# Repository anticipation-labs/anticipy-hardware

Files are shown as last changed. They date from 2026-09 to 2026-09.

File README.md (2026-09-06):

# Anticipy Hardware

Consolidated hardware record for the Anticipy pendant — a wearable that listens passively,
pulls tasks out of conversation, and acts on them without commands.

**Assembled:** 2026-09-06 · **Files:** 3756 (1189 unique) · **Size:** ~656M B
**Sources consolidated:** 15 separate packages plus loose files and sealed original zips from
Downloads, Desktop and Documents.

---

## The one thing to read first

> **Nothing here is fabrication-ready. There is no released Gerber, ODB++, drill file,
> pick-and-place, assembly drawing or final enclosure drawing anywhere in this repository.**
>
> There is, however, a **live JLCPCB order** (`W2026083114248171` / `SMT026083160845`) with an
> **unresolved part substitution** awaiting DFM review. See [07_PROCUREMENT](07_PROCUREMENT/).
> That is the only clock currently running.

> ⚠️ **Do not flash `anticipy.uf2` from any `~/AnticipyFleet/*/firmware/` lane.** That file is the
> image formally classified `UNVERIFIED_DO_NOT_FLASH` (sha256 `2e78015e…`, 624,640 bytes), sitting
> under a clean name next to a build receipt that describes a *different* 509,440-byte image.
> Details: [`00_START_HERE/CONTRADICTIONS.md`](00_START_HERE/CONTRADICTIONS.md) §14.

**New to this project?** Read [`00_START_HERE/ORIENTATION.md`](00_START_HERE/ORIENTATION.md) first.
It assumes no prior context: what the product is, where it actually stands, how to open every file
type here, what the vocabulary means, and what to do in your first week.

Then read [`00_START_HERE/HARDWARE_STATE.md`](00_START_HERE/HARDWARE_STATE.md) — one page on what
is actually true today — followed by
[`00_START_HERE/CONTRADICTIONS.md`](00_START_HERE/CONTRADICTIONS.md), which lists **seventeen** places
where two documents in this repository disagree with each other. Read that **before** acting on any
single document, because several of them contradict each other on the processor, the enclosure
size and the state of the board.

---

## Folder map

| Folder | What it is | Fab status |
|---|---|---|
| [`00_START_HERE/`](00_START_HERE/) | Orientation for newcomers, state, contradictions, glossary, provenance | — |
| [`01_CURRENT_TARGET_R1/`](01_CURRENT_TARGET_R1/) | The live requirement set (2026-09-04). What the incoming engineer is asked to build. | Not designed yet |
| [`02_PROTOTYPE_XIAO/`](02_PROTOTYPE_XIAO/) | XIAO nRF52840 Sense proof unit — wiring, enclosure CAD, assembly evidence | Proof only, on physical-test hold |
| [`03_PCB/`](03_PCB/) | Every custom board design. Three exist. None are releasable. | **NOT FOR FAB** |
| [`04_MECHANICAL/`](04_MECHANICAL/) | Enclosure CAD — print-ready, reference STEP, superseded meshes | Print-ready ≠ production |
| [`05_FIRMWARE/`](05_FIRMWARE/) | Source, build/protocol/threat docs, distinct images, device recovery | Lab only |
| [`06_FACTORY_AND_QA/`](06_FACTORY_AND_QA/) | Factory release process, QA fixtures, test evidence | Process defined, not executed |
| [`07_PROCUREMENT/`](07_PROCUREMENT/) | BOMs, order sheets, sourcing, **live JLCPCB order status** | Active |
| [`08_HISTORICAL_PACKAGES/`](08_HISTORICAL_PACKAGES/) | All 12 source packages plus the original zips, preserved verbatim. Never edit. | Archive |
| [`99_MANIFESTS/`](99_MANIFESTS/) | `SHA256SUMS.txt`, `INVENTORY.csv` | — |

**Folders `01`–`07` are a curated working view. Folder `08` is the provenance record.**
Every file in `01`–`07` also exists in `08`, byte-identical. If the two ever disagree, `08` wins.

---

## The five board generations, decoded

This is the single most confusing thing in the project, so it is stated once, plainly:

| Name | What it actually is | Where | State |
|---|---|---|---|
| **R0** | `ANT-PROD-R0 EVT`. First custom board. Has 31 commits of routing history. | `03_PCB/R0_ROUTING_HISTORY_NOT_FOR_FAB/` | 23 non-GND nets still unconnected |
| **R0B** | Revision B of R0. The "engineering checkpoint" the master package leads with. | `03_PCB/R0B_CHECKPOINT_NOT_FOR_FAB/` | 176 connections unrouted |
| **EVT-A** | `anticipy_evt_a`. A *separate* board from the 2026-08-28 Execution package, targeting a **different processor**. | `03_PCB/EVT_A_2026-08-28_SUPERSEDED/` | Fabrication hold: 0 segments, 0 vias, 0 zones |
| **ESP32-S3** | The prior generation (April 2026). Different SoC, mic, charger and enclosure entirely. Holds the only packaging spec and manufacturing-order doc that exist. | `08_HISTORICAL_PACKAGES/2026-04_esp32s3_prior_generation/` | Superseded |
| **R1** | The current target. **Does not exist yet** — brief only. | `01_CURRENT_TARGET_R1/` | Not started |

R0 and R0B are not the same file, and the copy of R0 shipped inside the master package is **not**
the same file as the one in the R0 git repository. See `00_START_HERE/CONTRADICTIONS.md`.

---

## Working with this repository

### Cloning

```bash
git lfs install                                    # once per machine
git clone https://github.com/anticipation-labs/anticipy-hardware.git
```

Git LFS is required, but only barely — it is scoped to exactly **two** files, the oversized
superseded meshes under `04_MECHANICAL/SUPERSEDED_AND_MOCKUPS/OVERSIZED_MESHES_500mah_2026-08-22/`
(68.8 MB and 64.8 MB). Everything else is stored as ordinary git objects deliberately, so a clone
never depends on an LFS bandwidth quota. If LFS is unavailable, `GIT_LFS_SKIP_SMUDGE=1 git clone`
still gets you the entire repository minus those two superseded files.

### Byte fidelity

`.gitattributes` sets `* -text`, disabling all end-of-line conversion. This is not cosmetic: this
repository is a checksum-verified archive, and EOL rewriting would silently invalidate
`99_MANIFESTS/SHA256SUMS.txt` for every CSV that arrived with CRLF endings.

### The R0 routing history

The R0 KiCad project arrived as its own git repository with 31 commits and no remote. A nested
`.git` cannot be committed into a parent repository, so the history is preserved as a bundle:

```bash
cd 03_PCB/R0_ROUTING_HISTORY_NOT_FOR_FAB
git clone R0_ROUTING_HISTORY.bundle r0-history      # full 31-commit history, restored
```

`R0_ROUTING_HISTORY_COMMITS.txt` lists every commit, and
`R0_UNCOMMITTED_AT_ARCHIVE_TIME.txt` records the working-tree changes that were uncommitted when
this archive was made. Those uncommitted files are present in the folder as-is.

### What is deliberately not ignored

`.kicad_prl` and other KiCad per-user state arrived inside the original handoff packages and are
covered by the checksum manifest, so they are committed rather than ignored. Only `__pycache__`
bytecode and macOS `.DS_Store` files were removed.

---

## Verifying this folder

```bash
cd ~/Anticipy-Hardware && shasum -a 256 -c 99_MANIFESTS/SHA256SUMS.txt
```

`99_MANIFESTS/INVENTORY.csv` lists every file with its hash, size, date and owning folder.

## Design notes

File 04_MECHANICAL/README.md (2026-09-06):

# 04 — Mechanical

**Print-ready is not the same as production-ready.** Nothing here has been validated on a sealed,
assembled unit.

## Two parallel enclosure lineages exist

This is the mechanical equivalent of the processor contradiction, and it is easy to miss because
the two live in different folders with different naming:

| Lineage | Form factor | Source | Where |
|---|---|---|---|
| **Ordered-shell recovery v0.2** | 51 × 22 × 14.5 mm body + 4.50 mm midband, coin motor, M2 screw retention | Generated by a Python recovery script | `../02_PROTOTYPE_XIAO/CAD/`, `PRINT_READY/xiao_prototype_plates/` |
| **`anticipy-shell` v5.1** | 26.5 × 61.2 × 12.6 mm flat pill tag (33.4 × 80.7 × 16.2 mm in the v5 storage build), click tongue-and-groove joint, microSD pocket | Parametric **OpenSCAD** | `OPENSCAD_SHELL_PROGRAM_v5.1/` |
| **Production CAD** | 50.500 × 20.680 × 10.800 mm envelope, 16 solids | Execution v1.0 | `REFERENCE_STEP/` |

These are **three different products**, not three views of one. Nobody has written down which is
current. The R1 brief adds a fourth number: 56.0 × 23.0 × 12.0 mm.

## Layout

| Folder | Contents |
|---|---|
| `OPENSCAD_SHELL_PROGRAM_v5.1/` | The only *parametric* enclosure source on the machine. `pendant.scad` with a documented v1 → v5.1 history, 12 STL exports, print plates, a clearance coupon, a Bambu print recipe, a dimensioned drawing, an XIAO+microSD pinmap, a power/storage budget, a per-unit BOM with real sources and prices, an 8-step assembly sequence, and a 100-unit MJF-vs-CNC cost comparison. |
| `MACHINIST_DRAWINGS/` | **The only machinist-facing 2D drawing pair found anywhere** — `production_aluminum_cap_drawing.pdf` + `_outline.dxf`. If a CNC vendor is ever engaged, this is what they get. |
| `REFERENCE_STEP/` | Execution v1.0 production CAD. 23/23 mechanical checks passed — **against the 50.5 × 20.68 × 10.8 envelope only**. |
| `PRINT_READY/` | Plates and parts believed printable. Includes the XIAO prototype plates. |
| `SUPERSEDED_AND_MOCKUPS/` | Older meshes, mockups and visual studies. Kept for history. |

## Known unresolved mechanical issues

- **The v5 joint does not lock.** The 2026-08-18 P2S print failed on joint clearance — recorded in
  the OpenSCAD program's own build book as "zero tolerance, doesn't even try to lock". Whether a
  corrected plate was ever printed successfully is not recorded.
- **Material and adhesive conflict.** `README` in the OpenSCAD program specifies Bambu PLA Metal
  with gel CA glue; its own `BUILD_BOOK`, `print-plan` and `build-steps` specify black ABS. These
  have different shrinkage and different bonding requirements.
- **A permanently glued shell conflicts with DFU recovery.** The shell is designed to be glued
  shut, but firmware recovery depends on 1200-baud USB touch and BLE DFU being reachable. If the
  radio or the crystal fails inside a sealed unit, there is no documented way back in.

## Oversized files

`SUPERSEDED_AND_MOCKUPS/OVERSIZED_MESHES_500mah_2026-08-22/` holds two STLs of 68.8 MB and
64.8 MB. Both exceed GitHub's 50 MB warning threshold (neither hits the 100 MB block). They are
superseded and kept only for history — the first candidates to drop if repository size matters.

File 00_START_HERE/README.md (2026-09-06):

# 00 — Start here

Read in this order.

| # | File | Why |
|---|---|---|
| 0 | [`ORIENTATION.md`](ORIENTATION.md) | **New to the project? Start here.** What the product is, where it really stands, how to open every file type, the vocabulary explained, and a suggested first week. Assumes no prior context. |
| 1 | [`HARDWARE_STATE.md`](HARDWARE_STATE.md) | One page: what is actually true today. Where the project really stands, and the one deadline that is live. |
| 2 | [`CONTRADICTIONS.md`](CONTRADICTIONS.md) | **The most important file here.** Seventeen places where two documents in this repository disagree — on the processor, the enclosure size, the battery, which board file is real, and whether the firmware can drive the haptics. Read it before acting on any single document. |
| 3 | [`GLOSSARY.md`](GLOSSARY.md) | Decodes R0 / R0B / EVT-A / R1 / XIAO / P2S / EOL / DFM and the part numbers, none of which are defined anywhere else. |
| 4 | [`PROVENANCE.md`](PROVENANCE.md) | Where every file came from, how the audit was done, and what was deliberately excluded. |

## If you are the incoming hardware engineer

Your assignment is in [`../01_CURRENT_TARGET_R1/`](../01_CURRENT_TARGET_R1/). Before you start,
know these four things:

1. **Nothing here is fabrication-ready.** No Gerber, ODB++, drill, pick-and-place or assembly
   drawing exists anywhere. That is deliberate, not an oversight.
2. **There is a live JLCPCB order** sitting on an unverified part substitution. It is the only
   clock running. See [`../07_PROCUREMENT/`](../07_PROCUREMENT/).
3. **Three custom boards were started and none finished**, and the one named "older" (R0) is
   further along than the one presented as current (R0B).
4. **The briefs disagree with each other.** The newest brief specifies a different processor and a
   different enclosure size than the most complete package on disk. Nobody wrote down why.

## If you are looking for one specific thing

| Looking for | Go to |
|---|---|
| What to build | `../01_CURRENT_TARGET_R1/` |
| The BLE wire protocol | `../05_FIRMWARE/DOCS/PROTOCOL.md` |
| Security and privacy analysis | `../05_FIRMWARE/DOCS/THREAT-MODEL.md` |
| How to reproduce a firmware build | `../05_FIRMWARE/DOCS/BUILD.md` |
| What actually ran on a device | `../05_FIRMWARE/DEVICE_RECOVERY/` |
| Parametric enclosure source | `../04_MECHANICAL/OPENSCAD_SHELL_PROGRAM_v5.1/` |
| The only machinist drawing | `../04_MECHANICAL/MACHINIST_DRAWINGS/` |
| Factory acceptance and EOL tests | `../06_FACTORY_AND_QA/FACTORY_RELEASE_PROCESS/` |
| The PCB routing history | `../03_PCB/R0_ROUTING_HISTORY_NOT_FOR_FAB/` (a git repo) |
| An original untouched deliverable | `../08_HISTORICAL_PACKAGES/` |

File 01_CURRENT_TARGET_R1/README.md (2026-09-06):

# 01 — Current target (R1)

**Status: brief only. This board does not exist yet.**

> ### ⚠️ One file in this folder is superseded and is not marked as such
>
> `Anticipy_PROD_R1_Flux_Build_Brief.md` (2026-08-29) is **NOT the current requirement set**,
> despite sitting in a folder called "current requirements". The master package's own supersession
> notice says so explicitly:
>
> > The earlier Flux build brief, R0A source tree, 49 x 20 mm layout, removable microSD concept,
> > and all experimental autorouter outputs are **deliberately excluded from the active handoff**.
> > — `08_HISTORICAL_PACKAGES/2026-09-05_master_package/04_CUSTOM_PCB_R0B_ENGINEERING_NOT_FOR_FAB/99_Superseded_Notice/SUPERSEDED_FILES_NOTICE.md`
>
> The Flux brief is exactly that brief, with exactly that 49 × 20 mm layout and that microSD
> concept. It carries no supersession banner of its own. It is kept here because it is the most
> detailed electrical brief on record and much of it is still useful — but **every number in it
> must be checked against the Rev 1 brief below before use.**

## The actual current requirement set

**`Anticipy_Hardware_Development_Brief_2026-09-04.md` / `.docx`** — "Custom PCB and investor-ready
metal wearable | Rev 1 | September 4, 2026". This is the assignment.

| | |
|---|---|
| Size | **51 × 21 × 11 mm** target. Do not exceed +10 % per axis without written approval. |
| Weight | **≤ 20 g** target. Flag any design above 25 g before fabrication. |
| Battery | 16 h runtime |
| Local storage | **QSPI NOR flash**, sized from the actual codec. Plan **512 MB**. |
| Offline capacity | 16–20 h |
| Connectivity | BLE live audio, commands, status, reconnect, **ordered backfill** |
| Haptics | App can command a short, discreet vibration |
| MCU | **Not locked.** "nRF52840-compatible starting point"; module vs bare SoC is listed as an *open question* |
| Programming | SWD access, serial identity, test pads |

Delivery is staged through **Checkpoints A/B/C/D** with per-unit acceptance gates and defined stop
conditions — all specified in the brief itself.

## Files here

| File | Status |
|---|---|
| `Anticipy_Hardware_Development_Brief_2026-09-04.md` / `.docx` | **Current.** The `.docx` is the original; the `.md` is a faithful conversion for grepping. |
| `Anticipy_PROD_R1_Flux_Build_Brief.md` | **Superseded** — see banner above |
| `Anticipy_Hardware_CAD_Brief_v1.pdf` | Superseded CAD brief |
| `Anticipy_Full_Handoff_Guide.pdf` | Handoff guide |
| `HARDWARE_SYSTEM_MAP.md` | One-page block diagram. Note it labels storage "QSPI flash" while the R0B BOM actually fits serial **NAND** — see contradictions. |

## Before you build to this

See [`../00_START_HERE/CONTRADICTIONS.md`](../00_START_HERE/CONTRADICTIONS.md). The short version:
four different enclosure envelopes exist across the record, the storage technology is stated three
different ways, and the MCU is not actually locked despite one superseded brief naming a specific
module.

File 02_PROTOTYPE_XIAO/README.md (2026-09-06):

# 02 — XIAO prototype

The proof unit: a Seeed **XIAO nRF52840 Sense** dev board with an onboard PDM microphone,
streaming live audio to the iPhone app. **This is a proof path, not the product**, and it is
currently on physical-test hold.

The 10 Founder units stay on this architecture so that custom-PCB work does not block the
seven-day Founder build.

## What is here

- `00_START_HERE.md`, `00_FOLDER_STATUS.md` — the prototype's own entry points
- `01_FIRMWARE/` — the release-test image, held pending physical validation
- `03_CAD_STEP/`, `02_CAD_PRINT/` — enclosure geometry
- `04_QA/` — QA material
- `CAD/` — the full XIAO CAD set: `PRINT_THESE/`, `REFERENCE_ONLY_STEP/`, `SOURCE/`,
  `04_ASSEMBLY/`, `06_EVIDENCE/`, `FIT_REPORT.json`, `CAD_SHA256SUMS.txt`

## The haptic circuit — get this right

From the "No-Lee's" reference wiring:

| From | To |
|---|---|
| XIAO `D0` | 100 Ω resistor → N-MOSFET gate (AO3400A or equivalent) |
| MOSFET gate | 100 kΩ resistor → GND |
| MOSFET source | XIAO GND |
| MOSFET drain | Motor negative |
| XIAO `3V3` | Motor positive |
| Flyback diode cathode (stripe) | Motor positive / 3V3 |
| Flyback diode anode | Motor negative / MOSFET drain |

> **Never connect the motor directly to `D0`.** It will damage the pin.

Note also that **no firmware in this repository actually drives the haptic motor** — see
[`../05_FIRMWARE/README.md`](../05_FIRMWARE/README.md). The circuit is specified; the software
to use it does not exist yet.

## Still required

The battery, motor, driver and closed enclosure all need real measurements and release testing on
a sealed unit. Nothing here has been physically validated.

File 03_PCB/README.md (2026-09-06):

# 03 — PCB

**NOTHING IN THIS FOLDER MAY BE SENT TO A FABRICATOR AS A PRODUCTION RELEASE.**

There is no released Gerber, ODB++, drill file, pick-and-place or assembly drawing anywhere in
this repository. Three custom boards were started. None were finished. A fourth is specified but
not designed.

## The four revisions

| Folder | Board | State |
|---|---|---|
| `R1_TARGET_NOT_YET_DESIGNED/` | R1 | Empty by design. The brief lives in `../01_CURRENT_TARGET_R1/`. |
| `EVT_A_2026-08-28_SUPERSEDED/` | `anticipy_evt_a`, 37.5 × 14 mm four-layer, **nRF54L15** | Deliberate fabrication hold: 0 segments, 0 vias, 0 zones. No copper was ever laid, specifically so no misleading Gerbers could exist. Superseded by the R1 brief. |
| `R0B_CHECKPOINT_NOT_FOR_FAB/` | R0B, 45.8 × 18.0 mm four-layer, 0.80 mm | 70 electrical references, 223 pins, **176 connections unrouted**. The master package's headline board. |
| `R0_ROUTING_HISTORY_NOT_FOR_FAB/` | R0 / `ANT-PROD-R0 EVT` | **The furthest-routed board.** 45 of 46 signal nets carry copper. 31 commits of history (v21 → v43) driving unconnected nets from 199 down to 23 non-GND. |

## Read this before touching R0

`R0_ROUTING_HISTORY_NOT_FOR_FAB/` contains a **live `.git` repository with no remote**. Its 31
commits are the only version-controlled hardware history found on the machine, and they existed
nowhere else before this consolidation. It also carries uncommitted changes to `.kicad_pcb` and
`.kicad_pro`, plus an untracked `tools/final_build.py`. These were preserved exactly as found.

It includes `tools/route_board.py` — a purpose-written negotiated-congestion autorouter. That is
weeks of work and it exists only here.

## The R0 ambiguity

There are **two different files both called the R0 board**:

| | Master package copy | This git repository |
|---|---|---|
| `.kicad_pcb` sha256 | `64a4931f0fc455cd…` | `c086bae9fedc9a55…` |
| DRC timestamp | 2026-08-30 02:28:59 | 2026-08-29 18:04:35 |
| DRC violations | 134 | 4 |

The master package's copy was generated later by an automated run (its DRC header references a
sandbox path) and is **less** routed. Establish which is canonical before anyone uploads "R0"
anywhere — especially given the live JLCPCB order, whose email record does not prove which
revision was uploaded.

## Ordering note

`R0` is *more* complete than `R0B`, despite the naming. Either R0B discarded R0's routing work
or the master package's framing is wrong. Nothing on disk explains which.

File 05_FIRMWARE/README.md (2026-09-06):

# 05 — Firmware

**Lab only. Nothing here is production firmware.**

This was the single largest gap in the original hardware packages: they shipped firmware
*binaries* and prose about them, but zero source, zero protocol specification, zero threat model,
zero build procedure and zero upstream pinning. All of that lives here now.

## Layout

| Folder | Contents |
|---|---|
| `DOCS/` | `PROTOCOL.md`, `THREAT-MODEL.md`, `BUILD.md`, `README.md`, `upstream.lock.json`, `protocol/` (executable frame protocol + fixtures), `development-receipts/` |
| `SOURCE/` | nRF52840 firmware source, debug tooling and an iOS test client (from Execution v1.0) |
| `IMAGES/` | One copy of each **distinct** firmware binary, renamed by date and status |
| `DEVICE_RECOVERY/` | The restore kit, including an image read back off a physical device, and the A/B recovery pair |

## Lineage — record this somewhere permanent

Anticipy firmware is a **fork of [BasedHardware/omi](https://github.com/BasedHardware/omi)**:

- Upstream: `v2.0.1-Omi`, commit `ee9892562648f074e3c6b59d508127d81fa21010`
- Path: `Friend/firmware/firmware_v1.0`
- Toolchain: NCS v2.5.0
- Applied as two named patches in `DOCS/../replacement/patches/`

**No hardware package records this.** It carries attribution and licensing obligations, and it
also vendors Opus 1.2.1. This should be stated explicitly wherever the firmware ships.

## The images

| File | Notes |
|---|---|
| `2026-09-04_anticipy_0.9.3_owner2_live_50mA_HOLD.uf2` | Newest. Name says it: held for physical release test. |
| `2026-08-28_anticipy_founder_evt_v0.9.0_LAB_ONLY.uf2` | Founder EVT lab image |
| `2026-07-24_dual-hatch-{base,rc,debug,secure}.uf2` | The dual-hatch recovery line. `secure` is the most production-appropriate (encrypted, bonded DFU control point) but has **no build receipt and no OTA package**, unlike base and RC. |
| `2026-07-23_zephyr_dev_NOT_FOR_FLASH.{uf2,hex}` | Development artifacts, explicitly not for flashing |
| `2026-07-20_anticipy.uf2`, `2026-07-21_anticipy.hex` | Earliest images. The `.uf2` reports version **1.0.5**. |

### Version numbering is incoherent

`1.0.5` (July) → `2.0.1` (July, candidate build) → `0.9.0` (August) → `0.9.3` (September).
The `2.0.x` numbers are inherited from upstream Omi; `0.9.x` is Anticipy's own scheme; `1.0.5` is
unexplained. **Sorting these by version number gives the wrong answer.** Sort by date.

## Two things that block shipping

1. **No haptic support exists in any firmware source tree.** A grep across all five source trees
   returns nothing, and every build receipt records `haptic_support_added: false`. Haptics are a
   core product requirement and a specified BOM line (DRV2605L + VC0720B015F). The firmware does
   not drive them.
2. **USB VID/PID are still Zephyr test defaults** (`0x2FE3` / `0x100`). Real identifiers are
   required before anything shippable.

## What actually ran on hardware

`DEVICE_RECOVERY/CURRENT-from-device-20260724.uf2` was read back off a physical pendant. It is the
only artifact in this repository that is evidence of what really executed on a device — everything
else is a build output that was never flashed. Every build receipt in the dual-hatch line records
`flash_performed: false`.

The restore kit also carries the fully-resolved Zephyr devicetree — the only as-built peripheral
and flash-partition map for the proof unit anywhere — plus five raw on-air BLE logs captured from
the physical pendant.

## Open, unresolved

- The A/B recovery pair exists to test one hypothesis: is the 32.768 kHz crystal dead?
  **No result was ever recorded.** No log, no follow-up build.
- The master package's `0.9.3` image (sha `f246fc79…`, NCS v2.7.0) has **no source tree anywhere**
  on the machine. The source for the newest firmware is missing.

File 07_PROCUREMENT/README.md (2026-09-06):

# 07 — Procurement

**There is a live order in this folder. It is the only clock currently running on this project.**

## Live: JLCPCB order, not electrically cleared

Read [`JLCPCB_STATUS_2026-09-05.md`](JLCPCB_STATUS_2026-09-05.md) in full. Summary:

| | |
|---|---|
| Web order | `W2026083114248171` |
| PCBA order | `SMT026083160845` |
| Reference | `13417400A` |
| Problem | Part `C526821` did not match the PCB pads; JLCPCB could not assemble it |
| Requested replacement | `C190799 / MX25L25645GM2I-08G` |
| JLCPCB response | Will proceed; customer asked to wait; orientation must be checked in the final DFM |

### The open gate

- No final DFM has been attached
- The footprint / pin-1 / net-mapping check has **not** been confirmed as passed
- The email record **does not prove which local KiCad revision was uploaded** — and there are two
  different files both called "R0" (see [`../03_PCB/README.md`](../03_PCB/README.md))

**Do not approve assembly, and do not approve `C526821` or an unpopulated memory position**, until
the final DFM is reviewed and C190799's SOP-8 208/209 mil footprint, pin-1 orientation and net
mapping are verified by the hardware engineer.

## Cost and quantity material

| File | What it is |
|---|---|
| `PURCHASE_QUANTITIES.csv` | Execution v1.0 purchase quantities |
| `2026-08-28_tuesday_evt_BUY_12.csv` | 12-unit buy list |
| `2026-08-28_tuesday_evt_COST_CEILING.md` | Cost ceiling |
| `2026-08-27_v07_FOUR_DAY_ORDER_SHEET.csv` | Four-day build order sheet |
| `2026-08-28_execution_COST_AND_TIMELINE.md` | Cost and timeline |
| `anticipy-hardware-sourcing.docx` | Sourcing notes |

## Build and handoff guides

`Anticipy_Pendant_Manufacturing_Brief.pdf`, `Anticipy_Unit_001_Owner_Shopping_and_Hardware_Build_Brief.pdf`,
`Anticipy_Pendant_Guide.pdf`, `Anticipy_BUILD_GUIDE_LegoStyle.pdf`, `Anticipy_Build_Guide_VISUAL.pdf`,
`Anticipy_v0_Build_Guide.pdf`, `Anticipy_Hardware_CAD_Brief_v1.pdf`.

These are PDFs and DOCX and were catalogued by filename and context rather than parsed in full.
Confirm their contents before relying on them for a purchase decision.

## Schedule reality

From Execution v1.0, and still the most honest statement on record:

- Ready-made-board lab parts: ~5–10 business days after checkout
- Three custom EVT units: no responsible fixed date until the board and battery gates close;
  best case roughly **3–7 weeks**, not a promise
- **A customer batch in two weeks is not supported by the present evidence**

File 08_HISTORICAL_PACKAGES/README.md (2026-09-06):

# 08 — Historical packages

**Do not edit anything in this folder.** It is the provenance record. Every file in `01`–`07` also
exists here, byte-identical. If the curated view and this archive ever disagree, this archive wins.

Fifteen sources, preserved verbatim as found on 2026-09-06.

| Folder | Date | What it was |
|---|---|---|
| `00_ORIGINAL_ZIPS/` | — | The original `.zip` deliverables, sealed and unextracted |
| `2026-04_esp32s3_prior_generation/` | 2026-04/05 | **The prior hardware generation.** XIAO ESP32-S3 + INMP441 + TP4056. KiCad schematic, OpenSCAD enclosure, pin map, assembly guide, and the **only packaging spec and manufacturing-order document in the whole audit**. |
| `2026-07-23_firmware_dev_not_for_flash/` | 2026-07-23 | Firmware development artifacts, marked not-for-flash |
| `2026-07-24_pendant_device_restore/` | 2026-07-24 | Restore kit incl. an image read **off a live device**, resolved devicetree, five on-air BLE logs |
| `2026-07-24_pendant_recovery_images/` | 2026-07-24 | The A/B recovery pair built to test the 32.768 kHz crystal hypothesis |
| `2026-07-24_dual_hatch_builds/` | 2026-07-24 | Build receipts, logs, source and DFU packages for the four dual-hatch variants |
| `2026-08-19_anticipy_shell_openscad/` | 2026-08-19 | The parametric OpenSCAD enclosure program, v1 → v5.1 |
| `2026-08-19_anticipy_design_ds_bundle/` | 2026-08-19 | Design-system bundle incl. the XIAO hardware spec |
| `2026-08-27_v07_four_day_build_pack/` | 2026-08-27 | Four-day build: order sheet, wiring card, mechanical, firmware |
| `2026-08-28_48h_v13/` | 2026-08-28 | 48-hour sprint: print files, guides, lab-only firmware |
| `2026-08-28_tuesday_evt_v0.1/` | 2026-08-28 | Strict EVT plates, aluminium template, cost ceiling, release gates |
| `2026-08-28_execution_v1.0/` | 2026-08-28 | **The most complete package.** Production CAD, EVT-A PCB, firmware source, QA fixtures, factory release process |
| `2026-08-29_r0_kicad_with_git_history/` | 2026-08-29 | The R0 KiCad project **with its 31-commit routing history**. No remote — this was the only copy. |
| `2026-08-28_p2s_v07_enclosure/` | 2026-08-28 | The P2S_v07 enclosure generation and a 50.5 × 20.5 mm production layout concept |
| `2026_firmware_provenance_lane/` | 2026 | The authoritative firmware provenance and safety track: protocol, threat model, build spec, upstream patches, SBOM tooling, quarantine record |
| `2026-09-05_master_package/` | 2026-09-05 | The most recent assembly; leads with the R1 brief and the R0B checkpoint |

## Why fifteen and not one

The 2026-09-05 "master package" was the newest assembly, but not the most complete. Measured by
SHA-256 across every unique CAD/fab artifact on the machine:

```
unique CAD/fab artifacts machine-wide : 411
  present in the master package        :  74   (18 %)
  existing only outside it             : 337
```

`execution_v1.0` alone holds **243 blobs found nowhere else** — more than the master package's 190.
Adopting the newest package as the archive would have discarded the entire factory release
process, the QA fixture set, the only machinist drawing pair, and the only real firmware source
tree.

## Duplicates resolved during consolidation

- `Anticipy_v07_four_day_complete_build_pack` existed twice in Downloads; the copies were
  byte-identical apart from a `.DS_Store`. One archived.
- `Anticipy_Hardware_Master_Package_2026-09-05.zip` and `… (1).zip` are byte-identical
  (`sha256 d39a1a00…`). The already-extracted folder matched the zip exactly.
- One firmware binary (`anticipy.uf2`) had 21 copies scattered across the machine; `anticipy.hex`
  had 15. One of each was kept, in `../05_FIRMWARE/IMAGES/`.

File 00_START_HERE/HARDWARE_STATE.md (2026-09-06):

# Hardware state — as of 2026-09-06

One page. What is actually true, what is merely designed, and what is only claimed.

---

## Fabrication state: HOLD

There is **no released manufacturing file set** anywhere in this repository — no Gerber, no ODB++,
no drill file, no pick-and-place, no assembly drawing, no final populated STEP, no final enclosure
drawing set. The 2026-08-28 Execution package verified this deliberately and recorded it as a pass:

```
PASS | PCB fabrication hold preserved | segments=0, vias=0, zones=0
PASS | no misleading Gerbers | none
FABRICATION STATE: HOLD — NO GERBERS
```

That is the correct state. It is not an oversight.

---

## What physically exists

| Thing | Status | Evidence |
|---|---|---|
| XIAO nRF52840 Sense proof unit | Built, **on physical-test hold** | `02_PROTOTYPE_XIAO/` |
| Printed enclosure shells | Printed, fit-checked digitally | `04_MECHANICAL/PRINT_READY/` |
| Custom PCB (any revision) | **Never fabricated** | — |
| Firmware running on a device | Yes — one image was pulled back off a device on 2026-07-24 | `05_FIRMWARE/DEVICE_RECOVERY/CURRENT-from-device-20260724.uf2` |

## What has been verified digitally only

From the 2026-08-28 Execution package (`08_HISTORICAL_PACKAGES/2026-08-28_execution_v1.0/`):

- Production envelope **50.500 × 20.680 × 10.800 mm** — *see contradictions, this conflicts with the newer brief*
- Full production STEP: 16 solids, zero positive-volume intersections
- Production mechanical checks: 23/23 pass
- Main product STL: 11/11 watertight, one connected body each
- QA fixtures: 42 STL, 45 STEP, 26 drop orientations, 59 acceptance checks
- Storage arithmetic: `5,000 B/s × 72,000 s × 1.15 = 414,000,000 B` required; ~481 MB usable candidate

## What has NOT happened

No physical audio, RF, battery, charge, thermal, drop, rattle, chain-pull, sweat/ingress,
haptic, button or privacy testing on a sealed unit. Every runtime and acoustic number in this
repository is calculated, not measured.

---

## The only clock currently running

A **live JLCPCB order** exists and is not electrically cleared:

- Web order `W2026083114248171`, PCBA order `SMT026083160845`, reference `13417400A`
- JLCPCB reported part `C526821` did not match the PCB pads and could not be assembled
- Replacement `C190799 / MX25L25645GM2I-08G` was requested, **subject to an unverified check**
  of SOP-8 208/209 mil footprint, pin-1 orientation and net mapping
- JLCPCB said they would proceed and asked the customer to wait
- **No final DFM has been attached.** The footprint/pin/net check has not been confirmed passed
- The email record does **not** prove which local KiCad revision was uploaded

**Do not approve assembly** until the final DFM is reviewed and C190799 orientation and net
mapping are confirmed. Full detail: [`../07_PROCUREMENT/JLCPCB_STATUS_2026-09-05.md`](../07_PROCUREMENT/JLCPCB_STATUS_2026-09-05.md).

---

## Board revisions at a glance

| Revision | Exists as | Unrouted | Verdict |
|---|---|---|---|
| R0 (`ANT-PROD-R0 EVT`) | KiCad + 31 commits of routing history | 23 non-GND, 36 GND | Furthest routed by far — 45 of 46 signal nets carry copper. Not released. |
| R0B | KiCad checkpoint, 45.8 × 18.0 mm, soldered NAND | **Zero copper** — `grep -c '(segment'` returns 0 | Named the "controlling checkpoint", but nothing on it is routed at all. |
| EVT-A (`anticipy_evt_a`) | KiCad, deliberate fab hold | n/a — no copper laid | Different processor. Superseded. |
| R1 | A brief only | — | **Does not exist.** This is the target. |

---

## The current target (R1)

From `01_CURRENT_TARGET_R1/Anticipy_Hardware_Development_Brief_2026-09-04.md` — "Rev 1,
September 4, 2026". This is the assignment:

- **Size:** **51 × 21 × 11 mm** target, +10 % per axis maximum without written approval
- **Weight:** ≤ **20 g**; flag anything above 25 g before fabrication
- **Runtime:** 16 hours
- **Local storage:** **QSPI NOR flash**, sized from the actual codec — plan **512 MB**
- **Offline capacity:** 16–20 hours
- **Connectivity:** BLE live audio, commands, status, reconnect, ordered backfill
- **Haptics:** app-commanded short discreet vibration
- **MCU:** **not locked** — "nRF52840-compatible starting point"; module vs bare SoC is an
  explicitly open question
- **Delivery:** Checkpoints A/B/C/D with per-unit acceptance gates and defined stop conditions

> ⚠️ Do **not** take specs from `Anticipy_PROD_R1_Flux_Build_Brief.md`, even though it sits in the
> same folder and is more detailed. The package's own supersession notice excludes it — along with
> its 49 × 20 mm layout and microSD concept — from the active handoff. Its 56 × 23 × 12 mm
> enclosure and Raytac `MDBT50Q-1MV2` are **not** the current target.

---

## Honest summary

The **documentation and process discipline are strong** — release gates, factory acceptance rules,
EOL test specs and checksum manifests all exist and are unusually rigorous for this stage.

The **engineering is not converged.** Three custom boards were started and none finished. The
board named the "controlling checkpoint" (R0B) has zero copper on it, while the one treated as
older (R0) is nearly routed. The current brief does not lock an MCU, asks for NOR flash while the
controlling board fits NAND, and sits in a folder alongside a superseded brief that contradicts it
on size, storage and module — with no banner saying so. No board has been fabricated, nothing has
been physically tested, and a live factory order is waiting on an unverified part substitution.

Read [`CONTRADICTIONS.md`](CONTRADICTIONS.md) next.

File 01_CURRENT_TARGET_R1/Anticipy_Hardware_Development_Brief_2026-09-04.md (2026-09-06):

**PRODUCT + ENGINEERING HANDOFF**

**Anticipy Hardware Development Brief**

Custom PCB and investor-ready metal wearable \| Rev 1 \| September 4,
2026

<table>
<colgroup>
<col style="width: 100%" />
</colgroup>
<thead>
<tr class="header">
<th><p><strong>The job in one sentence</strong></p>
<p>Build a small, polished pendant that continuously captures useful
speech, sends it to the Anticipy iPhone app, safely stores audio while
the phone is unavailable, and gives discreet haptic feedback.</p></th>
</tr>
</thead>
<tbody>
</tbody>
</table>

# Start here: what each person owns

## Omar / Anticipy provides

- The existing XIAO nRF52840 Sense boards used as the known working
  reference.

- Access to the current Anticipy iPhone test build and the current
  firmware/source or binary.

- A contact who can confirm the BLE UUIDs, packet format, codec,
  commands, and backfill behavior.

- The Anticipy logo, color direction, and a few exterior reference
  images.

## The hardware engineer owns

- System architecture, component selection, schematic, PCB layout,
  antenna/RF plan, power budget, and battery selection.

- Industrial/mechanical CAD, internal carrier, metal covers, acoustic
  openings, charging approach, tolerances, and assembly method.

- Prototype procurement, assembly, bring-up, firmware porting support,
  testing, design corrections, and production files.

- A clear written record of decisions, risks, costs, lead times, and
  what still needs approval.

## What success looks like

**First success:** one closed, pocketable, body-worn unit that works
reliably with the real iPhone app and looks intentional from every
angle.

**Next success:** three matching CNC-aluminum EVT units, each with a
serial number and passed test record.

**Then:** a corrected Rev B design suitable for a ten-unit
founder/investor batch.

<table>
<colgroup>
<col style="width: 100%" />
</colgroup>
<thead>
<tr class="header">
<th><p><strong>Do not build these</strong></p>
<p>No camera, display, speaker, external daughterboards, loose stacked
dev boards, taped-on parts, or a copied Plaud enclosure. The product
must be recognizably Anticipy.</p></th>
</tr>
</thead>
<tbody>
</tbody>
</table>

# 1. Product requirements

## The user experience

- The user wears Anticipy on a necklace or clip. It works ambiently;
  normal use should not require deliberate gestures.

- The microphones capture speech and firmware sends a mono audio stream
  to the Anticipy iPhone app over Bluetooth Low Energy.

- If the phone is temporarily unavailable, the pendant timestamps and
  stores compressed audio locally, then backfills in order when the
  phone returns.

- The app can command a short, discreet vibration. The device also
  reports battery, connection, storage, firmware, and health status.

- One subtle physical control is allowed for power, privacy/mute,
  pairing, or factory reset. Status light must be discreet, not visually
  dominant.

## Requirements matrix

| **Area** | **Status** | **Requirement** |
|---|---|---|
| **Camera/display/speaker** | **Fixed**  | None. |
| **Phone** | **Fixed**  | iPhone is the primary companion and cloud gateway. |
| **Connectivity** | **Fixed**  | Reliable BLE live audio, commands, status, reconnect, and ordered backfill. |
| **Offline storage** | **Target** | At least 16 hours of compressed audio; design for 20 hours with margin. |
| **Battery life** | **Target** | At least 16 hours in the real Anticipy use case, measured on a closed unit. |
| **Size** | **Target** | Aim for 51 x 21 x 11 mm. Do not exceed +10% per axis without written approval. |
| **Weight** | **Target** | Aim for 20 g or less. Flag any design above 25 g before fabrication. |
| **Audio** | **Fixed**  | Clear body-worn conversational speech; no severe clothing-rub or haptic contamination. |
| **Exterior** | **Fixed**  | Premium rounded pill, Anticipy branding, clean seams, no rattle, no exposed prototype wiring. |
| **Durability** | **Target** | Everyday sweat/splash resistance and 1 m drops; do not claim an IP rating before testing. |

<table>
<colgroup>
<col style="width: 100%" />
</colgroup>
<thead>
<tr class="header">
<th><p><strong>Reference, not a copy</strong></p>
<p>Plaud NotePin/NotePin S is only the size-and-finish benchmark.
Official specifications list 51 x 21 x 11 mm, about 17 g, two MEMS
microphones, and an aluminum-alloy plus polycarbonate construction.
Anticipy needs original geometry, branding, fastening, acoustic design,
and internal architecture.</p></th>
</tr>
</thead>
<tbody>
</tbody>
</table>

# 2. Electrical architecture and custom PCB

<table>
<colgroup>
<col style="width: 100%" />
</colgroup>
<thead>
<tr class="header">
<th><p><strong>Recommended Rev A direction</strong></p>
<p>Keep the nRF52840 software family for the first custom board so the
current XIAO firmware and iPhone integration are portable. Prefer a
compact certified module if it materially lowers RF risk; use a bare SoC
only if the engineer can own antenna tuning, certification risk, and
schedule.</p></th>
</tr>
</thead>
<tbody>
</tbody>
</table>

## Required functional blocks

**MCU + BLE:** nRF52840-compatible starting point; enough RAM/flash for
codec, buffering, encrypted transport, DFU, and diagnostics.

**Microphones:** One or two low-power digital MEMS microphones. Prefer
two footprints and populate based on measured benefit. Process to one
outgoing mono stream.

**Local storage:** QSPI NOR flash sized from the actual codec. Plan 512
MB unless the calculation and wear model justify less.

**Power:** Protected Li-ion/LiPo, charger, power-path behavior, battery
gauging, undervoltage protection, ESD, and measured current rails.

**Haptics:** Thin ERM or LRA plus a proper driver. It must be felt
through clothing without resetting the radio or overwhelming the
microphones.

**Controls/status:** One button or switch, discreet LED/light pipe if
needed, and a reliable factory-reset path.

**Charging/data:** Preferred: sealed rear contacts and a small USB-C
puck. Schedule fallback: a clean recessed USB-C port on Rev A.

**Programming/test:** SWD access, serial identity, test pads for
rails/signals, current measurement, and a pogo fixture plan.

## Non-negotiable design work

- Capture the current BLE/app protocol before freezing the schematic:
  UUIDs, packet framing, timing, codec, commands, authentication,
  reconnect, backfill, and errors.

- Provide a measured power budget for live streaming, disconnected
  recording, idle, haptic, charging, and firmware update. Battery life
  is accepted only after a closed-unit test.

- Size storage using: bitrate x seconds / 8, then add at least 25% for
  metadata, filesystem overhead, bad sectors, logs, and wear. Example:
  20 hours at 16 kbps needs about 180 MB with that margin.

- Keep the RF antenna and matching network away from battery, metal,
  ground pours, fast clocks, and the user-facing metal cover; include an
  RF test point or connector where practical.

- Add ESD protection, reverse-polarity/short protection, safe charge
  limits, and clear battery isolation. Never compress, bend, or trap a
  pouch cell.

- Store local audio encrypted, bind the pendant to its owner, support
  signed/validated firmware updates, and erase buffered audio only after
  confirmed transfer.

## Rev A PCB guidance

**Board:** 4-layer rigid PCB is the default. Use rigid-flex only if a
real space or assembly benefit offsets cost and schedule.

**Assembly:** Prefer SMT parts on one side where possible, no hand-wired
production connections, and explicit keep-outs for microphones, antenna,
fasteners, battery, and charging contacts.

**Firmware continuity:** The custom board should preserve the existing
app behavior. Any protocol change must be documented and agreed with the
iOS developer before layout release.

# 3. Mechanical and industrial design

## Recommended construction

<table>
<colgroup>
<col style="width: 100%" />
</colgroup>
<thead>
<tr class="header">
<th><p><strong>Fastest credible premium build</strong></p>
<p>Use a PC+ABS, MJF nylon, or SLA internal carrier that locates the
PCB, battery, microphones, motor, contacts, and seals. Add CNC-machined
6061 aluminum front and back cosmetic covers. This gives a premium metal
feel while protecting RF, acoustics, and assembly tolerances.</p></th>
</tr>
</thead>
<tbody>
</tbody>
</table>

- Prototype the full internal stack and cover geometry in SLA before
  CNC. The printed assembly must close without pressure and pass audio,
  antenna, charging, haptic, and drop pre-tests.

- Keep a deliberate non-metal RF window adjacent to the antenna. Do not
  enclose the antenna inside a continuous metal box.

- Give each microphone a short, sealed acoustic path with mesh and
  gasket. Keep adhesive out of the port and isolate the mic from the
  motor and hard contact with the shell.

- Use hidden screws, snaps, or controlled adhesive joints. The enclosure
  must be openable during EVT without damaging the battery; no loose
  foam, rattling parts, or tape visible from outside.

- Provide compliant battery clearance, a rigid protective bridge if
  parts stack above it, strain relief for leads, and no sharp edges or
  point loads near the pouch.

- Include an intentional chain passage or clip interface. It must not
  weaken the shell, block microphones, or sit inside the antenna
  keep-out.

- Model assembly order, tool access, tolerance stack, adhesive
  thickness, gasket compression, and cable bend radii. Nominal fit alone
  is not enough.

## Material and finish decision

| **Part** | **Rev A recommendation** | **Reason** |
|---|---|---|
| **Outer covers** | CNC 6061-T6 aluminum, bead-blasted + anodized | Fast, repeatable, premium, lighter and easier to machine than titanium. |
| **Internal carrier** | Black or natural PC+ABS / MJF PA12 / engineering SLA | Controls fit, creates RF window, locates components, and isolates the battery. |
| **Acoustic seal** | Purpose-made mesh + thin silicone gasket | Protects the port while maintaining a repeatable sound path. |
| **Battery pad** | Thin flame-rated or specified pressure-sensitive material | Prevents movement without squeezing the pouch. |
| **Titanium** | Evaluate after Rev A passes | Use only if weight, RF, machining cost, finish, and lead time are proven acceptable. |

## Exterior quality bar

- Original Anticipy silhouette; compact rounded pill, not a clone of
  another product.

- Even seam and finish, clean logo, no sharp edges, no visible glue
  squeeze-out, no exposed layer lines, and no audible rattle.

- Charging, microphone, button, LED, and chain features must look
  intentional and be located from the complete internal stack, not added
  afterward.

# 4. How we will build it

## Checkpoint A: 24-48 hour engineering audition

<table>
<colgroup>
<col style="width: 100%" />
</colgroup>
<thead>
<tr class="header">
<th><p><strong>Purpose</strong></p>
<p>Before expensive fabrication, show how you think. Do not merely
redraw the old prototype. Identify contradictions, make recommendations,
and quantify the risks.</p></th>
</tr>
</thead>
<tbody>
</tbody>
</table>

- One system block diagram and a written architecture recommendation.

- Current XIAO/app compatibility plan, including what must be measured
  or captured from the existing firmware.

- Preliminary BOM with manufacturer part numbers, size, cost,
  availability, lifecycle status, and at least one substitute for
  critical parts.

- Power and storage calculations with best/expected/worst cases.

- Preliminary PCB outline/stack and a mechanical cross-section showing
  the complete component stack.

- Recommended material/finish, charging method, prototype quantities,
  schedule, estimated cost, and top ten risks.

- A short list of requirement exceptions. Every exception must explain
  why and propose a specific alternative.

## Checkpoint B: prove the electronics

1.  Reproduce the current XIAO-to-iPhone audio flow and record the
    protocol as the baseline.

2.  Bring up the Rev A custom PCB on the bench: power, charging,
    microphones, BLE, storage, haptics, button, LED, DFU, and diagnostic
    logging.

3.  Run power, RF, audio, haptic-noise, storage/backfill, charging, and
    thermal tests before enclosing it.

## Checkpoint C: prove the enclosure

1.  Print one complete SLA/MJF fit unit using the real PCB, real
    battery, real motor, real fasteners, real gaskets, and real adhesive
    thickness.

2.  Fix fit, acoustic, antenna, haptic, charging, and assembly issues in
    the printed unit.

3.  Only then release CNC drawings for three 6061-aluminum EVT units.

## Checkpoint D: close the unit and test it

1.  Assemble three serialized EVT units using the documented process.

2.  Test each unit closed, body-worn, with the real iPhone app. Record
    every result and failure.

3.  Correct the design into Rev B. Freeze files only after all release
    gates pass.

## Checkpoint E: ten-unit founder/investor batch

**Build only after approval:** ten matching Rev B units plus spares
using the same BOM revisions, material/finish specifications, firmware
version, assembly process, and test record.

# 5. What the engineer must hand back

## Electrical design package

- Native schematic and PCB source files, schematic PDF, board STEP
  model, fabrication drawings, stack-up, controlled-impedance notes,
  Gerbers or ODB++, drill files, IPC netlist, pick-and-place, and
  assembly drawings.

- BOM with exact manufacturer part numbers, approved substitutes,
  distributor links, pricing at 1/10/100/1,000 units, lifecycle and
  availability notes.

- Antenna layout/keep-out and RF test plan; power-tree diagram;
  charger/protection details; test-point map; programming and
  production-test fixture design.

- Board bring-up checklist, measured current table, known issues,
  engineering changes, and revision history.

## Mechanical design package

- Native CAD plus STEP for the full assembly and every manufactured
  part.

- Dimensioned 2D drawings with tolerances/GD&T, material, finish, color,
  surface texture, thread/fastener notes, gasket/adhesive specification,
  and critical-to-quality dimensions.

- Exploded view, assembly order, cross-sections, tolerance-stack report,
  mass properties, antenna/acoustic keep-outs, and battery no-pressure
  clearance proof.

- Print-ready fit-check files, CNC RFQ pack, and a vendor-ready
  inspection checklist.

## Firmware and interface package

- Source repository, build instructions, pin map, release binary,
  version/hash, bootloader/DFU procedure, factory-reset path, and
  recovery steps.

- BLE protocol document: services/characteristics, codec, packet format,
  timestamping, acknowledgements, encryption/owner binding, commands,
  backfill, error codes, and version compatibility.

- Manufacturing test firmware plus a normal diagnostic mode that reports
  mic, flash, battery, charging, haptic, button, radio, reset cause, and
  firmware version.

## Manufacturing and QA package

- Supplier list, quotes, lead times, minimum order quantities, approved
  materials, incoming inspection, assembly SOP, rework limits, and
  shipping/battery paperwork.

- One serial-numbered test record per unit, photographs of the closed
  unit, measured dimensions/weight, and a signed release checklist.

- Everything must be editable source, not screenshots or flattened
  exports only. Anticipy receives all project files and credentials
  needed to reproduce the build.

<table>
<colgroup>
<col style="width: 100%" />
</colgroup>
<thead>
<tr class="header">
<th><p><strong>Important release rule</strong></p>
<p>A beautiful enclosure is not a working unit. A working board in a
rough shell is not an investor unit. Both the closed hardware and the
real Anticipy app flow must pass together.</p></th>
</tr>
</thead>
<tbody>
</tbody>
</table>

# 6. Acceptance tests for each EVT unit

| **Gate** | **Pass condition** |
|---|---|
| **App + BLE** | Owner pairing succeeds; reconnect is automatic; control cannot silently transfer to a second phone; live audio, status, commands, and backfill work with the current app. |
| **Audio** | Body-worn quiet-room and normal-conversation recordings are intelligible; no severe RF ticks, charging noise, clothing rub, occlusion, or haptic contamination. |
| **Storage** | A forced disconnection fills and backfills the intended buffer in correct time order with no duplicate, missing, or corrupt segments. Capacity meets the agreed 16-20 hour target. |
| **Battery** | Measured closed-unit run time meets the agreed 16-hour use-case target; gauge and low-battery behavior are predictable; no unexpected reset or deep discharge. |
| **Charging/thermal** | Safe charge current and termination are verified. Cell and surface temperatures remain within the battery vendor limits and the agreed skin-contact limit during charge and use. |
| **Haptics** | 100 commanded pulses work without brownout, disconnect, loose parts, or unacceptable microphone contamination. |
| **RF** | Stable body-worn operation at 5 m and room-scale operation at 10 m in the agreed test environment; antenna performance is checked with metal covers installed. |
| **Mechanical** | Meets approved size/weight; no pressure on the battery; even seams; no rattle; charging/controls/attachment work after drop and handling tests. |
| **Drop/handling** | Passes the agreed 1 m multi-face drop sequence, charging-contact cycles, chain/clip pull, shake, and light torsion tests without opening or losing function. |
| **Security/update**  | Local audio is encrypted; owner binding works; firmware update and recovery work; reset procedure is intentional and documented. |

## Stop conditions

- Do not close or ship a unit if the battery is squeezed, punctured,
  hot, unprotected, undocumented for transport, or able to move inside
  the enclosure.

- Do not release CNC if the complete SLA fit unit has not passed
  closure, audio, RF, charge, haptic, and battery-clearance checks.

- Do not build ten if any of the three EVT units needs a different
  hand-fitted fix. Correct the CAD/PCB/process first.

- Do not claim waterproofing, battery life, range, or certification from
  calculations alone. Test and record it.

# 7. Decisions the engineer should recommend

**These are not homework for Omar before kickoff.** The engineer should
present a recommendation, evidence, cost, and schedule impact for each
item at Checkpoint A.

**MCU implementation:** nRF52840 module vs. bare SoC vs. another
compatible low-power BLE platform.

**Microphone count:** One vs. two digital MEMS microphones based on
actual transcription and noise tests.

**Audio transport:** Codec, frame size, BLE throughput, retransmission,
buffering, clock/timestamp strategy, and iOS background behavior.

**Storage:** Flash type/capacity and wear strategy that meet 16-20 hours
with the selected codec.

**Battery:** Capacity, dimensions, protected cell/pack, supplier,
certification, run time, charging current, and enclosure clearance.

**Charging:** Sealed contact puck vs. clean recessed USB-C for Rev A,
including ESD and mechanical life.

**Haptics:** ERM vs. LRA, driver, mounting, feel, current, and acoustic
contamination.

**Materials:** 6061 aluminum Rev A; whether titanium adds enough value
to justify its weight, RF, machining, cost, and schedule effects.

**Attachment:** Chain passage, clip, magnetic accessory, and how it
affects acoustics, RF, strength, and size.

**Environmental target:** Realistic splash/sweat sealing and the
validation path before making any IP claim.

## What is out of scope for this first hardware engagement

- Cloud AI behavior, app redesign, BCI/EMG add-ons, cameras, displays,
  speakers, and gesture-driven interaction.

- Injection-mold tooling or large production orders before the Rev B
  design and test process are frozen.

- Titanium mass production before the aluminum EVT design passes and a
  specific titanium RF/mechanical plan is approved.

# Omar: your only four actions

1.  Send this brief to the hardware engineer.

2.  Hand him two XIAO nRF52840 Sense boards and give him access to the
    Anticipy iPhone test build/current firmware.

3.  Send the Anticipy logo plus the preferred color/finish images.

4.  Ask him to return Checkpoint A within 24-48 hours. Approve
    fabrication only after that review.

<table>
<colgroup>
<col style="width: 100%" />
</colgroup>
<thead>
<tr class="header">
<th><p><strong>The exact kickoff message</strong></p>
<p>“Please read the attached Anticipy hardware brief. Start with
Checkpoint A and tell me where the requirements conflict or create risk.
I want your recommended architecture, preliminary BOM, power/storage
math, PCB outline, enclosure cross-section, schedule, cost, and top
risks before we release any PCB or CNC order.”</p></th>
</tr>
</thead>
<tbody>
</tbody>
</table>

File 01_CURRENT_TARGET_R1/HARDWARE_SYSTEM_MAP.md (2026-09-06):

# Anticipy hardware system map

## Current product target

```mermaid
flowchart TD
    B[Protected LiPo] --> P[Charger and power path]
    P --> M[nRF52840 BLE controller]
    MIC[One or two PDM microphones] --> M
    F[Local QSPI flash] <--> M
    M --> H[Haptic driver and motor]
    M <--> IOS[Anticipy iPhone app]
```

The September 4 brief targets at least 16 hours of battery life and local compressed-audio storage, with 20 hours of storage margin. The engineer must validate the architecture, exact parts, current draw, BLE protocol, storage math, RF plan and complete enclosure stack before PCB or CNC release.

## Existing XIAO prototype reference

The XIAO version is a proof path, not the final custom PCB. It uses the XIAO nRF52840 Sense microphone and streams live audio to the iPhone. The no-Lee's reference haptic circuit is:

| From | To |
|---|---|
| XIAO D0 | 100 ohm resistor, then AO3400A/equivalent N-MOSFET gate |
| MOSFET gate | 100 kohm resistor, then GND |
| MOSFET source | XIAO GND |
| MOSFET drain | Motor negative |
| XIAO 3V3 | Motor positive |
| Flyback diode cathode/stripe | Motor positive / 3V3 |
| Flyback diode anode | Motor negative / MOSFET drain |

Never connect the motor directly to D0. The battery, motor, driver and closed enclosure still require real measurements and release testing.

## Existing custom-PCB R0B checkpoint

- 45.8 x 18.0 mm, four-layer, nominal 0.80 mm PCB.
- Editable KiCad 7-era schematic and PCB files are included.
- 70 electrical references and 223 source-of-truth pins were checked in the handoff.
- PCB geometry DRC reported zero geometry violations, but **176 electrical connections remain unrouted**.
- The battery, final enclosure, production firmware, fab stack-up and final component-height STEP are unresolved.

The R0B source is suitable for a senior PCB engineer to continue, not for direct fabrication.

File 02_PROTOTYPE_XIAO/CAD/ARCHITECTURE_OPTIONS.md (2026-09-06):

# Architecture decision

## Build for Unit 001

Use:

- black PETG body and hooked face printed from the supplied exact historical
  STL files (or the ordered nylon pieces if they later arrive);
- 4.50 mm printed mid-band and shelf-seated battery bridge;
- XIAO nRF52840 Sense;
- a documented protected 1S pack that passes either the primary
  25 x 10 x 5.5 mm gauge or the named conditional DTP401525
  25.3 x 15 x 4.0 mm gauge and all matching release gates;
- ordered Vybronics VCLP1020B002L motor, no larger than its
  10.2 mm diameter x 2.3 mm tolerance envelope;
- ordered AO3400A / 1N4148W-HF / 100 ohm / 100 kohm SMD haptic driver inside
  the finished 8 x 4 x 2 mm island;
- fully insulated SMD driver island no larger than 8 x 4 x 2 mm;
- live BLE audio to the Anticipy iPhone app;
- no microSD daughterboard.

The strongest documented battery target is Renata ICP501022UPM: 80 mAh,
24 x 10 x 5.5 mm maximum, safety circuit, 40 mA normal/80 mA maximum charge.
Its manufacturer datasheet states IEC 62133 certification and the matching
UN38.3 summary reports T1-T8 passed. Local stock must still be confirmed.

### No-adhesive closure for the Renata target

If qualified 24 x 10 x 5.5 mm Renata hardware is selected, a separate
support-free screw-retained band is available. Two keyed PETG posts clamp the
band to the body with M2 x 10 mm flat countersunk screws through the back; the
hooked face remains removable. Its dedicated exact audit
qualifies a mechanical motor envelope up to 10.2 mm diameter x 2.7 mm at the
existing centre. Use only the named closure parts, motor gauge and procedure
in `PRIMARY_RENATA_ONLY_SCREW_RETENTION.md`.

This screw layout is not compatible with the wide-cell Plan B or the barrel
motor. The exact audit intentionally reports a 32.28 mm3 post/rotated-driver
collision and aborts if that incompatibility disappears.

## Conditional wide-cell Plan B

SparkFun PRT-13853 references the protected Data Power DTP401525, 110 mAh.
Its datasheet gives a 25 x 15 x 4.0 mm cell maximum and a 25.3 mm L2 maximum;
the conservative CAD gauge uses **25.3 x 15 x 4.0 mm**. The exact historical
shell audit passes with the current band and bridge when the driver is rotated
to 4 x 8 x 2 mm between the cell and motor. Nominal clearance is only 0.15 mm
under the historical shelf and 0.40 mm between adjacent hard parts, and the
cell overlaps the complete conservative antenna zone.

This is a fit candidate, not a shipping authorization. Obtain the exact
received label/lot, matching manufacturer datasheet, protection details,
polarity and matching UN38.3 summary; gauge the pack including PCM, wrap,
seams and folded tabs; then pass witness-film closure and closed-shell RF,
charge and thermal tests. Lee PID8834 is a separate local listing and is not
proved equivalent to PRT-13853/DTP401525.

## Why no microSD

The Adafruit microSD BFF adds about 3 mm before solder tolerance. Keeping it
would require a visibly thicker band, more wiring, another failure surface,
and storage firmware validation. The iPhone app already supplies the actual
recording path. Unit 001 is configured as a paired-phone live-stream device
and may be handed off only after the release record passes.

The XIAO has 2 MiB onboard QSPI, but a short-cache firmware profile remains a
development artifact until encrypted-at-rest storage, owner-only access,
durable phone ACK, power-cut recovery, and loss telemetry all pass.

## Fallbacks

- If the ordered Vybronics motor is not physically delivered, Lee PID10431 is
  a delivery fallback only. Its listed 10.0 x 2.7 mm body is inside the
  Renata screw-layout's mechanically qualified 10.2 x 2.7 mm envelope, but the
  received motor must pass that gauge and still requires its own identity,
  current, duty, driver-margin, no-reset, thermal, audio, haptic and RF tests;
  it does not inherit the Vybronics electrical release. The barrel envelope
  remains a measurement reference only because this packet has no qualified
  rotor guard.
- If no battery passes documentation and fit, do not install a donor or raw RC
  cell. Use a documented cell in a larger printed enclosure for that unit.
- If haptic causes reset, buzz, battery contact, or RF failure, remove it and
  disclose the missing function; phone haptics are not pendant haptics.

## Release language

Describe a passed Unit 001 as a **functional investor sample in the final
industrial-design direction**. Do not call it production-validated,
certified, waterproof, or customer-sale-ready until those programs exist.

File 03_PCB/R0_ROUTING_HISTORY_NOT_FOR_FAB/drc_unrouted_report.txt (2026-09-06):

** Drc report for Anticipy_PROD_R0_EVT.kicad_pcb **
** Created on 2026-08-29T18:04:35 **
** Report includes: Errors, Warnings, Exclusions **

** Found 4 DRC violations **
[silk_over_copper]: Silkscreen clipped by solder mask
    Local override; warning
    @(40.0000 mm, 39.3000 mm): PCB text 'ANT-PROD-R0 EVT' on F.Silkscreen
    @(34.1100 mm, 39.2000 mm): Pad 2 [GND] of R13 on F.Cu
[silk_over_copper]: Silkscreen clipped by solder mask
    Local override; warning
    @(36.0000 mm, 35.9000 mm): Segment of M1 on F.Silkscreen
    @(36.0625 mm, 37.0000 mm): Pad 3 [HAPTIC_NEG] of Q1 on F.Cu
[silk_over_copper]: Silkscreen clipped by solder mask
    Local override; warning
    @(33.0000 mm, 38.1000 mm): Segment of M1 on F.Silkscreen
    @(32.7000 mm, 37.0000 mm): Pad 2 [GND] of SW1 on F.Cu
[silk_over_copper]: Silkscreen clipped by solder mask
    Local override; warning
    @(39.3250 mm, 20.5500 mm): Segment of MIC1 on F.Silkscreen
    @(39.8250 mm, 21.0000 mm): Pad 1 [3V_MIC] of C17 on F.Cu

** Found 173 unconnected pads **
[unconnected_items]: Missing connection between items
    Local override; error
    @(35.1375 mm, 29.2500 mm): Pad 22 [VBUSOUT] of U2 on F.Cu
    @(36.8250 mm, 30.9000 mm): Pad 1 [VBUSOUT] of C5 on F.Cu
[unconnected_items]: Missing connection between items
    Local override; error
    @(22.6000 mm, 34.3200 mm): PTH pad SH [GND] of J1
    @(26.7800 mm, 34.3200 mm): PTH pad SH [GND] of J1
[unconnected_items]: Missing connection between items
    Local override; error
    @(23.3900 mm, 24.0000 mm): Pad 2 [GND] of R5 on B.Cu
    @(22.6000 mm, 25.6800 mm): PTH pad SH [GND] of J1
[unconnected_items]: Missing connection between items
    Local override; error
    @(25.8900 mm, 24.0000 mm): Pad 2 [GND] of R6 on B.Cu
    @(26.7800 mm, 25.6800 mm): PTH pad SH [GND] of J1
[unconnected_items]: Missing connection between items
    Local override; error
    @(25.8900 mm, 24.0000 mm): Pad 2 [GND] of R6 on B.Cu
    @(23.3900 mm, 24.0000 mm): Pad 2 [GND] of R5 on B.Cu
[unconnected_items]: Missing connection between items
    Local override; error
    @(25.8900 mm, 24.0000 mm): Pad 2 [GND] of R6 on B.Cu
    @(28.5750 mm, 23.2000 mm): Pad 2 [GND] of C2 on F.Cu
[unconnected_items]: Missing connection between items
    Local override; error
    @(26.7800 mm, 25.6800 mm): PTH pad SH [GND] of J1
    @(27.3550 mm, 26.8000 mm): Pad A1 [GND] of J1 on F.Cu
[unconnected_items]: Missing connection between items
    Local override; error
    @(26.7800 mm, 34.3200 mm): PTH pad SH [GND] of J1
    @(27.3550 mm, 33.2000 mm): Pad A12 [GND] of J1 on F.Cu
[unconnected_items]: Missing connection between items
    Local override; error
    @(26.7800 mm, 34.3200 mm): PTH pad SH [GND] of J1
    @(28.2900 mm, 35.0000 mm): Pad 2 [GND] of R3 on B.Cu
[unconnected_items]: Missing connection between items
    Local override; error
    @(27.2000 mm, 27.5200 mm): Pad 2 [GND] of C14 on B.Cu
    @(27.3550 mm, 26.8000 mm): Pad A1 [GND] of J1 on F.Cu
[unconnected_items]: Missing connection between items
    Local override; error
    @(27.2000 mm, 27.5200 mm): Pad 2 [GND] of C14 on B.Cu
    @(27.2000 mm, 29.5200 mm): Pad 2 [GND] of C15 on B.Cu
[unconnected_items]: Missing connection between items
    Local override; error
    @(27.2000 mm, 29.5200 mm): Pad 2 [GND] of C15 on B.Cu
    @(28.5250 mm, 30.3500 mm): Pad 3 [GND] of U4 on B.Cu
[unconnected_items]: Missing connection between items
    Local override; error
    @(27.2000 mm, 31.5200 mm): Pad 2 [GND] of C16 on B.Cu
    @(28.5250 mm, 30.3500 mm): Pad 3 [GND] of U4 on B.Cu
[unconnected_items]: Missing connection between items
    Local override; error
    @(27.3550 mm, 26.8000 mm): Pad A1 [GND] of J1 on F.Cu
    @(28.7000 mm, 27.2250 mm): Pad 2 [GND] of C3 on B.Cu
[unconnected_items]: Missing connection between items
    Local override; error
    @(27.3550 mm, 33.2000 mm): Pad A12 [GND] of J1 on F.Cu
    @(27.2000 mm, 31.5200 mm): Pad 2 [GND] of C16 on B.Cu
[unconnected_items]: Missing connection between items
    Local override; error
    @(28.2900 mm, 35.0000 mm): Pad 2 [GND] of R3 on B.Cu
    @(27.6750 mm, 36.6000 mm): Pad 2 [GND] of C4 on F.Cu
[unconnected_items]: Missing connection between items
    Local override; error
    @(28.2900 mm, 35.0000 mm): Pad 2 [GND] of R3 on B.Cu
    @(30.0900 mm, 33.8000 mm): Pad 2 [GND] of R4 on B.Cu
[unconnected_items]: Missing connection between items
    Local override; error
    @(28.5250 mm, 30.3500 mm): Pad 3 [GND] of U4 on B.Cu
    @(30.2625 mm, 30.7500 mm): Pad 6 [GND] of U2 on F.Cu
[unconnected_items]: Missing connection between items
    Local override; error
    @(28.5750 mm, 23.2000 mm): Pad 2 [GND] of C2 on F.Cu
    @(30.8000 mm, 23.2250 mm): Pad 2 [GND] of C10 on F.Cu
[unconnected_items]: Missing connection between items
    Local override; error
    @(30.2625 mm, 30.7500 mm): Pad 6 [GND] of U2 on F.Cu
    @(30.2625 mm, 28.7500 mm): Pad 2 [GND] of U2 on F.Cu
[unconnected_items]: Missing connection between items
    Local override; error
    @(30.8000 mm, 23.2250 mm): Pad 2 [GND] of C10 on F.Cu
    @(32.6000 mm, 23.2250 mm): Pad 2 [GND] of C11 on F.Cu
[unconnected_items]: Missing connection between items
    Local override; error
    @(31.9250 mm, 30.0000 mm): Pad 2 [GND] of C6 on B.Cu
    @(32.7000 mm, 30.0000 mm): Pad 33 [GND] of U2 on F.Cu
[unconnected_items]: Missing connection between items
    Local override; error
    @(31.9250 mm, 30.0000 mm): Pad 2 [GND] of C6 on B.Cu
    @(30.2625 mm, 30.7500 mm): Pad 6 [GND] of U2 on F.Cu
[unconnected_items]: Missing connection between items
    Local override; error
    @(32.2000 mm, 36.9500 mm): Pad 2 [GND] of C24 on B.Cu
    @(32.7000 mm, 37.0000 mm): Pad 2 [GND] of SW1 on F.Cu
[unconnected_items]: Missing connection between items
    Local override; error
    @(32.6000 mm, 23.2250 mm): Pad 2 [GND] of C11 on F.Cu
    @(34.4000 mm, 23.2250 mm): Pad 2 [GND] of C12 on F.Cu
[unconnected_items]: Missing connection between items
    Local override; error
    @(32.7000 mm, 37.0000 mm): Pad 2 [GND] of SW1 on F.Cu
    @(34.9200 mm, 38.0000 mm): Pad 2 [GND] of C22 on B.Cu
[unconnected_items]: Missing connection between items
    Local override; error
    @(34.1100 mm, 39.2000 mm): Pad 2 [GND] of R13 on F.Cu
    @(34.9200 mm, 38.0000 mm): Pad 2 [GND] of C22 on B.Cu
[unconnected_items]: Missing connection between items
    Local override; error
    @(34.4000 mm, 23.2250 mm): Pad 2 [GND] of C12 on F.Cu
    @(37.1625 mm, 22.6365 mm): Pad 4 [GND] of MIC1 on F.Cu
[unconnected_items]: Missing connection between items
    Local override; error
    @(35.2800 mm, 34.1000 mm): Pad 2 [GND] of C13 on F.Cu
    @(37.9375 mm, 36.0500 mm): Pad 2 [GND] of Q1 on F.Cu
[unconnected_items]: Missing connection between items
    Local override; error
    @(37.1625 mm, 22.6365 mm): Pad 4 [GND] of MIC1 on F.Cu
    @(37.2000 mm, 21.9400 mm): Pad 5 [GND] of MIC1 on F.Cu
[unconnected_items]: Missing connection between items
    Local override; error
    @(37.1625 mm, 22.6365 mm): Pad 4 [GND] of MIC1 on F.Cu
    @(37.2450 mm, 25.1000 mm): Pad SH [GND] of J2 on B.Cu
[unconnected_items]: Missing connection between items
    Local override; error
    @(37.2000 mm, 21.9400 mm): Pad 5 [GND] of MIC1 on F.Cu
    @(38.0000 mm, 21.3300 mm): Pad 5 [GND] of MIC1 on F.Cu
[unconnected_items]: Missing connection between items
    Local override; error
    @(37.6500 mm, 38.0000 mm): Pad 2 [GND] of C21 on B.Cu
    @(34.9200 mm, 38.0000 mm): Pad 2 [GND] of C22 on B.Cu
[unconnected_items]: Missing connection between items
    Local override; error
    @(37.9375 mm, 36.0500 mm): Pad 2 [GND] of Q1 on F.Cu
    @(37.6500 mm, 38.0000 mm): Pad 2 [GND] of C21 on B.Cu
[unconnected_items]: Missing connection between items
    Local override; error
    @(38.0000 mm, 22.5800 mm): Pad 5 [GND] of MIC1 on F.Cu
    @(37.1625 mm, 22.6365 mm): Pad 4 [GND] of MIC1 on F.Cu
[unconnected_items]: Missing connection between items
    Local override; error
    @(38.3750 mm, 29.1000 mm): Pad 2 [GND] of C1 on F.Cu
    @(40.4000 mm, 26.4250 mm): Pad 2 [GND] of C7 on F.Cu
[unconnected_items]: Missing connection between items
    Local override; error
    @(38.3750 mm, 30.9000 mm): Pad 2 [GND] of C5 on F.Cu
    @(38.3750 mm, 29.1000 mm): Pad 2 [GND] of C1 on F.Cu
[unconnected_items]: Missing connection between items
    Local override; error
    @(38.8000 mm, 21.9400 mm): Pad 5 [GND] of MIC1 on F.Cu
    @(38.0000 mm, 21.3300 mm): Pad 5 [GND] of MIC1 on F.Cu
[unconnected_items]: Missing connection between items
    Local override; error
    @(38.8000 mm, 21.9400 mm): Pad 5 [GND] of MIC1 on F.Cu
    @(40.6050 mm, 24.7500 mm): Pad 6 [GND] of J2 on B.Cu
[unconnected_items]: Missing connection between items
    Local override; error
    @(39.2700 mm, 35.5750 mm): Pad SH [GND] of J2 on B.Cu
    @(37.9375 mm, 36.0500 mm): Pad 2 [GND] of Q1 on F.Cu
[unconnected_items]: Missing connection between items
    Local override; error
    @(39.2700 mm, 35.5750 mm): Pad SH [GND] of J2 on B.Cu
    @(40.4000 mm, 32.0250 mm): Pad 2 [GND] of C8 on F.Cu
[unconnected_items]: Missing connection between items
    Local override; error
    @(39.2700 mm, 35.5750 mm): Pad SH [GND] of J2 on B.Cu
    @(45.2400 mm, 35.5750 mm): Pad SH [GND] of J2 on B.Cu
[unconnected_items]: Missing connection between items
    Local override; error
    @(40.4000 mm, 32.0250 mm): Pad 2 [GND] of C8 on F.Cu
    @(38.3750 mm, 30.9000 mm): Pad 2 [GND] of C5 on F.Cu
[unconnected_items]: Missing connection between items
    Local override; error
    @(40.6050 mm, 24.7500 mm): Pad 6 [GND] of J2 on B.Cu
    @(40.4000 mm, 26.4250 mm): Pad 2 [GND] of C7 on F.Cu
[unconnected_items]: Missing connection between items
    Local override; error
    @(41.3750 mm, 21.0000 mm): Pad 2 [GND] of C17 on F.Cu
    @(38.8000 mm, 21.9400 mm): Pad 5 [GND] of MIC1 on F.Cu
[unconnected_items]: Missing connection between items
    Local override; error
    @(42.7750 mm, 29.9000 mm): Pad 2 [GND] of C9 on F.Cu
    @(40.4000 mm, 32.0250 mm): Pad 2 [GND] of C8 on F.Cu
[unconnected_items]: Missing connection between items
    Local override; error
    @(42.7750 mm, 29.9000 mm): Pad 2 [GND] of C9 on F.Cu
    @(48.5650 mm, 24.8750 mm): Pad SH [GND] of J2 on B.Cu
[unconnected_items]: Missing connection between items
    Local override; error
    @(45.2400 mm, 35.5750 mm): Pad SH [GND] of J2 on B.Cu
    @(45.8500 mm, 37.6000 mm): Pad 3 [GND] of BT1 on F.Cu
[unconnected_items]: Missing connection between items
    Local override; error
    @(45.8500 mm, 37.6000 mm): Pad 3 [GND] of BT1 on F.Cu
    @(47.2375 mm, 36.3500 mm): Pad 3 [GND] of U3 on F.Cu
[unconnected_items]: Missing connection between items
    Local override; error
    @(48.2500 mm, 36.8625 mm): Pad 6 [GND] of U3 on F.Cu
    @(47.2375 mm, 36.3500 mm): Pad 3 [GND] of U3 on F.Cu
[unconnected_items]: Missing connection between items
    Local override; error
    @(48.7400 mm, 34.6000 mm): Pad 10 [GND] of J2 on B.Cu
    @(48.7625 mm, 36.3500 mm): Pad 8 [GND] of U3 on F.Cu
[unconnected_items]: Missing connection between items
    Local override; error
    @(48.7625 mm, 36.8500 mm): Pad 7 [GND] of U3 on F.Cu
    @(48.7625 mm, 36.3500 mm): Pad 8 [GND] of U3 on F.Cu
[unconnected_items]: Missing connection between items
    Local override; error
    @(48.7625 mm, 36.8500 mm): Pad 7 [GND] of U3 on F.Cu
    @(48.2500 mm, 36.8625 mm): Pad 6 [GND] of U3 on F.Cu
[unconnected_items]: Missing connection between items
    Local override; error
    @(48.7625 mm, 36.8500 mm): Pad 7 [GND] of U3 on F.Cu
    @(51.1800 mm, 37.2000 mm): Pad 2 [GND] of C20 on F.Cu
[unconnected_items]: Missing connection between items
    Local override; error
    @(50.2000 mm, 21.9400 mm): Pad 5 [GND] of MIC2 on F.Cu
    @(51.0000 mm, 21.3300 mm): Pad 5 [GND] of MIC2 on F.Cu
[unconnected_items]: Missing connection between items
    Local override; error
    @(51.0000 mm, 21.3300 mm): Pad 5 [GND] of MIC2 on F.Cu
    @(51.8000 mm, 21.9400 mm): Pad 5 [GND] of MIC2 on F.Cu
[unconnected_items]: Missing connection between items
    Local override; error
    @(51.0000 mm, 22.5800 mm): Pad 5 [GND] of MIC2 on F.Cu
    @(51.8000 mm, 21.9400 mm): Pad 5 [GND] of MIC2 on F.Cu
[unconnected_items]: Missing connection between items
    Local override; error
    @(51.0000 mm, 22.5800 mm): Pad 5 [GND] of MIC2 on F.Cu
    @(48.5650 mm, 24.8750 mm): Pad SH [GND] of J2 on B.Cu
[unconnected_items]: Missing connection between items
    Local override; error
    @(51.7750 mm, 35.9000 mm): Pad 2 [GND] of C19 on F.Cu
    @(51.1800 mm, 37.2000 mm): Pad 2 [GND] of C20 on F.Cu
[unconnected_items]: Missing connection between items
    Local override; error
    @(51.8000 mm, 21.9400 mm): Pad 5 [GND] of MIC2 on F.Cu
    @(54.8750 mm, 22.2000 mm): Pad 2 [GND] of C18 on F.Cu
[unconnected_items]: Missing connection between items
    Local override; error
    @(53.8500 mm, 25.2000 mm): Pad 15 [GND] of U1 on F.Cu
    @(54.8750 mm, 22.2000 mm): Pad 2 [GND] of C18 on F.Cu
[unconnected_items]: Missing connection between items
    Local override; error
    @(53.8500 mm, 34.8000 mm): Pad 33 [GND] of U1 on F.Cu
    @(51.7750 mm, 35.9000 mm): Pad 2 [GND] of C19 on F.Cu
[unconnected_items]: Missing connection between items
    Local override; error
    @(56.5000 mm, 38.3000 mm): Pad 1 [GND] of TP5 on B.Cu
    @(53.8500 mm, 34.8000 mm): Pad 33 [GND] of U1 on F.Cu
[unconnected_items]: Missing connection between items
    Local override; error
    @(56.5000 mm, 38.3000 mm): Pad 1 [GND] of TP5 on B.Cu
    @(64.7500 mm, 34.6500 mm): Pad 55 [GND] of U1 on F.Cu
[unconnected_items]: Missing connection between items
    Local override; error
    @(63.6500 mm, 25.3500 mm): Pad 2 [GND] of U1 on F.Cu
    @(64.7500 mm, 25.3500 mm): Pad 1 [GND] of U1 on F.Cu
[unconnected_items]: Missing connection between items
    Local override; error
    @(64.7500 mm, 34.6500 mm): Pad 55 [GND] of U1 on F.Cu
    @(64.7500 mm, 25.3500 mm): Pad 1 [GND] of U1 on F.Cu
[unconnected_items]: Missing connection between items
    Local override; error
    @(27.6000 mm, 38.3500 mm): Pad 1 [LED_BLUE_K] of LED1 on F.Cu
    @(34.4500 mm, 27.5625 mm): Pad 25 [LED_BLUE_K] of U2 on F.Cu
[unconnected_items]: Missing connection between items
    Local override; error
    @(26.1250 mm, 36.6000 mm): Pad 1 [VSYS] of C4 on F.Cu
    @(26.4000 mm, 37.6500 mm): Pad 4 [VSYS] of LED1 on F.Cu
[unconnected_items]: Missing connection between items
    Local override; error
    @(26.1250 mm, 36.6000 mm): Pad 1 [VSYS] of C4 on F.Cu
    @(27.2000 mm, 32.4800 mm): Pad 1 [VSYS] of C16 on B.Cu
[unconnected_items]: Missing connection between items
    Local override; error
    @(26.4000 mm, 37.6500 mm): Pad 4 [VSYS] of LED1 on F.Cu
    @(26.4000 mm, 38.3500 mm): Pad 2 [VSYS] of LED1 on F.Cu
[unconnected_items]: Missing connection between items
    Local override; error
    @(27.2000 mm, 28.4800 mm): Pad 1 [VSYS] of C14 on B.Cu
    @(28.7000 mm, 28.7750 mm): Pad 1 [VSYS] of C3 on B.Cu
[unconnected_items]: Missing connection between items
    Local override; error
    @(27.2000 mm, 28.4800 mm): Pad 1 [VSYS] of C14 on B.Cu
    @(27.0250 mm, 23.2000 mm): Pad 1 [VSYS] of C2 on F.Cu
[unconnected_items]: Missing connection between items
    Local override; error
    @(27.2000 mm, 30.4800 mm): Pad 1 [VSYS] of C15 on B.Cu
    @(27.2000 mm, 28.4800 mm): Pad 1 [VSYS] of C14 on B.Cu
[unconnected_items]: Missing connection between items
    Local override; error
    @(27.2000 mm, 32.4800 mm): Pad 1 [VSYS] of C16 on B.Cu
    @(27.2000 mm, 30.4800 mm): Pad 1 [VSYS] of C15 on B.Cu
[unconnected_items]: Missing connection between items
    Local override; error
    @(28.7000 mm, 28.7750 mm): Pad 1 [VSYS] of C3 on B.Cu
    @(30.2625 mm, 29.7500 mm): Pad 4 [VSYS] of U2 on F.Cu
[unconnected_items]: Missing connection between items
    Local override; error
    @(31.9500 mm, 27.5625 mm): Pad 30 [VSYS] of U2 on F.Cu
    @(30.2625 mm, 29.7500 mm): Pad 4 [VSYS] of U2 on F.Cu
[unconnected_items]: Missing connection between items
    Local override; error
    @(32.9500 mm, 27.5625 mm): Pad 28 [VSYS] of U2 on F.Cu
    @(31.9500 mm, 27.5625 mm): Pad 30 [VSYS] of U2 on F.Cu
[unconnected_items]: Missing connection between items
    Local override; error
    @(32.9500 mm, 27.5625 mm): Pad 28 [VSYS] of U2 on F.Cu
    @(32.6000 mm, 24.7750 mm): Pad 1 [VSYS] of C11 on F.Cu
[unconnected_items]: Missing connection between items
    Local override; error
    @(35.1375 mm, 30.2500 mm): Pad 20 [VSYS] of U2 on F.Cu
    @(32.9500 mm, 27.5625 mm): Pad 28 [VSYS] of U2 on F.Cu
[unconnected_items]: Missing connection between items
    Local override; error
    @(41.2250 mm, 29.9000 mm): Pad 1 [VSYS] of C9 on F.Cu
    @(35.1375 mm, 30.2500 mm): Pad 20 [VSYS] of U2 on F.Cu
[unconnected_items]: Missing connection between items
    Local override; error
    @(27.6000 mm, 37.6500 mm): Pad 3 [LED_RED_K] of LED1 on F.Cu
    @(33.9500 mm, 27.5625 mm): Pad 26 [LED_RED_K] of U2 on F.Cu
[unconnected_items]: Missing connection between items
    Local override; error
    @(27.3550 mm, 27.6000 mm): Pad A4 [VBUS] of J1 on F.Cu
    @(27.3550 mm, 32.4000 mm): Pad A9 [VBUS] of J1 on F.Cu
[unconnected_items]: Missing connection between items
    Local override; error
    @(27.3550 mm, 27.6000 mm): Pad A4 [VBUS] of J1 on F.Cu
    @(35.1375 mm, 29.7500 mm): Pad 21 [VBUS] of U2 on F.Cu
[unconnected_items]: Missing connection between items
    Local override; error
    @(35.1375 mm, 29.7500 mm): Pad 21 [VBUS] of U2 on F.Cu
    @(36.8250 mm, 29.1000 mm): Pad 1 [VBUS] of C1 on F.Cu
[unconnected_items]: Missing connection between items
    Local override; error
    @(53.8500 mm, 34.0000 mm): Pad 32 [VBUS] of U1 on F.Cu
    @(36.8250 mm, 29.1000 mm): Pad 1 [VBUS] of C1 on F.Cu
[unconnected_items]: Missing connection between items
    Local override; error
    @(32.0100 mm, 39.2000 mm): Pad 2 [HAPTIC_GATE] of R12 on F.Cu
    @(33.0900 mm, 39.2000 mm): Pad 1 [HAPTIC_GATE] of R13 on F.Cu
[unconnected_items]: Missing connection between items
    Local override; error
    @(33.0900 mm, 39.2000 mm): Pad 1 [HAPTIC_GATE] of R13 on F.Cu
    @(37.9375 mm, 37.9500 mm): Pad 1 [HAPTIC_GATE] of Q1 on F.Cu
[unconnected_items]: Missing connection between items
    Local override; error
    @(36.0625 mm, 37.0000 mm): Pad 3 [HAPTIC_NEG] of Q1 on F.Cu
    @(39.9500 mm, 37.0000 mm): Pad 1 [HAPTIC_NEG] of D1 on F.Cu
[unconnected_items]: Missing connection between items
    Local override; error
    @(39.9500 mm, 37.0000 mm): Pad 1 [HAPTIC_NEG] of D1 on F.Cu
    @(41.0800 mm, 35.4000 mm): Pad 2 [HAPTIC_NEG] of C23 on F.Cu
[unconnected_items]: Missing connection between items
    Local override; error
    @(32.4500 mm, 32.4375 mm): Pad 12 [3V_MAIN] of U2 on F.Cu
    @(34.3200 mm, 34.1000 mm): Pad 1 [3V_MAIN] of C13 on F.Cu
[unconnected_items]: Missing connection between items
    Local override; error
    @(32.4500 mm, 32.4375 mm): Pad 12 [3V_MAIN] of U2 on F.Cu
    @(30.2625 mm, 28.2500 mm): Pad 1 [3V_MAIN] of U2 on F.Cu
[unconnected_items]: Missing connection between items
    Local override; error
    @(32.5100 mm, 35.4000 mm): Pad 1 [3V_MAIN] of R11 on B.Cu
    @(33.7500 mm, 37.0000 mm): Pad 1 [3V_MAIN] of M1 on F.Cu
[unconnected_items]: Missing connection between items
    Local override; error
    @(32.5100 mm, 35.4000 mm): Pad 1 [3V_MAIN] of R11 on B.Cu
    @(30.2900 mm, 34.4000 mm): Pad 1 [3V_MAIN] of R2 on F.Cu
[unconnected_items]: Missing connection between items
    Local override; error
    @(33.7500 mm, 37.0000 mm): Pad 1 [3V_MAIN] of M1 on F.Cu
    @(32.2000 mm, 38.8500 mm): Pad 1 [3V_MAIN] of C24 on B.Cu
[unconnected_items]: Missing connection between items
    Local override; error
    @(34.3200 mm, 34.1000 mm): Pad 1 [3V_MAIN] of C13 on F.Cu
    @(32.5100 mm, 35.4000 mm): Pad 1 [3V_MAIN] of R11 on B.Cu
[unconnected_items]: Missing connection between items
    Local override; error
    @(35.8900 mm, 25.4000 mm): Pad 1 [3V_MAIN] of R1 on F.Cu
    @(37.0750 mm, 27.2000 mm): Pad 1 [3V_MAIN] of L1 on F.Cu
[unconnected_items]: Missing connection between items
    Local override; error
    @(35.8900 mm, 25.4000 mm): Pad 1 [3V_MAIN] of R1 on F.Cu
    @(30.2625 mm, 28.2500 mm): Pad 1 [3V_MAIN] of U2 on F.Cu
[unconnected_items]: Missing connection between items
    Local override; error
    @(37.0750 mm, 27.2000 mm): Pad 1 [3V_MAIN] of L1 on F.Cu
    @(40.4000 mm, 27.9750 mm): Pad 1 [3V_MAIN] of C7 on F.Cu
[unconnected_items]: Missing connection between items
    Local override; error
    @(40.1200 mm, 35.4000 mm): Pad 1 [3V_MAIN] of C23 on F.Cu
    @(34.3200 mm, 34.1000 mm): Pad 1 [3V_MAIN] of C13 on F.Cu
[unconnected_items]: Missing connection between items
    Local override; error
    @(42.0500 mm, 37.0000 mm): Pad 2 [3V_MAIN] of D1 on F.Cu
    @(40.1200 mm, 35.4000 mm): Pad 1 [3V_MAIN] of C23 on F.Cu
[unconnected_items]: Missing connection between items
    Local override; error
    @(42.0500 mm, 37.0000 mm): Pad 2 [3V_MAIN] of D1 on F.Cu
    @(47.2375 mm, 35.8500 mm): Pad 2 [3V_MAIN] of U3 on F.Cu
[unconnected_items]: Missing connection between items
    Local override; error
    @(48.7625 mm, 35.3500 mm): Pad 10 [3V_MAIN] of U3 on F.Cu
    @(48.7625 mm, 35.8500 mm): Pad 9 [3V_MAIN] of U3 on F.Cu
[unconnected_items]: Missing connection between items
    Local override; error
    @(48.7625 mm, 35.8500 mm): Pad 9 [3V_MAIN] of U3 on F.Cu
    @(47.2375 mm, 35.8500 mm): Pad 2 [3V_MAIN] of U3 on F.Cu
[unconnected_items]: Missing connection between items
    Local override; error
    @(50.2250 mm, 35.9000 mm): Pad 1 [3V_MAIN] of C19 on F.Cu
    @(50.2200 mm, 37.2000 mm): Pad 1 [3V_MAIN] of C20 on F.Cu
[unconnected_items]: Missing connection between items
    Local override; error
    @(50.2250 mm, 35.9000 mm): Pad 1 [3V_MAIN] of C19 on F.Cu
    @(48.7625 mm, 35.8500 mm): Pad 9 [3V_MAIN] of U3 on F.Cu
[unconnected_items]: Missing connection between items
    Local override; error
    @(51.8250 mm, 33.2000 mm): Pad 2 [3V_MAIN] of L3 on F.Cu
    @(50.2250 mm, 35.9000 mm): Pad 1 [3V_MAIN] of C19 on F.Cu
[unconnected_items]: Missing connection between items
    Local override; error
    @(53.8500 mm, 32.4000 mm): Pad 30 [3V_MAIN] of U1 on F.Cu
    @(53.8500 mm, 31.6000 mm): Pad 28 [3V_MAIN] of U1 on F.Cu
[unconnected_items]: Missing connection between items
    Local override; error
    @(53.8500 mm, 32.4000 mm): Pad 30 [3V_MAIN] of U1 on F.Cu
    @(51.8250 mm, 33.2000 mm): Pad 2 [3V_MAIN] of L3 on F.Cu
[unconnected_items]: Missing connection between items
    Local override; error
    @(55.0000 mm, 38.3000 mm): Pad 1 [3V_MAIN] of TP4 on B.Cu
    @(50.2200 mm, 37.2000 mm): Pad 1 [3V_MAIN] of C20 on F.Cu
[unconnected_items]: Missing connection between items
    Local override; error
    @(50.3750 mm, 33.2000 mm): Pad 1 [DCCH] of L3 on F.Cu
    @(53.8500 mm, 33.2000 mm): Pad 31 [DCCH] of U1 on F.Cu
[unconnected_items]: Missing connection between items
    Local override; error
    @(37.1625 mm, 23.4585 mm): Pad 3 [PDM_DATA_MIC1] of MIC1 on F.Cu
    @(40.6900 mm, 23.3000 mm): Pad 1 [PDM_DATA_MIC1] of R14 on F.Cu
[unconnected_items]: Missing connection between items
    Local override; error
    @(57.2500 mm, 34.6500 mm): Pad 39 [PDM_DATA] of U1 on F.Cu
    @(57.4100 mm, 23.5000 mm): Pad 2 [PDM_DATA] of R15 on F.Cu
[unconnected_items]: Missing connection between items
    Local override; error
    @(57.4100 mm, 23.5000 mm): Pad 2 [PDM_DATA] of R15 on F.Cu
    @(41.7100 mm, 23.3000 mm): Pad 2 [PDM_DATA] of R14 on F.Cu
[unconnected_items]: Missing connection between items
    Local override; error
    @(33.4500 mm, 32.4375 mm): Pad 14 [I2C_SCL] of U2 on F.Cu
    @(47.2375 mm, 35.3500 mm): Pad 1 [I2C_SCL] of U3 on F.Cu
[unconnected_items]: Missing connection between items
    Local override; error
    @(36.9100 mm, 25.4000 mm): Pad 2 [I2C_SCL] of R1 on F.Cu
    @(33.4500 mm, 32.4375 mm): Pad 14 [I2C_SCL] of U2 on F.Cu
[unconnected_items]: Missing connection between items
    Local override; error
    @(47.2375 mm, 35.3500 mm): Pad 1 [I2C_SCL] of U3 on F.Cu
    @(54.7500 mm, 28.0000 mm): Pad 19 [I2C_SCL] of U1 on F.Cu
[unconnected_items]: Missing connection between items
    Local override; error
    @(35.8800 mm, 38.0000 mm): Pad 1 [3V_SD] of C22 on B.Cu
    @(39.5500 mm, 38.0000 mm): Pad 1 [3V_SD] of C21 on B.Cu
[unconnected_items]: Missing connection between items
    Local override; error
    @(37.0750 mm, 32.8000 mm): Pad 1 [3V_SD] of L2 on F.Cu
    @(30.9500 mm, 27.5625 mm): Pad 32 [3V_SD] of U2 on F.Cu
[unconnected_items]: Missing connection between items
    Local override; error
    @(39.5500 mm, 38.0000 mm): Pad 1 [3V_SD] of C21 on B.Cu
    @(42.1100 mm, 38.0000 mm): Pad 1 [3V_SD] of R7 on B.Cu
[unconnected_items]: Missing connection between items
    Local override; error
    @(39.5500 mm, 38.0000 mm): Pad 1 [3V_SD] of C21 on B.Cu
    @(40.4000 mm, 33.5750 mm): Pad 1 [3V_SD] of C8 on F.Cu
[unconnected_items]: Missing connection between items
    Local override; error
    @(40.4000 mm, 33.5750 mm): Pad 1 [3V_SD] of C8 on F.Cu
    @(37.0750 mm, 32.8000 mm): Pad 1 [3V_SD] of L2 on F.Cu
[unconnected_items]: Missing connection between items
    Local override; error
    @(42.8050 mm, 24.7500 mm): Pad 4 [3V_SD] of J2 on B.Cu
    @(40.4000 mm, 33.5750 mm): Pad 1 [3V_SD] of C8 on F.Cu
[unconnected_items]: Missing connection between items
    Local override; error
    @(30.2625 mm, 30.2500 mm): Pad 5 [SW2] of U2 on F.Cu
    @(38.5250 mm, 32.8000 mm): Pad 2 [SW2] of L2 on F.Cu
[unconnected_items]: Missing connection between items
    Local override; error
    @(30.8000 mm, 24.7750 mm): Pad 1 [3V_MIC] of C10 on F.Cu
    @(32.4500 mm, 27.5625 mm): Pad 29 [3V_MIC] of U2 on F.Cu
[unconnected_items]: Missing connection between items
    Local override; error
    @(32.4500 mm, 27.5625 mm): Pad 29 [3V_MIC] of U2 on F.Cu
    @(38.8375 mm, 23.4585 mm): Pad 1 [3V_MIC] of MIC1 on F.Cu
[unconnected_items]: Missing connection between items
    Local override; error
    @(39.8250 mm, 21.0000 mm): Pad 1 [3V_MIC] of C17 on F.Cu
    @(38.8375 mm, 23.4585 mm): Pad 1 [3V_MIC] of MIC1 on F.Cu
[unconnected_items]: Missing connection between items
    Local override; error
    @(39.8250 mm, 21.0000 mm): Pad 1 [3V_MIC] of C17 on F.Cu
    @(50.1625 mm, 22.6365 mm): Pad 4 [3V_MIC] of MIC2 on F.Cu
[unconnected_items]: Missing connection between items
    Local override; error
    @(51.8375 mm, 23.4585 mm): Pad 1 [3V_MIC] of MIC2 on F.Cu
    @(50.1625 mm, 22.6365 mm): Pad 4 [3V_MIC] of MIC2 on F.Cu
[unconnected_items]: Missing connection between items
    Local override; error
    @(51.8375 mm, 23.4585 mm): Pad 1 [3V_MIC] of MIC2 on F.Cu
    @(53.3250 mm, 22.2000 mm): Pad 1 [3V_MIC] of C18 on F.Cu
[unconnected_items]: Missing connection between items
    Local override; error
    @(51.8375 mm, 22.6365 mm): Pad 2 [PDM_CLK] of MIC2 on F.Cu
    @(38.8375 mm, 22.6365 mm): Pad 2 [PDM_CLK] of MIC1 on F.Cu
[unconnected_items]: Missing connection between items
    Local override; error
    @(56.8500 mm, 33.7500 mm): Pad 38 [PDM_CLK] of U1 on F.Cu
    @(51.8375 mm, 22.6365 mm): Pad 2 [PDM_CLK] of MIC2 on F.Cu
[unconnected_items]: Missing connection between items
    Local override; error
    @(50.1625 mm, 23.4585 mm): Pad 3 [PDM_DATA_MIC2] of MIC2 on F.Cu
    @(56.3900 mm, 23.5000 mm): Pad 1 [PDM_DATA_MIC2] of R15 on F.Cu
[unconnected_items]: Missing connection between items
    Local override; error
    @(32.9500 mm, 32.4375 mm): Pad 13 [I2C_SDA] of U2 on F.Cu
    @(31.3100 mm, 34.4000 mm): Pad 2 [I2C_SDA] of R2 on F.Cu
[unconnected_items]: Missing connection between items
    Local override; error
    @(32.9500 mm, 32.4375 mm): Pad 13 [I2C_SDA] of U2 on F.Cu
    @(47.2375 mm, 36.8500 mm): Pad 4 [I2C_SDA] of U3 on F.Cu
[unconnected_items]: Missing connection between items
    Local override; error
    @(47.2375 mm, 36.8500 mm): Pad 4 [I2C_SDA] of U3 on F.Cu
    @(53.8500 mm, 26.0000 mm): Pad 16 [I2C_SDA] of U1 on F.Cu
[unconnected_items]: Missing connection between items
    Local override; error
    @(31.4500 mm, 27.5625 mm): Pad 31 [LDO2_OUT] of U2 on F.Cu
    @(34.4000 mm, 24.7750 mm): Pad 1 [LDO2_OUT] of C12 on F.Cu
[unconnected_items]: Missing connection between items
    Local override; error
    @(30.2625 mm, 29.2500 mm): Pad 3 [SW1] of U2 on F.Cu
    @(38.5250 mm, 27.2000 mm): Pad 2 [SW1] of L1 on F.Cu
[unconnected_items]: Missing connection between items
    Local override; error
    @(30.2625 mm, 31.2500 mm): Pad 7 [PMIC_INT] of U2 on F.Cu
    @(58.0500 mm, 34.6500 mm): Pad 41 [PMIC_INT] of U1 on F.Cu
[unconnected_items]: Missing connection between items
    Local override; error
    @(29.3000 mm, 37.0000 mm): Pad 1 [USER_BTN] of SW1 on F.Cu
    @(31.4900 mm, 35.4000 mm): Pad 2 [USER_BTN] of R11 on B.Cu
[unconnected_items]: Missing connection between items
    Local override; error
    @(31.4900 mm, 35.4000 mm): Pad 2 [USER_BTN] of R11 on B.Cu
    @(33.9500 mm, 32.4375 mm): Pad 15 [USER_BTN] of U2 on F.Cu
[unconnected_items]: Missing connection between items
    Local override; error
    @(53.8500 mm, 29.2000 mm): Pad 22 [USER_BTN] of U1 on F.Cu
    @(33.9500 mm, 32.4375 mm): Pad 15 [USER_BTN] of U2 on F.Cu
[unconnected_items]: Missing connection between items
    Local override; error
    @(31.1100 mm, 33.8000 mm): Pad 1 [VSET2] of R4 on B.Cu
    @(34.4500 mm, 32.4375 mm): Pad 16 [VSET2] of U2 on F.Cu
[unconnected_items]: Missing connection between items
    Local override; error
    @(29.3100 mm, 35.0000 mm): Pad 1 [VSET1] of R3 on B.Cu
    @(35.1375 mm, 31.7500 mm): Pad 17 [VSET1] of U2 on F.Cu
[unconnected_items]: Missing connection between items
    Local override; error
    @(35.1375 mm, 31.2500 mm): Pad 18 [NTC] of U2 on F.Cu
    @(44.6000 mm, 37.6000 mm): Pad 2 [NTC] of BT1 on F.Cu
[unconnected_items]: Missing connection between items
    Local override; error
    @(35.1375 mm, 30.7500 mm): Pad 19 [VBAT] of U2 on F.Cu
    @(33.4750 mm, 30.0000 mm): Pad 1 [VBAT] of C6 on B.Cu
[unconnected_items]: Missing connection between items
    Local override; error
    @(43.3500 mm, 37.6000 mm): Pad 1 [VBAT] of BT1 on F.Cu
    @(35.1375 mm, 30.7500 mm): Pad 19 [VBAT] of U2 on F.Cu
[unconnected_items]: Missing connection between items
    Local override; error
    @(24.4100 mm, 24.0000 mm): Pad 1 [USB_CC1] of R5 on B.Cu
    @(27.3550 mm, 28.7500 mm): Pad A5 [USB_CC1] of J1 on F.Cu
[unconnected_items]: Missing connection between items
    Local override; error
    @(27.3550 mm, 28.7500 mm): Pad A5 [USB_CC1] of J1 on F.Cu
    @(35.1375 mm, 28.7500 mm): Pad 23 [USB_CC1] of U2 on F.Cu
[unconnected_items]: Missing connection between items
    Local override; error
    @(26.9100 mm, 24.0000 mm): Pad 1 [USB_CC2] of R6 on B.Cu
    @(27.3550 mm, 31.7500 mm): Pad B5 [USB_CC2] of J1 on F.Cu
[unconnected_items]: Missing connection between items
    Local override; error
    @(27.3550 mm, 31.7500 mm): Pad B5 [USB_CC2] of J1 on F.Cu
    @(35.1375 mm, 28.2500 mm): Pad 24 [USB_CC2] of U2 on F.Cu
[unconnected_items]: Missing connection between items
    Local override; error
    @(53.8500 mm, 28.4000 mm): Pad 20 [UART_RX] of U1 on F.Cu
    @(59.5000 mm, 38.3000 mm): Pad 1 [UART_RX] of TP7 on B.Cu
[unconnected_items]: Missing connection between items
    Local override; error
    @(54.7500 mm, 28.8000 mm): Pad 21 [UART_TX] of U1 on F.Cu
    @(58.0000 mm, 38.3000 mm): Pad 1 [UART_TX] of TP6 on B.Cu
[unconnected_items]: Missing connection between items
    Local override; error
    @(30.9900 mm, 39.2000 mm): Pad 1 [HAPTIC_PWM] of R12 on F.Cu
    @(53.8500 mm, 30.0000 mm): Pad 24 [HAPTIC_PWM] of U1 on F.Cu
[unconnected_items]: Missing connection between items
    Local override; error
    @(45.0050 mm, 24.7500 mm): Pad 2 [SD_CS] of J2 on B.Cu
    @(41.0900 mm, 38.0000 mm): Pad 2 [SD_CS] of R7 on B.Cu
[unconnected_items]: Missing connection between items
    Local override; error
    @(54.7500 mm, 31.2000 mm): Pad 27 [SD_CS] of U1 on F.Cu
    @(45.0050 mm, 24.7500 mm): Pad 2 [SD_CS] of J2 on B.Cu
[unconnected_items]: Missing connection between items
    Local override; error
    @(47.6900 mm, 38.0000 mm): Pad 2 [SD_MISO_MCU] of R10 on B.Cu
    @(54.7500 mm, 32.0000 mm): Pad 29 [SD_MISO_MCU] of U1 on F.Cu
[unconnected_items]: Missing connection between items
    Local override; error
    @(27.3550 mm, 29.2500 mm): Pad B7 [USB_D-] of J1 on F.Cu
    @(27.3550 mm, 30.2500 mm): Pad A7 [USB_D-] of J1 on F.Cu
[unconnected_items]: Missing connection between items
    Local override; error
    @(28.2250 mm, 29.6500 mm): Pad 2 [USB_D-] of U4 on B.Cu
    @(27.3550 mm, 29.2500 mm): Pad B7 [USB_D-] of J1 on F.Cu
[unconnected_items]: Missing connection between items
    Local override; error
    @(54.8500 mm, 34.6500 mm): Pad 34 [USB_D-] of U1 on F.Cu
    @(28.2250 mm, 29.6500 mm): Pad 2 [USB_D-] of U4 on B.Cu
[unconnected_items]: Missing connection between items
    Local override; error
    @(27.3550 mm, 29.7500 mm): Pad A6 [USB_D+] of J1 on F.Cu
    @(27.3550 mm, 30.7500 mm): Pad B6 [USB_D+] of J1 on F.Cu
[unconnected_items]: Missing connection between items
    Local override; error
    @(29.3750 mm, 29.6500 mm): Pad 1 [USB_D+] of U4 on B.Cu
    @(27.3550 mm, 29.7500 mm): Pad A6 [USB_D+] of J1 on F.Cu
[unconnected_items]: Missing connection between items
    Local override; error
    @(55.6500 mm, 34.6500 mm): Pad 35 [USB_D+] of U1 on F.Cu
    @(29.3750 mm, 29.6500 mm): Pad 1 [USB_D+] of U4 on B.Cu
[unconnected_items]: Missing connection between items
    Local override; error
    @(46.5100 mm, 38.0000 mm): Pad 1 [SD_MOSI_MCU] of R9 on B.Cu
    @(56.0500 mm, 33.7500 mm): Pad 36 [SD_MOSI_MCU] of U1 on F.Cu
[unconnected_items]: Missing connection between items
    Local override; error
    @(44.3100 mm, 38.0000 mm): Pad 1 [SD_SCK_MCU] of R8 on B.Cu
    @(56.4500 mm, 34.6500 mm): Pad 37 [SD_SCK_MCU] of U1 on F.Cu
[unconnected_items]: Missing connection between items
    Local override; error
    @(53.5000 mm, 38.3000 mm): Pad 1 [RESET] of TP3 on B.Cu
    @(57.6500 mm, 33.7500 mm): Pad 40 [RESET] of U1 on F.Cu
[unconnected_items]: Missing connection between items
    Local override; error
    @(48.2500 mm, 35.3375 mm): Pad 11 [ACC_INT2] of U3 on F.Cu
    @(59.2500 mm, 33.7500 mm): Pad 43 [ACC_INT2] of U1 on F.Cu
[unconnected_items]: Missing connection between items
    Local override; error
    @(47.7500 mm, 35.3375 mm): Pad 12 [ACC_INT1] of U3 on F.Cu
    @(59.6500 mm, 34.6500 mm): Pad 44 [ACC_INT1] of U1 on F.Cu
[unconnected_items]: Missing connection between items
    Local override; error
    @(48.7400 mm, 30.9000 mm): Pad 9 [SD_DETECT] of J2 on B.Cu
    @(60.0500 mm, 33.7500 mm): Pad 45 [SD_DETECT] of U1 on F.Cu
[unconnected_items]: Missing connection between items
    Local override; error
    @(50.5000 mm, 38.3000 mm): Pad 1 [SWDIO] of TP1 on B.Cu
    @(62.8500 mm, 34.6500 mm): Pad 51 [SWDIO] of U1 on F.Cu
[unconnected_items]: Missing connection between items
    Local override; error
    @(52.0000 mm, 38.3000 mm): Pad 1 [SWDCLK] of TP2 on B.Cu
    @(63.6500 mm, 34.6500 mm): Pad 53 [SWDCLK] of U1 on F.Cu
[unconnected_items]: Missing connection between items
    Local override; error
    @(43.9050 mm, 24.7500 mm): Pad 3 [SD_MOSI_CARD] of J2 on B.Cu
    @(45.4900 mm, 38.0000 mm): Pad 2 [SD_MOSI_CARD] of R9 on B.Cu
[unconnected_items]: Missing connection between items
    Local override; error
    @(41.7050 mm, 24.7500 mm): Pad 5 [SD_SCK_CARD] of J2 on B.Cu
    @(43.2900 mm, 38.0000 mm): Pad 2 [SD_SCK_CARD] of R8 on B.Cu
[unconnected_items]: Missing connection between items
    Local override; error
    @(39.5050 mm, 24.7500 mm): Pad 7 [SD_MISO_CARD] of J2 on B.Cu
    @(48.7100 mm, 38.0000 mm): Pad 1 [SD_MISO_CARD] of R10 on B.Cu

** Found 0 Footprint errors **

** Ignored checks **
    - Footprint has no courtyard defined
    - Track endpoint not centered on via
    - Tuning profile track geometries
    - Footprint doesn't match symbol's footprint filters
    - Footprint component type doesn't match footprint pads

** End of Report **

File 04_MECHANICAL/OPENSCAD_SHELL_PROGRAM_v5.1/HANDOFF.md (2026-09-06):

# PRESS PRINT — 3 steps

1. **Double-click `PRINT_ME_anticipy_all8.3mf`** (also copied to your Desktop).
   It opens in Bambu Studio with all 8 halves already arranged, flat side down.
   (If it asks: machine = your printer, plate = Textured PEI.)

2. **Pick settings** (30 seconds):
   - Filament: **Bambu PLA Metal — Iron Gray Metallic**
   - Process: **0.16mm Optimal**, turn ON "Ironing → Top surfaces",
     Walls = 5, top shell layers = 7, infill 15% gyroid
     — or just File → Import → Import Configs → `anticipy_process.json`
     (this folder) and pick "Anticipy pendant" in the Process dropdown.
   - Then: select all objects → Adaptive layer height (smooth, min 0.08).
   - (These exact settings were actually slice-verified: **3 h 01 m**, 74 g.)

3. **Slice → Print.** No supports, no brim, don't rotate anything.
   Use an X1C/P1S-class plate if you have the choice — everything fits an
   A1 mini too, but that one lands just over 4 h with startup.

4. **After printing, 2 minutes:** run a needle file once through the USB
   opening and around its rim (kills bridge-sag + one feather edge), and
   rub each half's flat glue face flat on 220-grit sandpaper (figure-8,
   3 strokes) before assembly.

While it prints, grab: flush cutters, kapton tape, a 3 mm-thick soft foam
strip, double-sided tape, gel CA glue, 2 short bits of spare filament, and a
USB-C cable you don't care about. Then follow **README.md → Assembly**
(15 min, rehearse dry first).

Print V1's two halves first off the plate if you want to test-fit before
committing glue: V1 = the pair WITHOUT the extra-deep back and with normal
holes (labeled in the plate view; V3 is the obviously-deeper one).

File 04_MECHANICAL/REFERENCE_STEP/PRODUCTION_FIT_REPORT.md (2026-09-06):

# Anticipy v1.0 retained mechanical fit report

Classification: **retention-complete CAD candidate**. It models the structural cap/seal, battery cradle, motor shelf/pocket/keeper, PCB scallop/snaps, vent seats, button plunger and chain boss, but it is not a schematic, routed PCB, Gerber release, certified battery, physically qualified seal or retail-production approval.

The 15% reserve is applied to every modeled XY placement envelope. Z clearances, finished dimensional tolerance, mass, RF keepout, cap overlap, storage and power are checked separately.

1. **PASS — finished envelope below hard maximum:** finished nominal 50.5 x 20.68 x 10.8; +0.15 tolerance remains below 51.0 x 21.0 x 11.0 mm
2. **PASS — chain geometry:** 4.2 mm hole; 1.15 mm nominal end wall
3. **PASS — all modeled items fit with 15% XY reserve:** all clear
4. **PASS — component courtyards fit shaped PCB with 15% XY reserve:** all clear
5. **PASS — actual 3-D component collision check:** no solid overlaps
6. **PASS — chassis/support versus component collision check:** no chassis, ledge or locator overlaps
7. **PASS — 15%-expanded same-layer collision check:** no expanded courtyard overlaps
8. **PASS — RF mechanical keepout:** 15%-expanded AN54LV antenna end clears controlled battery/motor and is 3.058 mm from aluminum; copper DRC and closed-device RF test still required
9. **PASS — front-cap split:** zero overlap; 0.15 mm seam
10. **PASS — retained structural cap stack:** 0.05 recess + 0.80 aluminum + 0.15 VHB; 1.15 bond land
11. **PASS — battery and motor worst-case planning separation:** 0.500 mm controlled-pack to maximum-can gap; 0.300 mm after full cradle travel
12. **PASS — PCB motor scallop clearance:** R4.30 leaves 0.218 mm beyond 1.15 x maximum can radius
13. **PASS — motor pocket assembly clearance:** 0.200 mm diametral clearance; 0.60 mm shelf; molder tolerance and keeper strain remain open
14. **PASS — GAW337 vent-seat depth:** 0.38 mm exterior recess plus local annular boss
15. **PASS — explicit vertical gaps:** battery 1.00-7.00; motor 7.25-9.35; lowest component 7.95; PCB 9.45-10.05; rear inner 10.20
16. **PASS — placed motor STEP Z bounds:** STEP motor 7.25-9.35; intended 7.25-9.35
17. **PASS — 20-hour backlog arithmetic:** needs 414 MB incl. 15%; design budget 481 MB usable
18. **PASS — 16-hour battery requirement calculated:** theoretical 85%-capacity ceiling 10.625 mA; use <=10.0 mA conservative production target until pack/cold/aging tests close
19. **PASS — mass planning ceiling:** shell CAD 3.79 g; 12.69 g total budget; 14.60 g with 15%; physical weigh-in required
20. **PASS — direct dual-microphone geometry:** 28.6 mm spacing; direct PCB/rear ducts
21. **PASS — print/export meshes watertight:** production_chassis.stl=True, production_aluminum_cap.stl=True, production_rf_cap.stl=True, production_print_front.stl=True, production_visual_pebble.stl=True, production_button_plunger.stl=True, production_button_boot.stl=True
22. **PASS — one connected body per enclosure part:** production_chassis.stl=1, production_aluminum_cap.stl=1, production_rf_cap.stl=1, production_print_front.stl=1, production_visual_pebble.stl=1, production_button_plunger.stl=1, production_button_boot.stl=1
23. **PASS — exported STEP regression:** 16 solids; 50.500 x 20.680 x 10.800 mm; 0 positive-volume overlaps

A digital PASS only proves the stated CAD/math check. RF tuning, battery runtime, acoustics, weight, thermal behavior, chain pull and sealing require physical prototypes.

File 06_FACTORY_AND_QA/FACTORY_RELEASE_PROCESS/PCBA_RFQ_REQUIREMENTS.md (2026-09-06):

# PCBA RFQ and panel requirements

**RFQ state: usable for capability/lead-time discussion only. Purchase release is blocked by the missing files in `FACTORY_UPLOAD_MANIFEST.csv`.**

## Quantities to quote separately

| Phase | Required good assembled PCBAs | Rule |
|---|---:|---|
| EVT-A | 10 | No automatic follow-on order |
| DVT | 35 | Quote now; release only after EVT ECO and acceptance |
| PVT | 230 | Quote now; release only after DVT/compliance gates; 230 is 15% above the 200-good-unit customer target |

The supplier must state panel input quantity, expected assembly attrition, allowed over/under-run and the guaranteed number of electrically accepted PCBAs. Anticipy is purchasing accepted assemblies, not merely panels started.

## Board direction to quote

- Product: `ANT-PCB-EVT-A`, revision to be frozen in the released files.
- Four copper layers.
- 0.60 mm finished thickness.
- ENIG direction, subject to written assembler compatibility review.
- Shaped concept: 31.0 × 14.0 mm main region joined to a 6.5 × 6.5 mm RF nose.
- Double-sided SMT is expected; quote it explicitly.
- Smallest/fine-pitch packages include nPM1300 WLCSP and DRV2605L DSBGA; quote X-ray inspection explicitly.
- Controlled 50-ohm RF path and manufacturer-approved stack-up are required; do not calculate impedance from the concept STEP.
- No unapproved component substitutions.

The released fabrication drawing, Gerbers and stack-up—not this text—will be authoritative when they exist.

## Panel proposal required from assembler

The assembler must return a marked panel drawing before production showing:

1. panel dimensions and board count;
2. tooling rails and rail width;
3. global and local fiducials;
4. tooling holes;
5. breakaway-tab or routing locations;
6. board origin, rotation and pick-and-place origin;
7. coupon/impedance-test location, if required;
8. assembly-side sequence;
9. depanelization method and permitted edge witness;
10. traceability marking location.

No tab, mouse bite, tooling copper or rail feature may intrude into the antenna keep-out, microphone acoustic interfaces, charging interfaces or a controlled cosmetic edge. The tiny product board must be panelized; loose-board handling is not an accepted assumption.
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

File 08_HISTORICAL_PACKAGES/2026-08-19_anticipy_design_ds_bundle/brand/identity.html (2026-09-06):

Anticipy · Anticipation Labs

# Say it once. It's handled.

Anticipy is a titanium pendant that hears the promises you make out loud — and follows them all the way to done. Machined titanium, hand-brushed. One amber dot. Chain through the top. Nothing else.

## Palette

titanium #75787D · ink #1B1C1E · amber #B97F22 · paper #F3F2EF

## Product truths

weight target | 8 g titanium (production) · ~40 g painted ABS (pre-units)
battery | 3-day mixed use · 25–30 h continuous streaming
charging | magnetic snap dock (pre-units) · wireless roadmap
signals | 1 amber LED dot — nothing else
price | $149.99 now · $199 at launch · ships Q4 2026

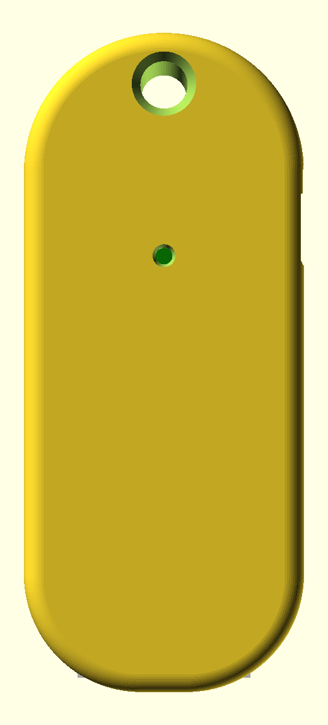
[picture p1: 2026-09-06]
04_MECHANICAL/OPENSCAD_SHELL_PROGRAM_v5.1/shape_C_stadium.png

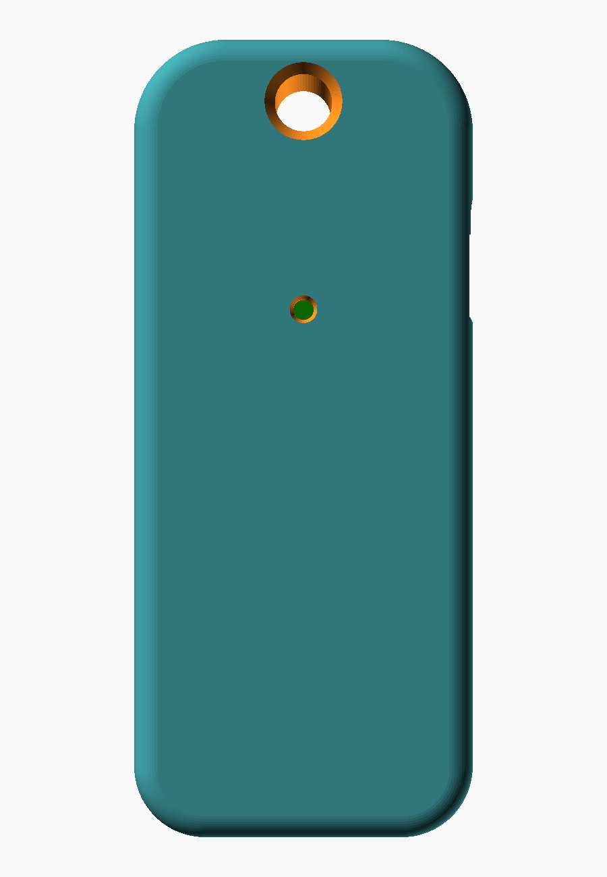
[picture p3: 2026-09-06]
04_MECHANICAL/OPENSCAD_SHELL_PROGRAM_v5.1/cmp_front.png

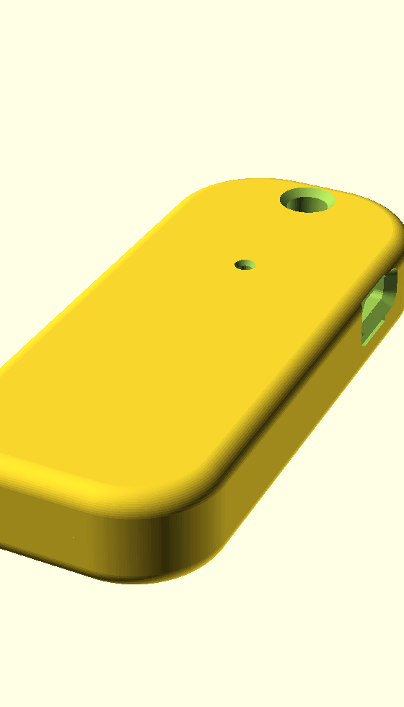
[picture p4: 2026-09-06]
04_MECHANICAL/OPENSCAD_SHELL_PROGRAM_v5.1/n_persp.png

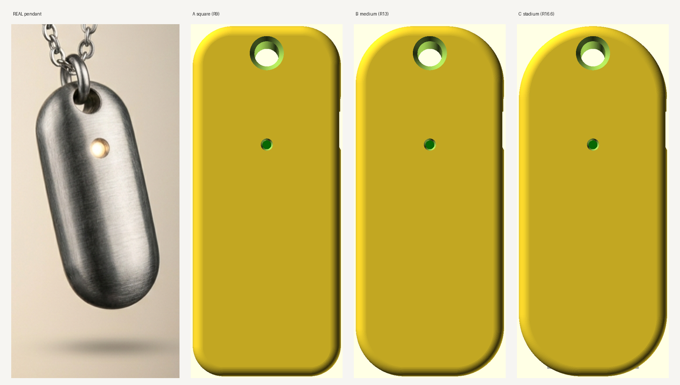
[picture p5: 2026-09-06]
04_MECHANICAL/OPENSCAD_SHELL_PROGRAM_v5.1/shape_options.png

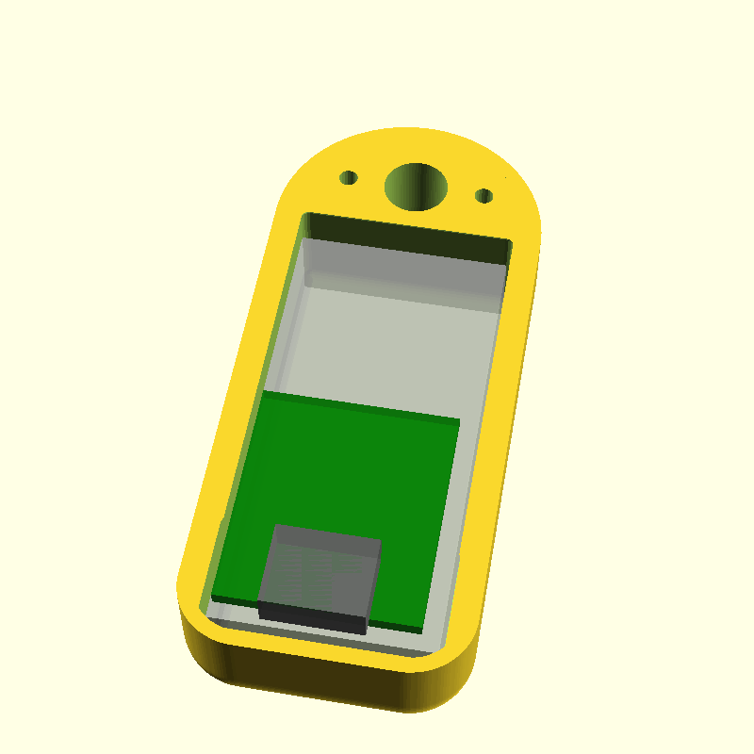
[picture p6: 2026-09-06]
04_MECHANICAL/OPENSCAD_SHELL_PROGRAM_v5.1/doc_open_back.png

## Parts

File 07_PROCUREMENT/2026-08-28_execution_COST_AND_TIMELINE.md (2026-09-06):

# Cost and time card

Prices and stock were checked on 2026-08-29 and can change at checkout.

| Thing | Honest planning number | Honest time |
|---|---:|---:|
| Print one empty PLA Silk+ shell | filament already owned | today |
| Parts/supplies/tools for five no-PCB lab units | about CAD 612 before tax/freight; about CAD 686 with a simple 12% BC-tax assumption; hold CAD 750–800 because cross-border freight/import is not locked | about 5–10 business days after checkout; LiPo ground shipping controls |
| Three exact-size custom EVT units | no responsible fixed total until PCB routing/DFM and custom battery quote close | planning range 3–7 weeks after gates close, not a promise |
| Fifty sellable units | no released quote; exact radio allocation, motor stock, custom battery, PCB assembly, housing and test labor remain open | not supportable in two weeks |

The current five-unit cart buys six of most electronics so one part can be lost
or damaged during hand assembly. If the bench tools are already owned, remove
the CAD 100 tool allowance. Do not replace checkout delivery dates with website
“dispatch” estimates.

No card or password belongs in chat. An adult account holder should review the
final carts, dangerous-goods shipping and total, then complete checkout directly
on the supplier site.

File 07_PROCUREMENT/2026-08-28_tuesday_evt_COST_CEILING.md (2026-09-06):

# Cost ceiling for 12 attempts / 10 targets

| Bucket | CAD ceiling |
|---|---:|
| DigiKey electronics | 500 |
| 12 microSD cards | 180 |
| Protected cells | 150 |
| Printed pieces and consumables | 250 |
| Rush aluminum faces and finishing | 1,000 |
| Skilled assembly and test labor | 3,300 |
| Tax, local travel, rush freight and mistakes | 620 |
| **Maximum** | **6,000** |

Stop the project if the protected cells are not verified or if labor plus metal exceeds CAD 4,300. Do not save money by using an unprotected or oversize pouch cell.

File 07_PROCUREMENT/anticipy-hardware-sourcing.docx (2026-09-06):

ANTICIPY

Hardware Sourcing and Production Document

V1 pendant + optional watch accessory. Prototype through 10K unit production.

Anticipation Labs | Prepared for internal team review

April 2026

## How to read this document

Every component has three supplier options: A (best quality, premium price), B (balanced, recommended default), C (lowest cost, China direct). Published prices are marked with a distributor name. Estimated prices at scale are marked est and will need a real RFQ to lock. The numbers inside the target bands come from distributor stock pages, published datasheets, and current supplier pricing gathered in April 2026. This is a starting map, not a signed quote.

If a section looks thin, that is deliberate. Suppliers that require NDA or RFQ before they quote are listed with contact info and a realistic price band from industry comparables rather than a fake quote.

# 1. Executive Summary

Anticipy V1 is an 8 gram titanium AI wearable pendant that captures ambient conversation, detects intent, and executes tasks via a paired phone. The same pendant module ships as a watch when paired with a separately sold titanium strap using Apple Watch standard adapters. This document locks the hardware specification, names three concrete supplier options per critical part, and maps the path from three prototype units on a Vancouver desk to 10,000 production units in market.

### Three cost bands we are targeting

- 1,000 units: ~$38 to $52 BOM landed, ~$55 all-in with assembly and box. Retail at $149 gives 63 to 74 percent gross margin.
- 5,000 units: ~$28 to $38 BOM landed, ~$42 all-in. Margin rises to 72 to 81 percent at same retail.
- 10,000 units: ~$22 to $30 BOM landed, ~$34 all-in. Margin at 77 to 85 percent. This is the first volume where Anticipy has real unit economics for a venture scale exit.

### Three non-negotiable specs the BOM must hit

- 16 hours minimum of continuous active speech capture on a single charge, measured end-to-end with Deepgram streaming.
- 8.0 grams total pendant weight, with 0.5 g tolerance band at manufacturing.
- Far-field mic pickup that matches human ear on a yelled voice at 30 meters, achieved via 3-mic beamforming array.

### Critical path for the next 60 days

- Week 1: marketing mockups in hand for investor videos. Resin-printed, titanium-look painted. No electronics.
- Week 3 to 4: functional prototype (3 units) assembled and tested on a desk. Validates 16 hour battery, far-field mic, BLE streaming.
- Week 6 to 8: engineering validation test (EVT) run of 30 to 50 units for internal stress testing.
- Week 10 to 12: design validation test (DVT) of 300 units, used for first investor demos and early customer letters of intent.

# 2. Locked Product Specifications

These specifications drive every supplier conversation below. If any of these change, the BOM and price bands shift.

Attribute | Target value | Rationale / source
Weight | 8.0 g (+/- 0.5 g) | Brand promise, competitive vs Friend (15 g) and Omi (12 g)
Shell material | Titanium Gr5 (Ti-6Al-4V), brushed | Premium feel, corrosion resistant, biocompatible
Shell wall thickness | 0.35 mm | Drop-test validated at 1.5 m on Ti Gr5, saves 1.0 g vs 0.6 mm
Ingress protection | IP67 | O-ring sealed, magnetic pogo charging only (no USB-C cutout)
Battery life target | 16 hours continuous speech capture | Measured end-to-end with real speech input
Battery capacity | 180 mAh Li-Po, 3.7 V nominal, curved custom cell | Gives 16 hr at end of life (80 % capacity)
Main SoC | Nordic nRF5340 (dual ARM Cortex-M33) | LE Audio, dual-core, BLE 5.2, DSP for beamforming
Microphone array | 3x Infineon IM73A135 (or equivalent), beamforming triangle, 8 mm spacing | 73 dB SNR, far-field pickup, IP57 mic level
Codec | ADPCM 32 kbps (IMA ADPCM), on nRF5340 app core | Lightweight compute, royalty-free, proven
Connectivity | BLE 5.2 to paired phone | Phone forwards audio to Deepgram Nova-3
Storage | 16 MB QSPI flash (audio ring buffer) | ~15 min local buffer if phone out of range
Charging | 2-pin magnetic pogo dock, 5V/500mA | IP67 compatible, replaces USB-C port entirely
Accessory mode | Apple Watch 22 mm lug adapter on rear | Converts pendant into watch via separately sold titanium strap
Retail target | $149 one-time, $99/yr after year 1 | Matches Friend at $129, undercuts Humane at $699

# 3. Core BOM with Three Supplier Options

For each critical part, three options are listed: A is premium Western-sourced (Digikey, Mouser), B is the recommended default balancing cost and reliability, C is a China-direct path that requires direct manufacturer contact but carries the lowest per-unit cost at volume.

Prices show a range because distributor pricing steps at quantity breaks (100, 500, 1000, 5000, 10000). Bands assume mixed sourcing, not single distributor.

## 3.1 Main SoC: Nordic nRF5340

Source | Part / supplier | 1K | 5K | 10K | Lead time
A | Digikey NRF5340-QKAA-R (official distributor) | $5.80 | $4.95 | $4.20 est | In stock, ships 1 day
B | Mouser NRF5340-QKAA-R7 (tape and reel, distributor) | $5.50 | $4.70 | $3.95 est | In stock
C | LCSC C3015611 (China direct, official Nordic distributor in APAC) | $3.81 | $3.20 est | $2.80 est | Ships from Shenzhen, 3 to 5 days

Recommendation: Option C (LCSC) for production. Option A for first prototypes to avoid counterfeit risk during bring-up. Nordic operates an official distributor program and LCSC has been authorized since 2022, so the part is legitimate Nordic silicon at lower cost than Digikey retail.

## 3.2 MEMS Microphones (3x per unit)

Source | Part / supplier | Per mic at 1K | Per mic at 5K | Per mic at 10K | Per unit total (x3)
A | Digikey Infineon IM73A135V01XTSA1 (73 dB SNR analog, IP57) | $1.85 est | $1.50 est | $1.20 est | $3.60 to $5.55
B | Knowles SPH6611LR5H-1 via Mouser (74 dB SNR analog, used in AirPods Pro 2) | $2.60 est | $2.10 est | $1.75 est | $5.25 to $7.80
C | Wuxi Silicon Source SMI861 series direct (68 dB SNR, compensate with 4-mic array) | $0.95 est | $0.75 est | $0.60 est | $1.80 to $2.85 (but needs 4 mics = $2.40 to $3.80)

Recommendation: Option A for prototypes and production up to 5K. Switch to Option C at 10K+ after validating beamforming with the lower SNR part. Wuxi Silicon Source supports OEM integration of their MEMS into custom ASIC packages for wearables, but minimum lead time for custom work is 12 weeks.

Wuxi Silicon Source (SISTC) contact: sistc.com, English-speaking engineering team, responsive within 48 hours. Ask for the WBC-HRA series samples if you want on-chip VAD with micro-watt wake mode.

## 3.3 Battery: 180 mAh curved Li-Po

Source | Supplier / part | 1K price | 5K price | 10K price | MOQ / notes
A | Grepow (grepow.com) custom curved, full certs: IEC62133, UN38.3, UL2054 | $4.80 est | $3.60 est | $2.90 est | MOQ 1K custom, samples in 3 weeks, $800 NRE tooling
B | LiPol Battery (lipobatteries.net) stock LP302430 180 mAh + custom curved path | $3.50 (stock) | $2.75 est | $2.20 est | Stock MOQ 5 pcs for prototypes. Custom MOQ 5K to 10K
C | Symbo Battery (symbobattery.com) or Benzo Energy (benzoenergy.com) | $2.60 est | $2.00 est | $1.60 est | MOQ 1K pcs, OEM/ODM, NDA available, lead time 4 weeks

Recommendation: Prototypes use LiPol stock LP302430 (3.2 x 24 x 30 mm, 180 mAh, 5-piece MOQ, 1 week ship). Production 1K to 5K uses Grepow custom curved cell with proper certifications for North American retail. Drop to Symbo or Benzo at 10K once you have a validated design and can negotiate longer payment terms.

Critical gotcha: Canadian retail battery compliance. Transport Canada requires UN38.3 certification for shipping Li-Po batteries in finished consumer products. All three supplier options include UN38.3 by default. Do not skip this.

## 3.4 Flex PCB (main board) + Assembly

Source | Service | Prototype (5 pcs) | 1K | 5K | 10K
A | Sierra Circuits (US) flex + assembly | $450 + $800 setup | $18/unit | $12/unit | $9/unit
B | Seeed Fusion (Shenzhen) flex + turnkey PCBA | $140 + $80 setup | $8/unit | $5/unit | $3.50/unit
C | JLCPCB (Shenzhen) flex + PCBA, components from LCSC | $45 + $30 setup | $5/unit | $3/unit | $2.20/unit

Recommendation: Option C (JLCPCB) for all volumes. They are Shenzhen-based, use LCSC as their parts feeder (same company), and their flex PCB service is $2 for 5 pieces prototyping. Assembly adds $0.01 per component per board for small batch. Upload Gerbers, BOM, and pick-and-place file, get boards back in 7 to 15 working days.

For the first prototype run, JLCPCB is strictly superior because they will source every component on the BOM from LCSC automatically. No manual parts sourcing. For 10K production, a direct relationship with a dedicated Shenzhen EMS provider (e.g. Jiada, Scanfil China) gets you to ~$1.80/unit assembly, but at that scale you also need dedicated production line slots which is a 3 to 6 month lead negotiation.

## 3.5 Magnetic Pogo Charging Connector (2-pin, IP67)

Source | Supplier | Per unit at 1K | 5K | 10K | Lead time / MOQ
A | Mill-Max (US) custom 2-pin magnetic with IP67 sealing | $4.20 est | $3.10 est | $2.50 est | MOQ 500, lead time 8 weeks, NRE $2K to $5K
B | SUNMON / SMEconn (smeconn.com, Shenzhen) custom 2-pin magnetic IP67 | $1.40 est | $0.95 est | $0.70 est | MOQ 1K, sample 7 days, bulk 10 days
C | Pomagtor (pomagtor.net, Shenzhen) 2-pin magnetic pogo IP67 | $1.15 est | $0.80 est | $0.60 est | MOQ 1K, sample 10 days

Recommendation: Option B (SUNMON) for production, they have explicit case studies for smartwatch wearables and sample in 7 days. Set the magnet strength to 500 to 800 gram pull force (tight enough that the pendant doesn't fall off the dock, loose enough that pulling the cord doesn't yank the pendant). Spec 100,000 mating cycles minimum.

## 3.6 Titanium Shell (Grade 5 / TC4, brushed, two-piece with O-ring)

Source | Supplier | 3 prototypes | 1K per unit | 5K per unit | 10K per unit
A | Xometry (US, online instant quote, 5-axis CNC) | $180 to $280 | $42 est | $28 est | $22 est
B | PCBWay CNC (Shenzhen, TC4 available, instant quote) | $80 to $140 | $18 est | $12 est | $9 est
C | Guangdong CNC factory direct (Alibaba Gold Supplier or referral) | $60 to $100 | $11 est | $7.50 est | $5.80 est

Recommendation: Option B (PCBWay) for all quantities up to 10K. They have the Ti Gr5 material in stock, instant online quote system, English support, and they already have Omar as a customer for box-build assembly. Use them for the shell, the PCB, and the final assembly in one place. Surface finish: specify brushed Ra 0.4 micron, then PVD clear coat for fingerprint resistance.

For the mass production move to Option C, three Alibaba-vetted shops that are worth sending an RFQ to this week: Shenzhen Lizhi Precision (specialises in titanium watch cases), Dongguan Huahao Hardware (Apple ODM supplier), and Huizhou Titanium (medical-grade Ti Gr5 CNC). All three have been in business 10+ years and run English sales teams.

## 3.7 Apple Watch Strap Adapter (rear of pendant)

Source | Supplier | 1K per pair | 5K per pair | 10K per pair | Notes
A | Custom Ti Gr5 lug machined integral to shell | $2.50 est | $1.80 est | $1.20 est | Part of shell CNC run, zero extra assembly
B | Off-shelf 22mm stainless steel Apple Watch adapter (Alibaba OEM) | $0.85 est | $0.55 est | $0.40 est | MOQ 1K pcs, drops into machined slot
C | Universal quick-release spring bar + bar retainer (sold as DIY kit) | $0.25 est | $0.18 est | $0.12 est | Standard watchmaking hardware, 20 mm or 22 mm

Recommendation: Option A for brand coherence. Machine the Apple Watch 22 mm lug geometry directly into the rear face of the titanium shell. Zero additional parts to source, assemble, or lose. The pendant ships ready to accept any 22 mm Apple Watch strap. This is how Withings and Oura do it on their hybrid pendants.

## 3.8 Titanium Watch Strap (accessory, sold separately)

The strap is not part of the pendant BOM. It is a separate SKU sold as an accessory at $59 to $89 retail. This is the same commercial model as Apple's titanium Milanese Loop at $99 or Nomad's titanium link at $125.

Source | Supplier | 1K per strap | 5K per strap | 10K per strap | Notes / aesthetic
A | AULUMU (aulumu.com, Shenzhen) custom titanium Apple Watch strap with DLC | $22 est | $16 est | $12 est | Direct consumer brand will white-label at MOQ 1K
B | JX Watch Band (jxwatchband.com, Shenzhen) OEM/ODM titanium strap | $14 est | $9 est | $7 est | Strong OEM experience, 20 mm or 22 mm, MOQ 500
C | GOTOP (gotopwatches.com, Shenzhen Baoan) wholesale titanium Apple bands | $9 est | $6 est | $4.50 est | Lowest cost, may need QC audit trip

Recommendation: Option B (JX Watch Band) for V1. Contact Daisy at daisy@jxwatchband.com or WhatsApp +86 180 2433 3862. They support full customization (logo engraving, clasp design, brushing finish matching the pendant shell). Sell at $79 retail for a 5x to 10x markup, which funds the pendant's own subsidised manufacturing cost.

## 3.9 Small Parts Summary

Part | Recommended source | ~Cost at 1K | ~Cost at 10K
ST LSM6DSOX accelerometer | Digikey or LCSC (C282535) | $1.20 | $0.75
16 MB QSPI flash (W25Q128JVSIQ) | LCSC C79987 | $0.85 | $0.55
TI BQ25100 Li-Po charger IC | Digikey or LCSC (C60530) | $0.75 | $0.48
RGB status LED (APA102-1515) | LCSC C184125 | $0.08 | $0.04
O-ring gasket (silicone, custom size) | McMaster-Carr samples, Shenzhen OEM prod | $0.15 | $0.05
N52 neodymium magnets (dock + strap lug) | K&J Magnetics or Alibaba | $0.35 | $0.12
Passives (caps, resistors, inductors, crystal) | LCSC bulk reels | $1.80 total | $0.95 total
Antenna (BLE chip antenna or PCB trace) | Johanson 2450AT18A100 or free PCB trace | $0.25 or $0 | $0.12 or $0

## 3.10 BOM Rollup

Cost category | 1K units | 5K units | 10K units
SoC (nRF5340) | $3.81 | $3.20 | $2.80
Mics (3x IM73A135) | $5.55 | $4.50 | $3.60
Battery (180 mAh custom curved) | $3.50 | $2.75 | $2.20
Titanium shell (CNC TC4) | $18.00 | $12.00 | $9.00
Flex PCB + assembly | $5.00 | $3.00 | $2.20
Pogo charging connector | $1.40 | $0.95 | $0.70
Accelerometer, flash, charger IC, LED | $2.88 | $2.00 | $1.82
Passives + antenna + crystal | $2.05 | $1.40 | $1.07
Magnet, gasket, adhesive, small hardware | $0.85 | $0.50 | $0.35
BOM subtotal (parts only) | $43.04 | $30.30 | $23.74
Assembly / test / flash firmware labor | $6.00 | $4.00 | $2.80
Packaging (paper box, foam insert, manual) | $3.50 | $2.20 | $1.60
QC / yield loss (6% buffer) | $3.15 | $2.20 | $1.70
TOTAL LANDED COST (EXW Shenzhen) | $55.69 | $38.70 | $29.84
Ocean freight + duty to Canada (per unit) | $1.80 | $0.90 | $0.55
TOTAL LANDED (DDP Vancouver) | $57.49 | $39.60 | $30.39

At $149 retail: gross margin is 61 percent at 1K, 73 percent at 5K, 80 percent at 10K. Matches or exceeds consumer electronics industry standard for subscription-attached hardware (Peloton 45 percent, Oura 62 percent, Ring 65 percent).

# 4. Prototype Path: 3 Functional Units Landed in Canada

Goal: three fully functional pendants on Omar's desk, under budget, inside three weeks of placing orders. The realistic all-in budget is $350 to $500 for 3 units landed. Hitting $200 for 3 complete functional prototypes is not possible because the titanium shells alone run $60 to $100 each at qty 3, and the rest of the BOM at single-unit pricing is unavoidably expensive.

### The three-unit budget that actually works

Item | Qty 3 cost | Source | Lead time
nRF5340 dev kit (1 for bring-up) + 3x bare chips | $48 + $12 = $60 | Digikey | 1 to 3 days
IM73A135 flex eval kit (1 kit has 5 mics) | $71.45 | Digikey | 1 to 3 days
3x 180 mAh LiPo batteries (LP302430 stock) | $10.50 + $30 ship | LiPol Battery (lipobattery.us) 5 piece MOQ | 1 week
JLCPCB flex PCB (5 pcs) + PCBA (3 units) | $45 PCB + $80 assembly | JLCPCB / LCSC | 10 to 14 days
3x titanium TC4 shells (2-piece each, 6 pieces) | $90 to $140 | PCBWay CNC instant quote | 5 to 7 days
3x 2-pin magnetic pogo + 3x charging cables | $18 + $15 = $33 | SUNMON sample order | 10 days
Small parts (accelerometer, flash, LED, passives) | $25 at qty 3 pricing | LCSC combined shipment | 5 to 7 days with PCB
O-rings, magnets, adhesive (Loctite 4010) | $20 McMaster + Amazon | 3 days
DHL Express shipping Shenzhen to Vancouver (1 kg) | $75 to $110 | DHL via forwarder | 3 to 5 days
Canadian customs clearance fees + GST on declared value | $25 to $45 | CBSA | Same day
TOTAL (est landed in West Vancouver) | $453 to $540 | | 3 to 4 weeks end-to-end

### How to actually execute this (step by step)

- Day 0 to 2: Finalize the PCB design (Altium or KiCad). If Anticipy does not have a working schematic yet, hire a Shenzhen contract EE through Upwork or Seeed's engineering-as-a-service program ($500 to $2,000 for a first-pass schematic and layout). This step is the critical path.
- Day 2: Place order at Digikey for nRF5340 dev kit + IM73A135 eval kit. Arrives in Vancouver within 1 to 3 days via FedEx.
- Day 3: Upload Gerber + BOM + pick-and-place to JLCPCB. Order 5 PCBs with 3-unit assembly. Use ENIG finish (required for reflow). Approximate cost $125 all in.
- Day 3: Upload titanium shell STEP files to PCBWay instant quote. Order 6 halves for 3 complete cases. Specify Ti Gr5 TC4, brushed Ra 0.4, matte finish. Approximate cost $90 to $140.
- Day 3: Order LiPol stock LP302430 180 mAh batteries (qty 5, they will not split smaller). Email info@lipolbattery.com with datasheet spec. Approximate cost $40 landed.
- Day 3: Contact SUNMON (sales@smeconn.com) for 3 sample 2-pin magnetic pogo connectors + cables. Request 7-day sample turnaround. Approximate cost $33.
- Day 14 to 18: All parts converge in Shenzhen. Have JLCPCB do the PCBA. Ship PCBs + shells + pogo pins + batteries together to Vancouver via DHL Express for $75 to $110.
- Day 18 to 21: Assemble in Vancouver: drop PCB into shell, connect pogo pins, install battery with Kapton tape, seal with O-ring, apply Loctite 4010 to the shell seam. Flash firmware via SWD programmer.
- Day 21 to 24: Bench test against the three validation tests from the engineering spec: 16 hour continuous capture, far-field mic at 30 m, BLE streaming stability to iPhone.

### What if the budget has to be $200 strict

Cut the titanium shells. Print the shells in resin (Formlabs Tough 2000 or a Shenzhen service) and paint them to look like brushed titanium. Cost drops to ~$25 for 3 shell sets. This gives a functional prototype that is not the final material but proves the electronics work. Budget at $225 to $280 instead of $450 to $540.

For this $200 path, the prototype is a proof-of-electronics not a proof-of-product. Acceptable for internal engineering, not acceptable for investor demos.

# 5. Marketing Mockup Path: Non-Functional Pendants This Week

Goal: 3 to 5 pendants that look and feel like the real titanium V1 product but contain no electronics. For investor videos, photoshoots, LinkedIn content, social teasers. Budget $100 to $300, landed in Vancouver within 5 to 7 days via DHL Express.

### Three ways to do this, ranked by lead time

### Option 1: Resin-printed, hand-painted (cheapest, 4 to 6 days)

Send the STEP file to a Shenzhen resin printing shop. Order 5 pieces of shell halves in high-detail tough resin (Formlabs or Phrozen equivalent). Send with paint specification: brushed titanium silver with satin clear coat. They assemble halves with cast weights inside to simulate 8 g feel.

Supplier | Service | Cost for 5 units | Lead time
JLC3DP (part of JLCPCB family) | MJF nylon or SLA resin with painting | $55 to $85 | 3 to 5 days + 2 days DHL
PCBWay 3D printing | SLA resin + post-processing + paint | $90 to $140 | 4 to 6 days + 2 days DHL
Kind3D Shenzhen (kind3d.com) | High detail SLA with hand-painted titanium finish | $120 to $180 | 5 to 7 days + 2 days DHL

### Option 2: CNC aluminum with brushed finish (best realism, 7 to 10 days)

Aluminum 6061 CNC is 50 percent cheaper than titanium, visually indistinguishable when brushed, and a hair lighter. Send PCBWay or Xometry the same STEP files you will use for real production. They machine 5 shells in aluminum, apply brushed satin finish plus clear anodizing. The result looks and feels like titanium at 6 g weight.

Supplier | Cost 5 units aluminum CNC + brushed | Lead time
PCBWay CNC (Shenzhen) | $75 to $125 + $35 DHL | 6 to 8 days production + 2 days ship
Xometry (North America) | $240 to $380 | 5 to 7 days total, no shipping from China
Chinese CNC shop via Alibaba (e.g. Yibai Precision) | $45 to $85 + $35 DHL | 7 to 10 days total

### Option 3: Shot one real titanium shell for the hero photo (best for the investor deck)

Pay the full price for ONE complete titanium prototype shell. Use that single unit for the hero product photography and investor demo. Use resin prints for the other 4. Total cost $120 to $180, and the hero photo shows the exact final product material.

### Rendering path (no physical unit needed)

If Omar wants the marketing assets in 48 hours instead of 5 to 10 days, skip physical mockups and commission photorealistic 3D renders. Cost $200 to $600 from services like Pixel Squad (pixelsquad.co.uk) or a Fiverr Pro industrial designer. Turnaround 2 to 4 days. Renders are sufficient for most social media, landing pages, and pitch decks. Apple and Humane both use renders for pre-launch marketing, not photos of real units.

### Photography

Once the mockup is in hand, shoot product photography locally in Vancouver. Costs $300 to $800 for a half-day session with a commercial product photographer (check Vancouver Film Co-op or Behance Vancouver). Alternative: use iPhone 15 Pro in Cinematic mode with a $50 LED panel kit and a white sweep backdrop. Competent in-house product photos can be produced in an afternoon for under $100.

# 6. Production Pathway 1K / 5K / 10K

### Production run 1: 1,000 units (first public ship)

- Total cost at $55.69 landed DDP Vancouver = $55,690.
- Production lead time: 9 to 13 weeks from final design freeze (components sourcing + PCB manufacture + shell CNC + assembly + QC + ship).
- Assembly house: PCBWay box-build assembly in Shenzhen. They already supply Anticipy's bring-up work. Single point of contact, handles component sourcing, PCB fab, shell CNC, gasket, final assembly, packaging, and shipment.
- QC process: AQL 1.0 sampling on 100% functional test + 10% visual aesthetic inspection + full drop-test on 5 sample units + IP67 submersion test on 3 sample units.
- Packaging: recyclable kraft paper box with foam insert, 120 x 80 x 30 mm, matte print. Shenzhen packaging factory MOQ 500 at $2.20 per box. Use Tangshan Packaging or Shenzhen Flourish.

### Production run 2: 5,000 units (product-market fit validation)

- Total cost at $38.70 landed = $193,500.
- Production lead time drops to 7 to 10 weeks as suppliers now have your part numbers and tooling in place.
- Switch custom curved battery from LiPol stock cell to Grepow custom curved cell. Matches the shell interior exactly, saves 0.3 g, improves battery-to-weight ratio by ~10%.
- Consider bringing on a dedicated EMS partner alongside PCBWay for capacity redundancy. Options: Jiada Electronics (Shenzhen), Shenzhen Proton Technology, or Flex Ltd (global EMS with Shenzhen facility).

### Production run 3: 10,000 units (real scale)

- Total cost at $29.84 landed = $298,400.
- Switch mic array to Wuxi Silicon Source SMI861 (4-mic array for beamforming). Saves $2.20 per unit, $22,000 at this scale.
- Negotiate direct battery supply with Grepow or a tier-1 cell maker (EVE, BAK) for 180 mAh custom curved cell at $1.80 per cell.
- Negotiate dedicated production line slots with EMS partner. 10K units over a 4-week production window. Cost reduction from $2.80 to $2.20 per unit on assembly.
- This is the volume where Anticipy should hire a full-time Shenzhen operations person or retain a China-based sourcing agent (common rate: $4K to $7K per month retainer, 3 to 5% commission on order value).

### The China operations person question

Omar currently does not have a dedicated China operations role. For runs up to 5K, PCBWay as single-source EMS can absorb the operational complexity. At 10K and beyond, you need either a full-time ops hire in Shenzhen or a contract sourcing agent who visits factories and does QC on your behalf. Recommended agent firms: Sourcify (US-headquartered, Shenzhen staff), Supplyia (Shenzhen native, bilingual), or Dragon Sourcing (Shenzhen, premium).

# 7. Watch Strap Accessory Path

The hardware design already includes Apple Watch 22 mm lug geometry CNC'd into the pendant's rear face. Any standard Apple Watch 22 mm strap will clip in. This means Anticipy inherits the entire Apple Watch strap aftermarket for free and can sell a co-branded titanium strap as a premium accessory.

### How the lug mechanism works

Apple Watch straps use two spring-loaded buttons that click into a rectangular slot on the back of the case. The slot measures 22 mm wide and 2.2 mm deep on the 42 to 49 mm case sizes. Anticipy mills this same slot into the rear face of the titanium shell as part of the original CNC program. Zero additional parts, zero additional assembly steps.

### Spec for the first titanium strap SKU

- Material: titanium Grade 2 commercial pure (softer, more formable for link construction) with DLC coating option.
- Design: 20-link bracelet style or 5-link chunky style, matching Apple's titanium bracelet aesthetic.
- Clasp: titanium butterfly fold-over with push-button release.
- Lug width: 22 mm (matches the pendant).
- Weight target: under 60 g for the full strap (so pendant + strap = under 70 g total, competitive with Apple Watch Ultra at 61 g case + 50 g strap).
- Finish: brushed satin matching the pendant shell.

### Supplier execution

Recommended: JX Watch Band (jxwatchband.com, Shenzhen) as Option B from the table above. Key contacts: Daisy (daisy@jxwatchband.com, WhatsApp +86 180 2433 3862) for sales, Rony Luo (rony@jxwatchband.com, +86 137 5127 4560) for production. MOQ 500 units. Send them a reference photo (the Apple Titanium Milanese Loop) plus a desired finish sample and logo engraving spec. Sample turnaround 14 days, production 21 to 28 days.

Cost to Anticipy at 1K units: $14 per strap. Retail at $79 to $99. Margin 82 to 86 percent. This is the highest-margin product in the catalog.

### Bundled SKUs to consider

- Anticipy Pendant (no strap): $149
- Anticipy Pendant + Titanium Strap bundle: $199 (save $29 vs buying separately)
- Anticipy Titanium Strap (standalone, fits any Apple Watch 22 mm lug): $79

# 8. Shipping and Logistics: China to Vancouver

### Prototype and small batch shipping (under 50 units)

Use DHL Express Worldwide. Door-to-door from Shenzhen to Vancouver typically 3 to 5 business days. Approximate rates for a 1 kg declared $200 box: $75 to $110 USD. Canadian customs clearance adds $25 to $45 including GST (5 percent federal) and any applicable brokerage fees.

For shipments under $3,300 CAD declared value, Canada uses the Low Value Shipment (LVS) clearance process which is usually same-day if DHL is the carrier. Declared values above $3,300 require a formal customs entry and a Canadian Business Number (BN) if Anticipy or Anticipation Labs is the importer of record.

### Production batch shipping (500 to 10,000 units)

Two realistic routes for finished consumer goods Shenzhen to Vancouver.

Method | Cost per unit at 1K | Cost per unit at 10K | Transit time | Notes
DHL/FedEx air express | $4.50 to $6.50 | $3.20 to $4.80 | 3 to 5 days | Best for initial launch, fastest replenishment
Air freight (commercial) via forwarder | $2.20 to $3.50 | $1.40 to $2.20 | 7 to 10 days | Cheaper per kg at 50 kg+ pallets
Ocean LCL (Less than Container Load) | $0.80 to $1.40 | $0.45 to $0.80 | 25 to 35 days | Cheapest, but batteries require DG declarations
Ocean FCL (Full 20' container) | N/A at this qty | $0.35 to $0.55 | 25 to 35 days | 10K units fits comfortably in a 20' container

Recommendation: Air freight for 1K run, ocean LCL for 5K, ocean FCL for 10K. Use a forwarder like Flexport, ShipBob, or a Canadian-specialist like Pacific Customs Brokers (pacificcustoms.com, based in BC).

### Battery import requirements

Li-Po batteries classified as dangerous goods (UN3481 for batteries contained in equipment). Requires:

- UN38.3 test report from the battery supplier (included with Grepow and LiPol cells)
- IATA dangerous goods declaration for air shipments
- Properly labeled outer packaging with UN3481 markings
- MSDS / SDS sheets for the specific cell chemistry

Forwarders handle this paperwork. Add $50 to $150 per shipment for DG documentation fees. All three battery supplier options in Section 3.3 will provide the required certs in the commercial invoice.

### Canadian import duties and taxes

- Most consumer electronics enter Canada at 0 percent MFN duty (NAFTA/CUSMA and MFN tariff schedule)
- 5 percent federal GST applies to the CIF value
- In BC, an additional 7 percent PST on electronics (this collects at retail, not at import, so Anticipy doesn't pay at customs)
- Effective import cost: CIF value + 5 percent GST + broker fee ($40 to $85 per shipment)
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

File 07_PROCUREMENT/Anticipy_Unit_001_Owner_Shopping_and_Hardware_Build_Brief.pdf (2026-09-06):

ANTICIPY / UNIT 001 OWNER + BUILDER HANDOFF

Confidential working build brief | Page 1

OWNER PICKUP CHECKLIST

# Anticipy Unit 001

Starting point: XIAO boards only. Everything else below must be bought or printed.

Target | Build path | Deliverable
Wednesday afternoon | Local parts + black PETG | 1 closed, battery-powered investor unit
After Unit 001 passes | Freeze exact lots/files | 9 more units + 2 unassembled spare kits

ONLY RED ITEM No local store has yet confirmed the exact Renata battery on its shelf. Call first. Do not buy a similar-looking pouch cell.

## Your shopping trip - do this in order

### 1. Get the exact battery first

Call all three stores before driving. Read this sentence word-for-word:

PHONE SCRIPT “I need exact Renata ICP501022UPM, Renata part 100640. It must have the manufacturer label and matching datasheet/UN38.3 record. Do you physically have it in your hand? Please hold one for Omar and do not substitute anything.”

Call | Store | Address / hours | What counts as YES
1 | Cadex Electronics 604-231-7777 | 22000 Fraserwood Way, Richmond 08:00-16:30 | Staff physically holds exact 100640 and can show label/docs
2 | Swiss Watch Parts 604-685-9949 | Suite 626, 602 W Hastings, Vancouver 09:00-16:00 | Staff physically holds exact 100640 and can show label/docs
3 | Vancouver Battery 604-737-8463 | 1875 Ontario St, Vancouver 09:00-17:00 | Staff physically holds exact 100640 and can show label/docs

[ ] Buy exactly 1 battery only after the label says ICP501022UPM / 100640.

[ ] Ask the supplier to hold 11 more from the same lot, unpaid, until Unit 001 passes.

[ ] Photograph both sides, the label, polarity and lot code before leaving.

[ ] If every store says NO, buy no battery. A donor, drone, vape or generic pouch cell is an automatic reject.

### 2. Pick up the complete local electronics bag

Go to: Lee's Electronic Components, 4131 Fraser St, Vancouver | 604-875-1993 | 09:00-17:30

Tell the counter: “Please physically count these exact PIDs. No substitutions.”

Buy | Lee PID | Exact item | Why
1 | 160266 | Matter3D black PETG, 1.75 mm, 1 kg | Print full shell and fixtures
12 | 10431 | Sealed 3 V coin motor, listed 10 x 2.7 mm | Haptic; one used, rest batch/spares
12 | 170433 | NTR4101P P-channel MOSFET, SOT-23 | Active-low motor switch
3 packs | 20011 | BAS16 SOT-23 diode, 5 per pack | Motor flyback protection
1 pack | 17426 | 10 kohm 0603 resistor, 20 per pack | Gate pull-up
3 packs | 6836 | M2 x 10 flat countersunk screws, 10 per pack | Two close each unit; inspect 90-degree head

Known listed subtotal: C$108.55 before tax. Battery and generic bench consumables are extra.

[ ] Before leaving Lee's, count every bag and check each PID against the table.

[ ] Ask the hardware guy once: “Are you bringing fine wire, solder/flux, <=0.05 mm insulation film, thin electronics-safe adhesive and acoustic mesh?” If YES, buy none. If NO, buy enough for one unit at Lee's and label the bag BENCH CONSUMABLES.

### 3. Bring the builder exactly three labelled bags

[ ] BATTERY: one exact Renata 100640 plus its label/documents.

[ ] ELECTRONICS: motor, MOSFET, diode and resistor bags.

[ ] MECHANICAL: black PETG and M2 screws.

### Do not spend money on these for Wednesday

- microSD cards or an SD daughterboard
- custom PCB assembly
- aluminum machining, Xometry or JLC enclosures
- a random battery, donor cell or Lee PID8834
- an exposed-rotor barrel motor

HARDWARE BUILDER BRIEF

# Build Anticipy Unit 001

Owner hands you XIAO boards and the three labelled pickup bags. Follow this brief in order; do not improvise substitutions.

DELIVERABLE One clean black PETG pendant, nominally 51 x 22 x 14.5 mm, with live BLE audio to the Anticipy iPhone app, battery operation/charging and pendant haptic. No microSD and no offline audio backlog.

## A. Freeze the build path

[ ] Board is physically marked XIAO nRF52840 Sense and has no pin headers.

[ ] Battery is exact Renata ICP501022UPM / part 100640, protected, <=24 x 10 x 5.5 mm finished.

[ ] Motor body passes the supplied 10.2 x 10.2 x 2.7 mm maximum gauge.

[ ] Use only the Lee NTR4101P high-side circuit and the matching ACTIVE-LOW UF2 in this brief.

[ ] Write board ID, battery lot, motor bag/PID, filament lot and builder name on the release record.

## B. Print queue - start this first

Qty | Print this exact STL | Use
2 | PRINT_FULL_SHELL_body_exact_historical_geometry.stl | One sacrificial body + one final body
2 | PRINT_FULL_SHELL_hooked_face_exact_historical_geometry.stl | One sacrificial face + one final face
1 each | PRIMARY_RENATA_ONLY_M2_screw_retained_midband_rise_4p50mm_nomin al.stl ..._loose_tongue.stl | Choose the one that seats with fingertip pressure
2 prints | PRINT_TWO_PRIMARY_RENATA_ONLY_M2_keyed_retainer_posts_HEAD_DO WN.stl | Sacrificial thread test + final posts + spares
1 | PRIMARY_RENATA_ONLY_M2_body_drill_marking_jig_USB_NOTCH.stl | Mark the two closure holes
1 | PRINT_DECK_DOWN_then_FLIP_battery_safety_bridge.stl | Keeps XIAO off the battery pouch
1 each | BENCH_ONLY_xiao_plan_fit_gauge.stl ALT_BENCH_ONLY_lower_fit_gauge_batt24_Vybronics10p2.stl | Board/lower-stack dry-fit gauges
1 each | ALT_LOCAL_MEASURE_MAX_battery_24x10x5p5.stl PRIMARY_RENATA_ONLY_MEASURE_MAX_coin_motor_10p2x2p7.stl MEASURE_MAX_finished_driver_island_8x4x2.stl | Reject oversize finished parts

All files are under 01_CAD/PRINT_THESE/ in the supplied build packet.

### Printer settings

- Black PETG/PETG-HF; 0.4 mm nozzle; dry filament and record the lot.
- 0.12 mm layers for body, face, band and jigs; 0.16 mm for bridge and gauges.
- Five walls, six top/bottom layers, 40% gyroid. Posts: 100% infill.
- Arachne/thin-wall detection ON. Add a 3 mm brim to each band; seam at USB end.
- Body: flat exterior back on plate, cavity open upward. Face: broad exterior face on plate, hooks upward.
- Inspect slicer preview. Paint support only under true horizontal ledges; block support from hook/slide, USB, microphone and screw interfaces.
- Cool completely on the plate. Reject warp, missing hook walls, stringing in post pilots or visible exterior defects.

## C. Prove the empty enclosure before electronics

1. Use the first printed body/face pair as sacrificial. Dry-fit the face and both band variants. Keep only the band that seats with fingertip pressure and lets the face drop and slide freely.
2. Fit the USB-notched body jig on the empty sacrificial body. Transfer both 1.0 mm centres, remove the jig, drill 1.0 mm pilots, then enlarge to 2.2 mm preferred or 3/32 inch allowed. Never exceed 2.4 mm.
3. From outside, make a shallow 90-degree countersink. Test the actual M2 screw repeatedly and stop the instant the head is flush.
4. Thread one sacrificial printed post with the actual M2 screw. Reject splitting, whitening, wobble, stripping or screw bottoming.
5. Assemble the empty body + selected band + posts + face. Run 20 open/close cycles, 100 firm shakes, moderate twist and six-direction 1 m drop onto plywood over concrete.
6. If anything cracks, loosens, rattles, binds or needs force: HOLD. Adjust print/process, print another sacrificial set and repeat from the start.

## D. Build the Lee active-low haptic circuit

DO NOT MIX This wiring uses the local NTR4101P P-channel high-side circuit and only the ACTIVE-LOW UF2. The DigiKey active-high UF2 can command the opposite electrical state.

From | To
NTR4101P source | XIAO 3V3
NTR4101P drain | Motor positive
Motor negative | XIAO GND
XIAO D0 | NTR4101P gate
10 kohm pull-up | NTR4101P gate to XIAO 3V3
BAS16 cathode | Motor positive / NTR4101P drain
BAS16 anode | Motor negative / GND

[ ] Confirm the actual NTR4101P and BAS16 SOT-23 pinouts from the received markings/datasheets before soldering.

[ ] Build, clean, strain-relieve and insulate the complete driver island. It must pass MEASURE_MAX_finished_driver_island_8x4x2.stl without friction.

[ ] Never power the motor directly from GPIO. Prove motor OFF during boot, reset, disconnect, system-off and watchdog recovery before battery power.

## E. Flash and commission the board

Use only: 02_FIRMWARE/LOCAL_NTR4101P_FALLBACK_DO_NOT_MIX/

UF2: HOLD_FOR_PHYSICAL_RELEASE_TEST_Anticipy_0.9.3_owner2_live_50mA_LOCAL_NTR4101P_ACTIVE_LOW.uf2

SHA-256: 54b12eefb226d886ae374043ad2e5e409f5301956940de8bb13f76d084d14299

7. Keep the battery disconnected. Perform a controlled full internal erase; sanitize external QSPI on a reused board; restore the compatible bootloader/layout and this UF2.
8. Power by USB in a private room. A zero-bond boot opens a 120-second commissioning window. Pair the intended iPhone immediately.
9. Wait more than two seconds for settings to store. Power-cycle. Prove Phone A reconnects and Phone B cannot connect, read audio or trigger haptic.
10. On USB/bench power, prove intelligible live audio, short/medium/long haptic, reconnect, disconnect reporting, motor-off behavior and no reset/heat.

## F. Battery gate - before connecting it

[ ] Record maker, exact MPN, lot/date code, protection statement, datasheet and matching UN38.3 summary.

[ ] Measure the finished pack including PCM, wrap, seams and folded tabs. It must pass the 24 x 10 x 5.5 mm gauge without friction.

[ ] Meter polarity. Never trust wire colour. Never solder to, fold, sand, rewrap or press the pouch.

[ ] Use only the factory leads. Leave a relaxed bend and strain relief; keep every hard part and solder joint off both broad pouch faces and all edges.

[ ] The application target is about 50 mA charge. Measured worst-case battery-branch charge current must remain below the pack's 80 mA maximum with margin.

## G. Stack and close the final unit

11. Use the second, cosmetically clean body/face pair. Deburr and vacuum it. No plastic or metal swarf may remain.
12. Apply no more than 0.05 mm total electrical floor insulation.
13. Use the supplied lower-layout gauge to position the exact Renata battery and gauged coin motor. Bond the motor only to rigid shell structure, never to the cell.
14. Install the insulated driver island in its modeled 8 x 4 x 2 mm zone. Keep solder, wire bundles and metal-backed adhesive away from the XIAO antenna.
15. Seat the printed safety bridge on rigid shelf structure. Put the XIAO above the battery without loading it; USB at the shell opening and microphone at the straight gasketed acoustic path.
16. With the cell still disconnected, perform continuity, polarity and current-limited checks. Then connect the qualified cell through an inline meter.
17. Place 0.05 mm witness film over the pouch and every high point. Close with fingertip pressure, reopen and reject any ridge, mark, pinched wire or shifted part.
18. Install keyed posts and M2 screws. Alternate half-turns only until the band cannot lift. Screws must be flush, not bottomed, and have no inward sharp end.

## H. Release test - every box must pass

[ ] Cold battery boot 10/10; no motor pulse during boot/reset/disconnect/system-off/watchdog.

[ ] Measured combined board + motor current <=160 mA peak and <=80 mA continuous; no reset or heat.

[ ] Phone A receives intelligible closed-case live audio for 60 minutes and reconnects 20/20; Phone B is rejected.

[ ] Short/medium/long haptic 25 times each with no microphone buzz, RF loss, movement or abnormal temperature.

[ ] Closed-case BLE passes at 5 m and 10 m, including intended body-worn orientation.

[ ] Charge from 20-30% to at least 80% with measured current inside the exact pack limit; no pouch change or abnormal heat.

[ ] Two-hour combined audio/BLE/haptic soak passes; shell/cell rise stays below 10 C over ambient.

[ ] Six-direction 1 m drop, 100 firm shakes, moderate twist and normal USB side-load cause no opening, crack, rattle or reset.

[ ] Reopen after abuse: pouch has no mark, dent, crease, rub or lead strain. Reclose and repeat a 15-minute audio/reconnect/haptic test.

[ ] Exterior is clean and product-like: aligned seam, flush screws, clean USB/mic openings and no warp, stringing, tool marks or raw holes.

RELEASE RULE One failed box means HOLD, repair and full retest. Do not hide a missing function, substitute a part, tighten harder against a fit problem or ship an untested battery unit.

## I. After Unit 001 passes

19. Freeze the exact battery lot, motor bag/identity, driver parts, firmware hash, shell files, band variant, filament/profile and app version.
20. Only then buy the held 11 same-lot batteries. Assemble Units 002-010; keep two labelled unassembled spare kits.
21. Repeat the per-unit identity, fit, current, charge, audio, haptic, RF, thermal, abuse and pouch-inspection record. Any substitution returns one unit through the full Unit 001 gate.

## Builder release record

Field | Record
Unit serial | ____________________________
Builder / date | ____________________________
Battery MPN / lot | ____________________________
Motor / driver identity | ____________________________
Firmware SHA verified | YES / NO
Peak / continuous current | ________ mA / ________ mA
Two-hour soak | PASS / HOLD
Final decision | PASS / HOLD

Release description: functional production-intent investor sample. Not yet certified, waterproof, production-validated or customer-sale-ready.

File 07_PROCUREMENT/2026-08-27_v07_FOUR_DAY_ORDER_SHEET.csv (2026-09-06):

priority | supplier | quantity | manufacturer_part_number | supplier_part_number | description | unit_price_cad_checked | extended_cad_checked | verified_state | source
1 | DigiKey Canada | 2 | 102010469 | 1597-102010469-ND | Seeed XIAO nRF52840 Sense headerless | 25.22 | 50.44 | 1471 stocked; delivery date requires checkout | https://www.digikey.ca/en/products/detail/seeed-technology-co-ltd/102010469/16652896
1 | DigiKey Canada | 2 | 5769 | 1528-5769-ND | Adafruit Audio BFF | 8.85 | 17.70 | 233 stocked; delivery date requires checkout | https://www.digikey.ca/en/products/detail/adafruit-industries-llc/5769/21839817
1 | DigiKey Canada | 2 | VCLP1020B002L | 1670-VCLP1020B002L-ND | Low-current 3V 10x2.1mm ERM motor | 4.69 | 9.38 | 4645 stocked | https://www.digikey.ca/en/products/detail/vybronics-inc/VCLP1020B002L/10285888
1 | DigiKey Canada | 3 | PN2222ATA | PN2222ATACT-ND | NPN motor transistor | 0.51 | 1.53 | 1117 stocked; verify E-B-C drawing | https://www.digikey.ca/en/products/detail/onsemi/PN2222ATA/1047608
1 | DigiKey Canada | 3 | 1N4148 | 1N4148FS-ND | Motor flyback diode | 0.15 | 0.45 | stocked | https://www.digikey.ca/en/products/detail/onsemi/1N4148/458603
1 | DigiKey Canada | 3 | MFR25SFTF52-1K | 13-MFR25SFTF52-1KCT-ND | 1k base resistor | 0.15 | 0.45 | stocked | https://www.digikey.ca/en/products/detail/yageo/MFR25SFTF52-1K/9144386
1 | DigiKey Canada | 3 | CF14JT100K | CF14JT100KCT-ND | 100k base pulldown resistor | 0.16 | 0.48 | stocked | https://www.digikey.ca/en/products/detail/stackpole-electronics-inc/CF14JT100K/1741489
1 | DigiKey Canada | 3 | C322C104K5R5TA | 399-4329-ND | 100nF X7R motor suppression capacitor | 1.73 | 5.19 | stocked | https://www.digikey.ca/en/products/detail/kemet/C322C104K5R5TA/818105
1 | DigiKey Canada | 3 | 6TPE100MAZB | P16256CT-ND | Low-profile 100uF 6.3V polymer bulk capacitor | 2.45 | 7.35 | 7053 stocked; polarized | https://www.digikey.ca/en/products/detail/panasonic-industry/6TPE100MAZB/4146628
1 | DigiKey Canada | 2 | KSC201G-LFS | 108-KSC201GLFSCT-ND | Sealed momentary button | 1.02 | 2.04 | 74459 stocked | https://www.digikey.ca/en/products/detail/c-k/KSC201G-LFS/1003819
1 | DigiKey Canada | 2 | OS102011MA1QN1 | CKN9559-ND | Hard-off slide switch | 1.12 | 2.24 | 78276 stocked | https://www.digikey.ca/en/products/detail/c-k/OS102011MA1QN1/1981430
1 | DigiKey Canada | 1 each | 2001-2006 | 1528-2015-ND through 1528-2020-ND | 30AWG silicone wire six colours | 1.12 | 6.72 | stocked | https://www.digikey.ca/en/products/filter/single-conductor-cables-hook-up-wire/474
1 | DigiKey Canada | 1 ft | B2 1/16 | 2786-B21/16BLACKSPL-ND | Small heat-shrink tubing | 1.59 | 1.59 | stocked | https://www.digikey.ca/
1 | DigiKey Canada | 1 ft | B2 3/16 | 2786-B23/16BLACKSPL-ND | Large heat-shrink tubing | 1.89 | 1.89 | stocked | https://www.digikey.ca/
1 | Canada Computers Vancouver West Broadway | 2 | TUSDH32GCL10U03 |  | TEAMGROUP 32GB microSDHC | 13.99 | 27.98 | 6 shown locally; reserve pickup before travel | https://www.canadacomputers.com/en/microsd-cards/249848/teamgroup-32gb-microsdhc-uhs-i-u1-tusdh32gcl10u03.html
1 | BBM Battery Canada | 2 | 602535 |  | Protected 3.7V 500mAh LiPo 35x25x6mm | 16.95 | 33.90 | exact verified part; checkout controls arrival | https://bbmbattery.ca/products/li-po-602535-battery-3-7v-500mah-lithium-polymer-with-protection
1-ALT | Amazon Canada | 2 | 602535-500mAh |  | Protected 3.7V 500mAh LiPo 35x25x6mm search fallback |  |  | use only if the listing explicitly confirms protection and exact dimensions and checkout shows Day-1 arrival; do not buy both routes | https://www.amazon.ca/s?k=602535+500mAh+protected+lipo+battery
2 | Local hardware | 8 | M2x8 |  | M2x8 button-head screws plus spares |  |  | fit before battery assembly
2 | Local hardware | 1 sheet |  |  | 0.2-0.5mm closed-cell EVA plus PET or Kapton shim sheet |  |  | edge restraint only
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

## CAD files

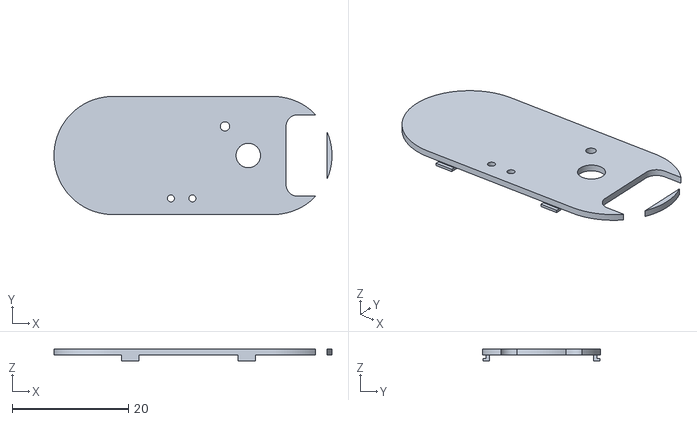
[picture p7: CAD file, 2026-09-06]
02_PROTOTYPE_XIAO/02_CAD_PRINT/PRINT_FULL_SHELL_hooked_face_exact_historical_geometry.stl
47.8 x 20.3 x 2.00

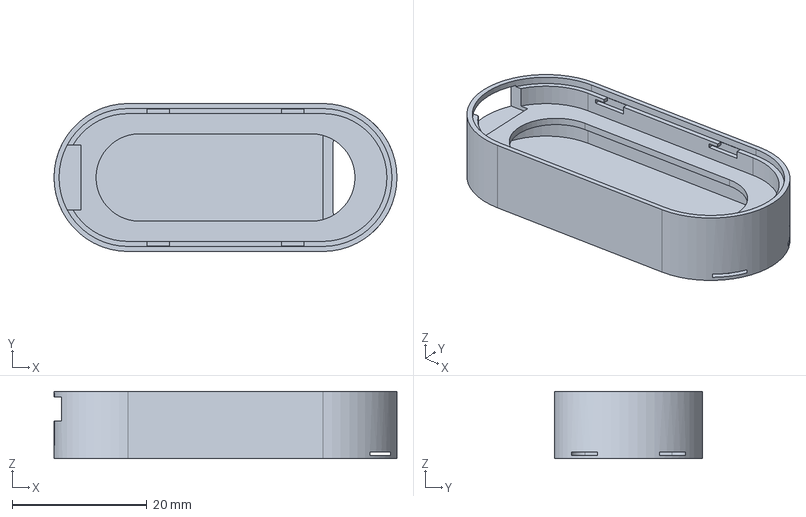
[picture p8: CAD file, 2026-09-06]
02_PROTOTYPE_XIAO/03_CAD_STEP/PRINT_FULL_SHELL_body_exact_historical_geometry.step
51.0 x 22.0 x 10.0 mm

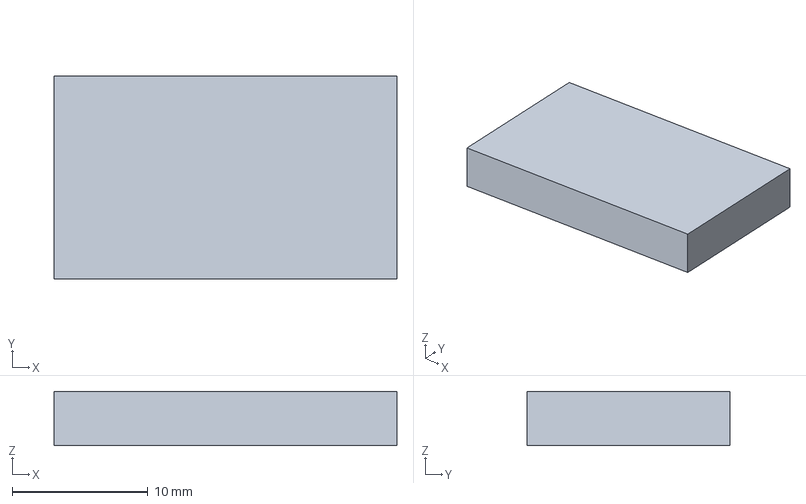
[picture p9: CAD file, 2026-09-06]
08_HISTORICAL_PACKAGES/2026-09-05_master_package/03_XIAO_ALL_CAD/REFERENCE_ONLY_STEP/PLAN_B_MEASURE_MAX_DTP401525_total_25p3x15x4.step
25.3 x 15.0 x 4.00 mm

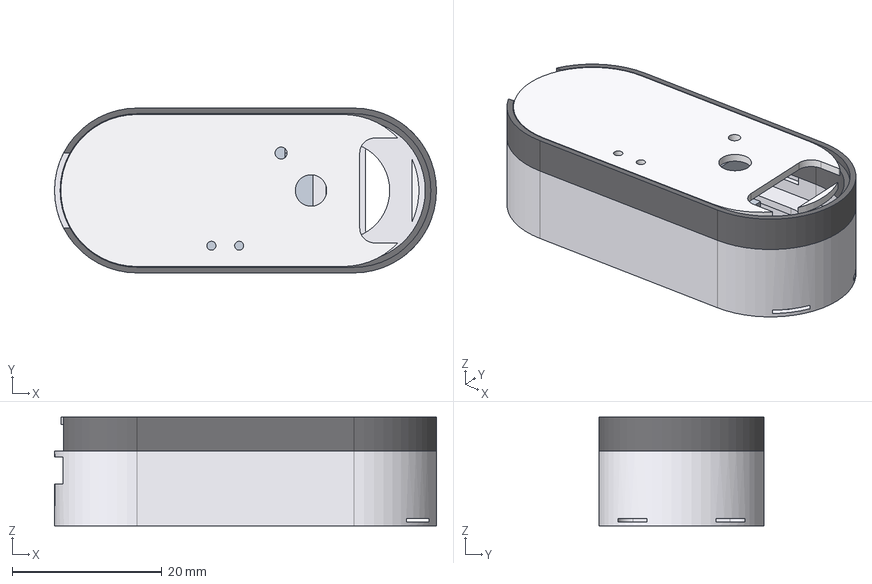
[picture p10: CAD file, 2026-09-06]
08_HISTORICAL_PACKAGES/2026-09-05_master_package/03_XIAO_ALL_CAD/REFERENCE_ONLY_STEP/EXACT_historical_body_face_recovery_assembly.step
51.0 x 22.0 x 14.5 mm
historical_body
printed_midband
historical_face_locked
primary_battery
primary_xiao
primary_barrel_motor
primary_driver
primary_bridge

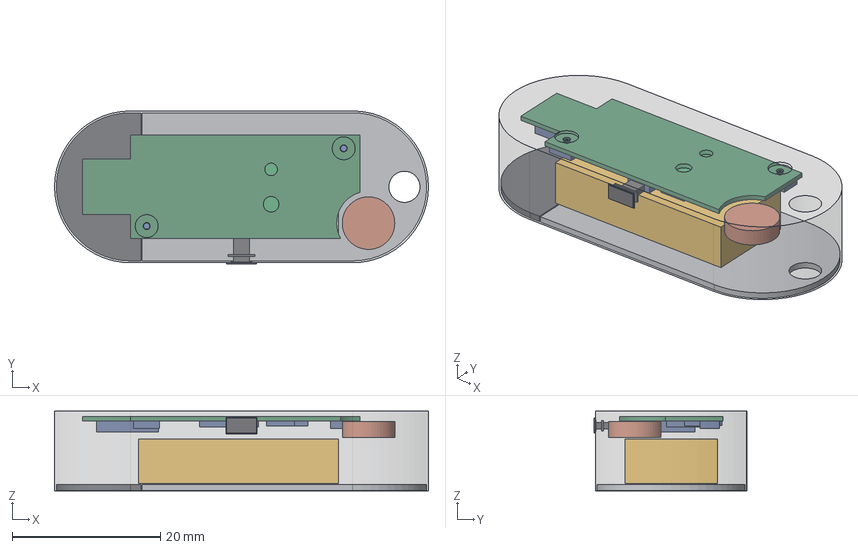
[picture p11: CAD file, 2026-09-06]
04_MECHANICAL/REFERENCE_STEP/production_full_assembly.step
50.5 x 20.7 x 10.8 mm
Makrolon 2407 PC chassis
5052 aluminum cap
polymer RF cap
shaped PCB
finished battery envelope
Raytac AN54LV-15 nRF54L15 module
MK Founder MKDV4GCL-ABF managed SD NAND (481 MB usable)
nPM1300 plus inductors/passives reserve
DRV2605L plus passives reserve
Littelfuse C&K PTS841GMSMTRLFS side-push switch
status LED and resistor reserve
Infineon IM69D128S microphone A
Infineon IM69D128S microphone B
Vybronics VC0720B015F wired coin ERM
captive button plunger
50A LSR button membrane

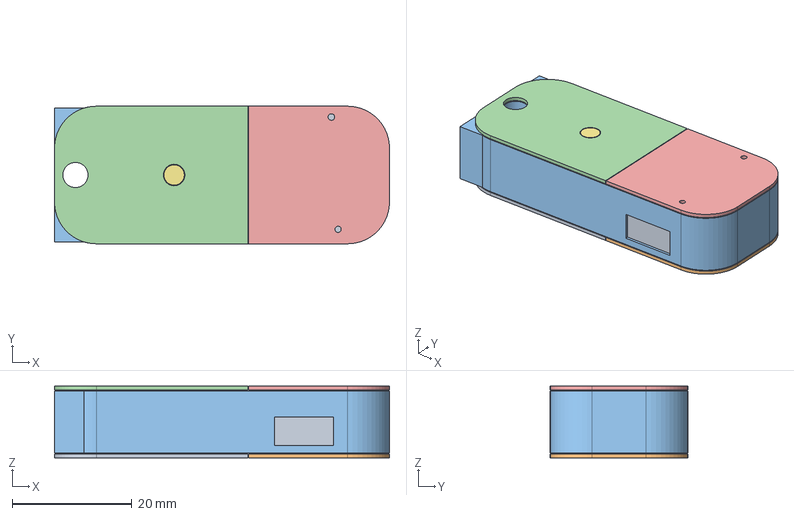
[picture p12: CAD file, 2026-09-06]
08_HISTORICAL_PACKAGES/2026-08-28_tuesday_evt_v0.1/anticipy_strict_evt_nominal_assembly.step
56.0 x 23.0 x 12.0 mm
back_aluminum
back_rf_nose
polymer_frame
front_aluminum
front_rf_nose
battery_bridge
flush_button_plunger_nominal

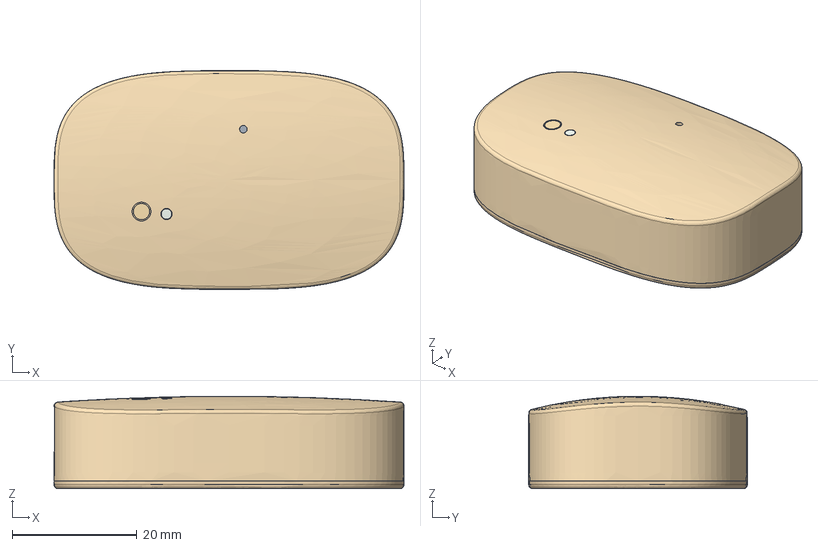
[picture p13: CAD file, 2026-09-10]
latest_builds/E1P1/cad/Oval_E1_Assembly_FIT_CANDIDATE.step
56.0 x 35.0 x 14.8 mm
C1_native_body
C10_native_body
C13_native_body
C14_native_body
C15_native_body
C16_native_body
C17_native_body
C18_native_body
C19_native_body
C2_native_body
C22_native_body
C23_native_body
C25_native_body
C26_native_body
C3_native_body
C4_native_body
C5_native_body
C6_native_body
C7_native_body
C8_native_body
C9_native_body
D1_native_body
D2_native_body
J1_native_body
L1_native_body
L2_native_body
LED1_native_body
MIC1_native_body
Q1_native_body
R1_native_body
R10_native_body
R11_native_body
R12_native_body
R13_native_body
R2_native_body
R3_native_body
R4_native_body
R5_native_body
R6_native_body
R7_native_body
R8_native_body
SW1_native_body
U1_native_body
U2_native_body
U4_native_body
U5_native_body
U6_native_body
PCB_cropped_native_outline
Jauch_LP561836JU_protected_pack_MAX_aftercycling
Existing_10mm_motor_installation_guard
Rear_M2x4_screw_1_PLANNING
Rear_M2x4_screw_2_PLANNING
PCB_capture_pad_31.5_21.1
PCB_capture_pad_48.7_21.1
PCB_capture_pad_34_38.98
PCB_capture_pad_49_38.98
Microphone_gasket
Lightpipe_retaining_adhesive
LED_clear_lightpipe
Recessed_button_plunger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

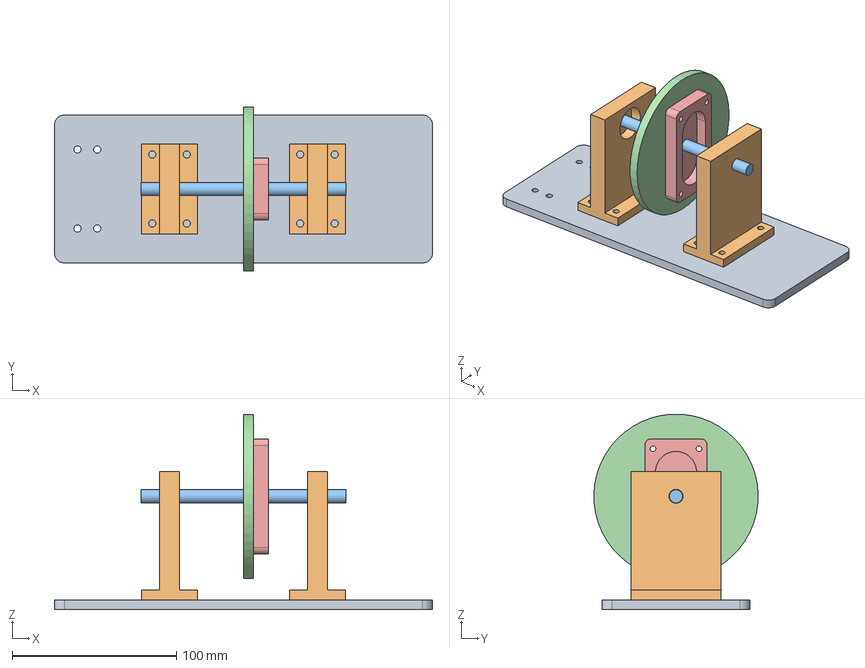
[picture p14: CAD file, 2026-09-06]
08_HISTORICAL_PACKAGES/2026-08-28_execution_v1.0/05_QA_FIXTURES/step/rattle_fixture_face_axis_assembly.step
230.0 x 100.0 x 118.9 mm
base
tower_-45 x 2
purchased_8mm_shaft
rotor
cassette_base

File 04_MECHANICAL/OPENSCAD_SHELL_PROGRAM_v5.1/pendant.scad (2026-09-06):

// =====================================================================
// Anticipy pendant shell  v4 — FLAT TAG
//
// v3 was wrong: board stacked BEHIND battery -> 23.8mm deep on a 26.5mm
// width (T/W = 0.90, a near-square block). v4 lays the board and battery
// END-TO-END in a single layer -> 12.6mm deep (T/W = 0.45). Half as thick.
//
// Also fixed from v3:
//   - front dot CENTERED (v3 welded it to the mic's true x = 5.5mm off
//     centre; unnecessary — there is 2-3mm of air over the board, so a
//     centred port still reaches the mic)
//   - squarer, "bulkier" silhouette: corner radii cut from a full
//     semicircle (R13.25) to R9 top / R7 bottom, edge roll R5 -> R2.6
//   - halves now actually CLICK: tongue-and-groove lip + friction pads
//     (v3 had a flat butt joint and two loose dowels)
//
// Electronics (Seeed STEP/DXF/KiCad + measured):
//   XIAO nRF52840 Sense  PCB 20.955 x 17.78 x 1.24, USB-C 8.94w x 3.21h
//   overhanging the edge 1.53, plug axis 1.60 above PCB top.
//   Headers CLIPPED FLUSH -> 3.4 below PCB.  Board stack = 7.85 thick.
//   BLL 752042 LiPo  20.5 x 43.0 x 8.0 max as-shipped.
//
// Frame: X width, Y height (+Y bail, -Y USB), Z depth, +Z FRONT.
// Parting plane Z=0. Halves print parting-face-down. No supports.
// =====================================================================

VARIANT = 1;       // 1 FIT · 2 ROOMY · 3 NOCUT(uncut pins) · 4 FIT-LOOSE
HALF = "assembly";

// v5 (2026-08-18) — fixes + options over the shipped v4:
//   FIX: battery bay bottom was clipped by the rounded bottom corners
//        (test_batfit left a 20 x 0.9 x 8.2 sliver — battery jammed 0.9mm
//        short of seating). Bottom margin 1.2 -> 2.6.
//   STORAGE=1: +SD_T depth, flat pocket for a microSD socket lying on the
//        battery's front face near its top end, wired to the board. The
//        pocket connects to the battery bay so it closes over the socket.
//   Bail widened 5.6 -> 6.2 (4mm chain / 1.6mm-wire jump ring passes).
//   USB landing relief widened for magnetic USB-C tip base plates.
STORAGE = 0;
SD_W = 19.2;  SD_L = 19.2;  SD_T = 3.6;   // pocket for Adafruit 4682 3V
                                           // microSD breakout (~18x18mm) laid
                                           // flat on the battery, + wire room

// v5.1 (2026-08-19) — additions after the Devin-night P2S print failures:
//   BATTERY=200: smaller-cell preset (502025-class). MEASURE the real cell
//        with calipers and set BAT200_* before printing — the 200 build is
//        ~33.4 x 62.7 x 12.4 and its fit proofs run against these numbers.
//   LIP_CLR_OVERRIDE >= 0 replaces the variant's lip clearance — used with
//        the coupon to regenerate halves at the measured clicking fit.
//   HALF="coupon_front"/"coupon_back" (+COUPON_NOTCH 1/2/3): ~12x22mm slices
//        of the REAL joint at a friction pad. Print coupon_back once plus
//        coupon_front at 0.16/0.22/0.28 (notch count marks which is which),
//        ~10 min total, and learn THIS printer+filament's clicking clearance
//        before committing a 3h plate. That is the fix for the "zero
//        tolerance, doesn't even try to lock" print of 2026-08-18.
BATTERY = 500;
BAT200_W = 20.4; BAT200_L = 25.4; BAT200_T = 5.4;   // 502025 nominal + wrap
LIP_CLR_OVERRIDE = -1;
COUPON_NOTCH = 0;

$fa = 2; $fs = 0.28;
EPS = 0.01;
BIG = 400;

// ------------------------- electronics --------------------------------
BAT_W = (BATTERY == 200) ? BAT200_W : 20.5;
BAT_L = (BATTERY == 200) ? BAT200_L : 43.0;
BAT_T = (BATTERY == 200) ? BAT200_T : 8.0;
BRD_W = 17.78;  BRD_L = 20.955; PCB_T = 1.24;
USB_SHELL_W = 8.94;  USB_SHELL_H = 3.21;
USB_OVERHANG = 1.53;        // receptacle face proud of the PCB edge
USB_AXIS_ABOVE_PCB = 1.60;
BRD_ABOVE_PCB = 3.21 + 0.25;      // USB shell + margin
BRD_UNDER_CLIPPED = 3.4;          // insulator + clipped stubs + solder
BRD_UNDER_PINS    = 9.4;          // untouched header posts
MIC_FROM_ANT_EDGE = 1.52;         // mic aperture, from the antenna end

// ------------------------- variants -----------------------------------
CLR       = (VARIANT == 2) ? 0.85 : 0.5;
DEPTH_PAD = (VARIANT == 2) ? 0.7  : 0.0;
PINS_CLIPPED = (VARIANT != 3);
LIP_CLR   = (LIP_CLR_OVERRIDE >= 0) ? LIP_CLR_OVERRIDE
          : (VARIANT == 4) ? 0.28 : 0.16;   // per side
CUT_PAD   = (VARIANT == 4) ? 0.35 : 0.0;

BRD_UNDER = PINS_CLIPPED ? BRD_UNDER_CLIPPED : BRD_UNDER_PINS;
BRD_T     = PCB_T + BRD_ABOVE_PCB + BRD_UNDER;   // full board stack

// ------------------------- shell numbers -------------------------------
WALL = 2.0;
WALL_MIN = 1.35;              // hard floor, enforced by envelope clipping

SD_PAD  = (STORAGE == 1) ? SD_T : 0;
BAY_T   = max(BRD_T, BAT_T) + 0.5 + DEPTH_PAD + SD_PAD;   // one shared layer
D       = BAY_T + 2*WALL;

// board sits LANDSCAPE (long edge across) at the TOP, battery below it.
// That puts the mic — and therefore the front dot — in the upper third,
// where the real pendant's dot is, and shortens the body by ~4mm.
BAT_BAY_W = BAT_W + 2*CLR;
BAT_BAY_L = BAT_L + 1.4 + CLR;
BRD_BAY_W = BRD_L + 1.0 + 2*CLR;      // board's LONG edge spans X
BRD_BAY_L = BRD_W + 1.4 + CLR;        // board's SHORT edge spans Y

// widen the shoulders so the silhouette is a substantial tag, not a bar.
// Real pendant measures H/W = 2.03; bare bays would give 2.97.
SHOULDER = 6.4;
W = max(BAT_BAY_W, BRD_BAY_W) + 2*WALL + SHOULDER;

BAIL_D    = 6.4 + CUT_PAD;   // 5mm curb chain (diag ~5.4) threads directly
BAIL_TOP  = 3.6;              // material above the bail hole
BAIL_GAP  = 2.1;              // bail hole to battery bay
GAP_BB    = 1.4;              // board bay to battery bay
BOT_MARGIN = 2.6;             // was 1.2 — the v4 batfit failure

H = BAT_BAY_L + GAP_BB + BRD_BAY_L + BAIL_GAP + BAIL_D + BAIL_TOP + BOT_MARGIN;

// squarer than v3's semicircle (was R = W/2). "bulky and square".
R_TOP  = 13.0;
R_BOT  = 11.0;
R_ROLL = 2.6;                 // edge roll; v3 used 5.0 and looked soft

// ------------------------- positions -----------------------------------
// bottom -> top: battery, gap, board (landscape), gap, bail
Y_BOT   = -H/2;
BAT_Y0  = Y_BOT + BOT_MARGIN;
BAT_Y1  = BAT_Y0 + BAT_BAY_L;
BRD_Y0  = BAT_Y1 + GAP_BB;                   // board bay bottom edge
BRD_Y1  = BRD_Y0 + BRD_BAY_L;
BAIL_Y  = BRD_Y1 + BAIL_GAP + BAIL_D/2;
// USB-C exits the RIGHT side (board's long edge runs across the pendant)
USB_SIDE_X = W/2;

// one shared depth layer, everything referenced to the FRONT inner face
Z_FRONT_IN = D/2 - WALL;
BRD_ZTOP   = Z_FRONT_IN - 0.4;               // top of USB shell
BRD_ZPCB   = BRD_ZTOP - BRD_ABOVE_PCB;       // PCB top face
BAT_ZF     = Z_FRONT_IN - 0.4 - SD_PAD;      // battery front face
                                             // (pushed back when STORAGE=1)

USB_HOLE_W = USB_SHELL_W + 0.75 + CUT_PAD;   // spans Y (pendant length)
USB_HOLE_H = USB_SHELL_H + 0.75 + CUT_PAD;   // spans Z (pendant depth)
USB_Z      = BRD_ZPCB + USB_AXIS_ABOVE_PCB;
BRD_CY     = BRD_Y0 + BRD_BAY_L/2;           // board centre line
USB_Y      = BRD_CY;

// Board landscape, USB to the right: the mic maps to x = -8.96, and sits
// 5.52 below the board centre. The dot is CENTRED in x for looks — there
// is an open cavity over the board, so the port still reaches the mic.
DOT_X = 0;
DOT_Y = BRD_CY - 5.52;
DOT_D = 2.0;

// ------------------------- checks --------------------------------------
assert(BAT_Y1 <= BAIL_Y - BAIL_D/2 - 1.0, "battery bay hits the bail");
assert(BAY_T >= BAT_T + 0.4, "bay too shallow for the cell");
assert(BAY_T >= BRD_T + 0.3, "bay too shallow for the board");
echo(str("V",VARIANT,"  W=",W," H=",H," D=",D,
  "  H/W=",round(H/W*100)/100,"  T/W=",round(D/W*100)/100,
  " | board bay ",BRD_BAY_W,"x",BRD_BAY_L," y ",BRD_Y0,"..",BRD_Y1,
  " | batt bay ",BAT_BAY_W,"x",BAT_BAY_L," y ",BAT_Y0,"..",BAT_Y1,
  " | bay depth ",BAY_T," | bail y ",BAIL_Y," d ",BAIL_D,
  " | dot (",DOT_X,",",round(DOT_Y*10)/10,")"));

// ------------------------- body ----------------------------------------
module outline2d(inset) {
    hull() {
        for (s=[-1,1]) {
            translate([s*(W/2 - R_TOP), H/2 - R_TOP]) circle(R_TOP - inset);
            translate([s*(W/2 - R_BOT), -H/2 + R_BOT]) circle(R_BOT - inset);
        }
    }
}
module body(d = 0) {           // exact inward offset by d
    minkowski() {
        translate([0,0,-(D/2 - R_ROLL)])
            linear_extrude(2*(D/2 - R_ROLL)) outline2d(R_ROLL);
        sphere(R_ROLL - d);
    }
}
module rbox(s, r) {
    hull() for (x=[r, s[0]-r], y=[r, s[1]-r], z=[r, s[2]-r])
        translate([x,y,z]) sphere(r);
}
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

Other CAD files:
02_PROTOTYPE_XIAO/03_CAD_STEP/PRINT_FULL_SHELL_hooked_face_exact_historical_geometry.step
08_HISTORICAL_PACKAGES/2026-09-05_master_package/02_XIAO_NO_LEES_REFERENCE/03_CAD_STEP/PRINT_FULL_SHELL_hooked_face_exact_historical_geometry.step
08_HISTORICAL_PACKAGES/2026-09-05_master_package/03_XIAO_ALL_CAD/REFERENCE_ONLY_STEP/PRINT_FULL_SHELL_hooked_face_exact_historical_geometry.step
02_PROTOTYPE_XIAO/CAD/PRINT_THESE/PRINT_FULL_SHELL_body_exact_historical_geometry.stl
02_PROTOTYPE_XIAO/CAD/PRINT_THESE/PLAN_B_MEASURE_MAX_DTP401525_total_25p3x15x4.stl
08_HISTORICAL_PACKAGES/2026-09-05_master_package/02_XIAO_NO_LEES_REFERENCE/02_CAD_PRINT/PRINT_FULL_SHELL_body_exact_historical_geometry.stl
08_HISTORICAL_PACKAGES/2026-09-05_master_package/03_XIAO_ALL_CAD/PRINT_THESE/PLAN_B_MEASURE_MAX_DTP401525_total_25p3x15x4.stl
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

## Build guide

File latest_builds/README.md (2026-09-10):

# Latest Anticipy builds

This folder contains the current **E1P1 custom PCB and matching oval case**, released on 9 September 2026. Start here for the most recent engineering files. The full `E1P1/` handoff is identical to the checked package emailed to Omar; earlier hardware generations remain elsewhere in the repository.

**[Download the complete PCB + CAD + parts handoff](Anticipy_E1P1_Boston_Handoff_2026-09-09.zip)** — download the ZIP using GitHub's Download raw file button, then extract it before opening KiCad. Required libraries and 3D models are included.

| What you need | Current file |
|---|---|
| KiCad project | [Open project](E1P1/pcb/electrical/Anticipy_R1_E1_PROTOTYPE.kicad_pro) |
| Actual routed PCB | [Native PCB](E1P1/pcb/electrical/Anticipy_R1_E1_PROTOTYPE.kicad_pcb) |
| Native schematic | [Schematic](E1P1/pcb/electrical/Anticipy_R1_E1_PROTOTYPE.kicad_sch) |
| Circuit, assembly and copper-layer drawings | [Fabrication and assembly PDF](E1P1/E1P1_Fabrication_and_Assembly.pdf) |
| Gerbers, drills, placements and BOM | [Manufacturing files](E1P1/pcb/manufacturing/) |
| Actual assembled 3D model | [Assembled STEP](E1P1/cad/Oval_E1_Assembly_FIT_CANDIDATE.step) |
| Printable shell, rear cover, button and lightpipe | [CAD files and build instructions](E1P1/cad/Mechanical_Handoff.md) |
| Three opaque print pieces in one file | [Geometry-only 3MF](E1P1/cad/Oval_E1_Three_Print_Parts_GEOMETRY_ONLY.3mf) |
| What to buy and what was already purchased | [Readable checklist](E1P1/procurement/Missing_Parts.md) · [Exact CSV](E1P1/procurement/Missing_Parts.csv) |
| Manufacturers and Boston delivery plan | [Supplier call sheet and logistics](E1P1/logistics/Manufacturing_Saturday_Plan.md) |
| Supplied first-power firmware | [Programming image and instructions](E1P1/programming/) |
| Matching firmware source, board definitions and build recipe | [Bench firmware source](firmware_source/README.md) |
| Verification and remaining work | [Handoff README](E1P1/README.md) · [Release status](E1P1/RELEASE_STATUS.json) |

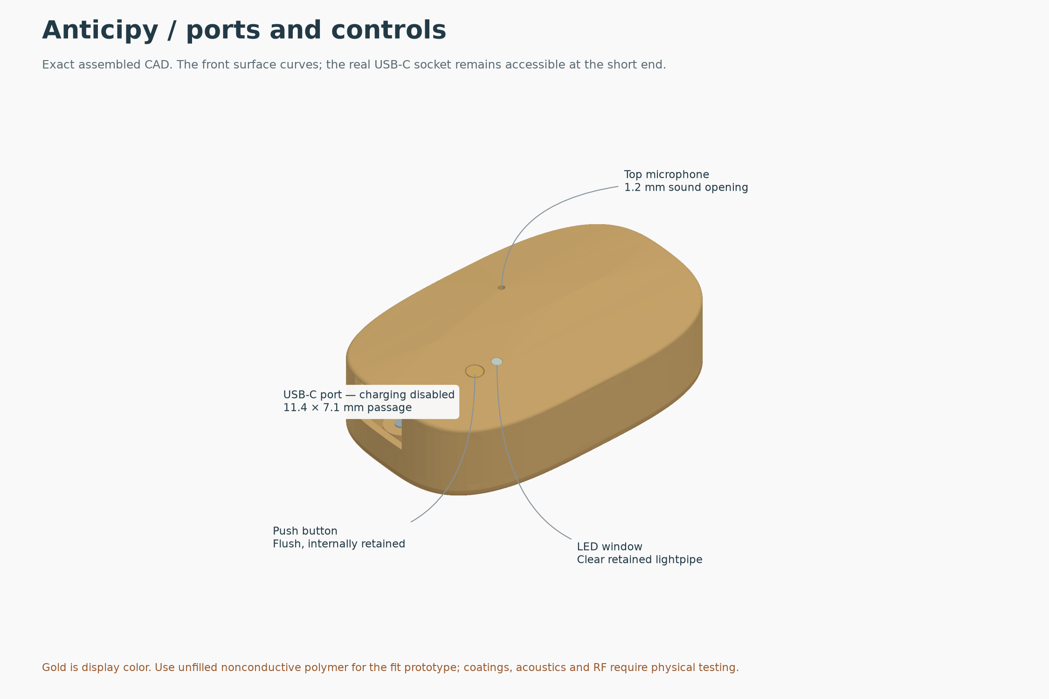
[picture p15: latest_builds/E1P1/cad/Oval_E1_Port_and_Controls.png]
Current E1P1 oval case, USB port and controls


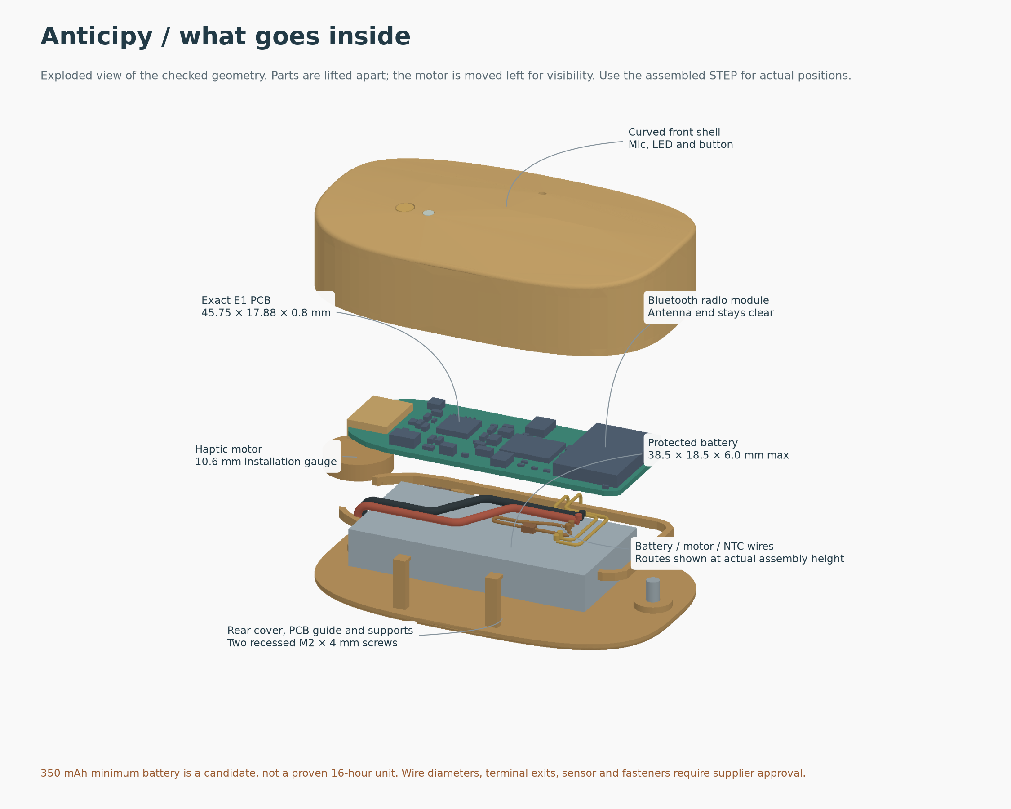
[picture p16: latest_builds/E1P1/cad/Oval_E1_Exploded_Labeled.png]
Exploded view showing the PCB, battery and harness


The PCB is **45.75 × 17.88 × 0.8 mm**. Its matching case is **56 × 35 × 14.8 mm**. This release does **not** meet the requested 30 × 14 × 8 mm product envelope. Gold in the render is display color; the case material must be nonconductive and physically tested.

The saved PCB passed the recorded native DRC/ERC and connectivity checks. The matching CAD passed 2,826 geometry checks. These are engineering checks, not proof of working physical units. **Charging is disabled in the supplied bench firmware; complete offline recording/recovery/backfill and physical wearable qualification remain unfinished.** Supplier stock and the September 12 delivery plan are timestamped research, not current reservations or a guaranteed shipment.

For fabrication use the final BOM and process specification: all 137 vias require epoxy filling, planarization and copper capping. Do not substitute an ordinary tented-via fabrication tier. Use the assembled STEP for coordinates; the exploded STEP is for viewing only.

[Retained component evidence](reference_evidence/) supplies the comparison documents omitted from the email ZIP. Some original receipts retain historical local build paths. The canonical component decisions are [here](E1P1/pcb/verification/Component_Release_Decisions.json); the duplicate under `engineering_decisions/` preserves earlier analysis.

The PCB SHA-256 is `78fe28acde6ceb3ab33aac8af503d4c418540cce31979cc91d3add5e5d0bec36`. The archive SHA-256 is `4698b9c9e017caaaf4426d47813afc3f3b23f76035c57b41cd91886f18ee0e7a`. The [handoff manifest](E1P1/HANDOFF_MANIFEST.json) and [checksums](E1P1/SHA256SUMS) identify the exact release files. Run `shasum -a 256 -c SHA256SUMS` from `E1P1/` after downloading.

The matching firmware source is included separately in `firmware_source/`. Its 253 application files match the recorded source behind the supplied HEX. It is not part of the original handoff ZIP; download that directory or clone the repository to rebuild. The SDK/toolchain are external dependencies. [Full latest-build manifest](LATEST_BUILD_MANIFEST.json).

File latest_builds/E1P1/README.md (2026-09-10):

# Anticipy E1P1 — Boston build handoff, 9 September 2026

Use this package for the current custom E1P1 prototype. It contains the released PCB, matching oval case geometry, exact component checklist, programming image and researched rush-manufacturing plan. It supersedes the older oval review package for this build. Files are prepared; no supplier slot or Saturday delivery is booked.

## Open these first

- **See the product:** `cad/Oval_E1_Port_and_Controls.png` and `cad/Oval_E1_Exploded_Labeled.png`.
- **Open the PCB and schematic:** `pcb/electrical/Anticipy_R1_E1_PROTOTYPE.kicad_pro` in KiCad 10.0.6. The board and schematic are beside it. Keep the local libraries with the project.
- **Read the circuit and fabrication drawings:** `E1P1_Fabrication_and_Assembly.pdf`.
- **See the assembled case:** `cad/Oval_E1_Assembly_FIT_CANDIDATE.step`.
- **Buy only missing parts:** `procurement/Missing_Parts.csv`; its companion notes distinguish purchase/delivery records from physically counted stock. Do not buy the full BOM again without checking owned quantities.
- **Manufacturing and delivery:** `logistics/Manufacturing_Saturday_Plan.md`.

## Dimensions and matching files

The PCB is **45.75 × 17.88 × 0.8 mm**. The oval shell is **56 × 35 × 14.8 mm nominal**. The case contains the selected protected Jauch LP561836JU+PCM+2 WIRES 50MM battery, motor and routed wire allowances. **This design does not meet the requested 30 × 14 × 8 mm product size.**

The native PCB SHA-256 is `78fe28acde6ceb3ab33aac8af503d4c418540cce31979cc91d3add5e5d0bec36`. The case was regenerated against this exact PCB, including the moved USB protection part and selected component body limits. See the CAD contract and verification receipts. No copper was altered while packaging this handoff.

## What to give each shop

**PCB fabrication/assembly shop:** `pcb/manufacturing/` in full, the PDF, `pcb/electrical/` for native review, and the exact missing/consigned-part list. This is four-layer 0.8 mm FR-4/ENIG, with **all 137 vias epoxy-filled, planarized and copper-capped (IPC-4761 Type VII)**, controlled-impedance USB and 47 fitted SMT references per board. The four USB mounting slots remain open. Do not order a generic tented-via tier. Ask for 20 passing assemblies plus appropriate scrap/feeder allowance; two first articles should pass before completing the balance. The quantity file includes two additional-board spares, but this is not a guaranteed yield allowance.

**Case printer:** `cad/Front_Oval_Shell.step`, `Rear_Service_Cover.step`, `Button_Plunger.step` and their STLs. `Oval_E1_Three_Print_Parts_GEOMETRY_ONLY.3mf` holds those three opaque pieces in millimetres; it is not sliced G-code. `Clear_Lightpipe.step` / `.stl` is a fourth, separate optical piece requiring clear material. Read `cad/Mechanical_Handoff.md` for supports, fit, screw pilots, insulation, adhesive and acoustic details. Print unfilled nonconductive polymer; gold in the pictures is display color. Do not print the whole assembled or exploded STEP as one solid.

**Final integrator:** both shop packages, `programming/`, the external wiring/BOM files in `pcb/manufacturing/`, the CAD harness contract and the procurement checklist. Use the specified battery/motor/sensor polarities and inspect/test the open assembly before closure.

## What is verified, and what is still unfinished

The released copper has **0 native DRC violations, 0 unconnected items, 0 schematic parity issues and 0 ERC violations**. Independent saved-copper checks connect all 45 named nets. The CAD has passing geometric checks against the stated component/harness allowances. These are computer checks, not physical tests.

The supplied firmware is for supervised first-power and live-audio bring-up. **Charging is disabled. Complete offline NAND recording/recovery/backfill, qualified charging, signed updates and device ownership remain unfinished.** No assembled E1 unit has demonstrated 16-hour runtime, 24-hour recording retention, charging temperature, radio range, acoustic quality or drop performance. This package is not a qualified customer-wearable release; purchasing parts and assembling boards will not by itself finish that firmware work.

The target is 20 engineering prototypes, at least 15 working, in Boston by Saturday 12 September. The plan needs a manufacturer to accept the complete rush job, usable radio modules at that assembler, physical first-article success, and a booked recipient handoff. BU's normal mailroom can add 24–72 hours after a carrier delivery scan. The logistics file gives current phone numbers and the fastest routes found, without claiming an unaccepted quote or delivery promise.

`PCB_Release_Readme.md` and `RELEASE_STATUS.json` preserve the PCB release scope. `SHA256SUMS` and `HANDOFF_MANIFEST.json` identify the final contents of this combined handoff.

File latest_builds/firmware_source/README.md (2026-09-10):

# E1P1 source for the released first-power image

This is the exact application source behind `Anticipy_E1P1_BUCK2_MAIN_FIRST_POWER.hex`, SHA-256 `32f07cc6a49089f5488ea34ace23362a1aee2d62906eb0dfbf6f122faeda38d7`. All 253 application files match the retained programming manifest. The HEX itself belongs in the adjacent handoff `programming` folder; it is not duplicated here.

**Supervised bench firmware only. Charging is disabled. Offline recording is not implemented. No physical board has been programmed or qualified by this handoff.**

## What is included

- `app/`: byte-preserved application, board definitions, configuration, embedded Opus sources and their notices, and host logic tests.
- `build.sh`: the same build invocation used by the source package.
- `tests/`: native-netlist/device-tree power-contract test and a source/image hash verifier.
- `provenance/`: matching application manifest, original build receipt, later programming receipt, generated configuration/device tree, and the current manufacturing schematic netlist. Generated text here is evidence, not source to edit.
- `Dependencies.json` and `Source_Image_Relationship.json`: environment and source/image linkage.

## Rebuild

Install the complete Nordic nRF Connect SDK **2.7.0** workspace and matching toolchain bundle **f8037e9b83** through Nordic tooling. The original build used Zephyr `v3.6.99-ncs2`, west 1.2.0, CMake 3.21.0 and Python 3.9.6. The [SDK release](https://github.com/nrfconnect/sdk-nrf/tree/v2.7.0) and its [dependency manifest](https://github.com/nrfconnect/sdk-nrf/blob/v2.7.0/west.yml) identify the upstream dependencies. This snapshot does not contain the SDK or compiler.

Run from this folder, setting actual absolute installation paths:

```sh
export ANTICIPY_NCS_ROOT=/absolute/path/to/ncs/v2.7.0
export ANTICIPY_TOOLCHAIN_ROOT=/absolute/path/to/ncs/toolchains/f8037e9b83
export ANTICIPY_E1P1_BUILD_ROOT="$PWD/build"
bash build.sh
```

The application target is `anticipy_e1/nrf52840`. `app/CMakeLists.txt` sets the board root to the application. `build.sh` builds into `$ANTICIPY_E1P1_BUILD_ROOT/target`; the resulting image is `target/zephyr/zephyr.hex` beneath that build root. The default installation paths in the script reflect the original Mac environment. On a different host, use the matching Nordic toolchain environment; its directory layout may require adapting the environment setup, not the application.

The existing target linked **278,692 bytes of flash and 177,244 bytes of RAM**. Those are linker allocations. This export does not rerun the target build or claim a relocated build will be byte-identical. The retained source, original HEX and retained build HEX were independently hashed and agree with the receipts. SDK worktree cleanliness and every SDK dependency commit were not separately audited in this export.

## Verify source and run the included checks

A Python 3 interpreter and a host C compiler (`clang` by default, or set `CC`) are sufficient for these checks:

```sh
python3 tests/verify_source.py
bash app/tests/run_firmware_tests.sh
python3 tests/check_power_contract.py provenance/target.dts provenance/current_native_netlist.xml
```

To verify a copied released HEX as well:

```sh
python3 tests/verify_source.py --hex ../E1P1/programming/Anticipy_E1P1_BUCK2_MAIN_FIRST_POWER.hex
```

After an actual rebuild, rerun the power-contract checker using the newly generated `build/target/zephyr/zephyr.dts` in place of the retained device tree. The 23 power checks establish revision pairing; host logic tests establish bounded transport/recovery behavior. Neither proves physical power rails, microphone audio, Bluetooth reliability or runtime. The broader phone/codec tests cited by the original build receipt are prior results; they require the separate product/iOS source and are not represented as self-contained tests in this snapshot.

## Correct board and current limits

Use only the E1P1 **BUCK2-main** circuit. BUCK2 supplies the 3.0 V main rail; BUCK1 is the unloaded 2.5 V auxiliary rail and is turned off after initialization. The older E1 BUCK1-main image is incompatible. The current manufacturing PCB SHA is `78fe28acde6ceb3ab33aac8af503d4c418540cce31979cc91d3add5e5d0bec36`. Its updated netlist passes the same power contract; the original build receipt still names the earlier oval PCB geometry and is retained unchanged as historical build evidence.

This image implements PDM microphone capture, 16 kHz mono / 32 kbit/s Opus, encrypted BLE subscription gating, bounded queues, recording LED, power/temperature diagnostics, watchdog and a **non-destructive NAND ID probe**. It does not write or erase NAND. Disconnected audio retention is not implemented. Haptic behavior, USB data, signed updates and complete customer ownership are also not implemented. There is no bootloader or USB DFU.

The unchanged `app/README.rst` contains a superseded 200 mAh battery candidate note. For the current handoff, use the hardware BOM's exact protected Jauch 246501 pack (350 mAh minimum), separate temperature sensor and current assembly instructions. Neither that older note nor the inactive charger configuration authorizes charging. Battery calibration, charging faults/temperature, storage recovery, offline backfill, RF/acoustics, phone-device integration and 16-hour runtime require engineering work and physical validation.

Follow [the matching programming instructions](../E1P1/programming/Programming_Readme.md) for supervised first power and SWD programming. Begin with the battery disconnected and a reviewed current-limited supply. No programming operation is performed by any command in this source-export README.

## Source notices

Original file headers and `app/OPUS-1.2.1-LICENSE.txt` are preserved. No new blanket license is granted by this export. CMakeLists.txt is authoritative for compiled files; retained legacy helpers and unused codec files are source ancestry, not enabled features.

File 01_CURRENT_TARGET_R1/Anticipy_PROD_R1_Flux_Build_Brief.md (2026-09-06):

# Anticipy Production PCB R1

Status: engineering brief frozen for first Flux schematic pass  
Date: 2026-08-29  
Release ID: `ANT-PROD-R1`

## 1. Product goal

Build the first manufacturable custom PCB for the Anticipy wearable audio pendant. It must record ambient audio, store it when the phone is absent, synchronize it to an iPhone over Bluetooth Low Energy, charge over USB-C, give haptic feedback, and fit the frozen Anticipy enclosure.

This PCB is for the 25-unit pilot and later 100-unit production batch. The 10 Founder units continue on the XIAO nRF52840 Sense architecture so this work does not delay the seven-day Founder build.

## 2. Frozen mechanical envelope

| Item | Requirement |
| --- | --- |
| Finished enclosure | 56.0 × 23.0 × 12.0 mm |
| PCB target | 49.0 × 20.0 × 0.8 mm |
| PCB shape | Rounded capsule, exact outline to follow enclosure master |
| Layers | 4-layer FR-4 |
| Finish | ENIG |
| Battery pocket | Maximum 30 × 20 × 4.5 mm |
| Production battery | 1-cell protected LiPo, target 250 to 300 mAh, 10 kΩ NTC lead |
| Antenna region | Last 12 mm of enclosure must be polycarbonate with no aluminum over antenna |
| Component strategy | Mostly top-side assembly, battery below or behind PCB center |
| Acoustic openings | Two bottom-port microphone holes aligned to shell mesh and gaskets |

The earlier 21 × 18 mm PCB concept is rejected. It cannot carry the complete production system without risky board stacking.

## 3. Required user functions

- Automatic ambient audio capture. The main product behavior must not require pressing a button.
- 16 kHz, 16-bit mono audio as the first firmware target.
- Two microphones for later noise reduction and directionality. R1 firmware may start with one channel while retaining both footprints.
- Bluetooth Low Energy connection to iPhone.
- Live transfer when the phone is present.
- Offline recording and later backfill when the phone returns.
- At least 20 hours of offline audio capacity.
- USB-C charging, wired diagnostics, and firmware recovery.
- Battery state of charge and battery-health reporting.
- Haptic confirmation for power, pairing, and error states.
- One small button for pairing, reset, recovery, and diagnostics only.
- Motion sensing to distinguish worn, moving, and stationary states.
- Secure boot and signed device firmware update.
- Encrypted stored audio or per-device encryption keys before customer release.
- No camera.

## 4. Selected architecture

| Block | Preferred production part | Reason |
| --- | --- | --- |
| MCU and Bluetooth | Raytac `MDBT50Q-1MV2` | nRF52840, integrated antenna, USB, PDM, QSPI/SPI, pre-certified module, same MCU family as Founder unit |
| Power and charging | Nordic `NPM1300-QEAA-R` | USB-C-aware charger, power path, NTC, fuel gauge, ship mode, two buck rails and two LDO/load-switch rails |
| Microphones | 2 × Infineon `IM69D128SV01XTMA1` | Active 3 V-compatible PDM microphones, 69 dB SNR, avoids 1.8 V level translation |
| Storage | Low-profile push-push or push-pull microSD socket plus installed 8 or 16 GB industrial card | Reuses Founder storage firmware and easily exceeds 20-hour storage target |
| Motion | ST `LIS2DW12TR` | Low-power 3-axis accelerometer with activity and inactivity interrupts |
| USB-C | GCT `USB4105-GF-A` or footprint-compatible active equivalent | Compact USB 2.0 Type-C receptacle |
| USB ESD | TI `TPD2EUSB30DRTR` or approved equivalent | Low-capacitance protection for USB D+ and D- |
| Haptic | Off-board 3 V ERM coin motor | Mechanically isolated from microphones; driven by MOSFET and flyback diode |
| User input | Omron `B3U-1000P` or approved sealed equivalent | Small momentary button |
| Status | One low-current RGB or two-color LED | Charging, pairing, and fault indication through a light pipe |

### Rejected microphone for R1

The TDK T5838 has useful acoustic activity detection, but it operates at 1.65 to 1.98 V. Using it with a 3.0 V nRF and microSD system adds voltage translation and another failure mode. R1 uses dual IM69D128S microphones and software voice or acoustic activity detection. T5838 can be reconsidered for R2 after the core product works.

## 5. Power tree

```text
USB-C VBUS -> nPM1300 -> protected 1-cell LiPo with NTC
                      -> BUCK1 3.0 V: Raytac nRF52840 and digital logic
                      -> BUCK2 3.0 V: microSD and local bulk capacitance
                      -> LDO/LOAD1 3.0 V: microphones
                      -> LOAD2: haptic rail if current and noise tests pass
```

- Charge current must initially be limited to a battery-vendor-approved value. For a 250 to 300 mAh cell, begin at 100 mA unless its datasheet explicitly permits more.
- Use 47 to 100 µF local bulk capacitance at the microSD rail plus 100 nF high-frequency decoupling.
- Power-gate the microSD and microphones when safe.
- Measure real average current before claiming 16-hour runtime. A 200 mAh cell requires less than 12.5 mA average for 16 hours before conversion and aging margin.

## 6. Electrical interfaces

| Interface | Connection |
| --- | --- |
| PDM | nRF52840 PDM clock/data to both microphones with left/right selection configured per microphone datasheet |
| microSD | Dedicated SPI bus for R1, with CS pull-up and optional 22 to 33 Ω source resistors on fast lines |
| PMIC | I2C plus interrupt and ship-mode control |
| Accelerometer | Shared I2C bus plus dedicated motion interrupt |
| USB | nRF52840 native USB D+ and D-, series and ESD parts per Raytac/Nordic reference design |
| Haptic | GPIO to small N-MOSFET, gate resistor, pulldown, flyback diode, and motor noise capacitor |
| Button | GPIO with hardware pull and firmware debounce |
| Debug | SWDIO, SWDCLK, RESET, VREF, GND and optional UART TX/RX on pogo pads |

Flux must choose a conflict-free nRF52840 pin map only after checking the Raytac module pinout and Nordic peripheral restrictions. The final pin map becomes the authoritative firmware header.

## 7. PCB placement zones

1. Antenna end: Raytac module at board edge, exact copper and component keepout from Raytac design guide, no battery or aluminum above or below the antenna zone.
2. Audio center: two microphones spaced as far apart as practical, each directly above its acoustic PCB hole. Keep switching nodes, USB, microSD clock, haptic traces, and board edges away from microphone ports.
3. Storage center: microSD socket accessible during assembly but not customer-accessible after sealing.
4. Power and USB end: nPM1300, inductors, USB-C, protection, button, LED, and battery pads.
5. Test edge: gold pogo pads accessible before enclosure closure.

Use Layer 2 as an unbroken ground plane except where the antenna design guide requires a keepout. Use Layer 3 for power and slow signals. Do not route switching nodes beneath microphones or the antenna.

## 8. Manufacturing requirements

- Conservative starting rules: 5/5 mil trace and space, 0.20 mm finished vias, 0.45 mm pads, subject to the selected factory.
- 1 oz outer copper and 0.5 or 1 oz inner copper.
- Panel fiducials and at least three board fiducials if factory requests them.
- Clear pin-1 marks, polarity marks, microphone-port keepouts, test-pad labels, and antenna keepout notes.
- Exact manufacturer part numbers for every fitted item and named alternates for supply-risk parts.
- DNP options for second microphone, LED, and development pull resistors where useful.
- PCBA STEP model must be checked against the enclosure and battery before ordering.

## 9. Flux work sequence

Flux should receive one objective per message. Do not ask it to make the schematic, place the board, route it, and export manufacturing files in one request.

1. Read the blank/current project and record these requirements.
2. Build and review the block diagram and exact BOM.
3. Create and review the nPM1300 power and charging schematic.
4. Add Raytac MCU, USB, clocks, SWD, reset, and pin mapping.
5. Add PDM microphones, microSD, LIS2DW12, haptic, button, LED, and test points.
6. Run an official-datasheet and electrical-rule audit.
7. Import or draw the final mechanical board outline.
8. Place components and return placement screenshots or coordinates for review.
9. Route by subsystem, beginning with RF/USB/power, then audio and storage.
10. Clear DRC and unresolved-airwire errors.
11. Export Gerbers, drills, BOM, pick-and-place, schematic PDF, assembly drawings, STEP model, and pin map.

## 10. First Flux message

Paste this into the currently open blank Flux project, or send it through Flux MCP:

> Rename this blank project `Anticipy Production PCB R1`. Do not add, remove, place, or route components yet. Record the requirements in this brief as the project design requirements. Return only: (1) a system block diagram, (2) an interface and power-rail table, (3) a proposed exact BOM with active manufacturer part numbers, and (4) unresolved engineering questions or conflicts. Verify every proposed IC against an official current datasheet. Treat 49.0 × 20.0 × 0.8 mm as the preliminary PCB envelope, 56.0 × 23.0 × 12.0 mm as the finished enclosure, and reserve one board end for the Raytac antenna keepout. Do not invent pin assignments yet.

Attach this complete brief to the Flux project knowledge or paste its sections after the first message.

## 11. Release gates

The design is not ready to manufacture until all of these are true:

- One complete schematic review against official datasheets.
- Power-tree and charger calculations reviewed for the exact battery.
- All parts active, stocked, and sourceable for at least 125 units or replaced with approved alternates.
- DRC has zero unresolved errors and zero unrouted nets.
- Antenna keepout matches the Raytac integration guide.
- Microphone ports align with the enclosure and have no copper obstruction.
- PCBA STEP, battery, haptic motor, and enclosure pass a mechanical interference check.
- Gerbers are independently viewed and checked.
- Five assembled boards pass power, charging, USB, SWD, microphone, storage, BLE, haptic, motion, and 16-hour runtime tests before the 25-unit build is released.

## 12. Required production outputs

- Flux project and frozen revision identifier
- Schematic PDF
- Gerber and NC drill ZIP
- BOM with exact MPNs and alternates
- Pick-and-place CSV
- PCB fabrication notes and stack-up
- Assembly drawing
- PCBA STEP
- Authoritative firmware pin-map file
- Factory-test firmware and production firmware
- Pogo-jig test-point drawing
- Test procedure and acceptance limits

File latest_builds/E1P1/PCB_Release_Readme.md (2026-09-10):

# E1P1 PCB manufacturing release - 9 September 2026

**This is the corrected E1P1 data release for prototype PCB fabrication and assembly.** Use this package as a unit; it supersedes the earlier oval E1 PCB files. It does not qualify a finished wearable or promise a delivery date.

Open `pcb/electrical/Anticipy_R1_E1_PROTOTYPE.kicad_pro` in KiCad 10.0.6. The matching PCB and schematic are beside it, with the required local libraries. The released PCB SHA-256 is `78fe28acde6ceb3ab33aac8af503d4c418540cce31979cc91d3add5e5d0bec36`.

## What is finished in this release

- U4 USB protection moved from (28.50,30.00) to (28.15,29.45) mm. Its three local front-copper branches were repaired; the main USB pair, all vias, board outline and antenna keepouts are preserved. The U4/C1 negative courtyard exception was removed.
- U2 signal-pad mask expansion is now 0.050 mm, providing 0.100 mm nominal mask dams. U4 mask expansion is now 0.050 mm to match TI's land-pattern guidance. Matching footprint libraries were updated.
- All 137 vias are specified epoxy-filled and copper-capped, IPC-4761 Type VII. This is required because 14 via bores intersect fitted solder copper/paste and 15 intersect mask openings. The four USB connector mounting slots stay open.
- Exact component selections are closed: U4 TPD2EUSB30ADRTR; C13 C0603X5R1E104K030BB; C17/C19/C22 C1005X7R1C104K050BC; C23 GRM21BR60J476ME01L. C20's metadata is updated but remains DNP. Three documented tape/reel aliases were also incorporated.
- The selected external battery is now named consistently: Jauch LP561836JU+PCM+2 WIRES 50MM, 350 mAh minimum. Charging remains disabled in the bench firmware.
- Fresh Gerbers, drills, IPC-D-356 netlist, placement coordinates, exact SMT BOM, fitted-only paste, native schematic and PCB STEP are included.

## Verification

Native KiCad: **0 DRC violations, 0 unconnected items, 0 schematic parity issues, 0 ERC violations**. No ignored DRC/ERC categories and no individual DRC/ERC exclusions. The documented Nordic reference-cell courtyard rules remain; maximum-body checks and placement assumptions are recorded, rather than pretending these rules are absent.

Independent saved-copper connectivity: **45 of 45 named nets PASS**. Population: **47 machine-fitted references**, 44 top and 3 bottom; BOM, placement and paste contain the same exact set. There are 69 native references, including test pads, net ties, external wiring pads and DNP parts. Independent metadata audit: 2,643 checks pass. The case delta audit passes 145 checks for the moved/reselected parts with maximum-body and assembly allowances.

The board is **45.75 x 17.88 x 0.8 mm**, four layers. It does **not** fit the requested 30 x 14 x 8 mm overall product envelope. Its tested mechanical relationship is to the existing 56 x 35 x 14.8 mm oval case study, not to a newly miniaturized case. No claim of an absolute smallest possible PCB is made.

## Give the manufacturer

1. `E1P1_Fabrication_and_Assembly.pdf` plus `pcb/manufacturing/` in full: fabrication specification, Gerbers, plated drill file, zero-hole NPTH file, IPC netlist, fitted BOM, DNP list, placement CSV, via-filling coordinates, external assembly BOM and STEP. The single PDF contains the schematic, both assembly views, all copper layers, full fitted-placement index and plated drill map.
2. `pcb/electrical/` for native source review and local libraries. Gerbers and drill files control fabrication; the STEP includes nominal component envelopes and is not an electrical manufacturing master.
3. Read `pcb/manufacturing/Fabrication_and_Assembly_Specification.md` before quoting. This design requires filled/capped vias, 0201 assembly and controlled-impedance processing; a generic cheap four-layer order with ordinary tented vias is not equivalent.

The manufacturer must return an actual stackup/CAM plan meeting the written dimensions and 90-ohm coupon acceptance. That is a normal fabrication process check, not an unresolved component selection. Do not silently substitute parts, remove antenna keepouts, move copper, or omit via fill/cap to reduce cost.

## Parts and physical completion

The complete exact SMT list contains 27 MPN groups and 940 fitted pieces for 20 boards. Current supplier observations cover 26 groups in sufficient quantity, including two-board spares. **U1 radio modules are the supply exception:** current marketplace stock is only 14 with about 14-day dispatch. Carrier records show 25 ordered modules delivered in British Columbia, but the usable count and arrival at an assembler are unverified. Count and consign those modules or allocate another exact-MPN source before promising 20 assembled boards. See `sourcing/` for timestamped links; no stock is reserved and no order has been placed.

Release the first articles for electrical bring-up before customer use. Physical power, USB signal quality, RF, acoustic, motor-current and charging tests have not been run. The existing bench firmware supports supervised bring-up/live audio; complete offline NAND recording/recovery/backfill, qualified charging, signed updates and device ownership remain separate unfinished product work. The supplied PCB files do not establish 16-hour runtime, 24-hour retention, or failure-free customer operation.

Earlier packages were not changed. No supplier files were uploaded, no supplier message was sent, and no purchase was placed in this pass.

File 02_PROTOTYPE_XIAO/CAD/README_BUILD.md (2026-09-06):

# Anticipy ordered-shell recovery v0.2

## Use this version

The first 4.00 mm recovery was withdrawn after an independent audit found
collisions with the historical body's internal shelf and the face hooks.
Version 0.2 fixes those problems and uses a **4.50 mm-rise mid-band**.

The corrected generator imports the packaged exact historical body and face
STEP solids. Its final report records **1,424** boolean intersection values
with a 0.0 mm3 maximum for:

- nominal and loose mid-bands against the body;
- the four-hook vertical drop at 13 positions and lock slide at 21 positions,
  against both bands and every modeled component/layout;
- XIAO, battery, motor, 8 x 4 x 2 mm driver, and safety bridge against body, band, face,
  and one another;
- 12, 15, 24, and 25 mm battery layouts with the sealed coin motor;
- a conditional DTP401525-class 25.3 x 15 x 4.0 mm layout with the driver
  rotated into the battery/motor gap;
- the full 11.29 x 4.03 mm swept barrel-motor measurement reference; it is not
  a Unit 001 fallback because no qualified rotor guard is included.
- the separate Renata-only M2 screw-retained band, keyed posts, full-height
  drill axes, and conservative countersink envelopes against the ordered body,
  face, components, and both antenna-window regions.

The screw-retention audit also requires a positive collision with Plan B's
rotated driver. That deliberate rejection prevents the two layouts from being
mixed.

This is a CAD result against the repository's historical reference solids.
The physical printed or ordered shell still must pass its gauges and no-load
closure.

## Finished size

- Original historical body and recessed face: 51 x 22 x 10 mm.
- Recovered nominal outside size: **51 x 22 x 14.5 mm**.
- Main internal height: 12.5 mm.
- Maximum controlled battery-body envelope: **25 x 10 x 5.5 mm finished**,
  including PCM, wrap, seams, and folded tabs. Leads/interconnect are routed
  and dry-fit separately.
- Conditional named DTP401525 layout: **25.3 x 15 x 4.0 mm maximum** including
  the drawing's L2 dimension. It has only 0.15 mm nominal clearance below the
  historical shelf and is not a generic wide-cell authorization.
- XIAO official STEP envelope: 22.482 x 17.780 x 4.460 mm.
- Ordered Vybronics VCLP1020B002L motor tolerance envelope:
  **10.2 mm diameter x 2.3 mm**.
- Renata-only screw architecture motor mechanical envelope:
  **10.2 mm diameter x 2.7 mm**. This includes the listed Lee PID10431 body,
  but does not qualify its electrical identity, current or duty.

The band adds only a narrow perimeter seam. The historical body and face remain
the large visible surfaces whether they arrive as ordered nylon or are printed
from the supplied exact-reference STL files.

## Print now

Print these in black PETG or PETG-HF:

1. If no shell is physically present, print **two** of
   `out/PRINT_FULL_SHELL_body_exact_historical_geometry.stl` and **two** of
   `out/PRINT_FULL_SHELL_hooked_face_exact_historical_geometry.stl`. The first
   pair is sacrificial for drilling, hook fit, sanding and abuse tests.
2. `out/PRIMARY_RENATA_ONLY_M2_screw_retained_midband_rise_4p50mm_nominal.stl`
   and its loose-tongue alternative.
3. `out/PRINT_TWO_PRIMARY_RENATA_ONLY_M2_keyed_retainer_posts_HEAD_DOWN.stl`
4. `out/PRIMARY_RENATA_ONLY_M2_body_drill_marking_jig_USB_NOTCH.stl`
5. `out/PRINT_DECK_DOWN_then_FLIP_battery_safety_bridge.stl`
6. `out/mic_drill_jig_usb_end_notched.stl`
7. `out/BENCH_ONLY_xiao_plan_fit_gauge.stl`
8. the lower layout gauge matching the battery and motor selected at the
   counter;
9. the individual maximum-envelope battery, XIAO, and motor gauges.
10. `out/MEASURE_MAX_finished_driver_island_8x4x2.stl`.

For the conditional PRT-13853/DTP401525 geometry, print both
`PLAN_B_MEASURE_MAX_DTP401525_total_25p3x15x4.stl` and
`PLAN_B_BENCH_ONLY_lower_fit_gauge_DTP401525_Vybronics_driver_rotated.stl`.
The existing mid-band and bridge do not change. The Lee PID8834 listing is not
proof that it is a DTP401525 and must not be put in this wider layout unless
its exact received identity and complete dimensions independently match.

### Bambu P1S settings

- 0.4 mm nozzle.
- 0.12 mm layers for bands and microphone jig.
- 0.16 mm layers for bridge and gauges.
- Five wall loops, six top/bottom layers, 40% gyroid.
- Arachne walls and thin-wall detection on; supports off.
- Add a 3 mm brim to each band; seam at the USB end.
- Put the band's locating tongue on the plate.
- Put the safety bridge's broad deck on the plate, then flip it for assembly.
- Print the full body as modeled with its flat exterior back on the plate and
  the cavity open upward. Print the hooked face as modeled with its broad
  exterior face on the plate and hooks upward. In slicer preview, add painted
  support only under true horizontal ledges; keep supports out of hook, slide,
  USB, microphone and screw interfaces.

Let the parts cool on the plate. Use the nominal band only if it seats fully
with fingertip pressure; otherwise try the loose tongue. Never force either
into the shell.

## No-adhesive Renata-only closure

For a mechanically retained Unit 001 using only Renata ICP501022UPM / part
100640 and a gauged motor within the 10.2 x 10.2 x 2.7 mm envelope, follow
`PRIMARY_RENATA_ONLY_SCREW_RETENTION.md`. Print the named screw band, the
two-post head-down file, the USB-notched body marking jig, and the dedicated
maximum motor gauge. This is a
separate architecture: do not print or install either adhesive-only band and
do not use the conditional wide-cell Plan B or barrel-motor layout.

The target fastener is two M2 x 10 mm flat countersunk screws. Lee's Electronic
PID6836 is the local candidate; its online finish is unspecified. The jig only
transfers the two centres. The empty body gets 2.2 mm preferred
clearance holes; an ordinary 3/32 inch (2.381 mm) bit is allowed because the
audit passes through 2.4 mm. The printed posts contain 1.6 mm blind pilots;
countersink only until each actual 90 degree flat head is flush.

## Battery/motor layouts

| Battery envelope | Preferred motor position | Notes |
|---|---|---|
| 12 x 10 x 5.5 mm max | Vybronics 10.2 x 2.3 mm max at USB-side end | Best RF clearance, least runtime |
| 15 x 10 x 5.5 mm max | Vybronics 10.2 x 2.3 mm max at USB-side end | Some antenna overlap; test |
| 24 x 10 x 5.5 mm max | Vybronics 10.2 x 2.3 mm max at antenna-side end | Fits documented Renata ICP501022UPM envelope; battery lies under antenna, so RF test is mandatory |
| 25 x 10 x 5.5 mm max | Vybronics 10.2 x 2.3 mm max at antenna-side end | Primary universal maximum gauge; RF test mandatory |
| DTP401525 25.3 x 15 x 4.0 mm max | Vybronics at antenna end; driver rotated 4 x 8 x 2 mm between them | Conditional Plan B only; 0.15 mm shelf gap, 0.40 mm hard-part gaps and full antenna overlap; exact gauge/no-load/RF tests mandatory |

The bridge pads sit on the historical internal shelf rather than passing
through it. Its deck clears a true 5.5 mm pack on 0.05 mm floor insulation by
0.40 mm. Reusing it with the 4.0 mm Plan B cell leaves 1.90 mm below the deck;
no new bridge is required in CAD. The PCB cannot load the pouch.

The finished insulated SMD motor-driver envelope is 8 x 4 x 2 mm. It has only
0.2 mm nominal wall margin, so its individual gauge and physical no-load close
are hard gates. Axial diodes and through-hole resistors do not fit.

## Physical release measurements

Record caliper photographs before soldering:

| Item | Required result |
|---|---:|
| Actual cavity length | at least 47.8 mm |
| Width at all XIAO corners | at least 18.2 mm |
| Floor-to-face height at centre and both ends | record actual |
| Finished battery | passes selected gauge without friction |
| Ordered Vybronics motor | no more than 10.2 mm diameter x 2.3 mm finished |
| Lee PID10431 fallback | passes screw-layout CAD only if the finished body passes the dedicated 10.2 x 2.7 mm max gauge; electrical/thermal/RF qualification remains mandatory |
| Driver island | fully insulated assembly passes 8 x 4 x 2 mm gauge |
| Barrel reference | may be measured, but no qualified guard exists; not for Unit 001 |
| XIAO with solder/wires | passes supplied XIAO gauge |
| Face hook slide | drops and slides without component or band load |

The battery must also have an exact manufacturer/MPN, integrated protection,
permission for at least 50 mA CC/CV charging to 4.20 V, verified polarity, and
a matching UN38.3 test summary. A seller's dimensions alone are not approval.
SparkFun PRT-13853/DTP401525 provides a documented geometric/electrical
reference, but this packet does not contain a matching UN38.3 summary for the
received lot. Lee PID8834 lacks proof that it is the same product.

## Assembly essentials

1. Flash/test the XIAO on USB with the battery disconnected.
2. Dry-fit the empty body, chosen band, and face. If using the separate
   Renata-only screw closure, complete its empty-body drill coupon and post
   retention gates before electronics enter the shell.
3. Add 0.05 mm electrical floor insulation.
4. Install the qualified battery without broad-face pressure and leave a
   relaxed lead loop.
5. Bond a gauged coin motor inside the audited 10.2 x 10.2 x 2.7 mm envelope
   to rigid structure. Do not use the exposed-rotor barrel reference in Unit
   001.
6. Build one labelled, matched SMD-only driver. For ordered DigiKey parts use
   the documented AO3400A low-side circuit and active-high firmware. For local
   Lee PID10431/NTR4101P/BAS16/10 kohm parts use the documented P-channel
   high-side circuit and active-low firmware. Gauge the fully insulated
   8 x 4 x 2 mm island; never power a motor from GPIO and never mix the two
   circuit/firmware pairs.
7. Put the bridge pads on the shelf and the XIAO on no more than 0.10 mm
   insulated adhesive outside the antenna zone.
8. Transfer the real USB and microphone positions; deburr and gasket.
9. Close first with witness film and fingertip pressure only.
10. Run the full electrical, thermal, RF, audio, drop, rattle, privacy, and
    cosmetic release record before bonding/packing.

## Files and regeneration

- `out/FIT_REPORT.json` contains exact arithmetic and boolean audit values.
- `out/EXACT_historical_body_face_recovery_assembly.step` is the complete
  reference assembly.
- `out/PRIMARY_RENATA_ONLY_M2_screw_retention_reference.step` is the separate
  mechanical-closure reference assembly, not Plan B.
- `out/PRIMARY_RENATA_ONLY_MEASURE_MAX_coin_motor_10p2x2p7.{step,stl}`
  controls the screw-layout motor envelope.
- `out/*.step` and `out/*.stl` are the manufacturing and gauge files.
- `out/SHA256SUMS.txt` records all generated artifact hashes.

The source package includes `reference/alu_body.step` and
`reference/alu_face_front_v3.step`, so it regenerates without a sibling repo.
Run `python generate_recovery.py`. Any change producing an intersection above
1e-6 mm3 aborts generation. STL and JSON outputs are byte-reproducible; STEP
export bytes may contain timestamps, so compare imported geometry, not bytes.

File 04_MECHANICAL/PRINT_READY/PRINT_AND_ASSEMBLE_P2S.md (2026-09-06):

# Anticipy v0.9: P2S print and no-PCB assembly

This is the four-day **engineering prototype**: XIAO nRF52840 Sense, Adafruit
5683 microSD BFF, exact Jauch LP502030JH+PCM+2 WIRES 50MM 250 mAh pack
(32.0 x 21.0 x 5.4 mm), B3U-1000P button, haptic motor and a controlled
12 x 8 x 3 mm hand-wired driver envelope. It is not waterproof, drop-certified or a
customer-production release.

## The one file to open

Open `Anticipy_v09_five_units_P2S.3mf` in Bambu Studio. It is in this same
`mechanical` folder and contains five
bases, five correctly flipped lids, five lanyard backplates, and all three
button-plunger lengths for every unit.  It contains geometry and placement,
not printer-bound G-code.

## P2S / PLA Silk+ settings

| Bambu Studio field | Set this |
|---|---|
| Printer | Bambu Lab P2S, 0.4 mm nozzle |
| Filament | Bambu PLA Silk+ preset |
| Nozzle | 235 °C first and later layers |
| Layer height | 0.16 mm; 0.20 mm first layer |
| Wall generator | Arachne |
| Wall loops | 4 |
| Top / bottom shells | 6 / 6 |
| Infill | 40% gyroid |
| Outer / top surface speed | 50 mm/s |
| Inner wall speed | 100 mm/s maximum |
| Support | Off |
| Brim | 3 mm outer brim, 0.10 mm gap |
| Seam | Aligned; paint it onto the USB side |
| Print order | By layer, not by object |

Use the official Silk+ preset for plate temperature and cooling because that
changes with the build plate.  Open the P2S door or top for PLA.  If the spool
has popped or strung, dry it at 55 °C for 8 h before the important plate.
Bambu's official guidance recommends 235 °C and a 50 mm/s outer wall for the
best gloss: <https://wiki.bambulab.com/en/x1/manual/printing-with-silk-filaments>

The base prints floor-down.  The 3MF has already flipped the lid so its smooth
outside face is on the bed and all internal pockets grow upward.  The verified
meshes need no supports; the base only has two small, approximately 10 mm
bridges above the USB opening.

First print **unit_1_base, unit_1_lid_exterior_face_down and the three
unit_1_plunger objects**. In Bambu Studio, select every other object in the
Objects panel, right-click, and choose **Do Not Print**. Dry-close unit 1. Only
then enable and print the remaining four sets. PLA Silk+ is attractive but brittle and
heat-sensitive; do not leave this prototype in a hot car.

## Material and consumables for five units

| Buy | Quantity | What it does |
|---|---:|---|
| Bambu PLA Silk+ 1.75 mm | 1 spool | About 60–80 g including brim and retries |
| 3M 9495LE / 300LSE, 0.17 mm | 1 small sheet or roll | Battery, motor, driver and lanyard primary bond |
| Polyimide tape, 10 mm wide | 1 roll | Independent safety straps and wire strain relief |
| 0.5 mm tinned solid copper wire | 1 m | Fourteen short, low-profile XIAO-to-BFF pad bridges |
| 1.0 and 1.5 mm heat-shrink tube | 1 m each | Individual battery-lead splices and joint insulation |
| PORON 4701-30, 0.79 and 1.57 mm | 1 small sheet of each | Select-to-fit microphone gasket; side cushions only |
| MG Chemicals 1035 neutral-cure RTV | 1 tube | Four board corner stakes and optional seam dots |
| M1.4 x 5 mm thread-forming screws | 12 | Two per enclosure plus two spares |
| Breakaway 2 mm lanyards + 6 mm split rings | 5 | Wear test; never use a non-breakaway neck cord |
| 90%+ isopropyl alcohol + lint-free swabs | 1 set | Adhesive surface preparation |
| 0.9–1.0 mm pin drill + hand pin vise | 1 | Clean printed screw pilots; no powered drill near cell |
| 0.6–0.7 mm pin drill + hand pin vise | 1 | Hand-clear the three 1.0 mm mic apertures if first-layer squish leaves flash |
| Flush cutters, fine tweezers, 600-grit paper | 1 set | Trim/smooth only; never sand near installed electronics |
| Digital calipers, 0.01 mm display | 1 | Measure the finished board stack and printed fit |

3M describes 9495LE as a 170 µm, double-coated polyester tape using its 300LSE
adhesive: <https://multimedia.3m.com/mws/media/2366195O/3m-double-coated-tape-9495le.pdf>.
Rogers describes 4701-30 as a very soft compression-control foam:
<https://www.rogerscorp.com/elastomeric-material-solutions/poron-industrial-polyurethanes/poron-4701-30>.
MG 1035 is neutral cure and intended for sensitive electronics:
<https://mgchemicals.com/products/adhesives/silicone-adhesive/rtv-glue/>.

## Prototype charging rule

Charge only while an adult is watching, on a nonflammable surface. Never charge
the pendant while it is worn; unplug USB before any wear, shake, audio or drop
test. Stop immediately for heat, swelling, smell, damaged wrap or unstable
charging. A customer-production design needs a documented cell-temperature/NTC
strategy and charger qualification; this hand-built prototype does not supply
that proof.

## Assembly: one simple order

1. **Print and dry-fit the empty case.** The lip must seat without force. If it
   is tight, remove only the high spots with 600-grit paper.  Clean the two
   screw pilots by hand and test M1.4 x 5 screws without the battery present.
   Hold the lid to a light: all three 1.0 mm microphone holes must be open. If
   one has only a thin PLA skin, clear it from the outside by hand with a
   0.6–0.7 mm pin; do not enlarge the finished hole and do not use a power drill.
2. **Make the 7.0 mm board sandwich.** With no USB cable and no battery, solder
   a red 30 AWG pigtail to XIAO BAT+ and black to BAT-, then cover those pad
   joints with polyimide. Put XIAO and BFF **backs facing each other**, exactly
   as Adafruit specifies, with same-name edge pads aligned and 0.20–0.25 mm PET
   electrical insulation between the backs (cut away only at the edge pads).
   Route the red/black battery pigtails directly out one side; no wire may run
   between the two board backs.
   Do not use the supplied plastic headers. Bridge all fourteen aligned edge
   pads with short 0.5 mm tinned solid-wire pieces; solder, trim flush, inspect
   every neighbour for shorts, and meter-check 3V-to-GND before USB. The BFF's
   uncut default TX jumper becomes XIAO D6/P1.11 chip-select. The finished
   stack—including solder and insulation—must measure no more than
   17.8 x 21.0 x 7.0 mm with digital calipers; rework it if it does not. The
   supplied dummy STL is a solid CAD envelope reference, not a physical gauge.
   This is fine-pitch
   soldering: use an experienced assembler if you cannot make clean joints.
3. **Wire the external button while there is no battery.** Connect B3U-1000P
   between XIAO D7/P1.12 and GND, leave a short lid service loop, then insulate
   both joints. Do not use the XIAO reset button as the user button.
4. **Build and wire the haptic circuit while there is no battery.** Draw a
   measured 12 x 8 mm rectangle on paper. Lay the AO3416, SOD-123 diode, 1210
   capacitor and three 0805 parts inside it, solder the insulated cluster and
   connect its motor and XIAO leads exactly as shown on the wiring card. The
   finished cluster—including solder and wire exits—must stay within
   12 x 8 x 3 mm; rebuild it if it does not.
5. **USB-test the complete electronics.** Insert microSD and prove audio, BLE,
   storage, the external button and haptic motor. Unplug USB. Fix every fault
   now; do not connect the battery until all five functions pass.
6. **Join the battery one wire at a time.** Put the pouch on a fire-resistant
   bench, confirm Jauch polarity with a meter, and keep bare lead ends separated.
   Slide heat-shrink onto black; make and fully insulate its inline splice to
   BAT- first. Only after no conductor remains exposed, repeat for red/BAT+.
   Never cut or strip both pouch leads at once; keep soldering heat at the wire
   end, at least 40 mm from the pouch. Meter-check polarity at the XIAO before
   power. This permanent splice is the selected connection; after this step,
   perform **no more soldering** on this unit.
7. **Clean every bonding spot.** Wipe printed plastic and component backs with
   isopropyl alcohol and let them dry completely.
8. **Install the exact Jauch battery in the base.** The hard cradle opening is
   deliberately 37.20 x 24.55 mm: it accepts a full +15% pack envelope plus
   0.20 mm per side. The real 32.0 x 21.0 mm pack therefore has 2.60 mm end
   clearance and 1.775 mm side clearance on each side. Put two narrow 9495LE
   strips under its flat face, away from the PCM/protection tail. Centre it with
   soft 1.5–1.8 mm PORON strips only along the side edges (or three stacked
   0.5 mm foam strips per side), then add two relaxed polyimide straps. Do not
   add rigid shims and do not squeeze or cover its broad faces; the free space
   above it is swelling allowance. Point the pack's PCM/wire tail toward +X,
   the XIAO end with the centred 5 mm rail opening. Route both 50 mm leads
   through that opening, then along the molded perimeter—not across the pouch
   face—and keep every bend radius at least 3 mm.
9. **Install the XIAO/BFF stack.** USB-C faces the side opening, the nRF52840
   microphone faces the lid, and the BFF/microSD faces the tray. The board
   fences provide about 0.25 mm nominal side clearance; they are not a +15%
   hard bay. Dry-fit the measured stack and lightly sand only printed high spots
   until it seats without force. Add four tiny
   MG 1035 corner fillets between the board edge/fences and tray.  Keep RTV away
   from the microphone, antenna, USB and microSD.  Cure open for 24 h.
10. **Build the lid without soldering.** Insert the 1.7 mm captive plunger from
   inside. Bond the already-wired B3U switch actuator-up in its pocket. If it
   does not click, try 1.9 and then 2.1 mm; use the shortest that clicks without
   staying pressed. Bond the already-wired motor and driver in their printed
   pockets with 9495LE. Route 30 AWG leads through
   the printed low wire notches—two on the driver guard and one on the motor
   ring—then bridge each pocket with an independent polyimide strap. No wire may
   cross over a guard wall or sit between the wall and lid during closure.
11. **Make the microphone gasket.** Measure the hard gap with the actual board.
   Cut a 6 x 5 mm PORON ring with a 4.2 x 3.2 mm clear centre.  Pick a thickness
   about 0.2–0.3 mm greater than the measured gap.  The foam touches gently; the
   printed chimney must never hard-contact a component.
12. **Tame the wires.** Leave one short service loop for the lid and tape the
   wires to the perimeter every 10–15 mm.  Nothing crosses a screw post, the
   battery face, microphone duct or antenna.  No free wire span exceeds 20 mm.
13. **Close it.** Confirm the button returns and the mic gasket is only lightly
    compressed.  Install two M1.4 x 5 screws by hand.  Stop when the seam closes;
    do not crush the tiny posts. Do not add RTV seam dots yet: the first six
    drops require reopening the case after every impact.
14. **Add the breakaway lanyard.** This printed backplate and its protruding tab
    are an external test accessory; they are intentionally excluded from the
    controlled 66.2 x 27.2 x 14.2 mm body envelope. With 0.17 mm tape it makes
    the thickest wearable test assembly approximately 15.97 mm, before the
    lanyard ring. Its tab also makes the printed wearable assembly approximately
    80.2 mm long before the ring; the bare electronic body remains 66.2 mm.
    Bond the flat backplate to the rear with
    9495LE, with its tab beyond the top end.  Press firmly, then leave it 72 h
    before a pull or drop test.  Attach a 6 mm split ring and breakaway cord.

## Rattle and drop gate

Do not call a unit finished until it passes all of these:

- 60 seconds of hand shaking on each of six axes: no audible or felt movement.
- 100 button presses, 100 haptic pulses and 20 USB insertions.
- One-minute audio playback: no enclosure buzz, muffling or tape noise.
- BLE stream, SD removal/reconnect and backlog transfer after final closure.
- 16-hour sealed runtime test and a separate 20-hour offline-storage test.
- After adhesive cure: screw-close, make one powered-off 1 m drop on one face
  onto 12 mm plywood over concrete, reopen, and inspect the pouch and wiring.
  Repeat for all six faces; stop immediately
  for a dent, smell, heat, swelling, torn wrap or cracked cell pocket.
- Only after all six inspectable drops pass, add four pinhead-size MG 1035 seam
  dots and cure 24 h. To test the sealed state, use one sacrificial unit for the
  remaining edge/corner drops and open it only after its final drop.

Passing this is an engineering result, not certification.  Geometry is verified;
physical print fit, battery runtime, RF, acoustics and impacts cannot be promised
before the five real builds are measured.

## Production enclosure recommendation (50–200 units)

Use a **PA12 MJF structural chassis**, not PLA and not a metal shell carrying
loads.  Add optional **0.3–0.4 mm 5052-H32 aluminum cosmetic front/back caps**.
The caps are bonded to recessed PA12 ledges and never carry the chain load.

- Leave an 8–10 mm PA12 RF window at the antenna end: no aluminum cap, battery,
  screw or long ground conductor over that zone.
- Anchor the bail through a metal eyelet into a broad PA12 load-spreading boss.
- Locate the PCB with three hard datums plus one soft stop, then use three screws
  into inserts; this prevents rocking without over-constraining it.
- Put 0.17 mm PSA under the pouch, low-force PORON only at its edges, a pull tab,
  and 0.8–1.0 mm free swelling space above the broad face.
- Use a production pack with a qualified NTC/temperature-sensing path and prove
  charger cutoffs across normal, hot, cold, open-sensor and shorted-sensor tests.
- Bond the haptic motor to a stiff PA12 rib with 9495LE and add a molded keeper
  or screwed strap.  Keep the motor and all fasteners off the pouch envelope.
- Mold wire channels and strain-relief hooks so no wire can sweep or slap a wall.
- Add 0.6–0.8 mm corner ribs, at least 1 mm PCB-to-wall impact clearance, boss
  gussets, and a tongue-and-groove seam.  Use an acoustic ePTFE mic membrane;
  claim no ingress rating until it is tested.
- Run six-face, twelve-edge and eight-corner drops on production-intent shells,
  then vibration, button, audio, RF and charge tests again.

PA12 carries every screw, battery, PCB, motor and bail load.  Aluminum supplies
the cool metal feel only; that separation is what keeps the device quiet after
a full day of motion and after a drop.

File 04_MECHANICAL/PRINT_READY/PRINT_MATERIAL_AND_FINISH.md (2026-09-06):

# P2S material and finish card

## What to use tonight

Use the **PLA Silk+ you already own**. It is good for checking the shape and
making a shiny visual prototype. It is not the material for a sellable pendant.

In Bambu Studio:

1. Select **Bambu Lab P2S**, 0.4 mm nozzle and the matching PLA Silk+ profile.
2. Use the supplied 3MF orientation; do not stand the shell on its end.
3. Use 0.12 mm layers, three walls and 25% gyroid infill.
4. Bambu's Silk/Silk+ guide recommends 235 °C nozzle temperature and the
   product guidance recommends slowing the outer wall to 50 mm/s for gloss.
5. Print one shell first. Dry-fit the plastic dummy parts. Only then print five.

Do not sand the first Silk+ shell. Sanding removes the shiny skin and makes the
surface patchy.

## If you want a better metal-looking plastic print

Order **Bambu PLA Metal — Iron Gray Metallic** from the Bambu Lab Canada
store. It was listed at CAD 31.99 when checked on 2026-08-29. It is still PLA
plastic; Bambu says it is designed to imitate metal texture. It does not become
an aluminum customer enclosure.

Official links:

- P2S specification: https://bambulab.com/en/p2s/specs
- PLA Silk/Silk+ guide: https://wiki.bambulab.com/en/x1/manual/printing-with-silk-filaments
- PLA Metal Canada: https://ca.store.bambulab.com/products/pla-metal

## The sellable material

- **Inside/back:** injection-molded Covestro Makrolon 2407 polycarbonate.
- **Front face:** 0.8 mm 5052-H32 aluminum, brushed and clear- or black-anodized.
- **RF end:** uncoated polycarbonate; metal cannot cover the Bluetooth antenna.

That stack gives the PLAUD-like cool metal face while keeping impact strength
and radio performance. A home FDM printer is for shape/fit prototypes, not the
finished metal consumer shell.

## If you want a painted show model

Print a second shell later in a normal or tough PLA, then use filler-primer,
wet-sand, metallic automotive paint and a compatible clear coat. Paint only an
empty shell in a ventilated area. Never spray a battery, microphone membrane,
button boot, charging contact or assembled electronics.

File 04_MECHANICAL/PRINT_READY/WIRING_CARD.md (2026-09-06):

# Five-unit prototype wiring card

## Think of it like five toy blocks

- XIAO: the brain, Bluetooth radio, microphone and charger.
- microSD BFF: the memory-card holder.
- battery: the food.
- button: the finger input.
- motor: the buzz.

## Exact pins

| Function | XIAO nRF52840 Sense pin |
|---|---|
| microSD chip select | D6 / P1.11 |
| user button | D7 / P1.12 to GND |
| haptic MOSFET gate | D0 / P0.02 through 100 ohm |
| battery | red to BAT+, black to BAT- |

## Physical board sandwich

The Adafruit 5683 sits back-to-back with the XIAO. Do **not** use the tall
plastic headers. Before covering the XIAO battery pads, add insulated red/black
30 AWG pigtails to BAT+/BAT-. Separate the board backs with 0.20–0.25 mm PET
electrical insulation, align all same-name edge pads, and bridge all fourteen
pairs with short 0.5 mm tinned solid-wire pieces. Route the battery pigtails out
one side, never between the board backs. The uncut BFF TX jumper is XIAO
D6/P1.11. The soldered stack must remain within 17.8 x 21.0 x 7.0 mm and
must meter open-circuit from 3V to GND before USB is connected.

## Battery connection

There is no connector in v09. First test on USB, then unplug it. Confirm pouch
polarity with a meter. Inline-splice and fully heat-shrink the black/BAT- lead;
only then expose and splice red/BAT+. Never cut or strip both live pouch leads
at once, and keep the solder joint at least 40 mm from the pouch.

## Haptic wiring

1. D0 -> 100 ohm -> AO3416 gate.
2. 100 kohm from gate to ground.
3. AO3416 source to ground.
4. AO3416 drain to motor negative.
5. Motor positive to 3.3 V.
6. 1N5819 diode across the motor: stripe to 3.3 V, other end to drain.
7. 0.1 uF across the motor and 47 uF across 3.3 V/ground beside it.

Bench-test all electronics before the battery enters the printed shell. Check
battery polarity with a multimeter; never guess from wire colour alone.

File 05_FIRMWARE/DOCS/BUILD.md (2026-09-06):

# Reproducible source and candidate-build receipts

## Current result

The Anticipy firmware customization and reviewed source-safety repairs are now
one cumulative source delta, not an unexplained binary.
`replacement/patches/0002-anticipy-source-safety.patch` applies by itself to
the exact BasedHardware/Omi commit and tree in `upstream.lock.json`.
`replacement/patches/0001-anticipy-name-and-battery.patch` is retained only as
historical review evidence; it is not authoritative and must not be applied
before or after `0002`. The materializer checks the upstream Git objects, the
single authoritative patch hash, every critical post-patch file, and the
complete materialized content tree before writing a deterministic source
receipt.

This is still a **source candidate**, not a flash-approved firmware image. The
final cumulative bytes have not been built as embedded firmware. A separate
one-machine offline development build of an earlier source state is recorded in
`development-receipts/2026-07-23-single-local-not-for-flash.md`; its warnings
and missing replica/SBOM/signature/hardware evidence mean it cannot validate
this repaired source. No UF2 was written to hardware. The quarantined custom
UF2 is not an output of this pipeline.

## Exact source delta

The cumulative patch preserves these compatibility behaviors:

- Advertises the complete BLE name `Anticipy` and reports the Device
  Information model `Anticipy Pendant`.
- Keeps the Omi audio service/data/codec UUIDs and codec ID 20 unchanged.
- Keeps the existing three-byte audio notification header, derives fragment
  capacity from the ATT MTU, rejects ATT MTU below 100, and limits a maximum
  320-byte Opus frame to four notifications.
- Publishes one successful standard Battery Service measurement before
  advertising and refreshes it immediately per connection, then every 15
  seconds while connected.
- Filters successful measured percentages with a fixed-point 3:1 exponential
  moving average. The first measurement is published unchanged, the filter is
  reset for each connection, and values are clamped to 0–100.

The selected image is now live-stream-only:

- Offline storage, FAT/disk, I2C sensor, I2S, SPI, NFC, speaker, button, legacy
  board configurations, application USB/serial, and application DFU code are
  disabled or removed from the authoritative source.
- Only the selected devkit-v2 configuration and overlay remain. Firmware
  revision advertising is disabled because no truthful release version exists.
- Audio and CCC access require encryption. LE Secure Connections, a single
  settings-backed bond, and NVS settings are configured, but Just Works pairing
  without physical enrollment, MITM proof, erase gesture, or owner allowlisting
  is explicitly **not** owner authentication.
- Capture requires a fresh CCC write from the exact current encrypted
  connection. Persisted CCC restoration cannot start PDM. A dedicated control
  thread revalidates connection identity, fresh authorization, and subscription
  before microphone start and before committing active state.
- Unsubscribe, disconnect, codec/notify failure, or PDM fault clears active
  state and enters one serialized stop path. DMA buffers are scrubbed only
  after bounded confirmation that asynchronous PDM stop completed.
- Advertising readiness is published before initial controller start.
  Initial-start failure is reported but enters the same recovery as a
  disconnect: a bounded fast retry burst followed by continuing delayed
  attempts instead of permanent abandonment.
- Battery divider arithmetic preserves the full ratio. Startup measurement
  failure blocks advertising; runtime measurement failure disconnects rather
  than publishing `0%` or a plausible stale percentage. The voltage-to-percent
  curve remains an uncalibrated development estimate.
- Shared connection state uses referenced handles. Queue and codec epochs keep
  prior-session PCM, encoded frames, and Opus predictor state out of a new
  connection.
- ATT fragmentation advances offset, sequence, and fragment index only after a
  successful notification and bounds retry work.
- Restricts the Opus build to the encoder/CELT surface required by the product,
  restores required fixed-point helpers, uses single-evaluation assertions,
  checks the fixed encoder allocation, and resets encoder state at each audio
  epoch.
- Promotes selected memory-safety diagnostics to compile errors.

Pure battery smoothing, divider arithmetic, and transport-fragment helpers are
compiled and run on the host with strict warnings and, when supported,
AddressSanitizer/UndefinedBehaviorSanitizer. The test suite also proves that
`0002` alone materializes the locked final source tree. This is source-level
evidence, not an NCS/Zephyr build or hardware validation.

The patch does not add haptic hardware support, secure first-owner enrollment,
authenticated/OOB pairing, a bond-erase gesture, a signed boot/update chain,
battery calibration, or any physical-hardware proof.

Materialize and verify it without compiling:

```bash
python3 firmware/scripts/fetch_upstream.py
python3 firmware/scripts/materialize_replacement.py \
  --destination firmware/.build/source/anticipy-v2.0.1
```

The output includes `ANTICIPY_SOURCE_RECEIPT.json`. The receipt has no machine
path or timestamp, so the same locked inputs produce the same receipt bytes.
`replacement/replacement.lock.json` is the review boundary for the patch and
post-patch tree.

## Explicit SDK and toolchain inputs

`replacement/toolchain.lock.json` pins:

- [nRF Connect SDK v2.5.0](https://github.com/nrfconnect/sdk-nrf/tree/1fae141fc6713dd331b797fc96c90dc84552242d)
  at commit `1fae141fc6713dd331b797fc96c90dc84552242d`, including the
  Git blob and SHA-256 of its `west.yml`.
- [Nordic's Zephyr fork](https://github.com/nrfconnect/sdk-zephyr/tree/2e2523efe52a7ac89f0567b8798fd857b1e71ae3)
  at commit `2e2523efe52a7ac89f0567b8798fd857b1e71ae3`.
- The `linux/amd64` Nordic toolchain container by immutable OCI digest. The
  human-readable `v2.5-branch` tag is recorded only as provenance and is never
  treated as a lock.
- Board, Kconfig file, and the checked-in devicetree overlay that actually
  exists at the Omi tag.

The NCS manifest contains inactive/private projects that are not build inputs
and cannot be fetched by this candidate. The builder therefore never asks West
to resolve or freeze the full manifest. It asks `west list` for active projects
only, then reads each active repository's exact local `HEAD` and clean status.
It emits `west-active-projects-frozen.tsv`: UTF-8, path-sorted, one
`path<TAB>40-lowercase-hex-HEAD<LF>` row per active project, including `nrf`.
The artifact SHA-256 and row count, `nrf/west.yml` SHA-256, and `.west/config`
SHA-256 are bound before and after the build, in the build receipt, and in the
SBOM. Credential-free active-project repository URLs are bound separately so
the SPDX packages remain attributable. Inactive projects are neither fetched
nor inspected.

This snapshot is deterministic evidence of the exact active workspace, not
external execution attestation or a signed dependency lock. Before a production
release it must be reviewed and bound to the external two-replica provenance.
Until then, the process remains a pinned candidate build rather than a
bit-for-bit production recipe.

## Quarantined candidate build control (implemented, not executed)

Do not copy this repository into an ad-hoc networked container and do not run a
candidate build from the attached pendant. The reviewed build design separates
public dependency fetching from the private candidate, executes the candidate
with networking disabled and no device mounts, and compares two independent
replica packages before accepting any bytes.

The exact reviewed candidate is
`5786f71b38b7a07ef5cb590159d77c4808059525`. Its
`firmware/scripts/build_candidate.py` SHA-256 is
`17139085ad0ca33c250f2aabb1fb986018cf905813606447bb4a6e5e4b1e218b`.
That candidate pins the actual `xiao_ble_sense` board, the raw and cached CMake
paths and types, and rejects aliases, remapped boards, duplicate or multivalue
inputs, control characters, and configuration drift.

A separate fail-closed control plane is preserved in the local worktree
`/Users/omarebrahim/anticipation-lanes/firmware-ci-signed` as native SSH-signed
commit `e69366ca3c992d22f16ac782eb719d0cc67a699b`, whose parent is current remote
`main` commit `2a513db2968ddde853c280c3ead2bfe8603c3993`. Its focused control suite is
29/29 green. The workflow SHA-256 is
`764662bdee9f53f892a33b55375bf55a45b621ca8d48c1695898a70338ce3287`.

That signed commit is **local only**. GitHub refused the HTTPS push because the
current OAuth token lacks workflow-write scope. No permission was broadened and
no browser upload was submitted. The workflow also deliberately requests the
unavailable runner label `anticipy-firmware-40gb`, refuses non-GitHub-hosted
runners before checkout, and the repository has no matching runner. The current
repository `main` is not a safe immutable trust root because it is unprotected
and has non-owner collaborators. Therefore the current decision is **NO PUSH
WORKAROUND, NO DISPATCH, NO ARTIFACT, NO FLASH**.

Before a build can run, the exact reviewed control bytes must be migrated into
an owner-only protected control repository and independently re-reviewed. It
then needs either two eligible organization larger hosted runners or two fresh
one-job JIT/ephemeral runners under that owner-only control. Changing the
current `github-hosted` guard, repository identity, workflow permission, or
runner design is a new security-sensitive change, not a clerical bypass.

The control requires each replica host to have at least 40 GiB free, three CPUs,
and 16 GiB available memory. Only a copied trusted fetch script and empty public
dependency/evidence directories enter the network-enabled container; it sees no
candidate checkout or GitHub token. Runtime construction and the candidate run
then execute with `--network=none`, read-only inputs, no devices, dropped
capabilities, no-new-privileges, and resource caps. Provider ZIPs are hashed
before safe extraction, and the independent replicas must match byte for byte.

`build_candidate.py` itself refuses to run unless all of the following agree
with the locks: upstream source, Anticipy patch, exact west topdir/config, NCS
commit, NCS manifest hash, Zephyr commit, every active west project present and clean,
required tools, ARM compiler, exact board/CMake inputs, and an explicit
container-digest declaration. It binds every active project path, repository,
and HEAD before the build, then verifies that those values, the local West
config, `nrf/west.yml`, and clean state did not change during the build. An
accepted replica would emit:

- the deterministic source receipt;
- canonical `west-active-projects-frozen.tsv`, its SHA-256, and project count;
- exact pre/post hashes for `nrf/west.yml` and `.west/config`;
- a deterministic SPDX 2.3 JSON SBOM whose packages bind the source overlay,
  exact active-project commits and repositories, the snapshot/config/manifest
  evidence, and digest-declared toolchain container,
  and whose files bind every emitted ELF/HEX/BIN/UF2/map artifact by SHA-256;
- exact tool versions and build command;
- all active west project paths, repositories, commits, and pre/post
  cleanliness evidence;
- complete build log and hash;
- sizes and SHA-256 values for emitted ELF/HEX/BIN/UF2/map files; and
- explicit `flash_approved: false` and `flash_performed: false` fields.

The SBOM is emitted only after the build, UF2, and pre/post SDK invariants pass.
The builder derives `SOURCE_DATE_EPOCH` from the locked upstream Git commit,
validates against a vendored official SPDX v2.3 Draft-07 schema, atomically
writes the document, rehashes the firmware artifacts, and records the final
SBOM SHA-256 in `ANTICIPY_BUILD_RECEIPT.json`. A failed build, missing validator,
schema drift, active-project/config/manifest drift, or artifact drift emits no
SBOM and cannot become an accepted candidate.

`--probe` includes this offline SBOM gate in `ready`. The generator contract is
`anticipy-firmware-spdx` 1.0.0 under exact CPython 3.10.14, `jsonschema` 4.26.0,
and PyYAML 6.0.3; a missing dependency or any version mismatch makes readiness
false. These identities are locked, recorded in the receipt and SPDX creators,
and included in a namespace derived from the complete canonical document body.
Every active west project must also carry a credential-free HTTPS repository
URL and exact Git commit. No path-only or `NOASSERTION` project provenance is
accepted.
Reserved SBOM/atomic-temporary output from a failed or contaminated build is
removed or causes the candidate to be refused, and every sensitive path rejects
symlinks in all existing ancestors.

The official schema is vendored as base64 so its decoded bytes remain identical
to `schemas/spdx-schema.json` from SPDX tag `v2.3`, commit
`aadf3b0b8dbbabdb4d880b0fc714255fea436ff7`, SHA-256
`239208b7ac287b3cf5d9a9af23f9d69863971102a5e1587a27a398b43490b89b`.
Its immutable source URL and hash are in `replacement/spdx-schema.lock.json`;
runtime validation is offline and fails closed if Python `jsonschema` Draft-07
or PyYAML validation is unavailable. The SBOM classifies west repositories as
build inputs, not as a claim that every repository byte is linked or shipped.

The digest environment variable is an operator declaration, not an attestation.
The process cannot prove which OCI image contains itself, so the receipt labels
this fact `UNVERIFIED_OPERATOR_DECLARATION` and never records the expected digest
as an observed runtime fact. Production still needs externally generated,
verifiable OCI/CI provenance bound to the artifact hashes.
The SPDX inventory likewise is not a signature, reproducibility attestation,
flash approval, or physical-hardware proof.

The following local probe is read-only and does not fetch, build, sign, upload,
dispatch, flash, or touch hardware:

```bash
python3 firmware/scripts/build_candidate.py --probe
```

A passing repository verification and probe is not a release authorization.
The separately recorded local development package is explicitly not an
accepted candidate. No release SBOM, signed firmware, or flash-approved UF2
exists.

## Gates that source reproducibility does not solve

An Anticipy-owned release still requires all of these before any production
flash:

- identify the physical board revision and bootloader/recovery behavior;
- implement and review an Anticipy-owned signed boot/update chain with signing
  keys held outside source control, version policy, and rollback protection;
- prove the selected settings/NVS partition and CELT-only link closure in the
  exact pinned embedded build;
- implement authenticated first-owner enrollment, an owner allowlist,
  authenticated/OOB pairing or an equivalent documented control, physical bond
  removal, and a deliberate physical recovery flow;
- review and externally attest the canonical active-project snapshot and
  artifact receipt;
- bind artifact hashes to externally verifiable OCI/CI build provenance;
- calibrate the battery curve/divider against the physical board;
- test first on a recoverable spare, then prove BLE/audio/battery/recovery on the
  actual board and a real iPhone.

The source overlay is reviewable and repeatable. Its encrypted single-bond
transport is still not production owner authentication, and removing the
application DFU service does not prove the immutable bootloader or recovery
path secure.

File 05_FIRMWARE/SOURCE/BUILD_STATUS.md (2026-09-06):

# Build and verification status

> **LAB ONLY — DO NOT CUSTOMER-SHIP:** microSD audio is plaintext. Use synthetic or explicitly non-sensitive test audio only.

Status date: 2026-08-28 UTC

## Bottom line

The nRF52840 founder-EVT firmware is **compile-successful and flashable**. It is **not hardware-validated and not customer-release-ready**.

| Requirement | Implemented in source | Compiles | Host-checked | Real hardware / iPhone tested |
|---|---:|---:|---:|---:|
| 16 kHz mono XIAO PDM capture | Yes | Yes | Static only | No |
| Opus, 10 ms, 16 kb/s target, CBR | Yes | Yes | Static only | No |
| Opus DTX / internal voice detection | Yes | Yes | Static only | No |
| Encrypted BLE live notifications | Yes | Yes | Static only | No |
| Offline microSD when live is unavailable | Yes | Yes | Packing tested | No |
| 20 h storage capacity + 15% margin | Yes | Yes | **182,160,000 B** worst-case model | No timed run |
| MTU-safe ordered backlog transfer | Yes | Yes | Five MTUs + interrupted resume | No iPhone run |
| Button notifications | Yes | Yes | Pins/static | No |
| Haptic GPIO command | Yes | Yes | Pins/static | No |
| Bond persistence | Yes | Yes | Config/static | No |
| 16 h from 250 mAh | Unknown | N/A | Requires <=13.28 mA | No |
| Circular rolling 20 h retention | **No** | N/A | N/A | No |
| SD encryption at rest | **No** | N/A | Explicit blocker | No |
| MITM-safe first pairing | **No** | N/A | Explicit blocker | No |
| Absolute time / file-generation identity | **No** | N/A | Explicit blocker | No |

Additional reliability truth:

- a BLE notification returning success means “queued by the Bluetooth stack,” not “received and saved by the iPhone”; live frame IDs expose gaps, but this EVT has no live retransmission protocol;
- a notification that cannot be queued after three retries is now saved to SD, and audio also continues into SD while backlog transfer is active if live audio is not subscribed;
- live streaming and backlog transfer use equal-priority threads. Their real coexistence and throughput must pass the locked-iPhone hardware test;
- SD capacity is now gated by current file size rather than download offset, but retention is still append-only rather than a rolling circular 20-hour policy.

## Reproducible build

Pinned inputs:

- Nordic nRF Connect SDK: `v2.7.0`, commit `5cb85570ca43bc344d3145c2338128eacf4b48ec`
- Zephyr: commit `100befc70c74f7ec83dd8ac3171ee18eeddb4dbd`
- `hal_nordic`: commit `ab5cb2e2faeb1edfad7a25286dcb513929ae55da`
- Zephyr SDK: `0.16.5`
- board: `xiao_ble/nrf52840/sense`
- application config: `prj_xiao_ble_sense_devkitv2-adafruit.conf`
- devicetree overlay: `overlay/xiao_ble_sense_devkitv2-adafruit.overlay`

Build command from an initialized NCS workspace:

```bash
west build --pristine always \
  -b xiao_ble/nrf52840/sense \
  /absolute/path/to/source_nrf52840 \
  -d build/anticipy \
  -- \
  -DNCS_TOOLCHAIN_VERSION=NONE \
  -DCONF_FILE=prj_xiao_ble_sense_devkitv2-adafruit.conf \
  -DDTC_OVERLAY_FILE=/absolute/path/to/source_nrf52840/overlay/xiao_ble_sense_devkitv2-adafruit.overlay
```

Final clean compile footprint:

- flash: 292,552 B / 788 KiB (36.26%)
- RAM: 168,924 B / 256 KiB (64.44%)
- UF2: 585,216 B

## What the host checks actually prove

`python3 host_checks.py` proves deterministic software properties only:

- 10,000 randomized length-prefixed frames survive pack/unpack;
- fixed-rate capacity needs 158,400,000 B for 20 h, or 182,160,000 B with 15% margin;
- notification pieces never exceed ATT MTU at MTUs 23, 185, 247, 296 or 498;
- interrupted transfers recover from the last complete 440-byte record;
- one-byte data pieces cannot be confused with one-byte control codes;
- the selected SD, button and haptic pins do not overlap;
- application characteristics require an encrypted BLE link and bonds are saved;
- battery-divider enable polarity matches Seeed's documented active-low design.

They do not prove microphone polarity, SD electrical integrity, RF range, iOS background behavior, battery life, heat, sealing or drop survival.

## Hardware acceptance gates

Do not seal a unit until all rows pass:

| Gate | Pass condition |
|---|---|
| Cold boot | 10/10 boots advertise and record |
| Missing SD | BLE live stream still starts |
| Audio | known speech produces decodable 16 kHz mono Opus |
| Live | 60 min, no unexplained gaps or resets |
| Offline | phone absent 20 h, entire timeline drains and decodes |
| Resume | cut BLE at 10 random points; no missing or reordered 440-byte records |
| Power loss | 20 random power cuts; file mounts; measure loss under speech and DTX silence. The fixed 20-byte active-packet estimate is ~3.2 s, but tiny DTX packets can make the same cache span roughly 35 s of quiet time |
| Runtime | 16 h speaking/streaming profile; average <=13.28 mA |
| Button | 100/100 intentional presses, no phantom events |
| Haptic | 1,000 pulses, no brownout, SD fault or reset |
| iPhone background | locked phone + app backgrounded for 2 h without silent disconnect |

## Client status

`ios_test_client/AnticipyBLEClient.swift` is a source-complete CoreBluetooth handoff for live frames, storage reassembly/resume, button and haptic. No Swift/Xcode toolchain or iPhone was available here, so it is source-reviewed and protocol-matched, **not compiled or run**.

The public Omi app (BasedHardware/omi commit `0303fd24579f8e3d0a3b1c3d9e5ad99adf87a4d2`) recognizes codec ID 20 and the live BLE UUIDs. Its legacy SD downloader accepts only a single 440-byte notification, so it is not sufficient for iPhone-MTU-safe backfill without reassembly; the supplied minimal client implements that missing layer.

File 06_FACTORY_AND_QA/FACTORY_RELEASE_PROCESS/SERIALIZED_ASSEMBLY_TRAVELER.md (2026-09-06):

# Serialized assembly traveler

Create one traveler per physical device before any assembly. The same serial appears on the unit, PCBA test result, EOL row, rework record and final disposition. Never reuse a scrapped serial.

## Traveler header

| Field | Required value |
|---|---|
| Traveler ID | `ANT-TRV-<work-order>-<device-serial>` |
| Device serial | Unique controlled serial |
| Phase | EVT / DVT / PVT |
| Work order / lot | Controlled work order and lot |
| PCB/PCBA revision | Exact released revision |
| BOM revision | Exact released revision |
| Mechanical revision | Exact released revision |
| Firmware version and SHA-256 | Exact released binary |
| Factory-test version and SHA-256 | Exact released tester |
| Battery MPN/revision/lot | Exact approved pack |
| Motor lot | Supplier lot |
| Enclosure/cap lots | Supplier/process lots |
| Acoustic/adhesive lots and expiry | Exact membrane/gasket/adhesive records |
| Fixture/station IDs | IDs plus calibration due date |
| Assembly operator(s) | Controlled operator IDs |

If any header field is blank, mismatched or `TBD`, place the unit in HOLD before assembly.

## Line clearance

Before the first unit of every work order:

- Remove all prior-revision parts, labels, firmware and work instructions from the station.
- Scan the released work order and current file hashes.
- Verify fixtures are in calibration and pass self-test/golden-unit verification.
- Verify battery-safe area, current-limited supply, ESD controls and quarantine bins are ready.
- Build and fully accept one first article, then five consecutive units, before unrestricted lot continuation.

## Assembly sequence

Each line creates one event row in `ASSEMBLY_TRAVELER_LOG.csv`.

| Seq. | Step ID | Operation | Required evidence / acceptance |
|---:|---|---|---|
| 10 | `KIT_VERIFY` | Scan all controlled inputs | Every MPN/revision/lot matches traveler; adhesives in date |
| 20 | `PCBA_VISUAL` | Inspect received PCBA | Correct revision/serial; no damage, missing/reversed/shifted part |
| 30 | `PCBA_SAFE_POWER` | Current-limited first power without battery | No short/abnormal current/heat; rail checks pass released limits |
| 40 | `PROGRAM` | Program bootloader/firmware/device identity | Read-back/hash/signature and unique identity pass |
| 50 | `PCBA_FUNCTION` | Run open-board pogo test | Flash, both microphones/interfaces, BLE, button input, LED and haptic output pass PCBA subset |
| 60 | `CHASSIS_PREP` | Inspect/clean chassis and cap | Correct lot; no debris, burr, crack, sharp edge or blocked aperture |
| 70 | `ACOUSTIC_INSTALL` | Install membranes/gaskets in keyed fixture | Correct side/orientation; flat, clean, unwrinkled and within controlled compression position |
| 80 | `BUTTON_LIGHT_INSTALL` | Install plunger/membrane/lightpipe if released | Keyed orientation; free travel; no pinch; optical path seated |
| 90 | `MOTOR_INSTALL` | Install motor in released board-side retainer/isolator | Motor cannot move; leads in channel; motor never bears on battery pouch |
| 100 | `PCBA_INSTALL` | Seat PCBA on released locators/retainer | Board fully seated without bow; mic ports aligned; no antenna keep-out intrusion |
| 110 | `BATTERY_IQC_CONFIRM` | Re-scan and inspect approved battery | Correct polarity/voltage/NTC; no damage/swelling; approved dimensions/lot |
| 120 | `BATTERY_INSTALL` | Place battery in compliant cradle/pull-tab retention | No force, crease, broad-face clamp, wire pinch or motor/PCB pressure; service pull tab accessible if specified |
| 130 | `WIRE_DRESS` | Route all leads through released channels/strain relief | Nothing crosses seam, antenna, mic duct, button travel or sharp edge |
| 140 | `PRE_CLOSE_TEST` | Power and run short functional test | Both mics, BLE, storage, button, LED, haptic and charging sense pass; no reset |
| 150 | `CLOSE_AND_SEAL` | Apply released seal and close in controlled fixture | Correct adhesive/gasket/energy/force/time/cure recipe; shell never forced closed |
| 160 | `CURE_HOLD` | Maintain specified pressure and cure | Start/end time, fixture and conditions logged; no handling before release time |
| 170 | `CLOSED_VISUAL_DIMENSION` | Inspect closed product | Hard envelope ≤51.0 × 21.0 × 11.0 mm; mass ≤17.4 g; released seam/cosmetic limits pass |
| 180 | `EOL` | Run complete `EOL_TEST_SPEC.md` | One complete passing EOL row written against this serial |
| 190 | `BURN_IN` | Run every-unit phase-defined recording/streaming burn-in | No reset, loss, corruption, overheating, rattle or seam change; duration logged |
| 200 | `FINAL_INSPECTION` | Clean, inspect, rattle screen and verify label | No free motion, contamination, damage, exposed adhesive or sharp edge |
| 210 | `DISPOSITION` | Accept / rework / quarantine / scrap | Authorized disposition and linked records |
| 220 | `PACK` | Package only a released unit | Correct accessory/label/serial and transport-compliant packaging |

`CLOSE_AND_SEAL` remains blocked until the retention and seal drawings/process recipe listed in `MECHANICAL_OPEN_ITEMS.md` are physically validated and released.

## Rework rule

- Failed units leave the normal line and enter a controlled rework traveler.
- Record failure code, NCR, original measurement, rework instruction/revision, operator and replacement part lot.
- After rework, rerun the failed step and every downstream step, including complete EOL.
- Never rework or reuse a damaged/swollen pouch cell.
- Rework count remains attached to the serial; a pass never erases failure history.

## Final record package per serial

The traveler is complete only when it links:

1. incoming lots;
2. all step-event rows;
3. programming record;
4. EOL result;
5. burn-in/sample qualification result;
6. NCR/rework history;
7. final disposition; and
8. pack/ship record if released.

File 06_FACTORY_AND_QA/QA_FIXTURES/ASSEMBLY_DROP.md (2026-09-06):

# 1.2 m low-spin free-drop release

## The non-negotiable geometry

The two 2020 masts hold the release head at a measured height. They do **not** guide the product while it falls. Below the three fingers is an unobstructed 80 mm fixture opening and at least a 200 x 200 mm guarded free-fall corridor.

## Stand

1. Bolt two 1500 mm 2020 extrusions to a 600 x 600 x 18 mm weighted base with metal brackets.
2. Add a rigid 2020 crossbar and diagonal metal braces.
3. Tether the mast to a wall or rigid bench. Ballast alone is not sufficient.
4. Mount the collet body horizontally to the crossbar with metal L-brackets through its four mounting holes.
5. Install the full polycarbonate fall/rebound guard.
6. Put a fresh 300 x 300 x 18 mm plywood target directly on level concrete at the guard centre.

## Collet

1. Install three guide caps at 90, 210 and 330 degrees. Use washers and nyloc nuts.
2. Install an M4 heat-set insert axially into each finger’s inner bore. Install an M4 x 30 nylon screw and locknut; cover only the final face with smooth PTFE tape or a POM cap.
3. Slide one finger under each guide. It must move at least 35 mm under spring force with no binding.
4. Connect matched extension springs from each finger outer hole to its body anchor. Measured pull at the closed position must match within 10%.
5. Install three polished M4 guide rods through the body and common latch plate. Collars set the lowered and 10 mm lifted positions.
6. In the lowered position, each latch stop block sits immediately outside one closed finger and prevents the spring opening it.
7. Tie three equal-length low-stretch cords from the latch plate to the three outside holes of the printed three-cord yoke. Connect the yoke centre hole to one 12 V pull solenoid above the opening. Hang a ruler from each plate attachment point and trim the cords until the unloaded yoke is level within 0.5 mm.
8. Pulse the solenoid from a fused, guarded ARM + momentary DROP box. Add a flyback diode. Never exceed the solenoid maker’s duty cycle.

The plate must rise parallel. Measure all three guide points: lift mismatch may not exceed 0.5 mm, and every finger must retract at least 35 mm.

## Setting one of 26 orientations

1. Copy `drop_orientation_map.csv` for the DUT serial.
2. Put the named pose key on a small lab jack beneath the collet.
3. Raise it until the pendant centre line aligns with the three nylon tips. The pose key automatically points the named face, edge or corner down.
4. Lift the common latch plate, push all three fingers inward, and lower the plate behind them.
5. Adjust the three nylon tips until they just hold the inert dummy/product at its centre of mass. Use equal light contact. Lock the nuts.
6. Lower the lab jack at least 20 mm and remove the pose key completely.
7. Verify the product hangs freely and no tip touches the button, microphone ports, chain hole or seam.

Re-measure the 1.200 m drop from the **intended impact point on the product** to the target, not from the collet body. Allow +/-2 mm.

## Thirty-release qualification with the inert dummy

Use an inert dummy weighted to production mass. Film side-on at 240 fps against a contrast grid.

Each release passes only if:

- All three fingers visibly start retracting in the same 240 fps frame.
- Every finger clears the dummy by at least 10 mm before it falls 15 mm.
- No fixture part or cord touches the dummy after release.
- The dummy remains inside the free-fall corridor.
- Angular change during the first 0.5 m is no more than 5 degrees.
- Height is 1200 +/-2 mm.

Any miss means change spring matching, clean/ream the guide, rebalance the three lift cords or replace the contact faces. Do not average failed releases away.

## DUT sequence

For the 26-drop engineering sequence, use all rows of `drop_orientation_map.csv`: six faces, twelve edges and eight corners. After every drop:

1. Wait and observe from outside the guard.
2. If the unit is hot, swollen, leaking, hissing, smoking, dented at the battery or has opened, stop and follow the battery quarantine procedure.
3. Otherwise inspect seam/sharp edges, record result, and run the defined short functional check.
4. Replace a damaged target before the next drop.

Do not recharge a drop-test unit until it has completed the written post-test battery inspection.

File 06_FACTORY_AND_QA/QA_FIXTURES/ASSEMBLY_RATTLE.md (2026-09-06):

# Rattle cradle assembly and qualification

## What it does

The cassette holds the outside of the pendant still while gravity changes direction. If a battery, PCB, motor, wire or button part is loose inside, it moves and creates an impulse. The fixture deliberately moves slowly; it is not a vibration or tumble machine.

## Mechanical assembly

1. Print and inspect the base, two bearing towers, motor mount, rotor, cassette, axis adapter and TPU liners.
2. Press one 608-2RS bearing into each tower from the recessed face. The two recessed faces point toward the rotor. Do not hammer through the bearing balls; press the outer race.
3. Bolt the towers to the base loosely. Pass the 8 mm shaft through both bearings, align until it turns freely, then tighten tower bolts.
4. Install the 8 mm clamping hub and rotor at the shaft centre. Rotor runout at its edge must be no more than 0.5 mm by caliper/dial indicator.
5. Install the 60T pulley on the shaft outside the left bearing.
6. Install the NEMA17 mount so its 20T pulley is in the same plane. Fit the GT2 belt and move the motor mount until the belt cannot skip but can still be twisted approximately 90 degrees by two fingers at mid-span.
7. Install the Hall/home sensor where its magnet passes without contact.
8. Install the polycarbonate guard and normally-closed guard switch. Do not energize motion without the guard.
9. Place the TPU base liner into the cassette base. It must sit flat with no wrinkle or debris.
10. Place the inert dummy first, add the TPU lid liner, then the lid. Tighten four M3 screws evenly until the hard PETG faces seat. The hard stop sets compression; do not keep tightening.
11. Put a removable piezo/contact patch through the lid window onto the dummy shell. Use the same small piece of low-residue tape for every run. Route the cable close to the shaft axis with a loose service loop.

## Three required mount indexes

| Index | Mount | Axis parallel to shaft | Gravity sweep |
|---|---|---|---|
| A | Cassette directly on rotor | Pendant thickness | Length and width |
| B | Cassette on 90-degree adapter, long pattern | Pendant long axis | Width and thickness |
| C | Cassette on 90-degree adapter, rotated pattern | Pendant width | Length and thickness |

All three are required. One mount position can miss a part that is free only along the shaft axis.

## Controller wiring

Use `firmware/rattle_cradle_controller/rattle_cradle_controller.ino` and the pin table inside that file. Key rules:

- 12 V adapter to 1 A fuse, then motor driver.
- Common logic ground.
- Set TMC2209 motor current from the actual motor rating; start low.
- Normally-closed guard and stop loop.
- Firmware reverses between approximately -170 and +170 degrees, then pauses for the acoustic sample.

## Fixture qualification

Do this before testing production units:

1. **Empty fixture:** ten runs in each index. Nothing may contact the guard; no fastener may loosen.
2. **Solid dummy:** weight it to the production-unit mass and run ten times per index. Repeat-run peak variation must be 3 dB or less after excluding motor-motion windows.
3. **Known-good golden units:** at least three units, ten runs each. Save their WAV files by serial/index.
4. **Seeded challenge:** put a 2 mm steel bead inside a second inert hollow dummy, not inside a battery product. The analysis must reject it in all relevant axes.

Only after those four gates should `rattle_audio_score.py` be used as an acceptance screen. Investigate a DUT whose pause-window impulse is more than 6 dB above the qualified golden envelope. A failure is quarantined and opened; never “fix” it by tightening the cassette harder.

## Production run

1. Inspect DUT for swelling/damage. Reject damaged units before fixture entry.
2. Record serial, mass and mount index.
3. Seat cassette to hard stop.
4. Close guard.
5. Run ten reversal cycles in A, B and C.
6. Score each WAV against the same mount’s golden WAVs.
7. Pass only if all three mounts pass and there is no audible scrape/click on human review.

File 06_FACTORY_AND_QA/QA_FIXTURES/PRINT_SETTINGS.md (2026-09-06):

# P2S print settings

Use PETG for the structural parts. PLA can crack at the collet fingers, bearing towers and adapter root. The cassette liners are TPU 95A.

## PETG

- 0.20 mm layer height
- 0.42 mm line width with a 0.4 mm nozzle
- 5 walls
- 6 top and 6 bottom layers
- 40% gyroid infill
- Dry filament before printing
- No “sport” or “ludicrous” mode
- Brim on the collet body, latch plate, bearing towers and edge adapter

Orient loaded parts so layer separation does not cross the load:

- Collet body, latch plate, rotor, cassette and pose keys: broad flat face on plate.
- Finger guides and fingers: largest flat face on plate.
- Bearing tower: print on its broad 55 x 78 mm side, then ream/check the bearing pocket.
- Edge adapter: upright as modeled with supports beneath the vertical plate; inspect every gusset layer.
- NEMA mount: broad plate on bed.

## TPU 95A

- 0.20 mm layers
- 3 walls
- 20% gyroid
- Slow external walls
- No support inside the liner cavity

## Mandatory calibration coupons

Before long prints, make simple coupons for:

1. 608 bearing pocket: target 22.2 mm nominal.
2. M4 heat-set insert bore: target 5.2 mm nominal, then use the insert maker’s actual recommendation.
3. Sliding finger: 10.0 mm finger inside 11.6 mm guide channel.

The finger must move under spring force without rocking enough to touch the DUT. Sand only the guide surfaces, never the release tip geometry.

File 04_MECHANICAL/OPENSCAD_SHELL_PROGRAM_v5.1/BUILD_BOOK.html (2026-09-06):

Anticipation Labs · pre-unit sprint · Aug 18 → 27, 2026

# Anticipy Build Book

Three wearable, working pendant pre-units, printed on the P2S, that stream audio, capture offline for 4–8 hours, reconnect, snap onto a charger, and hang on a chain your hands can actually operate. Every number in here was researched or machine-verified today. Nothing is decorative.

Shellv5 flat tag, 33.4 × 80.7 × 16.2 mm (storage build). Click-fit tongue joint. 40/40 machine fit-proofs pass — including the battery-seat defect the July file shipped with (found + fixed today).

MaterialBlack ABS you already own, painted to hand-brushed titanium. Silk PLA is out (sheen dies when sanded, deforms at 55 °C with a LiPo inside a car). PETG is out (CA glue won't bond it).

Offline storageAdafruit 4682 microSD board + 32 GB card. The Omi devkit firmware already contains the entire offline buffer-and-sync stack for this exact board — we port, not write.

ChargingMagnetic snap USB-C tip in the flush port + printed nightstand dock. Zero soldering, zero polarity risk, feels wireless. Bare 3-pin pogo puck = experiment on one shell only.

Chain5 mm stainless curb, 22", threaded straight through the Ø6.4 bail. Magnetic clasp converter at the nape — big hands never touch a lobster clasp again. Magnet-snap bail = experiment on two shells.

100 unitsJLC3DP MJF nylon, dyed black — ≈CAD $1.4–2k landed, ships to buyers mid-October. CNC titanium is the premium path (≈US$4–7.5k, mid-November). Your engraved metal samples cannot hold this battery — confirmed.

## 00 The nine days

Aug 18 (now)

Place the two Amazon orders below. Start the ABS plate printing tonight. Slice check: ABS profile, not PLA.

Aug 19–20

Parts land. Bench-wire SD module to the bare spare XIAO on leads. Build the Omi devkit firmware with the two patches; verify the card mounts and audio/a01.txt grows while BLE is off.

Aug 21

Full offline→reconnect→sync loop on the bench. Decide: Anticipy iOS app speaks the storage service, or demo sync with the stock Omi app.

Aug 22

Wire the real unit(s). Dry click-fit assembly. Run the FULL test gate closed-but-unglued.

Aug 23

Units that pass get acetone-welded shut. Cure 24 h. Print dock cradles + magnet-experiment shells.

Aug 24

Sand seams 220→600. Primer ×2. Metallic coat + steel-wool grain. First clear coat.

Aug 25

Second clear coat. 48-hour cure clock starts. Cut chains, fit nape clasps, thread bails.

Aug 26

4–8 h offline soak test on battery while curing. Yank-power corruption test on the bench mule. Dock metering on every unit.

Aug 27

Run the gate (§09). Wear it to the shop.

One honest risk Everything above is guaranteed-able except one item: the offline-sync firmware port is 2–4 days of real work (the code exists upstream; it must build, flash, and sync against your app). If it slips, the Aug 27 units still stream, charge, and wear perfectly — offline capture follows days later, not weeks. Plan the demo script both ways.

## 01 Order right now — Amazon.ca

Two carts. Everything must show delivery on or before Aug 25 at checkout — if a listing slips, use its alternate. Aerosols sometimes ship ground-only: if a spray can shows late, buy the same can at Canadian Tire tomorrow instead.

### Cart A — the build cannot proceed without these

Part | Why | Price | Link
Adafruit 4682 3V microSD breakout | THE storage board. Pure 3.3 V — the common blue modules have 5 V level shifters and silently fail on battery. ~18×18 mm, fits the shell pocket. | ~$12 | B09K6XVS9R (https://www.amazon.ca/Adafruit-4682-Micro-SDIO-Breakout/dp/B09K6XVS9R) · alt (https://www.amazon.ca/4682-Micro-SDIO-Breakout-Board/dp/B09PGBQDWF)
WWZMDiB 3.3 V mini SD modules, 6-pack | Spares + units 2 and 3. Check the photo shows NO 8-pin shifter chip. | ~$14 | B0BV8ZQ81F (https://www.amazon.ca/WWZMDiB-Module-Adapter-Memory-Shield/dp/B0BV8ZQ81F)
SanDisk Ultra 32 GB microSDHC | 278 h of audio per card. Buy a 2-pack. | ~$15 | pick Prime listing (https://www.amazon.ca/s?k=sandisk+ultra+32gb+microsd)
Magnetic USB-C snap adapter, 2-pack | The charging system. Tip lives in the pendant's flush port; cable snaps on magnetically. | ~$20 | B0FPQ8KTB4 (https://www.amazon.ca/USB-Magnetic-Adapter-240W-2Pack/dp/B0FPQ8KTB4) · right-angle alt (https://www.amazon.ca/Magnetic-Adapter-Connector-Transfer-Compatible/dp/B0B3XFJM96)
5 mm stainless curb chain, 16.5 ft roll | Cut eight 22" chains — every prototype chained for the price of one retail chain. | $27.99 | B0CHHP74MV (https://www.amazon.ca/dp/B0CHHP74MV)
Finished 5 mm Cuban chain, 22" | Wear-test control with a factory clasp. Fastest arrival (Aug 19). | $11.89 | B09DYL4MWF (https://www.amazon.ca/dp/B09DYL4MWF)
AIEX magnetic clasp converters, 12 pcs | Snap-together necklace closure at the nape. This alone solves the big-hands clasp problem. | $9.89 | B0B4D2NXMH (https://www.amazon.ca/dp/B0B4D2NXMH)
Gorilla Super Glue Gel 20 g | Instant-grab bond; bonds ABS properly (this is why PETG lost). | ~$9 | B00OAAUAX8 (https://www.amazon.ca/Gorilla-7700104-Super-Glue-Gel/dp/B00OAAUAX8)
100% pure acetone, 1 L | Solvent-welds the ABS halves into one part + seam slurry. Must say 100% — nail remover won't weld. | ~$15 | pick Prime listing (https://www.amazon.ca/100-acetone/s?k=100%25+acetone) (or Canadian Tire today)
Rust-Oleum 2-in-1 Filler & Sandable Primer | Kills layer lines under the metal coat. | ~$17 | B006ZLQ4HQ (https://www.amazon.ca/Rust-Oleum-Automotive-260510-12-Ounce-Sandable/dp/B006ZLQ4HQ)
Rub 'n Buff Silver Leaf + a tube of Ebony | The titanium look. Silver cut with a touch of black = titanium's darker warmth. | ~$12 ea | pick Prime listing (https://www.amazon.ca/s?k=rub+n+buff+silver+leaf)
Krylon COLORmaxx SATIN Crystal Clear | Mandatory seal — Rub 'n Buff rubs off on skin without it. Satin, not gloss: titanium is satin. | ~$14 | pick Prime listing (https://www.amazon.ca/s?k=krylon+colormaxx+satin+crystal+clear)
30 AWG silicone wire kit (6 colors) | The six SD lines. Silicone insulation won't melt while soldering next to the battery. | ~$16 | pick Prime listing (https://www.amazon.ca/s?k=30+awg+silicone+wire+kit+6+colors)
Capacitor kit incl. 100 µF + 0.1 µF | Decoupling at the SD module — SD write bursts + BLE TX can brown-out the radio without it. | ~$15 | pick Prime listing (https://www.amazon.ca/s?k=electrolytic+ceramic+capacitor+assortment+kit)
Adhesive EVA foam, 1–2 mm sheet | The padding you asked for — lines both bays, kills rattle, cushions the cell. | ~$12 | pick Prime listing (https://www.amazon.ca/s?k=adhesive+eva+foam+sheet+2mm)
0000 steel wool | The single-direction graining pass that sells "hand-brushed". | ~$10 | pick Prime listing (https://www.amazon.ca/s?k=0000+super+fine+steel+wool) (or Canadian Tire)

### Cart B — the two experiments

Part | Why | Price | Link
1N5819 Schottky diodes, 20 pcs | MANDATORY for the pogo experiment — a reversed magnetic mate without it permanently kills the charge chip. | $7.99 | B07RL3SCL4 (https://www.amazon.ca/dp/B07RL3SCL4)
Magnetic pogo pin pairs w/ location hole, 2 pairs | Embedded-puck charging experiment (one shell). | $15.99 | B0F52FJRTQ (https://www.amazon.ca/dp/B0F52FJRTQ)
JHYOSSTHI round magnetic pogo, 3-pin | The "three-prong" smartwatch-puck look. Pick the 3Pin variant on the page. | $15.99 | B0F6L8HWM3 (https://www.amazon.ca/dp/B0F6L8HWM3)
9×3 mm neodymium discs, 50-pack | Magnet-snap chain experiment. Sized up because Amazon packs rarely state N-grade. | ~$15 | B0F186MZN6 (https://www.amazon.ca/dp/B0F186MZN6)
6×3 mm discs, 60-pack | Lighter variant test. | ~$12 | B0F183S6QK (https://www.amazon.ca/dp/B0F183S6QK)
10 mm × 1.4 mm stainless jump rings | Heavy-duty rings for the magnet-barrel and any bail rework. | ~$10 | B0844RWPSH (https://www.amazon.ca/dp/B0844RWPSH)

Done when both carts show ≤ Aug 25 delivery at checkout and are placed.

## 02 Print tonight

Step 0 — the 10-minute coupon (added Aug 19, after the Devin-night print). Print COUPON_FIRST.3mf first, same ABS filament and same profile as the plate below. It is four thumb-size slices of the real click joint: one tongue piece and three groove pieces at 0.16 / 0.22 / 0.28 mm clearance (count the little edge notches: 1 = 0.16, 2 = 0.22, 3 = 0.28). Press the tongue piece into each groove piece. The snuggest one that still clicks fully home by hand is this printer's number. If it's 0.16 (1 notch) — print the plate below unchanged. If it's 0.22 or 0.28, regenerate the six halves first with -D LIP_CLR_OVERRIDE=0.22 (or 0.28) and rebuild the plate — one command per half, ~5 minutes total. This is what makes "the halves will click" a measured fact instead of a hope.

Open ~/Desktop/anticipy-shell/PRINT_ME_v5_3pendants.3mf in Bambu Studio. It holds six halves = three pendants: V1-STORAGE (the unit), V2-STORAGE-ROOMY (fit insurance), V1-standard (thin control, 12.6 mm).

- Filament: your black ABS — select the ABS filament profile so the chamber flaps stay closed. AMS not needed (single material).
- Plate: Textured PEI, 90–100 °C bed, thin glue-stick film. Nozzle 265 °C.
- Process: 0.12 mm layers, 4 walls, 25–40% gyroid, Arachne on, seam Back/Aligned, elephant-foot compensation 0.15 mm, 5 mm brim, part fan ≤30%, aux fan OFF, door + lid closed.
- Halves lie exactly as arranged — flat face down, no supports, don't rotate anything.
- ABS makes styrene fumes: ventilated room, carbon filter on.

Why not the silver silk PLA you bought for this: its chrome sheen is destroyed by the sanding the seam needs, it strings on fine text, and PLA softens at 55 °C — a parked car kills a LiPo-carrying PLA pendant. The black ABS + paint stack in §07 looks more like the website's titanium, not less.

Done when the coupon has named a clearance, six halves (at that clearance) are off the plate with clean USB openings (one pass of a needle file), and the click joints snap shut dry.

## 03 Wiring — the diagram

The whole electrical build: the battery is already done; the six SD lines are the only required soldering; charging needs none at all.

- Solder-near-LiPo SOP: kapton over the pouch, never rest the iron near it, heat-shrink every joint, and before every power-up: continuity-check 3V3↔GND and 5V↔GND for shorts.
- Bench first: wire the SPARE XIAO + SD module on loose leads and prove firmware BEFORE touching the good soldered unit.
- D7 stays free. The old assumption that CS lives on D7 is wrong — stock firmware uses D0.

Done when the bench mule mounts the card and audio/a01.txt grows with BLE off.

## 04 Battery map

Why the SD card is non-negotiable and the battery is not the constraint. The website's "3-day battery" is honest for mixed daily use; continuous streaming is 25–30 h.

- Cell: BLL 752042 · 3.7 V · 500 mAh · 1.85 Wh · max 8.0×20.5×43 mm; the shell bay allows 10% swelling headroom.
- Prototype accepts ~0.5–1 mA SD idle (VCC tied to 3V3). Production re-adds the power-gate on D1 + P-MOSFET.
- Charge at 16 kbps offline if configurable: halves both the storage AND the hour-long worst-case BLE sync drain.
- LiPo rules: mic hole stays open (it's the vent), no charging in a hot car or direct sun, first full charge attended.

## 05 Firmware — port, don't write

The offline system already exists in BasedHardware/omi → firmware/devkit, targeting this exact board: when BLE drops, Opus packets append to audio/aXX.txt on the SD card; a GATT storage service streams files back with offset-resume, then deletes on ack. The Omi app has the sync screen. Your slim dual-hatch build has this deliberately disabled (CONFIG_SPI=n, CONFIG_FAT_FILESYSTEM_ELM=n).

1. Patch 1 (mandatory): the devkit gates SD power via P0.19, which the XIAO doesn't break out. Stub the enable-GPIO in sdcard.c and tie module VCC to 3V3.
2. Patch 2 (mandatory): drive P0.13 as gpio output-low at boot → 100 mA charge. Skipping it silently doubles charge time.
3. Check 3: confirm the Opus bitrate is configurable and set 16 kbps for offline capture; if not, 32 kbps still fits the card easily.
4. Build for the XIAO Sense target, flash the BENCH mule (1200-baud touch or double-tap RST — both proven on your hardware), verify mount + file growth offline, then the full sync loop against the app.
5. App decision by Aug 25: if the Anticipy iOS app doesn't speak the storage service (302957…5781/5782), demo offline sync with the stock Omi app and port the client next sprint (+2–3 days).
6. Torture pass: yank power mid-write (FATFS batching bounds the loss — verify), and >2 disconnect cycles so file rollover + app drain both prove out.

Done when the mule survives: record 30 min offline → reconnect → full sync → audio decodes → file deleted.

## 06 Assemble — test before you glue

The v5 shell CLICK-CLOSES and holds. That means the complete unit gets fully tested while still openable. Nothing is welded until it has already proven itself. That is the zero-failure mechanism.

1. Clip the header pins flush (glasses on — pins fly). Kapton over the stubs and the battery pouch.
2. Line both bays with 1–2 mm adhesive EVA. Battery into the back-half bay on foam, wire-end toward the board. Wires must NEVER cross in the closing channel — fold the upper-pad wire with a 2 mm sideways jog, kapton the fold.
3. SD module lies flat on the battery's face in its pocket (storage halves have the depth for it), caps across its power pins, leads dressed through the tunnel.
4. Board into the front half nose-first at ~15° tilt, USB nose leading into the port hole, then flat onto the shelf. Sanity check: RST sits toward the bail, LEDs visible — the amber glow through the front dot is your product LED, exactly like the website's.
5. Seat the magnetic USB-C tip into the flush port from outside.
6. Click shut. Run the whole gate (§09) now, unglued. Anything fails → pop it open, fix, repeat.
7. Only after a full pass: open, thin acetone coat on both rims (or CA gel), close, rubber-band, wiggle a waxed jig cable in the port at 2 min so nothing bonds to it. Cure 24 h. Fill the seam with acetone+ABS slurry.

Done when a welded unit re-passes the gate after 24 h cure.

## 07 The titanium finish

1. Sand the seam 220 → 320 dry, then 400 → 600 wet, over the whole body. Mask the mic dot (toothpick) and the port (tape) through every step from here.
2. Primer ×2, wet-sand 400 between coats.
3. Metal: Rub 'n Buff Silver Leaf cut with a touch of Ebony, rubbed and buffed. (Backup: Rust-Oleum Metallic Aluminum, 2 light coats.)
4. Grain: 0000 steel wool, straight single-direction strokes along the long axis only. This is the stroke that reads "machined".
5. Seal: Krylon SATIN clear ×2 — mandatory on skin. Cure 48 h before anyone wears it.
6. No acetone vapor, no heat — both would erase the debossed wordmark.

Done when a stranger at the shop asks where you bought it.

## 08 Chain + the two experiments

- Every demo unit: 22" cut from the curb roll, threaded straight through the Ø6.4 bail (5 mm curb passes; no jump ring needed), AIEX magnetic converter closing it at the nape. On, off, one hand, eyes closed.
- Experiment A — magnet-snap bail (2 shells): Ø9.2×3.4 mm glue-in pockets, one 9×3 disc in the pendant top, mate disc in a tiny printed barrel on the chain end. Sharpie polarity on the stack BEFORE separating discs. Layout keeps the magnet >10 mm from the BLE antenna — verified in CAD. Bench-test pull with a luggage scale; expect ~1 kg+ axial. Snag = breakaway (feature and risk).
- Experiment B — embedded pogo puck (1 shell): when the pucks arrive Aug 19–20, measure with calipers and I'll cut the parametric pocket + reprint that back half same-day. Diode rules per §03.

## 09 The gate — what "working pre-unit" means

One unit passes when ALL of these are true, in one continuous session, on battery:

- ☐ Click-assembled (or welded) with padding — nothing rattles when shaken next to your ear.
- ☐ Advertises, pairs, streams live audio to the app; amber dot glows through the front.
- ☐ Phone leaves for 30+ minutes → pendant keeps capturing to SD.
- ☐ Phone returns → sync completes untouched; the captured audio plays and is intelligible.
- ☐ Snap-charges on its dock; charge current confirmed ≥90 mA (USB meter).
- ☐ Worn for a full day on the chain: clasp operable one-handed, no skin complaints, no edges.
- ☐ Survives the drop test: chest height onto wood, three orientations, still passes the above.

Truth in demos Pre-units are painted ABS at ~40 g, not 8 g titanium; charging is magnetic contact, not 15-ft over-the-air; "3-day battery" = mixed use, not 72 h streaming. Say so to anyone who handles one — the site's claims stay roadmap, the pre-unit proves the system. (Qi coils physically don't fit this shell width; true over-the-air charging is B2B-only tech in 2026.)

## 10 The 100-unit path (decide by Sept 1)

Plan | What | Cost, landed | Buyers get units | Verdict
1 · MJF nylon | JLC3DP MJF PA12, dyed black, bead-blasted. Sample 5 by Sept 1 → 100-unit order by Sept 15. | ≈ CAD $1.4–2k | mid-October | The move. Production look at one-tenth the metal price.
2 · CNC titanium | China CNC Gr2/Gr5 via JLCCNC/PCBWay, bead-blast + laser engrave. RFQ Sept 1, approve sample by Oct 1 — zero slack for a second loop. | ≈ US$4–7.5k | mid–late Nov | Matches the "machined titanium" promise. Run it in parallel for the metal-first buyers if cash allows.
3 · Stamped stainless | New 61 mm-class deep-draw tooling, ~US$2–8k tooling + $2–5/unit. | tooling-gated | Nov | Only if the titanium framing flexes. Ask your metal-sample vendor what a 61×27 version of their tool costs — if under ~$3k this reopens cheaply.

- Your engraved metal samples: beautiful, and physically cannot hold the 43 mm battery — they're look-references, not tooling. (Do email that vendor the two questions above this week.)
- Production electronics: copy Omi DevKit2 — solder an 8 GB SD-NAND on the custom PCB, same SPI interface, zero firmware change from your prototypes.
- Blocker to close before any metal order: metal shells + wireless charging are in direct conflict (a shell that blocks and heats coils). Contact charging or a plastic charging window — decide at CAD freeze.
- Assembly at 100: ~10–15 min/unit, 4 printable jigs (solder fixture, 10-up glue cradle, charge-test station, packout tray). Print the jigs while waiting for parts.

## 11 Files + one favor

- COUPON_FIRST.3mf the 10-min click-fit coupon (print first) · PRINT_ME_v5_3pendants.3mf the plate · stl_v5/ halves + coupons + a 200 mAh bonus pair · pendant.scad parametric source (v5.1) · pendant_v4_shipped_backup.scad the pre-fix file
- Every fit is machine-proven: 40/40 test_* exports empty across all variants — including the battery-seat defect that the July files shipped with, now fixed. If you printed the July plate: those shells will jam the battery ~1 mm short. Print v5.
- The favor (30 seconds, not blocking): put a ruler on one metal sample half — length and width in mm — and tell me the numbers. It pins the production CAD to reality instead of my photo estimate (~35–40 × 22–28 mm).

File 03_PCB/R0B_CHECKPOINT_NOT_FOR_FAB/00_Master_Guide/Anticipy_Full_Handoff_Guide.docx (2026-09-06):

ENGINEERING RELEASE GUIDE

Anticipy Hardware Handoff

Custom PCB EVT R0B

One controlled package for electrical, mechanical, firmware, manufacturing and final assembly

Release ANT-PROD-R0B-EVT-HANDOFF-2026-08-29

Prepared August 29, 2026

FABRICATION BLOCKED

The source is editable and useful, but 176 PCB connections remain unrouted. The battery, final enclosure and production firmware are also not released.

Release: ANT-PROD-R0B-EVT-HANDOFF-2026-08-29

## 1. What this package is

This package gives a senior electrical engineer, mechanical designer, firmware engineer, PCBA factory, and final assembler one controlled source of truth for turning the Anticipy custom-PCB concept into working EVT units.

It includes the editable KiCad project, custom footprints, draft BOM, pin map, verified board outline, provisional board-only STEP/DXF, engineering scope, manufacturing RFQs, firmware requirements, assembly plan, QA gates, and ready-to-send messages.

It does not pretend unfinished items are finished. The board is not fabrication-ready, the battery is not selected, and the final enclosure CAD and firmware binary do not exist yet.

## 2. Plain-English definitions

- PCB: the bare green circuit board.
- BOM: bill of materials, meaning the shopping list of electronic parts.
- PCBA: the PCB after the electronic parts have been soldered onto it.
- Schematic: the electrical map showing what connects to what.
- PCB layout: the physical placement and copper traces on the board.
- Gerbers: factory images of every PCB layer.
- Drill files: instructions for every plated hole, slot, and non-plated cut.
- CPL or pick-and-place file: the X/Y position, rotation, and side for every machine-placed part.
- STEP: a 3D CAD model used for collision and enclosure design.
- DXF: a 2D cutting profile, often used for sheet metal or outline transfer.
- EVT: engineering validation test, the first hardware revision used to prove the design works.

The PCB is not the BOM. The BOM is not the enclosure. The PCBA factory does not automatically create a finished pendant.

## 3. Frozen product intent

Anticipy is a camera-free wearable Bluetooth audio pendant. The device is intended to record ambient audio, store audio when offline, transfer live and stored data to an iPhone, indicate state using a tiny red/blue light, provide haptic feedback, detect motion/wear state, and support secure reset and factory programming.

Requirement | Frozen target
Finished exterior | 51.0 x 21.0 x 11.0 mm maximum
Shape | Rounded capsule with proportions similar to PLAUD NotePin S; no copied private CAD
Mass | Target under 20 g
Centre structure | Polycarbonate
Front and rear faces | 0.60 mm brushed 5052-H32 aluminum
Radio region | Polycarbonate only over antenna; no metal, battery, motor, magnet, chain hardware, or conductive coating
Camera | None
PCB | 45.8 x 18.0 mm current outline; 4-layer; 0.80 mm production target

## 4. Current electrical architecture

The R0B design uses:

- Raytac MDBT50Q-1MV2 nRF52840 radio/processor module.
- Nordic nPM1300 charger and power-management IC.
- Two Same Sky PDM microphones.
- Macronix 4-Gbit SLC serial NAND.
- ST LIS2DW12 accelerometer.
- USB-C with data, CC, and VBUS protection.
- Red/blue status LED, user button, haptic driver, factory pogo pads, battery lands, and motor lands.

The battery is a placeholder only. The required pack must be protected, three-wire, include a 10 kohm NTC, and fit within a maximum installed envelope of 26.0 x 15.5 x 4.8 mm including protection, insulation, folded tabs, tolerance, and swelling allowance.

## 5. Honest engineering status

The automated R0B verifier reports:

- 4 copper layers.
- 45.8 x 18.0 mm geometric outline.
- 70 electrical references.
- 223 source-of-truth pins checked.
- 0 geometric DRC violations.
- 176 unrouted PCB connections.
- 0.50 mm provisional battery-to-antenna gap.
- 2.00 mm conservative motor-to-antenna gap.

Therefore, this is a strong starting package, not a factory release.

## 6. Who does what

### Senior PCB engineer

The senior PCB engineer owns the electrical design until a release package exists. They must review every symbol and footprint, reconcile the 0.80/0.82 mm thickness issue, select or approve the exact battery, manually complete routing, review the nPM1300 loops against Nordic's reference, obtain the fabricator's impedance stack-up, run final ERC/DRC/net-equivalence checks, create a PCBA STEP, generate manufacturing outputs, and support first-board bring-up.

### PCBA factory

The factory supplies or fabricates the bare PCB, sources approved SMT parts, prints solder paste, places components, reflows, inspects, programs/tests if quoted, and returns assembled PCBAs. The factory should build exactly two first articles and hold the other ten until written release.

### Mechanical CAD engineer

The mechanical engineer designs the polycarbonate centre, aluminum faces, button actuator, light pipe, microphone acoustic wells, USB opening, battery retention, motor retention, chain/bail interface, sealing, and assembly strategy around the released PCBA STEP and exact battery STEP.

### Final integration technician

The final technician receives tested PCBAs, batteries, motors, enclosure parts, firmware, assembly drawings, adhesives, insulation, acoustic mesh, and QA forms. They install the rear hand-solder parts, insulate and strain-relieve them, close the enclosure, cure adhesives, and run sealed-unit tests.

## 7. What each recipient receives

### PCB engineer package

- Native KiCad .kicad_pro, .kicad_sch, .kicad_pcb, and .kicad_dru.
- Custom .pretty footprint library and fp-lib-table.
- Draft BOM, pin map, pad/net report, verifier, design generator, requirements, placement plan, stack-up request, and current DRC report.
- Nordic nPM1300 reference-layout archive.
- Exact scope of work and release checklist.

### Mechanical CAD package

- Product envelope and material strategy.
- Provisional board-only STEP and board-outline DXF.
- PCBA placement image and interface requirements.
- Required CAD deliverable list.

The provisional files are for early packaging studies only. The final enclosure must use the engineer-released PCBA STEP and exact battery STEP.

### PCBA factory package

Before release, the factory may receive only the RFQ and stack-up request. After release, it receives one locked ZIP containing Gerbers, drills, BOM, CPL, assembly drawings, fab drawing, stack-up, IPC-356, schematic PDF, PCBA STEP, programming instructions, firmware hash, and first-article test plan.

### Final assembly package

- Released PCBA and battery STEP files.
- Complete enclosure STEP and exploded STEP.
- Polycarbonate production STEP/3MF.
- Aluminum front/rear/marking DXFs.
- Mechanical BOM.
- Adhesive and cure specification.
- Assembly traveler.
- Firmware and test instructions.
- Per-unit serial and QA record.

## 8. Materials and who supplies them

The pendant is a sandwich:

1. A 0.60 mm brushed 5052-H32 aluminum front face.
2. A polycarbonate centre frame that holds and electrically isolates the hardware.
3. The tested PCBA, protected battery, motor, insulation, foam, light pipe, and acoustic mesh.
4. A 0.60 mm brushed 5052-H32 aluminum rear face.
5. A polymer-only radio zone over the antenna.

You do not normally ship raw aluminum to the PCB engineer. The engineer specifies interfaces. The metal shop normally supplies certified aluminum sheet and cuts it from released DXFs. The PCBA factory supplies PCB laminate, copper, solder mask, finish, stencil, paste, and approved SMT parts unless the purchase order says Anticipy will consign a part. Anticipy should consign the exact approved battery and haptic motor for the first batch.

## 9. Seven-day rush attempt

The seven-day clock is a target, not a promise.

Day | Required outcome
Day 0 | Hire PCB lead; send RFQs; freeze decision owner; select battery candidate; reserve factory capacity
Day 1 | Complete schematic/footprint review, routing, stack-up negotiation, mechanical interface review, and release-candidate checks
Day 2 | Release manufacturing package only if every gate passes; factory starts two first articles; mechanical CAD continues around released PCBA
Day 3 | Fabrication/assembly; firmware bench image and pogo fixture ready; enclosure prototypes printed
Day 4 | Bring up FA-001 and FA-002; measure rails; program; test USB, BLE, microphones, storage, motion, LED, and haptic
Day 5 | If both pass, release remaining ten PCBAs; freeze enclosure and cut/print parts
Day 6 | Integrate and seal first two complete pendants; run acoustic/RF/charge/runtime tests
Day 7 | Finish remaining units only if the first two sealed units pass; serialize, clean, and package

One to five working EVT units in a week may be possible with immediate engineering and a first-spin success. Ten polished sealed units in one week cannot be guaranteed.

## 10. Release sequence

The only safe sequence is:

1. Engineering release candidate.
2. Zero unconnected items and zero unresolved DRC errors.
3. Fabricator-reviewed 0.80 mm stack-up and 90-ohm USB geometry.
4. Exact battery approved.
5. Manufacturing package checksummed and signed.
6. Two first articles manufactured.
7. Both pass Gate A bench testing.
8. Written RELEASE REMAINING TEN approval.
9. Two sealed first articles pass Gate B.
10. Customer release.

## 11. Immediate owner actions

- Send the complete ZIP to one accountable senior PCB engineer.
- Send the factory RFQ immediately, but do not issue fabrication files or a purchase order.
- Make battery selection the first engineering decision.
- Assign one mechanical CAD owner and one firmware/bring-up owner.
- Reserve access to a current-limited bench supply, oscilloscope, DMM, SWD programmer, USB test host, BLE phone, audio stimulus, and pogo fixture.
- Use the project-control workbook to record one owner and deadline for every open gate.

## 12. What is deliberately missing

The following files cannot honestly be supplied yet because the design has not reached that stage:

- Released Gerbers and drills.
- Released BOM and CPL.
- Final PCBA STEP with all components.
- Exact battery STEP and approved battery MPN.
- Final enclosure STEP, production 3MF, and aluminum DXFs.
- Production firmware binary and SHA-256.
- Final programming fixture drawing and test software.

Their required filenames and acceptance rules are included so the responsible engineer knows exactly what must be produced.

APPENDIX A

Open items and decisions

## P0 - blocks fabrication

Decision/item | Required evidence | Owner | Status
Exact battery | MPN, max drawing/STEP, protection, 10k NTC, polarity, limits, UN38.3, IEC 62133 evidence, MSDS, sample, stock | PCB lead + Anticipy | Open
Complete PCB routing | Zero unconnected items and reviewed routes | PCB lead | 176 open connections
PMIC review | Schematic and layout signed against Nordic reference | PCB lead | Open
0.80 mm stack-up | Fabricator drawing, Dk, copper, dielectric, USB geometry | PCB lead + factory | Open
Thickness discrepancy | Explain/resolve 0.80 mm target versus 0.82 mm board-only STEP | PCB lead + mechanical | Open
Final PCBA STEP | All maximum-height components and interface bodies | PCB lead | Open
Factory package | Gerbers, drills, IPC-356, BOM, CPL, drawings, checksums | PCB lead | Open

## P0 - blocks first-article bring-up

Decision/item | Required evidence | Owner | Status
Production/factory firmware | Reproducible source, binary, hash, flash/verify commands | Firmware lead | Open
NAND plan | ECC, bad blocks, filesystem, recovery and secure erase proven | Firmware lead | Open
Pogo fixture | Drawing, pin map, programmer and test connections | PCB + firmware | Open
Numeric test limits | Rail, ripple, current, audio, RF, thermal and runtime limits | PCB + firmware | Open

## P1 - blocks sealed units

Decision/item | Required evidence | Owner | Status
Final enclosure | STEP, 3MF, DXFs, drawings, mechanical BOM | Mechanical lead | Open
Acoustic system | Mesh, port geometry, adhesive keepout, test limits | Mechanical + audio | Open
Antenna system | Polymer-only region and sealed-unit RF acceptance | PCB + mechanical | Open
Adhesive/seal process | Exact product, pattern, cure, rework and inspection | Mechanical + assembler | Open
Final integration owner | Named local technician, equipment, schedule and cost | Anticipy | Open

## Decision log template

For every choice, record:

- Decision ID and date/time.
- Exact part/file/revision.
- Options considered.
- Evidence and test result.
- Decision and owner.
- Downstream files that must be updated.
- Whether a new revision/checksum is required.

APPENDIX B

Seven-day rush plan

## Goal

Attempt to produce 12 custom-PCB EVT assemblies, with two first articles built and tested before the remaining ten. The practical success target is one to five working units in seven days. Ten sealed and polished units remain schedule-risky because revision-one PCB, battery, firmware, and enclosure work are still open.

## Staffing

- One accountable senior PCB engineer.
- One firmware/bring-up engineer.
- One mechanical CAD engineer.
- One PCBA factory project owner.
- One final integration technician; two stations preferred after first-article release.
- One Anticipy decision owner who can approve or stop work immediately.

## Schedule

Day | PCB/electrical | Mechanical | Firmware/test | Manufacturing/integration
0 | Engineer accepts scope; review blockers | Start packaging study | Freeze bring-up plan | Send RFQs; reserve capacity
1 | Battery decision; footprint review; complete routing; DRC/net checks | Develop centre/face concepts around provisional geometry | Create minimal bench image, self-tests, SWD plan | Factory returns stack-up, geometry, stock and schedule
2 | Release only if all Gate 0 checks pass | Update from released PCBA STEP and battery | Release hashed FA firmware/test instructions | Start two first articles; print enclosure prototypes
3 | Support DFM/CAM and answer exceptions | Fit/tolerance review | Prepare fixture, scripts, iPhone/BLE tools | Fabricate/assemble FA-001/FA-002
4 | Lead current-limited bring-up | Correct mechanical issues found | Test rails, USB, BLE, audio, storage, motion, LED, haptic | Factory supplies inspection evidence
5 | Close faults or issue remaining-ten release | Freeze enclosure after FA evidence | Freeze passed firmware hash | Assemble remaining ten only if both FAs pass
6 | Support integration faults | Produce/finish parts | Sealed-unit regression | Integrate two sealed first articles
7 | Final disposition | Final mechanical corrections | Overnight/runtime/backfill review | Integrate remaining passed units, serialize, clean, package

## Daily decision gates

- End of Day 1: Can the board be released without waivers?
- End of Day 2: Did the factory accept the exact technology and files?
- End of Day 4: Did both open-board first articles pass?
- End of Day 6: Did both sealed first articles pass?

If any answer is no, preserve the hardware and continue the EVT correction loop. Do not convert an engineering failure into a pass to protect the calendar.

APPENDIX C

File dictionary

## Files present now

File/type | Meaning | Primary user | Status
.kicad_pro | KiCad project settings | PCB engineer | Editable WIP
.kicad_sch | Electrical schematic | PCB engineer/firmware | Editable WIP
.kicad_pcb | Board outline, placement and future routing | PCB engineer | Editable WIP, unrouted
.kicad_dru | PCB design rules | PCB engineer | WIP
.pretty/*.kicad_mod | Custom footprints | PCB engineer/assembler | Must be verified
BOM_DRAFT_DO_NOT_PROCURE.csv | Draft part list | PCB engineer/procurement | Not procurement-released
pad_net_report.csv | Pin/net cross-check data | PCB engineer | Engineering reference
verify_project_r0b.py | Structural/release verifier | PCB engineer | Reports 176 unrouted items
placement.png/.svg | Visual component placement | All engineering roles | Provisional
PROVISIONAL_BOARD_ONLY.step | 3D bare-board solid only | Mechanical engineer | Provisional, 0.82 mm export
PROVISIONAL_BOARD_OUTLINE.dxf | 2D board outline | Mechanical engineer | Provisional

## Files that must be created before fabrication

Required file | What it does | Creator
Release README with checksums | Locks revision and file set | PCB engineer
Gerber ZIP | Defines every manufactured PCB layer | PCB engineer
PTH/NPTH drill ZIP | Defines holes and slots | PCB engineer
Fabrication drawing | Defines material, finish, tolerances, impedance and notes | PCB engineer
Approved stack-up | Defines real four-layer construction and USB geometry | Factory + PCB engineer
Released BOM | Controls procurement and substitutions | PCB engineer/procurement
CPL CSV | Controls placement X/Y/rotation/side | PCB engineer
Assembly drawings | Controls orientation and special process | PCB engineer
IPC-356 | Electrical netlist for CAM/test | PCB engineer
PCBA STEP | Enables component collision review | PCB engineer
Programming/test package | Controls firmware and factory test | Firmware + PCB engineer

## Files that must be created before enclosure/tooling release

Required file | What it does | Creator
Exact battery STEP/drawing | Controls battery fit and safety | Battery supplier + engineer
Enclosure assembly/exploded STEP | Controls complete mechanical fit | Mechanical engineer
Polycarbonate centre STEP/3MF | Controls structural centre | Mechanical engineer
Aluminum front/rear DXF | Controls sheet cutting | Mechanical engineer
Marking DXF | Controls ANTICIPY mark | Mechanical engineer
Mechanical drawing/BOM | Controls materials, tolerances and parts | Mechanical engineer
Assembly traveler | Controls sequence, adhesive, cure and inspection | Mechanical + final assembler

## What to send when

- Send the entire ZIP now to the accountable PCB engineer.
- Send the master guide, mechanical folder and placement files now to the mechanical engineer.
- Send RFQs now to factories for capacity review only.
- Send final manufacturing outputs only after Gate 0 is signed.
- Send final assembly outputs only after both open-board first articles pass.

APPENDIX D

PCB engineer scope

## Assignment

Take ANT-PROD-R0B from engineering work-in-progress to an EVT fabrication release for 12 PCBAs, with a mandatory hold after two first articles.

## Starting point

- Editable KiCad schematic and PCB.
- Custom footprint library.
- 45.8 x 18.0 mm outline.
- Four-layer 0.80 mm target stack.
- 70 references and 223 checked design pins.
- 176 unrouted PCB connections.
- Draft BOM, pin map, requirements, placement plan, and Nordic reference archive.

## Required work

### Electrical review

- Review every schematic symbol, pin number, power pin, no-connect, polarity, and net label against the current manufacturer datasheet.
- Verify every footprint land pattern, exposed pad, paste aperture, maximum height, microphone port, USB shell slot, LED orientation, and module antenna keepout.
- Confirm the nPM1300 configuration, NTC circuit, buck startup values, charge limits, high-current grounds, and net ties against Nordic's reference.
- Confirm USB-C CC behavior, ESD topology, VBUSOUT connection, 27-ohm series resistors, and D+/D- polarity.
- Confirm the raw NAND choice is acceptable for the firmware schedule. If not, propose a lower-risk soldered storage part with a documented size, power, and firmware tradeoff.

### Mechanical and sourcing decisions

- Select or approve the exact protected three-wire battery before release.
- Obtain its maximum-tolerance STEP/drawing, protection details, NTC curve, polarity, voltage/current/temperature limits, UN38.3, IEC 62133 evidence, MSDS, lot traceability, and stock confirmation.
- Reconcile the KiCad 0.80 mm target with the board-only STEP export that measures 0.82 mm.
- Review the battery, motor, USB, button, LED, microphone, pogo, and antenna interfaces with the mechanical engineer.

### Layout completion

- Preserve an uninterrupted L2 ground reference.
- Keep all copper, components, and vias out of the Raytac all-layer antenna keepout.
- Route and review every connection manually; do not accept an autorouter result without net-by-net review.
- Keep nPM1300 switch loops and bypass paths compact and faithful to Nordic guidance.
- Route USB D+/D- as a controlled 90-ohm differential pair using the fabricator-approved stack-up and geometry.
- Review return paths, stitching, current density, via sizes, thermal reliefs, exposed pads, acoustic clearance, ESD placement, and test access.
- End with zero unconnected items and zero unresolved DRC errors.

### Release outputs

Produce:

1. Complete editable KiCad project.
2. Final released schematic and PCB.
3. Footprint and symbol verification record.
4. ERC, DRC, net-equivalence, and unconnected-item reports.
5. Gerber X2/RS-274X ZIP.
6. Separate PTH and NPTH Excellon drill ZIP plus drill map.
7. IPC-356 netlist.
8. Released BOM with approved alternates and DNI flags.
9. CPL/pick-and-place file with origin and rotation convention.
10. Fabrication drawing and approved stack-up drawing.
11. Top and rear assembly drawings.
12. Full PCBA STEP model with maximum-height bodies.
13. SWD/programming/test-pad drawing.
14. Manufacturing README with SHA-256 checksums.
15. Bring-up support for FA-001 and FA-002.

## Acceptance gates

No release until:

- Battery and enclosure interfaces are physically reviewed.
- The fabricator approves the exact 0.80 mm stack, minimum drill/pad, USB slots, controlled-impedance geometry, and rush schedule in writing.
- Every part is available, approved, or explicitly consigned.
- Zero unrouted connections remain.
- Zero unresolved ERC/DRC/net-equivalence issues remain.
- PMIC, USB, RF, acoustic, thermal, and manufacturing reviews are signed.
- Output files are regenerated from the final native source and checksummed together.

## Required response from candidate engineer

Confirm:

- Relevant nRF52/nPM1300, USB, RF module, compact wearable, and KiCad experience.
- Who personally performs layout and review.
- Start time and committed 24-36 hour engineering sprint availability.
- Availability for first-board bring-up.
- Fixed or capped estimate and what would stop the sprint.

APPENDIX E

Mechanical CAD handoff

## Objective

Create a manufacturable rounded-capsule enclosure no larger than 51.0 x 21.0 x 11.0 mm around the released Anticipy PCBA, exact protected battery, 10 mm haptic motor, light pipe, microphone paths, USB-C, button, and chain/bail interface.

## Inputs available now

- Provisional 45.8 x 18.0 mm board-only STEP.
- Provisional board-outline DXF.
- Placement PNG/SVG.
- Electrical requirements and antenna keepout rules.
- Provisional battery and motor envelopes in KiCad.

These are early packaging inputs only. The current STEP exports at 0.82 mm and contains no component bodies. Do not release tooling, aluminum, or final fit from it.

## Inputs required before final release

- Engineer-released PCBA STEP with maximum-height component bodies.
- Exact battery STEP and controlled maximum-tolerance drawing.
- Motor drawing and wire exit.
- Button travel/force and access target.
- USB connector insertion envelope and tolerance.
- LED emitting centre and light-pipe optical requirements.
- Microphone port centres, supplier keepout, mesh and acoustic targets.
- Exact Raytac antenna keepout and polymer-only external zone.

## Material architecture

- Front: 0.60 mm brushed 5052-H32 aluminum.
- Centre: injection-grade polycarbonate geometry; EVT may be printed in polycarbonate if tolerances are verified.
- Rear: 0.60 mm brushed 5052-H32 aluminum.
- Antenna end: polycarbonate only.
- Internal: flame-retardant electrical insulation, battery liner, anti-rattle foam, acoustic mesh, light pipe, controlled adhesive, and strain relief.

## Required CAD outputs

1. ANT-PROD-R0B_ENCLOSURE_ASSEMBLY.step
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

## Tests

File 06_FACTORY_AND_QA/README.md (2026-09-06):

# 06 — Factory and QA

**The process is defined. It has never been executed.** No unit has been built to it, because no
board has been fabricated.

This material came almost entirely from the 2026-08-28 Execution package and exists nowhere else.
It is the strongest work in the whole hardware record — and it would have been lost if the newer
"master package" had been treated as the complete archive.

## Layout

| Folder | Contents |
|---|---|
| `FACTORY_RELEASE_PROCESS/` | EOL test spec, incoming inspection, PCBA RFQ requirements, acceptance and lot-stop rules, serialized assembly traveler, release authorization template, factory upload manifest, PCB release checkpoint, `validate_factory_release.py` |
| `QA_FIXTURES/` | 42 STL and 45 STEP fixtures, 26 drop orientations, 59 acceptance checks |
| `TEST_EVIDENCE/` | Reports from the digital verification runs, plus `physical_capture/` |

## What "verified" means here — read carefully

Execution v1.0 recorded `10/10 package checks passed`. Every one of those is a **digital** check:

```
PASS | production mechanical checks   | 23/23 pass
PASS | PLAUD-size envelope            | 50.5 x 20.68 x 10.8 mm
PASS | 20-hour storage math           | 414 MB required; 481 MB usable candidate
PASS | print-now digital validation   | 27/27 pass
PASS | PCB fabrication hold preserved | segments=0, vias=0, zones=0
PASS | no misleading Gerbers          | none
```

Its own closing line is the honest one:

> These are digital/package checks. Physical audio, RF, battery, thermal, drop, rattle,
> sweat/ingress and customer-safety tests have not happened.

Two caveats worth restating:

1. The mechanical passes were run against the **50.5 × 20.68 × 10.8 mm** envelope. The current R1
   brief specifies **56.0 × 23.0 × 12.0 mm**. If R1 is the real target, these results are stale.
2. The storage and runtime numbers are arithmetic, not measurement.

## The only physical evidence in this repository

`TEST_EVIDENCE/physical_capture/2026-07-20_pendant_audio.wav` — an audio capture from a real
pendant. Which unit and which firmware produced it is not recorded. It should be logged against a
specific build.

Beyond that file and the five BLE logs in `../05_FIRMWARE/DEVICE_RECOVERY/`, nothing in this
repository is the output of a physical test.

## The production ladder

From the Execution package's decision card — the sequence that is not worth shortcutting:

1. Print one shell and prove fit
2. Assemble one lab recorder and prove the complete data path
3. Finish and rule-check the custom PCB
4. Assemble **three** EVT units
5. Run the included tests
6. Fix what is found
7. Build 10, then 35, then the sellable lot

> Skipping step 4 does not make the schedule faster. It turns 50 boards into one expensive
> experiment.

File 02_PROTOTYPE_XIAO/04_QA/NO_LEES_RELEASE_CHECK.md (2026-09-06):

# Unit 001 no-Lee's release check

Unit serial: ______  Builder: ______  Date/time: ______

Every line must be initialled. A failure means repair and repeat the complete check.

- [ ] Owner-supplied XIAO photographed, counted and identified as headerless nRF52840 Sense.
- [ ] Battery model/datasheet recorded; protected 1S LiPo; safe at 50 mA charge; polarity verified.
- [ ] Finished battery, motor, driver and XIAO pass their physical gauges.
- [ ] No wire, screw, bridge or board presses or rubs on the battery pouch.
- [ ] Active-high low-side driver matches the handoff wiring; motor is off at boot, reset and disconnect.
- [ ] Firmware SHA-256 matches the included checksum.
- [ ] Ten battery-only cold boots pass.
- [ ] USB-C charging current, battery voltage and temperature remain within the selected cell/XIAO limits.
- [ ] Intended iPhone commissions privately, receives live usable audio and commands haptic.
- [ ] Twenty owner-phone reconnects pass; a second iPhone cannot take control.
- [ ] Seventy-five haptic cycles pass during live audio with no reset, microphone buzz, RF loss or abnormal heat.
- [ ] One-hour closed-case live audio passes at normal use distance.
- [ ] Two-hour combined battery/BLE/audio/haptic run passes with temperatures recorded.
- [ ] USB-C remains accessible; microphone opening is clear; enclosure closes without force.
- [ ] Witness-film closure shows zero internal pressure points; battery remains flat and undamaged after reopening.
- [ ] Exterior is clean, black, flush, stable and free of exposed conductors, sharp edges, glue smears or rattles.
- [ ] Final app version and firmware hash recorded; final photos/video captured.

Release result: PASS / HOLD

Builder signature: ____________________  Owner acceptance: ____________________

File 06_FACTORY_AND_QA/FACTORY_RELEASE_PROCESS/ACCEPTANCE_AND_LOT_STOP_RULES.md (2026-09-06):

# Acceptance criteria and lot-stop rules

## Pre-build release gate

EVT fabrication remains blocked until every `MISSING_BLOCKING` PCBA item in `FACTORY_UPLOAD_MANIFEST.csv` is released and hashed, the battery pack is approved, and an authorized release record names the exact revisions. DVT and PVT require their prior phase to pass and a new signed release.

## Finished-unit acceptance

| Category | Acceptance criterion | Current release state |
|---|---|---|
| Identity | Unique serial; exact PCB/mechanical/BOM/firmware/test revisions and material lots recorded | Schema ready |
| Size | Finished nominal 50.5 × 20.68 × 10.8 mm including button membrane; never above 51.0 × 21.0 × 11.0 mm | Requirement locked; physical proof open |
| Mass | ≤17.4 g finished; record actual mass | Requirement locked; physical proof open |
| Internal retention | No audible/tactile rattle; no free motion; no wire pinch; no load or adhesive transferred through the broad LiPo pouch | Mechanical design/physical proof open |
| Cosmetics/safety | Seam/flush within released drawing; no opening, burr, crack, exposed adhesive or sharp edge | Drawing/physical proof open |
| Storage capacity | ≥414,000,000 verified usable bytes for audio after reserves/overheads | Firmware/hardware proof open |
| Twenty-hour backlog | 20 continuous hours recovered with correct sequence, duration and CRC; no silent loss, duplicate or reorder | Physical proof open |
| Battery endurance | ≥16 continuous hours under the frozen sealed workload | Physical proof open |
| Current | Sealed workload average ≤10.625 mA for the defined 85%-of-200-mAh budget | Physical proof open |
| Audio | Both channels pass released golden-unit amplitude/frequency/noise limits; no unexplained haptic/rub contamination | Numeric EOL limits must freeze during DVT |
| BLE/RF | Identity/connect/reconnect/backfill pass; RSSI/range meets released closed-product limit | Numeric RF limit/tuning open |
| Button | Short/3-second/12-second actions work without double action or sticking | Firmware/mechanical proof open |
| Haptic | Defined patterns work; no reset, corruption or loose motor; 100-event unit test passes | Physical proof open |
| Charging | Correct current, voltage, NTC response and safe temperature under released battery profile | Battery/power design open |
| Recovery | Power-cut test preserves older committed data and records any bounded tail loss explicitly | Firmware proof open |
| Security | Customer firmware uses authenticated/encrypted BLE, encrypted storage, signed anti-rollback DFU and controlled key erase | Implementation proof open |
| Compliance | Required ISED/EMC/Bluetooth/battery/label/privacy evidence tied to exact shipped configuration | Open; blocks customers |

No `OPEN` or `TBD` threshold may be silently converted into a pass. It must be frozen by ECO and added to the factory test configuration.

## Phase acceptance

### EVT-A — 10 units

- All ten have complete travelers and every-unit EOL records.
- No safety-critical failure.
- Root cause and disposition exist for every failure/rework.
- Released sample set proves storage, battery, RF/audio, charging, recovery and mechanical abuse requirements.
- Exact ECO list is frozen before DVT purchasing is released.

### DVT — 35 units

- Production-intent PCB, battery, enclosure, gaskets, adhesives, firmware and assembly process.
- 100% traveler/EOL completeness.
- Mechanical retention, drop/shock/vibration, chain pull/abrasion, sweat/ingress, temperature and button/haptic endurance plans pass their defined sample sets.
- Compliance pre-scan findings are closed or have a written blocking plan.
- Numeric acoustic, RF, current, charging, seam and fixture limits are frozen before PVT.

### PVT — 230 units

- Actual intended vendors, panel, tooling, fixtures, work instructions, operators and packaging process.
- First-pass yield target ≥95%; rework yield reported separately.
- 100% serialized EOL pass for any unit considered shippable.
- At least 200 passed units remain after destructive qualification samples, retains, rejects and rework disposition.
- Required compliance/qualification and shipment evidence is complete before customer release.

PVT units are held inventory until the PVT lot-release record is signed. Passing EOL alone does not make a unit shippable.

## Immediate stop and quarantine

Stop the line immediately for any one of these:

- Smoke, flame, venting, swelling, puncture, abnormal battery heating, smell or reversed polarity.
- Wrong PCB/BOM/firmware/mechanical revision or unknown material lot.
- Duplicate/missing serial or test data written against the wrong serial.
- Fixture calibration expired, fixture self-test fails or golden unit no longer reproduces its baseline.
- Any part substitution, process change or rework method without an approved ECO/deviation.
- Finished device exceeds the hard size or mass limit.
- Shell cannot close without force or transfers pressure to the battery pouch.
- Any exposed conductor, sharp edge or charging short risk.

## Statistical/process stop triggers

Stop and quarantine the affected lot when any trigger occurs:

- Two consecutive occurrences of the same major functional or mechanical defect.
- Three occurrences of the same major defect anywhere in a lot.
- First-pass yield below 95% after at least 20 units, or below 95% in any subsequent rolling 20-unit window.
- Two rattle, opened-seam, loose-component or battery-restraint failures.
- One failed destructive sample that indicates a common safety/design mechanism rather than sample mishandling.
- Incoming critical dimension fails on first article or two sampled parts.
- Supplier AOI/X-ray/test evidence is missing or disagrees with Anticipy EOL results.

These are internal Anticipy stop rules, not a claim of a universal sampling standard.

## Restart rule

The line restarts only after:

1. all potentially affected material and serials are identified and quarantined;
2. root cause is written and reproduced;
3. corrective action/ECO or approved rework is documented;
4. fixture and instructions are updated where affected;
5. one first article and then five consecutive units pass the affected test plus all downstream tests; and
6. an authorized release record names the quarantined lot disposition.

No schedule or shipment date overrides a lot stop.

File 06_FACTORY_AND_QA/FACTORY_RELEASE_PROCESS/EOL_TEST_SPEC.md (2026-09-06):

# Every-unit end-of-line test specification

## Status

The sequence is defined, but numeric acoustic, RF, charge/current, seam and fixture thresholds remain `TBD_BLOCKING` until EVT/DVT data and the approved battery/closed enclosure exist. The test program must refuse release when a required limit or result is blank.

## Fixture requirements

- Keyed nest that cannot load the chain hole, button or battery pouch.
- Pogo interface to released charging/test contacts only.
- Current/voltage measurement with recorded calibration.
- BLE reference radio at a fixed geometry.
- Controlled acoustic source and fixture microphones/reference level.
- Camera or operator-assisted LED/cosmetic verification.
- Button actuator with controlled travel/force.
- Haptic/rattle accelerometer or contact sensor.
- Barcode/2D-code scan tied to one test session.
- Golden passing unit and known-failing fixture self-test artifact.

At the start of each shift, revision change, fixture repair or calibration event, run fixture self-test and the golden unit. If the baseline falls outside its released control band, stop and quarantine results since the last known-good check.

## Test order

| Seq. | Test ID | Action | Every-unit acceptance |
|---:|---|---|---|
| 10 | `IDENTITY` | Scan serial and read hardware/firmware identity | Unique serial; exact released PCB/BOM/mechanical/firmware/test revisions and hashes |
| 20 | `VISUAL` | Inspect exterior, ports, button, charging area and chain hole | No sharp edge, burr, crack, blocked port, exposed adhesive, finish damage or wrong label |
| 30 | `DIMENSION_MASS` | Measure controlled envelope and mass | ≤51.0 × 21.0 × 11.0 mm and ≤17.4 g; released seam/flush limits pass |
| 40 | `BATTERY_NTC` | Read battery voltage and NTC temperature | Released pack voltage/temperature relationship; no open/short/reverse indication |
| 50 | `BOOT_CURRENT` | Boot through controlled supply/charge interface | No overcurrent, reset loop or abnormal heating; numeric release band `TBD_BLOCKING` |
| 60 | `CHARGE` | Apply released charging input for defined interval | Correct detection/current/termination-state/temperature behavior; numeric band `TBD_BLOCKING` |
| 70 | `FLASH_ID_CAPACITY` | Read flash ID/geometry and managed usable capacity | Exact released flash; verified usable audio capacity ≥414,000,000 bytes |
| 80 | `FLASH_CRC` | Write/read test patterns to allocated factory region | All CRCs pass; no unexpected new bad block; factory region retired/cleared per released procedure |
| 90 | `MIC_LEFT` | Play controlled acoustic sweep/tone and record left channel | Amplitude/frequency/noise/gasket-leak limits `TBD_BLOCKING` against released golden baseline |
| 100 | `MIC_RIGHT` | Repeat right channel and channel-balance check | Released per-channel and balance limits `TBD_BLOCKING` |
| 110 | `BLE_ID_CONNECT` | Advertise, connect, bond/authenticate as factory mode permits | Correct identity; connect within released time; no unauthorized production-audio access |
| 120 | `BLE_RF` | Measure RSSI/packet result at fixed fixture geometry | Closed-unit numeric RF band `TBD_BLOCKING` |
| 130 | `RECORD_STREAM` | Record local audio while streaming live for released short cycle | Continuous frames; rate ≤5,000 bytes/s averaged over defined qualification content; no reset/overflow |
| 140 | `DISCONNECT_BACKFILL` | Force phone loss, continue locally, reconnect and drain | All known segments arrive once, in order, with matching frame/sample sequences and CRC |
| 150 | `POWER_RECOVERY` | Execute released safe power-interruption test mode | Older committed segment remains readable; bounded tail/gap explicitly recorded; no sequence reuse |
| 160 | `BUTTON_SHORT` | Controlled short press | One bookmark and one short haptic; no private/reboot action |
| 170 | `BUTTON_3S` | Hold/release in 3-to-<12-second window | Private mode toggles once; two short haptics; no reboot/short action |
| 180 | `BUTTON_12S` | Hold at least 12 seconds | Orderly sync/reboot and three haptics; 3-second action not executed |
| 190 | `HAPTIC_100` | Execute 100 released haptic events | Correct sensor response; zero reset, corruption, loose-motor signature or unexplained audio event |
| 200 | `LED` | Exercise every released state | Correct visibility/colour/current; no unacceptable acoustic-port light leak; numeric optical band if used |
| 210 | `RATTLE` | Run controlled orientation/shake signature | No audible/tactile free motion; fixture signature within released golden band `TBD_BLOCKING` |
| 220 | `POST_TEST_CURRENT_TEMP` | Record final current, voltage and temperature | No abnormal drift/heat; released bands pass |
| 230 | `DATA_AUDIT` | Validate tester row and referenced raw artifacts | No missing required field; timestamps/serial/revisions consistent; raw evidence retained |
| 240 | `FINAL_RESULT` | Calculate disposition | Pass only when every required test is PASS and no `TBD_BLOCKING`, open NCR or lot stop exists |

## Every-unit burn-in

Every EVT/DVT unit and every PVT unit intended for shipment runs at least the released integrated burn-in cycle in parallel racks after closure. Until DVT freezes a different evidence-backed duration, use a **60-minute minimum** with continuous local recording, live BLE, at least one disconnect/backfill and representative button/haptic operation. Record reset count, dropped/corrupt segments, current/temperature extrema and post-burn-in rattle/seam result.

The full 20-hour storage and 16-hour battery requirements are separate qualification tests. A short EOL/burn-in pass does not claim either endurance requirement.

## Data integrity

- `EOL_RESULTS_TEMPLATE.csv` is one row per complete test attempt.
- Retest creates another attempt number; it never overwrites the failed row.
- Raw audio/CRC/RSSI/current/temperature artifacts use the serial and attempt in their filenames.
- Tester clocks use UTC.
- Factory cannot manually change FAIL to PASS. Authorized disposition occurs outside the immutable tester output and links the NCR/rework record.

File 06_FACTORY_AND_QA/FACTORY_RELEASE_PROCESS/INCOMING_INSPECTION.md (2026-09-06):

# Incoming inspection plan

Nothing enters assembly until it has a receiving record, supplier lot, quantity, revision and disposition. Mixed or unidentified lots stay physically separated.

## Receiving record fields

- Purchase order and line.
- Supplier and packing-slip number.
- Anticipy work order and phase.
- Manufacturer part number/revision.
- Supplier lot/date code.
- Quantity received, accepted, rejected and quarantined.
- Inspection equipment ID and calibration due date.
- Inspector ID and UTC timestamp.
- Linked photo/report/non-conformance number.

## PCBA incoming check

| Check | EVT 10 | DVT 35 | PVT 230 | Acceptance |
|---|---:|---:|---:|---|
| Count/revision/serial trace | 100% | 100% | 100% | Matches released work order; no duplicate serial |
| Package/MSL/ESD condition | 100% | 100% | 100% | Dry-pack/indicator and ESD packaging acceptable where required |
| Visual workmanship/polarity | 100% | 100% | 100% | No missing, shifted, tombstoned, reversed, bridged or damaged part |
| Supplier AOI/X-ray/e-test records | lot | lot | lot | Required reports name this PCB revision and lot |
| Board outline/thickness/warpage | 100% | first 10 + each panel | first 10 + one per panel | Released drawing limits; limits are currently blocked pending PCB release |
| Pogo fixture PCBA test | 100% | 100% | 100% | Pass `EOL_TEST_SPEC.md` PCBA subset before battery installation |

## Battery incoming check

The present battery placeholder is not approved. Receiving cannot begin until `BAT-ANT-200-001` has a signed drawing and matching safety/transport documents.

| Check | Frequency | Acceptance |
|---|---:|---|
| Correct MPN, revision and lot | 100% | Matches released approved-pack drawing |
| Pouch, tabs, PCM, leads and insulation visual | 100% | No dent, puncture, swelling, corrosion, exposed conductor, crushed edge, smell or wetness |
| Polarity and open-circuit voltage | 100% using keyed fixture | Released polarity; voltage within supplier shipping/receiving band |
| NTC response | 100% | Matches released 10 kOhm NTC circuit and receiving temperature band |
| Finished envelope and lead exit | EVT 100%; DVT first 10 + every lot; PVT first 10 + one per 20 | No dimension exceeds 26.0 × 12.5 × 6.0 mm and released lead envelope |
| Weight | EVT 100%; DVT/PVT first 10 + every lot | Within approved supplier drawing |
| Documentation | every lot | Applicable UN38.3 test summary, safety evidence, MSDS and lot trace available |

Any damaged, swollen, reversed or undocumented battery causes immediate lot quarantine. It is never forced into a shell or “tested to see if it works.”

## Enclosure and cap incoming check

| Check | Frequency | Acceptance |
|---|---:|---|
| Part/revision/material/finish/lot | 100% label trace | Matches released mechanical drawing and approved finish chip |
| Critical go/no-go fit gauge | 100% | PCB, battery, motor, button, acoustic and closure features accept the controlled gauge without force |
| Overall hard envelope | EVT 100%; DVT first 10 + every cavity/build; PVT first 10 + one per 20 | Finished closed assembly can remain within 51.0 × 21.0 × 11.0 mm |
| Cosmetic surface | 100% for first 230 PVT | No sharp edge, burr, crack, exposed fibre, objectionable sink/tool mark, colour/texture mismatch or finish damage under released cosmetic standard |
| Seam/registration features | EVT 100%; DVT/PVT first 10 + one per 20 | Released datum/feature limits; currently blocked pending DFM drawing |
| Chain attachment | EVT 100%; DVT/PVT first 10 + one per 20 | No crack, burr or undersized ligament; sample lot passes released pull/abrasion test |

## Motor, acoustic parts, adhesives and seals

- Match exact released MPN/material and supplier lot.
- Verify motor dimensions, lead exit and adhesive/retainer configuration against its controlled drawing.
- Keep left/right acoustic components identified if they differ.
- Verify membrane integrity and contamination-free handling.
- Record adhesive/seal manufacture date, expiry, storage condition and required cure window.
- Reject folded, stretched, contaminated or liner-damaged die cuts.
- Do not use expired or out-of-storage-condition material.

## Non-conforming material

1. Label and physically quarantine it.
2. Create a non-conformance record with photos and measurements.
3. Do not sort/rework/use-as-is without written disposition.
4. If supplier sorting is authorized, preserve the original lot and record every serial/quantity affected.
5. Feed repeated defects into the lot-stop rules before assembly resumes.

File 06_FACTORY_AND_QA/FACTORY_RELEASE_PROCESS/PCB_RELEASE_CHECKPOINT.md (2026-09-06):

# PCB checkpoint status

The old zero-copper candidates below are deliberate stop signs, not the v1.0
component choice. Replace them according to
`../03_PRODUCTION_PCB/V1_CORRECTION_ORDER.md`; never fabricate this checkpoint
as-is.

**State: ENGINEERING REFERENCE ONLY — NOT A FABRICATION RELEASE.**

The controlled checkpoint is `../03_PRODUCTION_PCB/anticipy_evt_a_kicad_checkpoint.zip`. It is useful for electrical/placement review and for completing the missing vendor data, routing and verification work. It is not one of the missing release outputs represented by `PCB001` through `PCB014` in `FACTORY_UPLOAD_MANIFEST.csv`.

## What exists

- Editable native KiCad project, schematic and PCB checkpoint.
- Four-layer, 0.60 mm nominal board outline measuring 37.50 × 14.00 mm overall.
- 55 named nets, 81 placed footprints/courtyards and all 47 non-test board references represented in the connected schematic.
- 25 automated structural checks passing with zero structural failures.
- Two 0.60 mm microphone acoustic holes, test pads and the controlled haptic-motor scallop.

## Why fabrication remains blocked

1. U1 Ezurio `453-00224R` has a deliberate zero-copper placeholder until its controlled vendor pad map is obtained and verified.
2. SW1 Alps has a deliberate zero-copper placeholder until its controlled delivery drawing/pad map is obtained and verified.
3. J3, the JYC720FDRL FPC/hot-bar connection, has a deliberate zero-copper placeholder until its controlled vendor land drawing is obtained and verified.
4. The board is intentionally unrouted.
5. KiCad ERC and DRC have not been run; the checkpoint includes explicit `ERC_NOT_RUN.txt` and `DRC_NOT_RUN.txt` records.
6. Gerbers, drill data, IPC-356, paste, complete released BOM, centroid, fabrication/assembly drawings, panel drawing and DFM closure are absent.
7. Battery approval, remaining exact orderable passives/LED, RF tuning, released firmware and physical qualification remain open.

## Permitted factory use

- Engineering review of architecture and placement.
- Early component-availability review.
- Capability/DFM discussion that does not create tooling or start fabrication.
- Quoting engineering work needed to close the gates.

## Prohibited factory use

- Do not generate or infer missing pads, copper, routing, Gerbers or drill data.
- Do not order PCBs, stencils, production components or assembly from this checkpoint.
- Do not treat a structural-parser pass as ERC, DRC, signal-integrity, RF or production qualification.
- Do not build customer units.

The PCB can move from checkpoint to EVT release only after controlled U1/SW1/J3 data are verified, the board is fully routed, native KiCad ERC/DRC pass with reviewed reports, the complete orderable BOM and fabrication set exist, assembler DFM is closed, and the release authorization is signed.

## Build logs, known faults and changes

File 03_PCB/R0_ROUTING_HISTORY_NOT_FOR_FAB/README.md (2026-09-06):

# Anticipy ANT-PROD-R0 EVT PCB

This is an editable, reproducible KiCad source package for the custom Anticipy
PCB. It does not require Flux or a paid PCB-design service.

## Current state

| Area | State |
|---|---|
| Electrical architecture and pin map | Frozen for EVT review |
| Component footprints and net assignments | Generated and checked against manufacturer documents |
| Board outline | Preliminary 49 x 20 mm capsule, 0.8 mm, four layers |
| Component placement | Complete enough for routing; remaining courtyard warnings require human review |
| Copper routing | **Not complete**; the latest free-router experiment reached eight unrouted connections |
| KiCad DRC | **Not passing** because routing is incomplete |
| Enclosure/battery collision check | Blocked until production battery dimensions and enclosure STEP are supplied |
| Gerber release | **Blocked; do not fabricate this revision** |

The Founder 10 build remains the separate XIAO-module design. This custom board
is for the later pilot/production path.

## Open the design

Install KiCad 7 or later and open:

`Anticipy_PROD_R0_EVT.kicad_pcb`

The board is generated from `generate_board.py`, which is the reproducible
electrical/placement source. Run it with the Python interpreter bundled with
KiCad on Linux:

```bash
/usr/bin/python3 generate_board.py
```

The clean generated board has no traces. `Anticipy_PROD_R0_EVT.dsn` can be
opened in FreeRouting for an assisted first pass, then returned to KiCad as a
Specctra session. All routes must still be reviewed and checked in KiCad.

## Architecture

- Raytac MDBT50Q-1MV2 certified nRF52840 module
- Nordic nPM1300 battery charger and power-management IC
- USB-C device/charging connector with CC resistors and low-capacitance ESD protection
- Two Infineon IM69D128S PDM microphones
- LIS2DW12 accelerometer
- Molex push-pull microSD socket
- User button, low-current red/blue indicator, vibration motor driver
- Battery, NTC, SWD, reset, and UART service pads

BUCK1 starts at 2.7 V using a 330 kOhm VSET resistor; firmware must raise it to
3.0 V after startup. BUCK2 starts at 3.0 V using 150 kOhm. This avoids asking
nPM1300 to start at an unsupported resistor-selected BUCK1 voltage.

## Files

- `generate_board.py` — deterministic board generator
- `Anticipy_PROD_R0_EVT.kicad_pcb` — editable KiCad PCB
- `Anticipy_PROD_R0_EVT.dsn` — FreeRouting exchange file
- `pad_net_report.csv` — every pad and assigned net
- `BOM.csv` — EVT bill of materials and sourcing status
- `PINMAP.csv` — firmware-facing pin map
- `INDICATOR_BEHAVIOR.md` — red/blue LED meanings
- `FREE_TOOLCHAIN_WORKFLOW.md` — how to finish without Flux
- `RELEASE_GATES.md` — exact conditions before fabrication
- `verify_project.py` — structural and safety checks
- `preview/` — top and bottom placement images

## Non-negotiable release rule

Do not generate or order from Gerbers until all of these are true:

1. Zero unconnected items in KiCad DRC.
2. Zero clearance, drill, solder-mask, and copper-to-edge errors.
3. USB D+/D- are length/geometry reviewed and the ESD part is beside the connector.
4. PMIC buck loops match Nordic's reference-layout intent.
5. Antenna keepout contains no copper, battery, aluminum, or ground fill.
6. Exact enclosure and protected battery STEP models pass collision review.
7. A qualified PCB reviewer signs the release checklist.

This package is an EVT engineering source checkpoint, not a fabrication release.

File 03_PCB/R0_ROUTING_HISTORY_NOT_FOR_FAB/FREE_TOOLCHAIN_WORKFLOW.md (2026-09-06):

# Finish the PCB without Flux

## Free tools

| Job | Tool | Cost |
|---|---|---:|
| Schematic/PCB editing, DRC, Gerbers, drill, BOM/PnP | KiCad | Free/open source |
| Optional first-pass autorouting | FreeRouting | Free/open source |
| Version history | Git | Free/open source |
| Board viewing by a factory | KiCad Gerber Viewer or any CAM viewer | Free |

FreeRouting is an assistant, not an electrical reviewer. Its session must be
imported into KiCad, manually cleaned, and independently checked.

## Continue from this checkpoint

1. Open `Anticipy_PROD_R0_EVT.kicad_pcb` in KiCad PCB Editor.
2. Confirm the exact factory stack-up before finalizing impedance-sensitive USB traces.
3. Route the PMIC first: VSYS, SW1/L1/VOUT1, SW2/L2/VOUT2, VBAT, VBUS, and all local grounds.
4. Add dense ground vias at U2 exposed pad, PVSS pins, input/output capacitors, USB ESD ground, microphones, and radio ground pads.
5. Route USB D+/D- as a short differential pair from J1 through U4 to U1; avoid stubs.
6. Route PDM clocks/data and microSD SPI away from the two microphone acoustic ports.
7. Route I2C, interrupts, button, haptic, LED, SWD, and UART.
8. Fill inner layer 2 as uninterrupted ground. Use inner layer 3 for power and low-speed routing only where it does not split USB/PDM return paths.
9. Keep the Raytac antenna zone completely free of copper, vias, battery, and enclosure metal.
10. Run KiCad DRC, inspect every warning, and produce a DRC report.
11. Import the final PCB STEP into the enclosure with the exact battery STEP and verify every clearance.
12. Only after `RELEASE_GATES.md` is signed may fabrication files be exported.

## FreeRouting round trip

The included DSN is the clean board exchange file. In FreeRouting, load the DSN,
route, and save a `.ses` session. In KiCad use **File > Import > Specctra Session**.
Do not overwrite the clean generated board until the imported route has been
saved under a new review filename and passes DRC.

## Factory export after approval

KiCad can export:

- Gerbers for all copper, mask, paste, and silkscreen layers
- Excellon drill files
- component position CSV
- IPC-356 netlist
- STEP model

No paid Flux subscription is required for any of those outputs.

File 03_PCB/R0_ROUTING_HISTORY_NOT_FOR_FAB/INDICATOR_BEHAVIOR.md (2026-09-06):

# Anticipy indicator behavior

The board uses one very small low-current red/blue LED. Its two cathodes are
driven by the nPM1300 LED current sinks; its anodes connect to VSYS.

| State | Light behavior |
|---|---|
| Powered but idle | Off |
| Recording | Slow blue pulse every 3 seconds |
| Bluetooth pairing | Alternating blue/red, 1 Hz |
| Bluetooth connected | Two short blue flashes, then off |
| Charging | Dim red pulse |
| Charged | One blue flash when cable is inserted, then off |
| Battery below 10% | Two red flashes every 60 seconds |
| Storage/microphone failure | Three red flashes after button press |
| Firmware update | Alternating blue/red, 2 Hz |

The LED should not remain brightly lit during normal recording. This preserves
battery life and makes the pendant less distracting. Firmware should cap LED
current to the lowest level that remains visible through the final light pipe.

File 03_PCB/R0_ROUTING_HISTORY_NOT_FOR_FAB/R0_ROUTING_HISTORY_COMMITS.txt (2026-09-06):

3ca2ce86206a72c99b82e4c8460934ff85834753 2026-08-30 docs: honest route status
496785fc26d1ca37afe68f2be15ec6e117b05534 2026-08-30 v43: GND 36, non-GND 23
4f91e2489afde5c7b503d80fe14ca5277a659503 2026-08-30 v41: GND stitched down to 51; non-GND at 23
41470ca2e9e37dfc765ef22dd43339b303f2f9fc 2026-08-30 v40: 23 non-GND unconnected, stable
2ef24772ad89458d58cb8fa3e93da5a41eebe5c2 2026-08-30 v39: 23 non-GND unconnected (from 199)
bb00eba1bebb7aacc9aa73c0e1fdc9101fbe4736 2026-08-30 v38: bridge attempts; count unchanged - geometry mismatch between route cells and board copper
344a006c4ad341dc0c64c68568e4c0cf493640cc 2026-08-30 v37: 33 non-GND unconnected remain
5cbd1aa205d0fdb3648fcf944d74942bf4ba9ef3 2026-08-30 v36: 72 non-GND unconnected; big buses in
24b16cae66865d5caaca3e990cff3cf0ce9e9fc1 2026-08-30 v35: B-side buses; 78 non-GND unconnected
a9680901c9e2f6be287b171600598cb15548abb4 2026-08-30 v34: U2 pad vias; 74 non-GND unconnected
32cb7fadeb1cb0fb844ed34fdeb2ad2173f1eec5 2026-08-30 v33: power trunks added; 86 unconnected remain (pad-escape gaps)
f48f4ce0d21e802448d1bdbc65c9dc40b905953a 2026-08-30 v32: U1 pad links wired; 84 non-GND unconnected
ec8a3feb477470eb0201c623b3973728e7bf64e6 2026-08-30 v31: NTC/USB_CC dogbones; 86 non-GND unconnected
ae5c14bf8754e0652f9bd5c2fb9440ce1eb9d4a8 2026-08-30 v30: dogbone exit wires connected (LED/SD/MIC/LDO/VSET); 92 remain
68cc1dc28440f916083c202a05947b3953d96429 2026-08-30 v29: QFN dogbones fix 8 nets; 96 non-GND unconnected
40c927acca86e1d44bb852622f200d44ee8996fc 2026-08-30 v28: wave-v27 partial; similar convergence ceiling
7fca3d8d8971f90932873ed3044ea18e3d26f56f 2026-08-30 v26: hand-fixed VBUSOUT+DCCH, 104 non-GND unconnected
f4c9ea6d8c08d02185d78751fce8c6b8654d6721 2026-08-30 v25: VBUSOUT+DCCH hand-rerouted; 108 non-GND unconnected remain
a173c777c46b2d2a9e02af690b539e9866f2ff90 2026-08-30 v23/v24: 108 non-GND unconnected; route state converged at this level
99adb81c9d7acb8b94e8769fd17a097d5f09fc42 2026-08-30 v21: 26 nets re-completed; remaining gaps small
4c9a63da3835bc63ad00f4b132ca0ddfb09984d1 2026-08-30 v20: PMIC_INT + USER_BTN hand-fixed, 120 unconnected remain
939940448322882116d2523b067f528227cb1f9e 2026-08-30 v19: 40 stitch vias, 122 unconnected remain
755c896a57b196c76d9a69d7269db626e63a1abc 2026-08-30 v18: best routed state (126 unconnected GND-plane items + small fixups)
81449d879b1731b0ea221fb3496c0ded453adff5 2026-08-30 wip route experiments
1d3e8d4d45fb57759cbc3619f527be2b390f31ad 2026-08-30 checkpoint: v6 (59 shorts, 320 clearance) before final targeted repair
d7c215ffa464348932dfca396b5e013cfea3bf00 2026-08-30 all 45 nets routed with copper (455+ stubs cleaned, vias normalized)
142514d5956ec4ce880b91e18168847d500ba6a4 2026-08-29 negotiated-congestion routing: 39/45 nets complete, 0 conflicts
ba2c1efe023ebc502667e1ec0ae92a2cc85d9c1a 2026-08-29 placement DRC-clean: 0 errors except unconnected; KiCad 10 footprints, fixed J1/U2/U4/LED/BT1 clusters
e450b6007b8193b40e413162d49044491a6af152 2026-08-29 KiCad 10 port: regenerate with L3/DCCH + J1 fix; verifier green; 171 unconnected await routing
22ce3ec340c03ce58e189b634d18f4181e08035e 2026-08-29 audit: datasheet-verified netlist review; add L3 DCCH inductor; J1 edge fix; verifier updates
221e19daf509f469410777416df80fcf62ef1d4a 2026-08-29 ANT-PROD-R0 EVT KiCad checkpoint: recover and preserve (source: Anticipy_ANT_PROD_R0_EVT_KiCad_Source.zip 2026-08-29)

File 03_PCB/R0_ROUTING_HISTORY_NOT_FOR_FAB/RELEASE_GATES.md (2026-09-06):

# ANT-PROD-R0 fabrication release gates

All boxes must be checked by name and date before a Gerber ZIP is created.

## Electrical

- [ ] KiCad DRC: zero unconnected items
- [ ] KiCad DRC: zero clearance, hole, mask, and edge errors
- [ ] USB D+/D- differential pair reviewed against selected factory stack-up
- [ ] nPM1300 buck loops and ground returns reviewed against Nordic reference layout
- [ ] VSET1 = 330 kOhm and VSET2 = 150 kOhm verified on source and assembled board
- [ ] ESD part pin 1 = D+, pin 2 = D-, pin 3 = GND verified
- [ ] Microphone footprints, 0.60 mm acoustic holes, and gasket keepouts verified
- [ ] microSD footprint and card-eject clearance verified
- [ ] Antenna copper and metal keepouts verified on every layer
- [ ] SWD programming and recovery path verified

## Mechanical

- [ ] Exact protected battery part selected with drawing, UN38.3, and protection data
- [ ] Exact battery STEP checked with 0.5 mm minimum pocket clearance
- [ ] PCBA STEP imported into final enclosure STEP
- [ ] USB opening, button, LED light pipe, microphones, bail, and card access checked
- [ ] Aluminum faces stop before antenna keepout
- [ ] No component or battery touches aluminum

## Prototype validation

- [ ] Five EVT PCBAs assembled first
- [ ] Power rails checked with current-limited supply before battery connection
- [ ] Charging temperature and charge current measured
- [ ] BLE tested in closed metal/polycarbonate enclosure
- [ ] Both microphones and SD recording tested
- [ ] Haptic noise checked in recorded audio
- [ ] Runtime, reset, brownout, card removal, and full-storage behavior tested
- [ ] One golden unit retained with serial, firmware hash, and test record

## Release signatures

Electrical reviewer: ____________________  Date: __________

Mechanical reviewer: ____________________  Date: __________

Anticipy release owner: _________________  Date: __________

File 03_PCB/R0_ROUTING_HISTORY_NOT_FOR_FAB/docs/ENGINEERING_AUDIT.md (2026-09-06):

# ANT-PROD-R0 engineering audit — 2026-08-29

Auditor: Claude (senior HW/SW). Method: full S-expression parse of the KiCad PCB
(62 footprints, 277 pads, 46 named nets, 49.00 x 20.00 mm capsule, 4 layers,
0.8 mm), cross-checked pad-by-pad against the official manufacturer documents
listed at the end. Every claim below traces to a fetched datasheet or a parsed
board fact. No assumptions.

## Verdict

The electrical design is sound and was verified against primary sources. Three
defects were found and fixed in `generate_board.py` (the reproducible source):

1. **U1 pad 31 (DCCH) was left floating.** The nRF52840 Reg0 DC/DC was therefore
   unusable, forcing LDO mode and wasting battery. Fix: added L3 (10 uH,
   TDK MLZ2012N100LT000, 2.0 x 1.6 mm) between U1 pad 31 (DCCH) and 3V_MAIN,
   per Nordic nRF52840 and Raytac application circuits.
2. **J1 shell stakes sat 0.475 mm outside the board edge** (copper off-board).
   Fix: J1 moved from x=20.6 to x=22.0 so all copper clears the edge with
   margin.
3. Verifier updated for the new footprint count (63) and the DCCH net.

## Verified correct (no action)

- **U1 pad map matches the Raytac MDBT50Q-1MV2 spec Ver. L exactly**: pads 1/2/
  15/33/55 GND, 28 VDD, 30 VDDH, 32 VBUS, 34 D-, 35 D+, 51/53 SWD, 40 nRESET.
  Every PINMAP.csv row (16 P0.27, 19 P0.26, 38 P0.16, 39 P0.15, 37 P0.13,
  36 P0.14, 29 P0.12, 27 P0.11, 45 P0.23, 24 P0.08, 22 P0.06, 41 P0.17,
  44 P0.20, 43 P0.21, 21 P0.05, 20 P0.04) matches the datasheet pin functions.
  KiCad's official `Raytac_MDBT50Q` footprint is used.
- **Antenna geometry is correct**: antenna end (pads 1/55 stubs at x=64.75,
  chip antenna to x=68.75) faces the right board edge; the all-layer keepout
  zone x 65.0..68.75, y 23.8..36.2 is exactly Raytac's 3.8 mm no-ground strip
  and is wider than the module, per the design guide.
- **32 unused module pads are legitimately NC** (pads 3-14 low-freq-only GPIOs,
  17/18 XL1/XL2, 23/25/26/42/46-50/52/54/56-61 unused GPIOs). 32.768 kHz
  crystal intentionally omitted; nRF52840 internal RCOSC used (documented
  battery-life tradeoff; revisit at DVT if sleep current matters).
- **nPM1300 power tree verified against PS v1.1 Table 35/39/40**: VBAT+C6,
  VBUS+C1, VSYS bulk, PVDD=VSYS (pin 4), SW1->L1->VOUT1=3V_MAIN, SW2->L2->VOUT2
  =3V_SD, PVSS1/2 to GND, EP AVSS to GND, VDDIO (pin 12) on 3V_MAIN with C13,
  VSET1=330k (2.7 V start, firmware raises to 3.0 V), VSET2=150k (3.0 V),
  NTC pin 18 wired to the protected pack's NTC wire, LDO1 (pin 29) = 3V_MIC
  rail with C10 10 uF, LDO2 (pin 31) decoupled and unloaded, VBUSOUT decoupled
  C5 and unused, LED0/LED1 open-drain sinks driving the bicolor LED cathodes
  (current-source mode, no series R needed), CC1/CC2 on the connector with
  5.1k Rd pairs.
- **Microphones IM69D128S**: pad map VDD/CLOCK/DATA/LR/GND correct; MIC1 LR=GND
  (left, falling edge), MIC2 LR=3V_MIC (right, rising edge); separate 100R data
  series resistors R14/R15 joining PDM_DATA; 1 uF bypass per mic close to VDD.
- **LIS2DW12**: RES pin 7 tied to GND (mandatory), CS pin 2 tied high (I2C
  mode), SA0/SDO pin 3 to GND (address 0x18, deliberate), both GND pins on
  plane, NC pin 5 floating (allowed).
- **TPD2EUSB30**: pin 1 D+, pin 2 D-, pin 3 GND, placed beside J1.
- **USB-C USB4105**: A1/A12/B1/B12 + 4 shell lands to GND, VBUS x4, CC1/CC2
  separate with Rd, D+ A6/B6 shorted, D- A7/B7 shorted, SBU1/SBU2 floating
  (correct for USB 2.0-only).
- **microSD Molex 104031-0811**: SPI wiring with 22R series on CLK/MOSI/MISO,
  100k CS pull-up to 3V_SD, detect switch pin 9 to GPIO with GND on pin 10,
  DAT2/DAT1 floating (SPI mode), back-side placement with 4 ground pattern pads.
- **Haptic**: low-side N-FET AO3400A with 100R gate series + 100k pulldown,
  flyback 1N4148W to 3V_MAIN, motor across 3V_MAIN/drain, 47uF + 100nF local
  bulk. Motor on the 2.7 V boot rail is within the Vybronics 3V rating.
- **Battery BT1**: protected 1S pack, VBAT/NTC/GND solder pads, 2.2uF C6 at the
  PMIC.
- **Test/bring-up**: 7 pogo pads on the back edge (SWDIO, SWDCLK, RESET,
  3V_MAIN, GND, UART TX/RX).

## Board-level rules frozen in the generator

- 4 layers, 0.8 mm, 5/5 mil min clearance/track, 0.45/0.20 mm via.
- Antenna keepout: no tracks, vias, pads, or copper pour on any layer.
- Capsule outline 49 x 20 mm with 10 mm end radii; keepout boundary drawn on
  Dwgs.User at x=65 for the assembler.

## Remaining before fabrication (unchanged gates)

1. Regenerate the board with KiCad's Python (this Mac now has KiCad 10 being
   installed), then run verify_project.py.
2. Clear DRC: 16 courtyard overlaps, 12 hole-clearance hits, 2 copper-edge
   hits, silk warnings. Fix in placement, not by silencing rules.
3. Route copper (FreeRouting first pass, then hand cleanup), fill ground plane
   on In1, power on In3, then zero unconnected.
4. USB pair geometry review against the JLCPCB stack-up document.
5. STEP export and collision review in the 50.5 x 20.7 x 10.8 mm enclosure.
6. Battery supplier drawing (UN38.3, IEC 62133-2) — Adafruit 1578 class part is
   the EVT placeholder; the pocket is sized for it.

## Sources fetched and verified

- Raytac MDBT50Q-1MV2 spec Ver. L (2023-05-24), raytac.com download index 43.
- Nordic nPM1300 Product Specification v1.1 (4490_483), Digi-Key mirror PDF.
- Infineon IM69D128S datasheet v1.01 (Table 7 pin configuration).
- ST LIS2DW12 DS11811 Rev 9 (Table 1 pin description).
- GCT USB4105 drawing rev B4 (gct.co/files/drawings/usb4105.pdf).
- Molex SD-104031-001 Rev E via LCSC/Farnell/TME mirrors (molex.com blocks bots).
- KiCad official footprints: RF_Module/Raytac_MDBT50Q,
  Connector_USB/USB_C_Receptacle_GCT_USB4105-xx-A_16P_TopMnt_Horizontal
  (fetched from kicad-footprints master, 2026-08-29).

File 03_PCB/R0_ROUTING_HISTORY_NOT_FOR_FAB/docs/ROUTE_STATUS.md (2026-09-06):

# ANT-PROD-R0 route status — 2026-08-30 (honest)

## What is true right now

The board file `Anticipy_PROD_R0_EVT.kicad_pcb` contains a fully placed board
with copper routed on 45 of 46 signal nets (GND is plane-only by design).
A 3D render confirms visible, continuous routing across all regions.

## What is NOT fabrication-grade yet

The last full DRC run reports:
- 36 GND unconnected links (plane stitching gaps; the In1 plane pour would close most)
- 23 non-GND unconnected links (one pad-pair each on: USB D+/D-, SW1/SW2,
  VBAT, USB_CC1, USER_BTN, 3V_MAIN, VSYS, VBUS, I2C, SWD, RESET, SD_SCK_MCU)
- Clearance/short violations introduced by the automated repair passes

## How it was produced

A purpose-built negotiated-congestion maze router (`tools/route_board.py`,
PathFinder-style soft costs + rip-up), written because FreeRouting 2.0.1
headless cannot save output and KiCad 10's Specctra export segfaults on
this machine. The router converged to ~39 nets cleanly; the remaining nets
were closed by escape-via fanouts, dogbones, and hand-run bridges
(`tools/` scripts + git history v1..v43).

## Shortest honest paths to a fab-grade board

1. FreeRouting GUI (10 minutes of human time): open
   `Anticipy_PROD_R0_EVT.dsn`, autoroute, save session. Then re-verify
   with DRC. Its router is far more mature than the in-session one.
2. A focused session finishing DRC one class at a time (shorts first,
   then clearance, then the 23 pad-pair bridges).

## Not fake-done

No gerbers were exported. No fab package was generated. The release gates
in RELEASE_GATES.md remain unchecked. The rule "no Gerbers until DRC is
clean" was respected.

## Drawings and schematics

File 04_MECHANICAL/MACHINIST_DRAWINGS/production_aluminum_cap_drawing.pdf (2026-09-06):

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

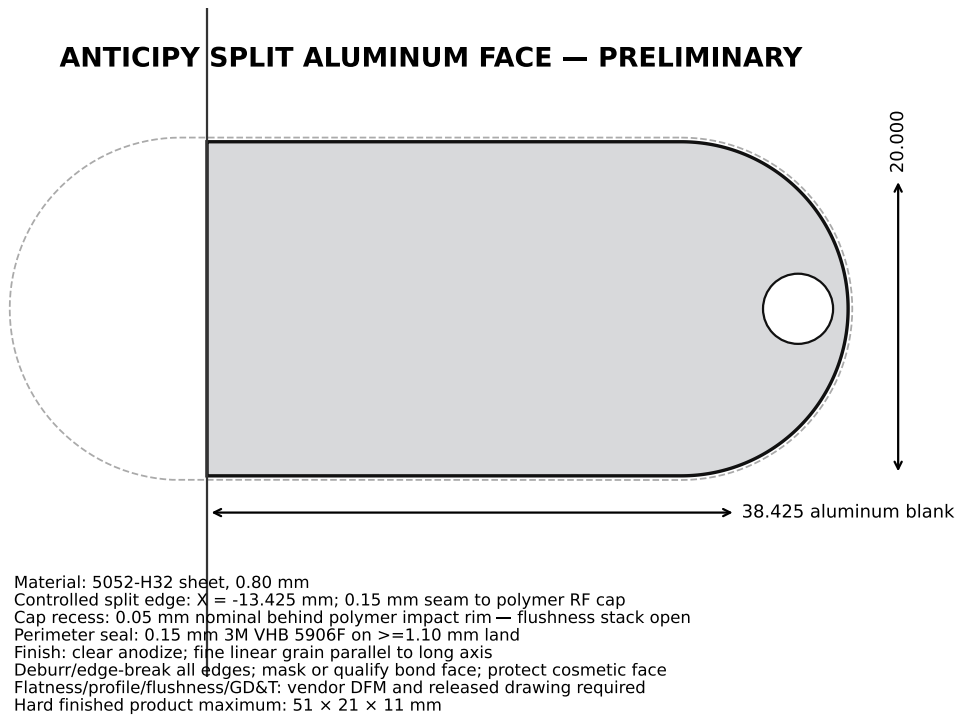
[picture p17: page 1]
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

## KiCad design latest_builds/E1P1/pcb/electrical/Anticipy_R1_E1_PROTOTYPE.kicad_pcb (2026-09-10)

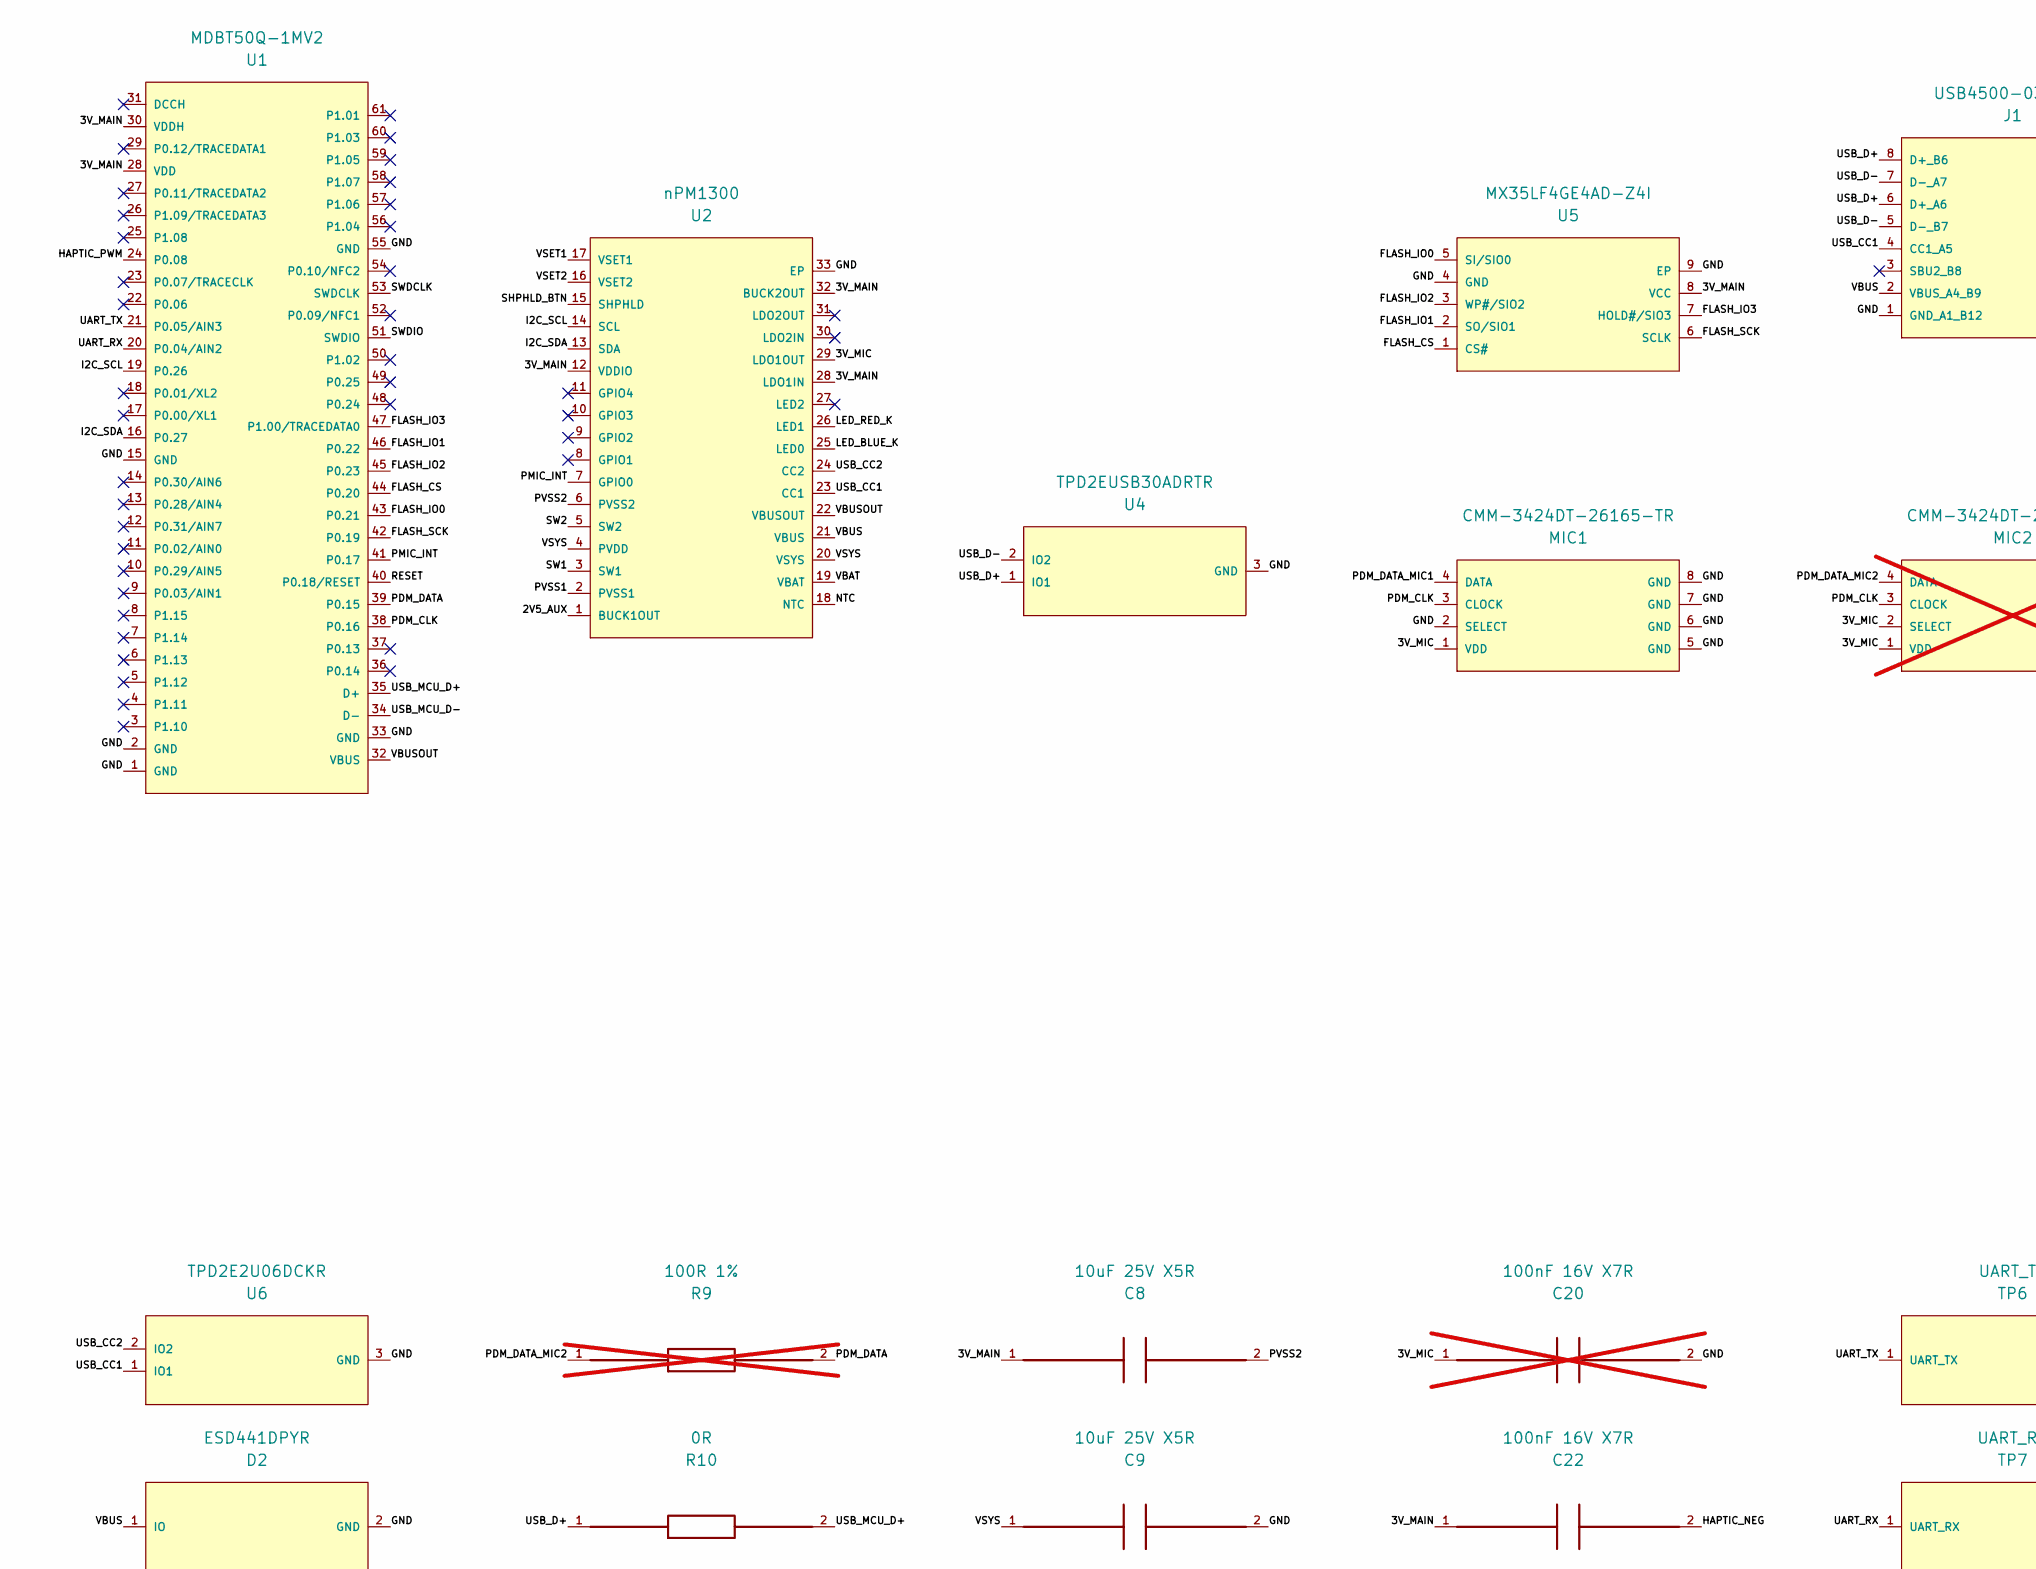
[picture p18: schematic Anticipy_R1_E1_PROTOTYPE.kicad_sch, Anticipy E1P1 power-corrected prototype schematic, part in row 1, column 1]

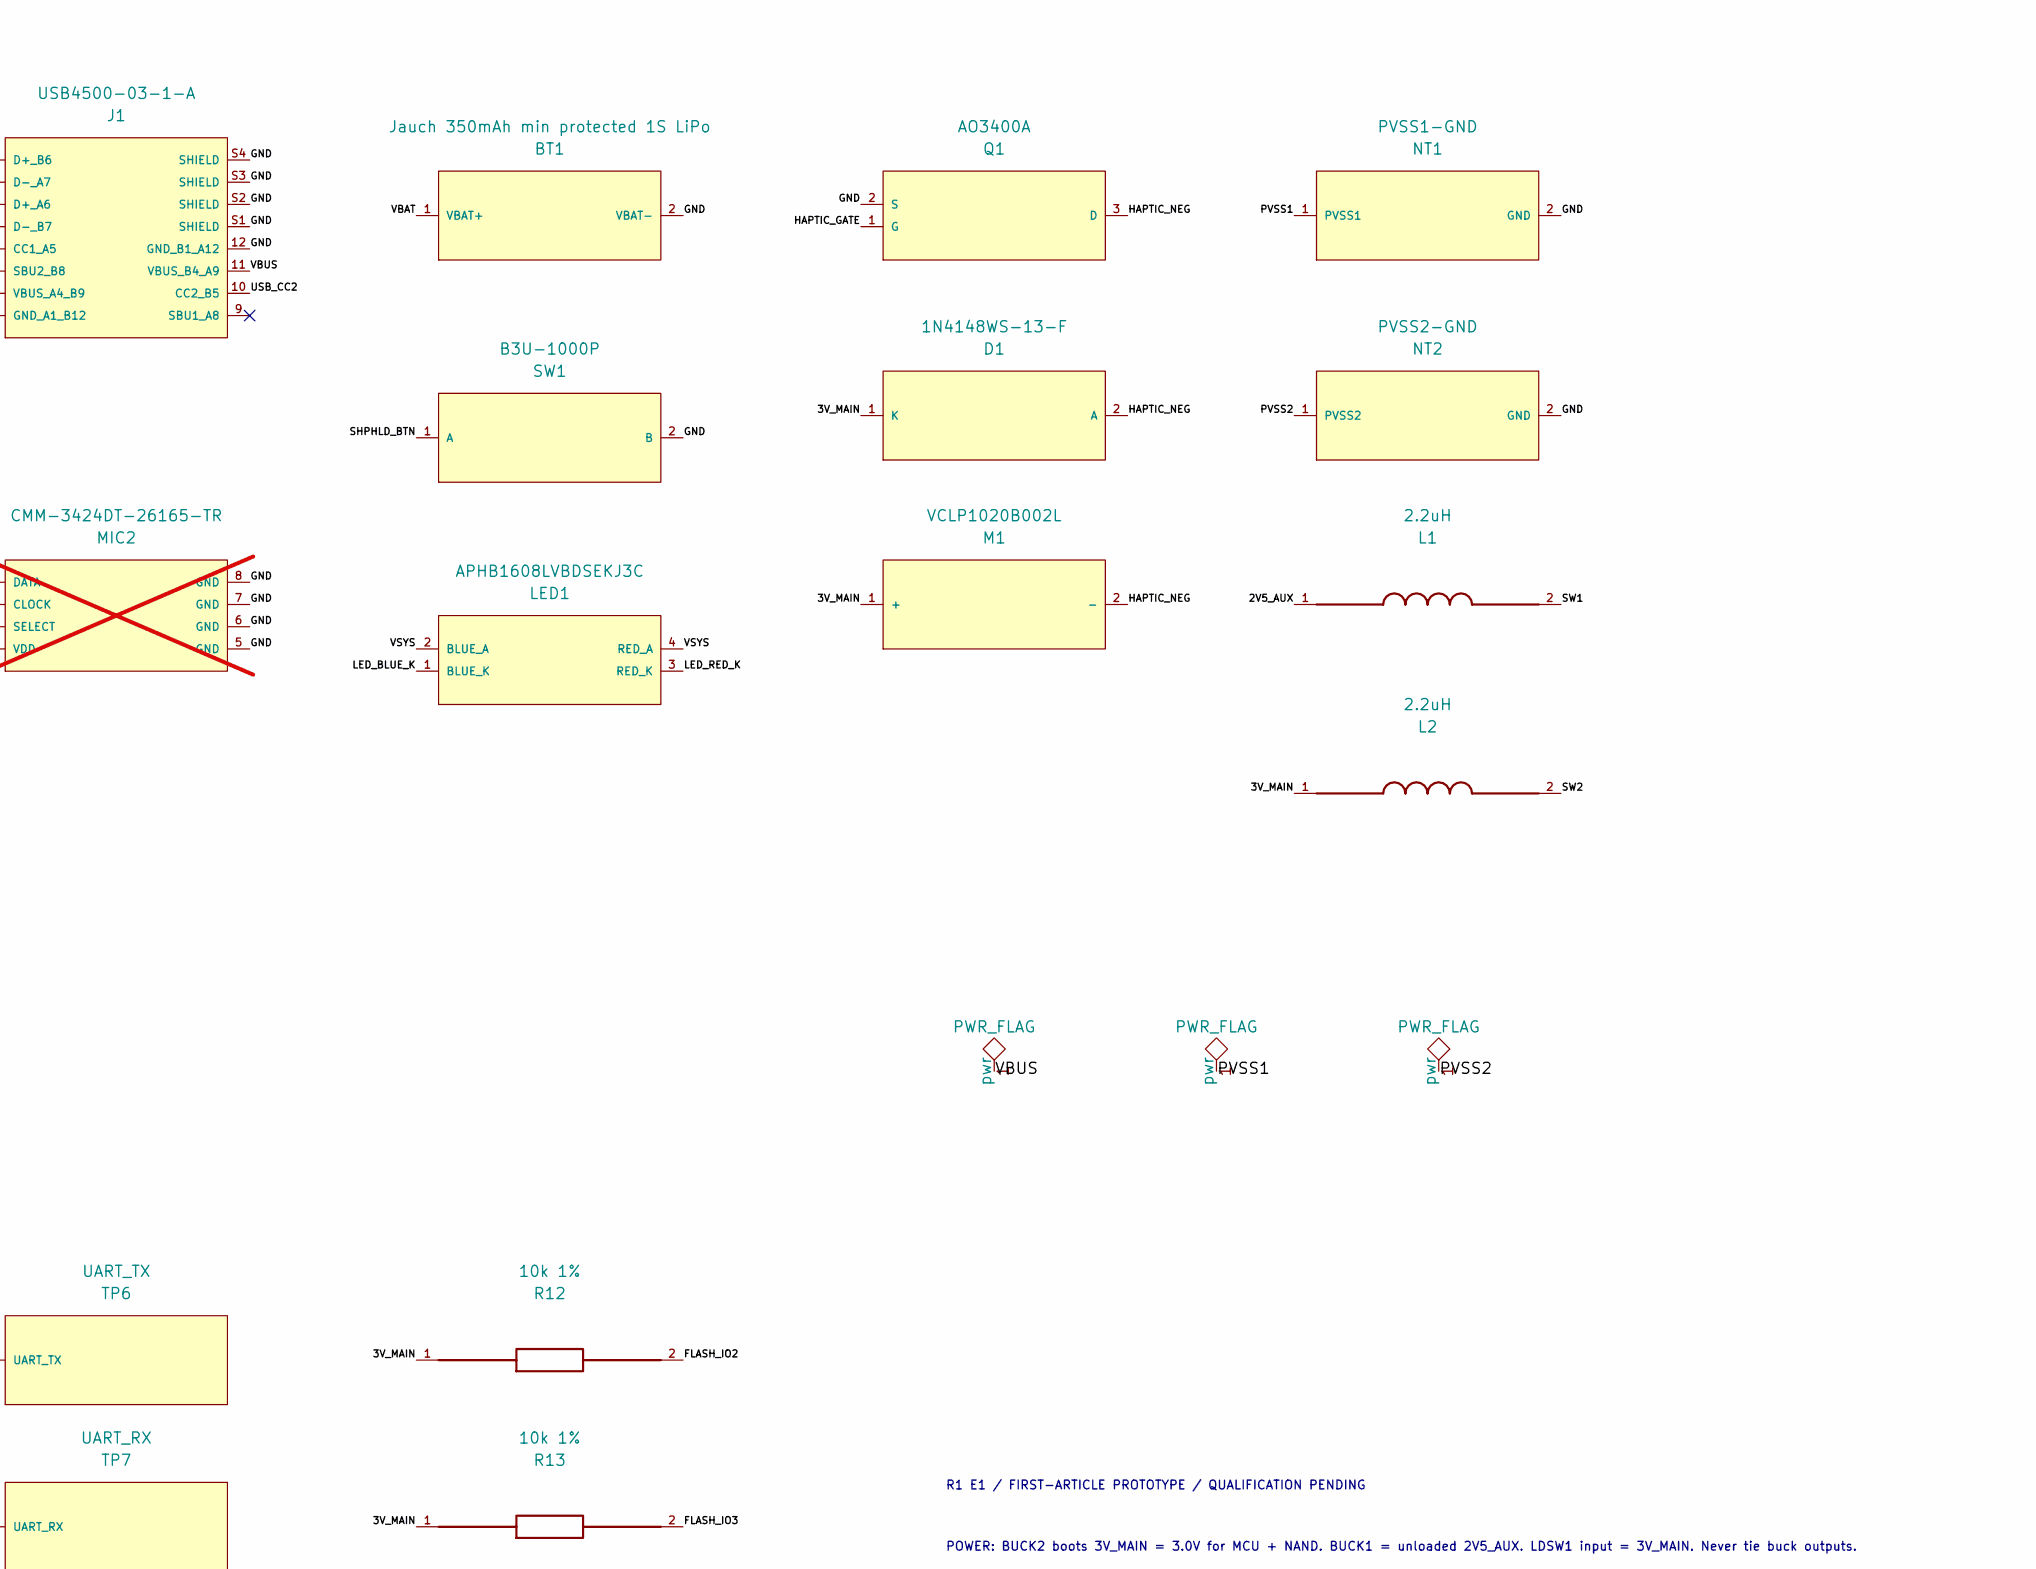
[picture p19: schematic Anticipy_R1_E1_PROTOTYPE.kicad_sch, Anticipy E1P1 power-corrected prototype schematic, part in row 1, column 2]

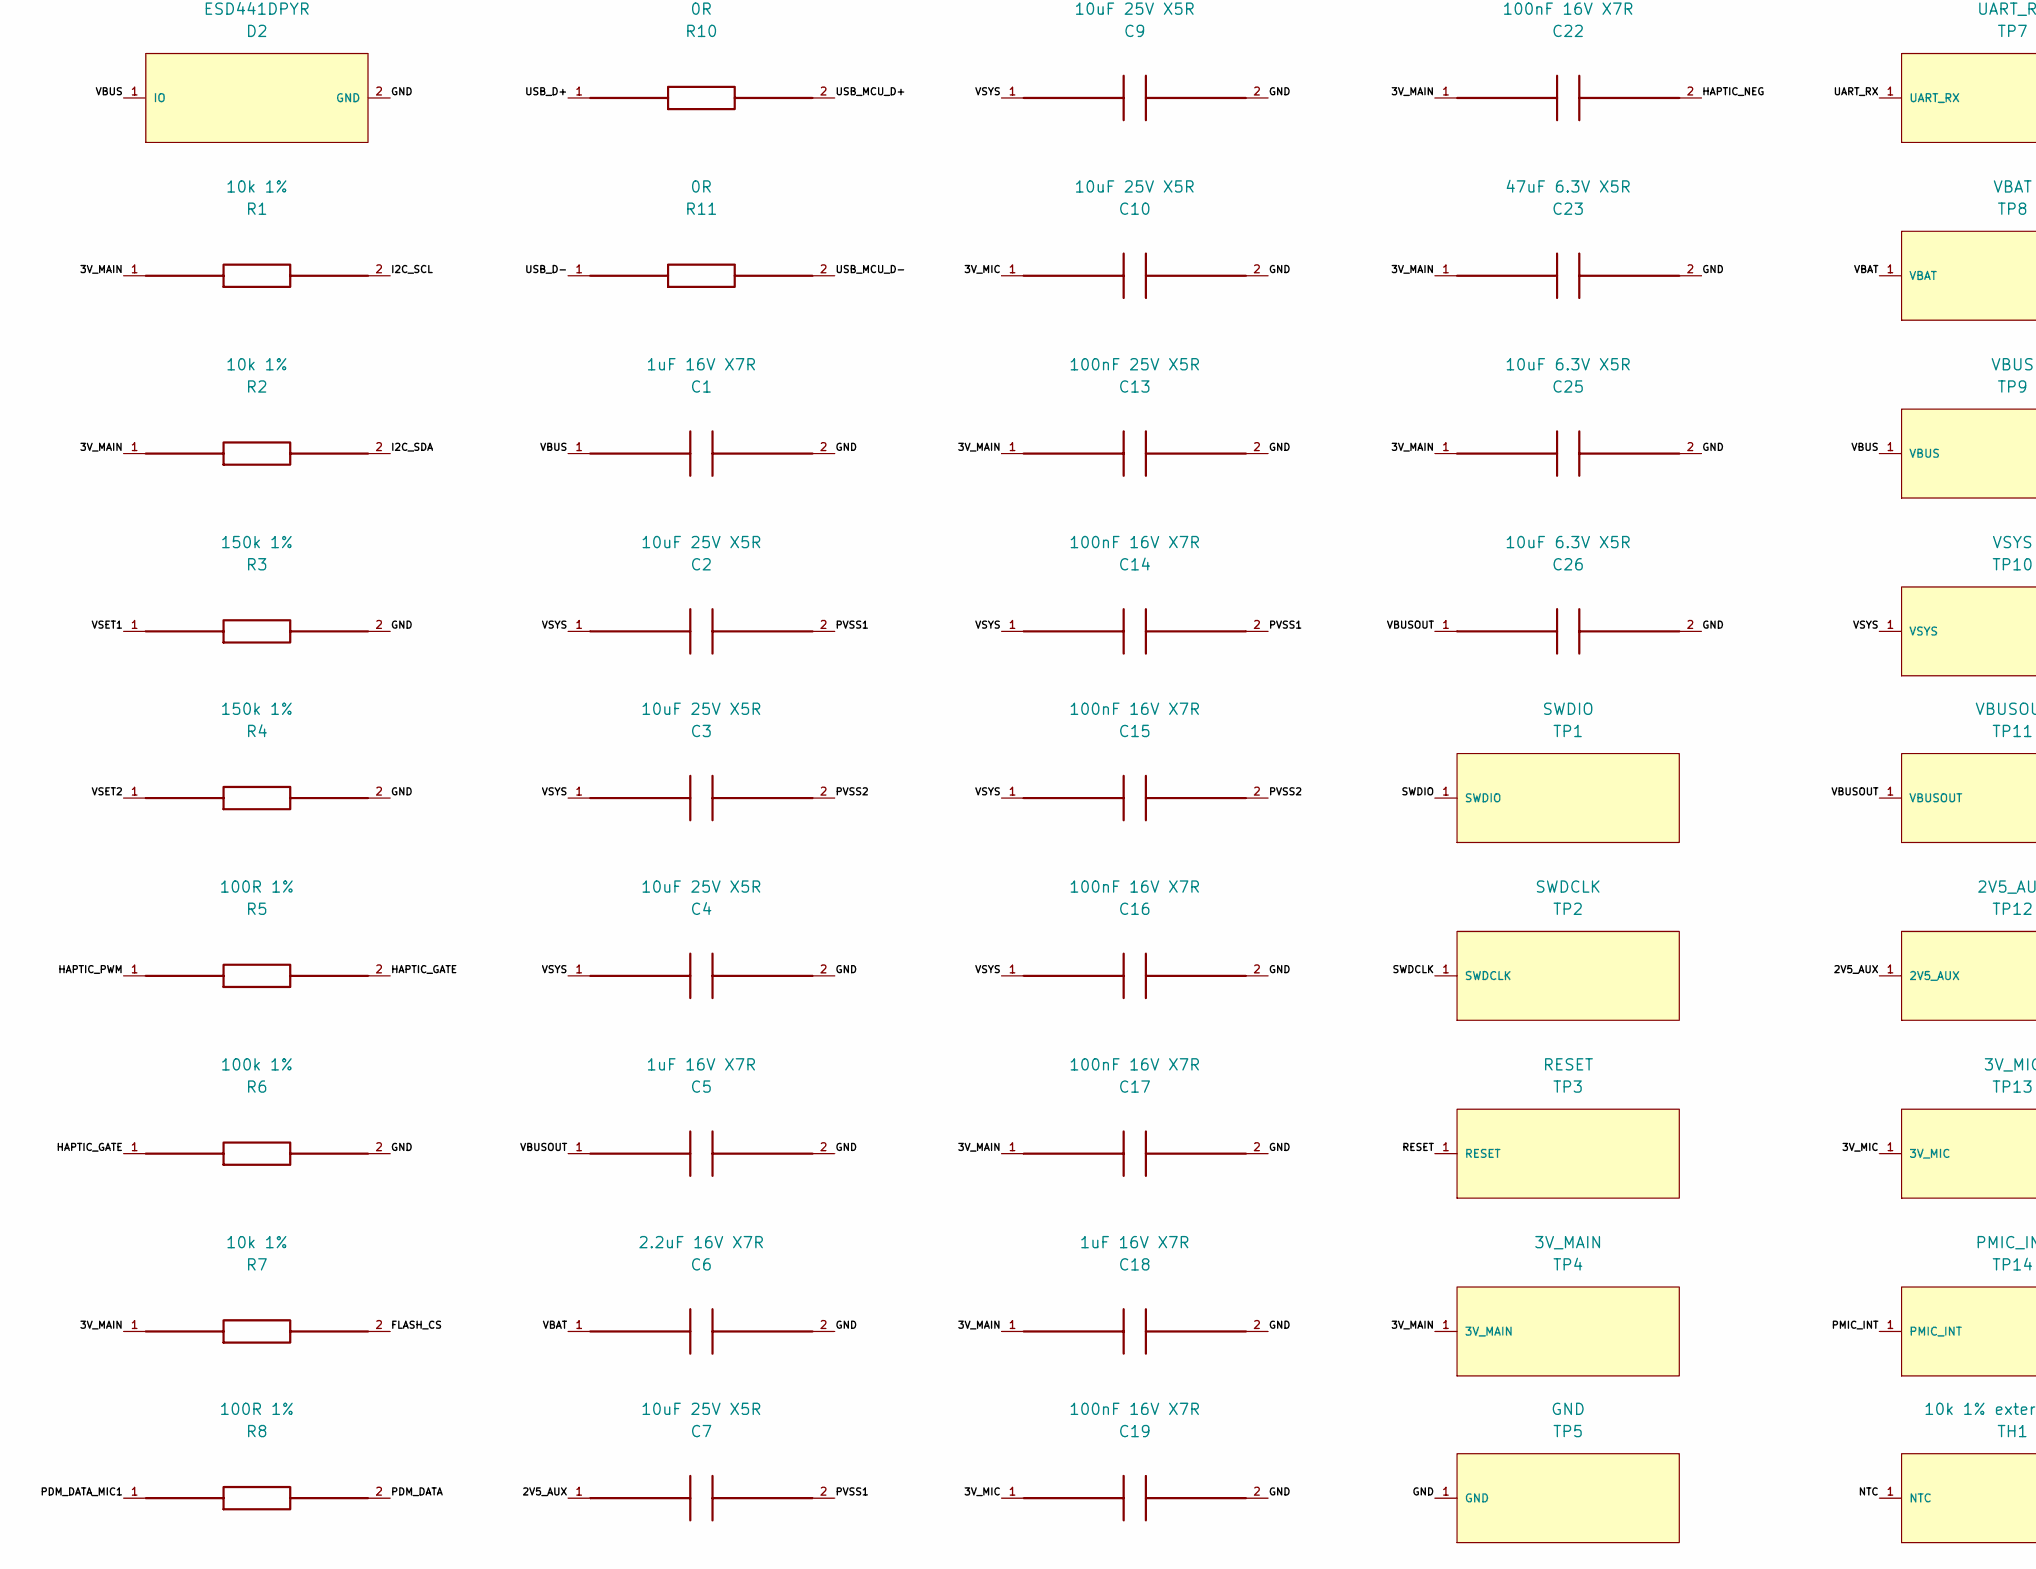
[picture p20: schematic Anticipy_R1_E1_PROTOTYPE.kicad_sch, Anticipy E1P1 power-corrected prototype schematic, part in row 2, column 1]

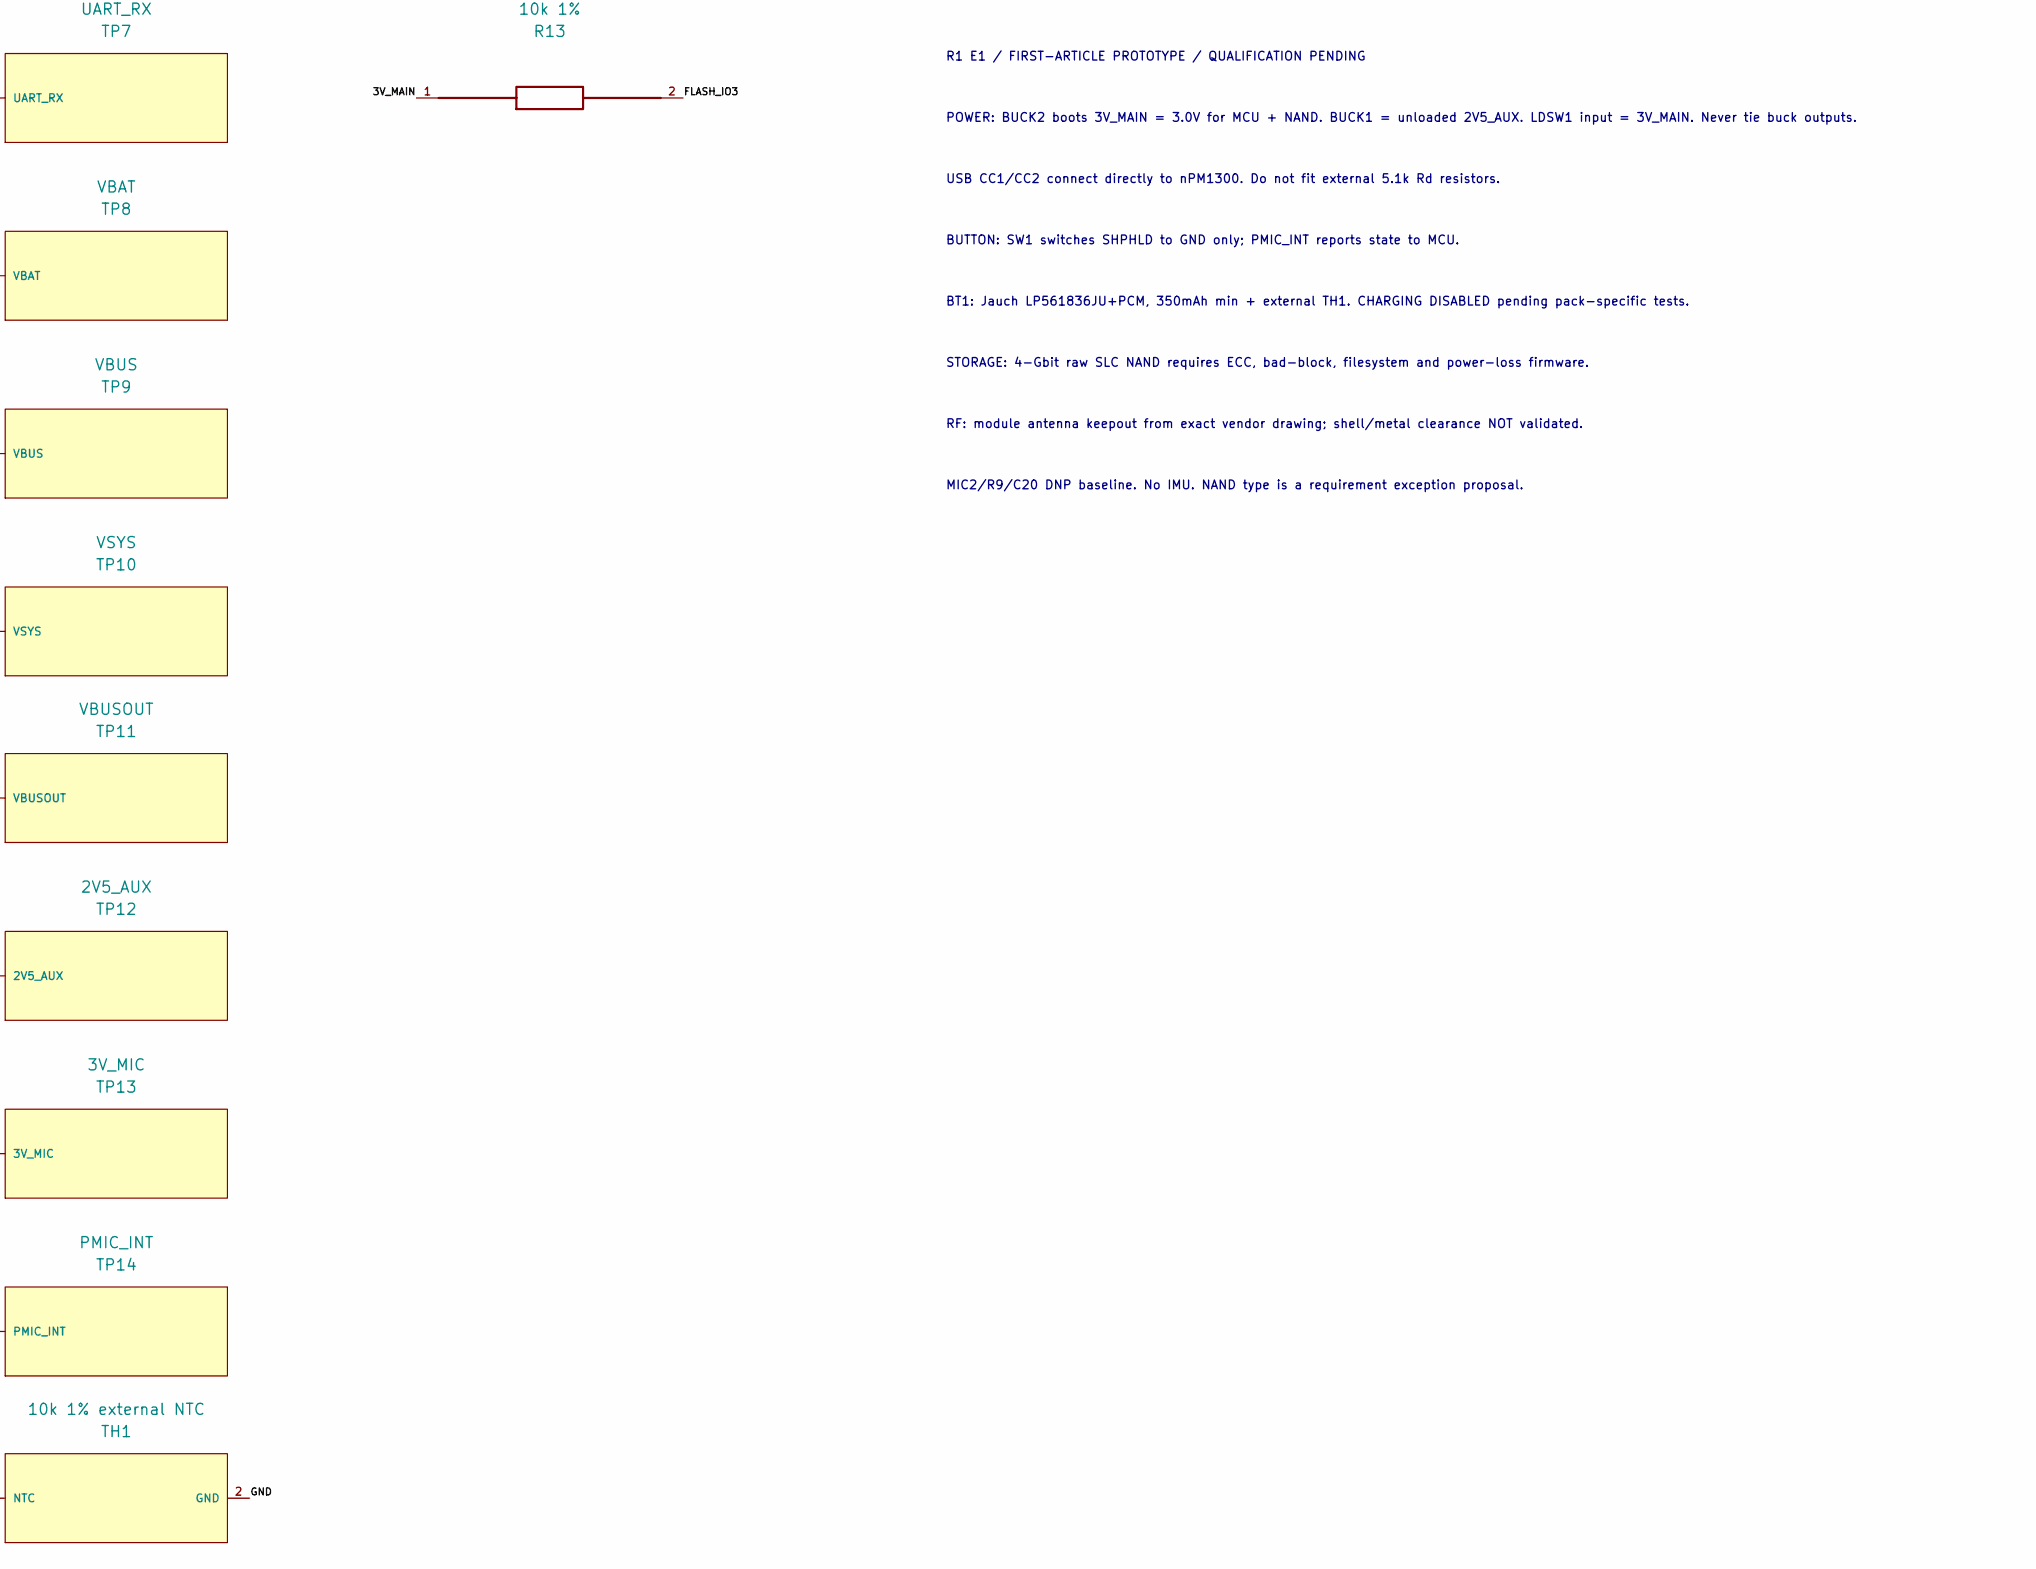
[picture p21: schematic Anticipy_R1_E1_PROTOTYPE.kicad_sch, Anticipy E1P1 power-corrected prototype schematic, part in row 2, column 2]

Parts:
BT1: Jauch 350mAh min protected 1S LiPo; BT1__WirePads_2_P1.27mm; MPN LP561836JU+PCM+2 WIRES 50MM
C1: 1uF 16V X7R; C1__C_0603_1608Metric; MPN C1608X7R1C105K080AC
C2: 10uF 25V X5R; C2__C_0603_1608Metric; MPN GRM188R61E106MA73D
C3: 10uF 25V X5R; C3__C_0603_1608Metric; MPN GRM188R61E106MA73D
C4: 10uF 25V X5R; C4__C_0603_1608Metric; MPN GRM188R61E106MA73D
C5: 1uF 16V X7R; C5__C_0603_1608Metric; MPN C1608X7R1C105K080AC
C6: 2.2uF 16V X7R; C6__C_0603_1608Metric; MPN EMK107BB7225KA-T
C7: 10uF 25V X5R; C7__C_0603_1608Metric; MPN GRM188R61E106MA73D
C8: 10uF 25V X5R; C8__C_0603_1608Metric; MPN GRM188R61E106MA73D
C9: 10uF 25V X5R; C9__C_0603_1608Metric; MPN GRM188R61E106MA73D
C10: 10uF 25V X5R; C10__C_0603_1608Metric; MPN GRM188R61E106MA73D
C13: 100nF 25V X5R; C13__C_0201_0603Metric; MPN C0603X5R1E104K030BB
C14: 100nF 16V X7R; C14__C_0402_1005Metric; MPN C0402C104M4RACTU
C15: 100nF 16V X7R; C15__C_0402_1005Metric; MPN C0402C104M4RACTU
C16: 100nF 16V X7R; C16__C_0402_1005Metric; MPN C0402C104M4RACTU
C17: 100nF 16V X7R; C17__C_0402_1005Metric; MPN C1005X7R1C104K050BC
C18: 1uF 16V X7R; C18__C_0603_1608Metric; MPN C1608X7R1C105K080AC
C19: 100nF 16V X7R; C19__C_0402_1005Metric; MPN C1005X7R1C104K050BC
C20: 100nF 16V X7R; C20__C_0402_1005Metric; MPN C1005X7R1C104K050BC; not fitted
C22: 100nF 16V X7R; C22__C_0402_1005Metric; MPN C1005X7R1C104K050BC
C23: 47uF 6.3V X5R; C23__C_0805_2012Metric; MPN GRM21BR60J476ME01L
C25: 10uF 6.3V X5R; C25__C_0402_1005Metric; MPN GRM155R60J106ME15D
C26: 10uF 6.3V X5R; C26__C_0402_1005Metric; MPN GRM155R60J106ME15D
D1: 1N4148WS-13-F; D1__D_SOD-323; MPN 1N4148WS-13-F
D2: ESD441DPYR; D2__TI_DPY0002A_X1SON; MPN ESD441DPYR
J1: USB4500-03-1-A; J1__USB_C_Receptacle_GCT_USB4500-03-1-A_MidMount; MPN USB4500-03-1-A
L1: 2.2uH; L1__L_Murata_DFE201610P; MPN CIGT201610EH2R2MNE
L2: 2.2uH; L2__L_Murata_DFE201610P; MPN CIGT201610EH2R2MNE
LED1: APHB1608LVBDSEKJ3C; LED1__LED_Kingbright_APHB1608LVBDSEKJ3C; MPN APHB1608LVBDSEKJ3C
M1: VCLP1020B002L; M1__WirePads_2_P1.27mm; MPN VCLP1020B002L
MIC1: CMM-3424DT-26165-TR; MIC1__SameSky_CMM-3424DT-26165-TR_TopPort_PDM; MPN CMM-3424DT-26165-TR
MIC2: CMM-3424DT-26165-TR; MIC2__SameSky_CMM-3424DT-26165-TR_TopPort_PDM; MPN CMM-3424DT-26165-TR; not fitted
NT1: PVSS1-GND; NT1__NetTie_Nordic_Config4; MPN NETTIE
NT2: PVSS2-GND; NT2__NetTie_Nordic_Config4; MPN NETTIE
Q1: AO3400A; Q1__SOT-23; MPN AO3400A
R1: 10k 1%; R1__R_0201_0603Metric; MPN RC0201FR-0710KL
R2: 10k 1%; R2__R_0201_0603Metric; MPN RC0201FR-0710KL
R3: 150k 1%; R3__R_0201_0603Metric; MPN RC0201FR-07150KL
R4: 150k 1%; R4__R_0201_0603Metric; MPN RC0201FR-07150KL
R5: 100R 1%; R5__R_0402_1005Metric; MPN RC0402FR-07100RL
R6: 100k 1%; R6__R_0402_1005Metric; MPN RC0402FR-07100KL
R7: 10k 1%; R7__R_0402_1005Metric; MPN RC0402FR-0710KL
R8: 100R 1%; R8__R_0402_1005Metric; MPN RC0402FR-07100RL
R9: 100R 1%; R9__R_0402_1005Metric; MPN RC0402FR-07100RL; not fitted
R10: 0R; R10__R_0201_0603Metric; MPN CRCW02010000Z0ED
R11: 0R; R11__R_0201_0603Metric; MPN CRCW02010000Z0ED
R12: 10k 1%; R12__R_0402_1005Metric; MPN RC0402FR-0710KL
R13: 10k 1%; R13__R_0402_1005Metric; MPN RC0402FR-0710KL
SW1: B3U-1000P; SW1__SW_SPST_B3U-1000P; MPN B3U-1000P
TH1: 10k 1% external NTC; TH1__WirePads_2_P1.27mm; MPN B57540G1103F000
TP1: SWDIO; TP1__PogoPad_D1.0mm; MPN TESTPAD
TP2: SWDCLK; TP2__PogoPad_D1.0mm; MPN TESTPAD
TP3: RESET; TP3__PogoPad_D1.0mm; MPN TESTPAD
TP4: 3V_MAIN; TP4__PogoPad_D1.0mm; MPN TESTPAD
TP5: GND; TP5__PogoPad_D1.0mm; MPN TESTPAD
TP6: UART_TX; TP6__PogoPad_D1.0mm; MPN TESTPAD
TP7: UART_RX; TP7__PogoPad_D1.0mm; MPN TESTPAD
TP8: VBAT; TP8__PogoPad_D1.0mm; MPN TESTPAD
TP9: VBUS; TP9__PogoPad_D1.0mm; MPN TESTPAD
TP10: VSYS; TP10__PogoPad_D1.0mm; MPN TESTPAD
TP11: VBUSOUT; TP11__PogoPad_D1.0mm; MPN TESTPAD
TP12: 2V5_AUX; TP12__PogoPad_D1.0mm; MPN TESTPAD
TP13: 3V_MIC; TP13__PogoPad_D1.0mm; MPN TESTPAD
TP14: PMIC_INT; TP14__PogoPad_D1.0mm; MPN TESTPAD
U1: MDBT50Q-1MV2; U1__Raytac_MDBT50Q_R0B; MPN MDBT50Q-1MV2
U2: nPM1300; U2__nPM1300_QFN32_Reference; MPN NPM1300-QEAA-R
U4: TPD2EUSB30ADRTR; U4__Texas_DRT-3_R0B; MPN TPD2EUSB30ADRTR
U5: MX35LF4GE4AD-Z4I; U5__WSON-8-1EP_8x6mm_P1.27mm_EP3.4x4.3mm; MPN MX35LF4GE4AD-Z4I
U6: TPD2E2U06DCKR; U6__TI_DCK_SC70_3_R0B; MPN TPD2E2U06DCKR

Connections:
/2V5_AUX: C7.1, L1.1, TP12.1 (2V5_AUX), U2.1 (BUCK1OUT)
/3V_MAIN: C8.1, C13.1, C17.1, C18.1, C22.1, C23.1, C25.1, D1.1 (K), L2.1, M1.1 (+), R1.1, R2.1, R7.1, R12.1, R13.1, TP4.1, U1.28 (VDD), U1.30 (VDDH), U2.12 (VDDIO), U2.28 (LDO1IN), U2.32 (BUCK2OUT), U5.8 (VCC)
/3V_MIC: C10.1, C19.1, C20.1, MIC1.1 (VDD), MIC2.1 (VDD), MIC2.2 (SELECT), TP13.1, U2.29 (LDO1OUT)
/FLASH_CS: R7.2, U1.44 (P0.20), U5.1 (CS#)
/FLASH_IO0: U1.43 (P0.21), U5.5 (SI/SIO0)
/FLASH_IO1: U1.46 (P0.22), U5.2 (SO/SIO1)
/FLASH_IO2: R12.2, U1.45 (P0.23), U5.3 (WP#/SIO2)
/FLASH_IO3: R13.2, U1.47 (P1.00/TRACEDATA0), U5.7 (HOLD#/SIO3)
/FLASH_SCK: U1.42 (P0.19), U5.6 (SCLK)
/GND: BT1.2 (VBAT-), C1.2, C4.2, C5.2, C6.2, C9.2, C10.2, C13.2, C16.2, C17.2, C18.2, C19.2, C20.2, C23.2, C25.2, C26.2, D2.2 (GND), J1.1 (GND_A1_B12), J1.12 (GND_B1_A12), J1.S1 (SHIELD), J1.S2 (SHIELD), J1.S3 (SHIELD), J1.S4 (SHIELD), MIC1.2 (SELECT), MIC1.5 (GND), MIC1.6 (GND), MIC1.7 (GND), MIC1.8 (GND), MIC2.5 (GND), MIC2.6 (GND), MIC2.7 (GND), MIC2.8 (GND), NT1.2 (GND), NT2.2 (GND), Q1.2 (S), R3.2, R4.2, R6.2, SW1.2 (B), TH1.2 (GND), TP5.1, U1.1 (GND), U1.2 (GND), U1.15 (GND), U1.33 (GND), U1.55 (GND), U2.33 (EP), U4.3 (GND), U5.4 (GND), U5.9 (EP), U6.3 (GND)
/HAPTIC_GATE: Q1.1 (G), R5.2, R6.1
/HAPTIC_NEG: C22.2, D1.2 (A), M1.2 (-), Q1.3 (D)
/HAPTIC_PWM: R5.1, U1.24 (P0.08)
/I2C_SCL: R1.2, U1.19 (P0.26), U2.14 (SCL)
/I2C_SDA: R2.2, U1.16 (P0.27), U2.13 (SDA)
/LED_BLUE_K: LED1.1 (BLUE_K), U2.25 (LED0)
/LED_RED_K: LED1.3 (RED_K), U2.26 (LED1)
/NTC: TH1.1 (NTC), U2.18 (NTC)
/PDM_CLK: MIC1.3 (CLOCK), MIC2.3 (CLOCK), U1.38 (P0.16)
/PDM_DATA: R8.2, R9.2, U1.39 (P0.15)
/PDM_DATA_MIC1: MIC1.4 (DATA), R8.1
/PDM_DATA_MIC2: MIC2.4 (DATA), R9.1
/PMIC_INT: TP14.1, U1.41 (P0.17), U2.7 (GPIO0)
/PVSS1: C2.2, C7.2, C14.2, NT1.1 (PVSS1), U2.2 (PVSS1)
/PVSS2: C3.2, C8.2, C15.2, NT2.1 (PVSS2), U2.6 (PVSS2)
/RESET: TP3.1, U1.40 (P0.18/RESET)
/SHPHLD_BTN: SW1.1 (A), U2.15 (SHPHLD)
/SW1: L1.2, U2.3 (SW1)
/SW2: L2.2, U2.5 (SW2)
/SWDCLK: TP2.1, U1.53 (SWDCLK)
/SWDIO: TP1.1, U1.51 (SWDIO)
/UART_RX: TP7.1, U1.20 (P0.04/AIN2)
/UART_TX: TP6.1, U1.21 (P0.05/AIN3)
/USB_CC1: J1.4 (CC1_A5), U2.23 (CC1), U6.1 (IO1)
/USB_CC2: J1.10 (CC2_B5), U2.24 (CC2), U6.2 (IO2)
/USB_D+: J1.6 (D+_A6), J1.8 (D+_B6), R10.1, U4.1 (IO1)
/USB_D-: J1.5 (D-_B7), J1.7 (D-_A7), R11.1, U4.2 (IO2)
/USB_MCU_D+: R10.2, U1.35 (D+)
/USB_MCU_D-: R11.2, U1.34 (D-)
/VBAT: BT1.1 (VBAT+), C6.1, TP8.1, U2.19 (VBAT)
/VBUS: C1.1, D2.1 (IO), J1.2 (VBUS_A4_B9), J1.11 (VBUS_B4_A9), TP9.1, U2.21 (VBUS)
/VBUSOUT: C5.1, C26.1, TP11.1, U1.32 (VBUS), U2.22 (VBUSOUT)
/VSET1: R3.1, U2.17 (VSET1)
/VSET2: R4.1, U2.16 (VSET2)
/VSYS: C2.1, C3.1, C4.1, C9.1, C14.1, C15.1, C16.1, LED1.2 (BLUE_A), LED1.4 (RED_A), TP10.1, U2.4 (PVDD), U2.20 (VSYS)

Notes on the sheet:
R1 E1 / FIRST-ARTICLE PROTOTYPE / QUALIFICATION PENDING
POWER: BUCK2 boots 3V_MAIN = 3.0V for MCU + NAND. BUCK1 = unloaded 2V5_AUX. LDSW1 input = 3V_MAIN. Never tie buck outputs.
USB CC1/CC2 connect directly to nPM1300. Do not fit external 5.1k Rd resistors.
BUTTON: SW1 switches SHPHLD to GND only; PMIC_INT reports state to MCU.
BT1: Jauch LP561836JU+PCM, 350mAh min + external TH1. CHARGING DISABLED pending pack-specific tests.
STORAGE: 4-Gbit raw SLC NAND requires ECC, bad-block, filesystem and power-loss firmware.
RF: module antenna keepout from exact vendor drawing; shell/metal clearance NOT validated.
MIC2/R9/C20 DNP baseline. No IMU. NAND type is a requirement exception proposal.

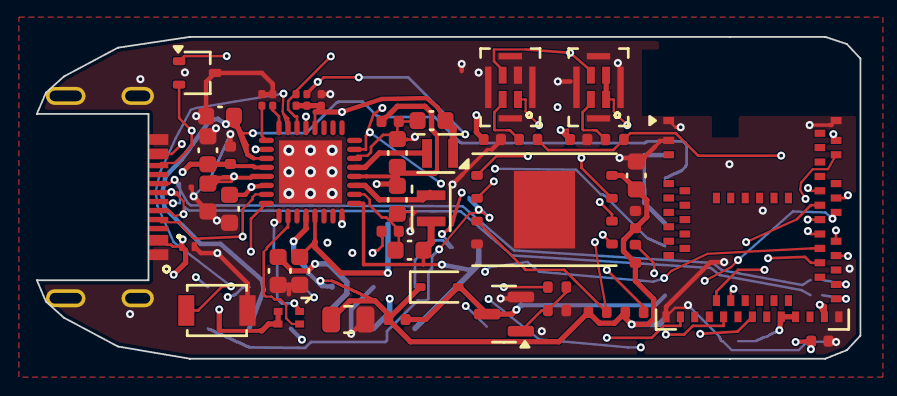
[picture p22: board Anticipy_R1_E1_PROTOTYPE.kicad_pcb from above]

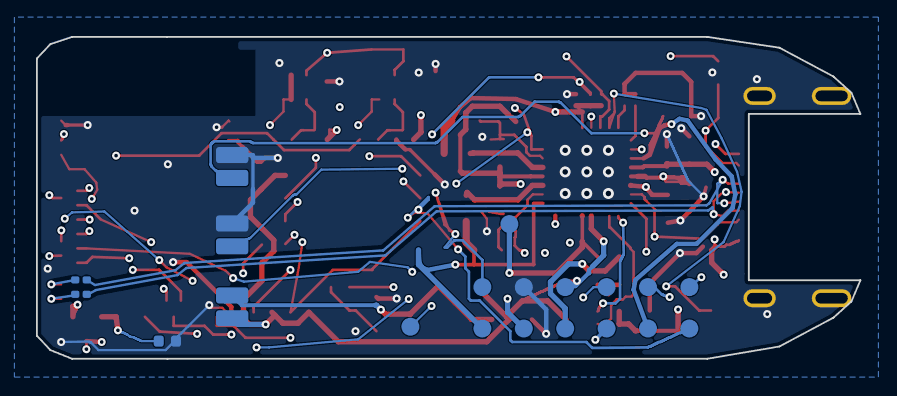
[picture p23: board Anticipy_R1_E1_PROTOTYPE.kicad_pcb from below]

Board: 4 copper layers, 45.8 x 17.9 mm, 69 parts (20 on the bottom side), 45 nets.

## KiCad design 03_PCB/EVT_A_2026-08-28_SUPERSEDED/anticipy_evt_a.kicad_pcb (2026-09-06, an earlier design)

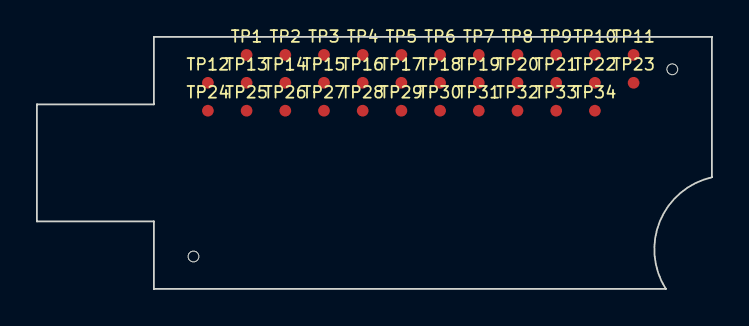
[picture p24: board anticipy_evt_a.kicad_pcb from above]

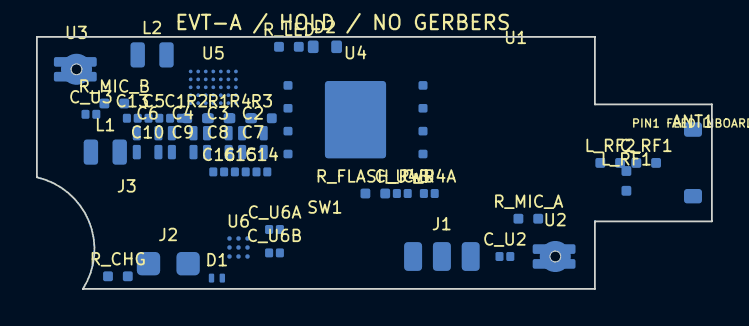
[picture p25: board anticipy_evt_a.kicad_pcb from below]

Board: 4 copper layers, 37.5 x 14.0 mm, 81 parts (47 on the bottom side), 38 nets, no tracks yet.

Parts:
ANT1: 2450AT18A0100001E
C1: 1uF/25V; C_OPEN
C2, C3, C4, C7, C8, C9, C10: 10uF; C_OPEN
C5: 1uF; C_OPEN
C6: 2.2uF EMK107BB7225KA-T; C_OPEN
C13: 100nF; C_OPEN
C14, C15, C16: 100nF C0402C104M4RAC7867; C_OPEN
C_RF1: DNP/TUNE (eval 1.0pF); 0402_RF
C_U2, C_U3, C_U4A: 100nF; C_OPEN
C_U4B: 1uF; C_OPEN
C_U6A: 1uF REG; C_OPEN
C_U6B: 1uF VDD; C_OPEN
D1: TPD1E10B06DPYR; X1SON2_DPY
D2: LED MPN OPEN; LED_1608_OPEN
J1: BAT-ANT-200-001 3-wire; BATTERY_WIRE_PADS
J2: MAGNETIC POGO 5V; CHARGE_PADS
J3: JYC720FDRL FPC hot-bar land gate; JYC720FDRL_HOTBAR_LAND_GATE
L1, L2: 2.2uH CIGT201610EH2R2MNE; CIGT201610
L_RF1: DNP/TUNE (eval 2.7nH); 0402_RF
L_RF2: DNP/TUNE (eval 3.9nH); 0402_RF
R1, R2: 10k; R_0402_OPEN
R3: 47k; R_0402_OPEN
R4: 150k; R_0402_OPEN
R_CHG: 0R; R_0402_OPEN
R_FLASH_PWR: 0R; R_0402_OPEN
R_LED: OPEN; R_0402_OPEN
R_MIC_A: 0R; R_0402_OPEN
R_MIC_B: 0R; R_0402_OPEN
SW1: SKSCLCE010; SKSCLCE010_PADMAP_GATE
TP1: GND; TP_0P65
TP2: CHG_5V; TP_0P65
TP3: VBUS; TP_0P65
TP4: VBAT; TP_0P65
TP5: BAT_NTC; TP_0P65
TP6: VSYS; TP_0P65
TP7: 1V8; TP_0P65
TP8: 3V0; TP_0P65
TP9: FLASH_VDD; TP_0P65
TP10: QSPI_CS_TO_U1_PAD_TBD; TP_0P65
TP11: QSPI_CLK_TO_U1_PAD_TBD; TP_0P65
TP12: QSPI_IO0_TO_U1_PAD_TBD; TP_0P65
TP13: QSPI_IO1_TO_U1_PAD_TBD; TP_0P65
TP14: QSPI_IO2_TO_U1_PAD_TBD; TP_0P65
TP15: QSPI_IO3_TO_U1_PAD_TBD; TP_0P65
TP16: PDM_CLK_TO_U1_PAD_TBD; TP_0P65
TP17: PDM_DATA_TO_U1_PAD_TBD; TP_0P65
TP18: MIC_A_VDD; TP_0P65
TP19: MIC_B_VDD; TP_0P65
TP20: PMIC_SDA_TO_U1_PAD_TBD; TP_0P65
TP21: PMIC_SCL_TO_U1_PAD_TBD; TP_0P65
TP22: HAPTIC_SDA_TO_U1_PAD_TBD; TP_0P65
TP23: HAPTIC_SCL_TO_U1_PAD_TBD; TP_0P65
TP24: HAPTIC_EN_TO_U1_PAD_TBD; TP_0P65
TP25: HAPTIC_REG; TP_0P65
TP26: HAPTIC_OUT_P; TP_0P65
TP27: HAPTIC_OUT_M; TP_0P65
TP28: BUTTON_TO_U1_PAD_TBD; TP_0P65
TP29: STATUS_LED_TO_U1_PAD_TBD; TP_0P65
TP30: SWDIO_TO_U1_PAD_TBD; TP_0P65
TP31: SWCLK_TO_U1_PAD_TBD; TP_0P65
TP32: RESET_TO_U1_PAD_TBD; TP_0P65
TP33: UART_TX_TO_U1_PAD_TBD; TP_0P65
TP34: UART_RX_TO_U1_PAD_TBD; TP_0P65
U1: 453-00224R; BL54L15U_PINMAP_GATE
U2, U3: IM69D128S
U4: W25N04KVZEIR; WSON8_8x6_W25N04KV
U5: nPM1300-CAAA; WLCSP35_nPM1300_CAAA
U6: DRV2605LYZFR; DSBGA9_DRV2605L

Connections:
1V8: C7.1, L1.2, TP7.1, U5.B4, U5.B6
3V0: C8.1, C13.1, C_U6B.1, L2.2, R1.1, R2.1, R_FLASH_PWR.1, R_MIC_A.1, R_MIC_B.1, TP8.1, U3.4, U5.B5, U5.C6, U5.E4, U6.C2
BAT_NTC: J1.2, TP5.1, U5.D3
CHG_5V: D1.1, J2.1, R_CHG.1, TP2.1
FLASH_VDD: C_U4A.1, C_U4B.1, R_FLASH_PWR.2, TP9.1, U4.8
GND: C1.2, C2.2, C3.2, C4.2, C5.2, C6.2, C7.2, C8.2, C9.2, C10.2, C13.2, C14.2, C15.2, C16.2, C_U2.2, C_U3.2, C_U4A.2, C_U4B.2, C_U6A.2, C_U6B.2, D1.2, D2.2, J1.3, J2.2, L_RF1.2, R3.2, R4.2, TP1.1, U2.4, U2.5, U3.5, U4.4, U4.9, U5.A6, U5.A7, U5.E7, U6.B1, U6.B3
HAPTIC_EN_TO_U1_PAD_TBD: TP24.1, U6.A1
HAPTIC_OUT_M: TP27.1, U6.C3
HAPTIC_OUT_P: TP26.1, U6.A3
HAPTIC_REG: C_U6A.1, TP25.1, U6.A2
HAPTIC_SCL_TO_U1_PAD_TBD: TP23.1, U6.C1
HAPTIC_SDA_TO_U1_PAD_TBD: TP22.1, U6.B2
LDO1_OUT: C9.1, U5.A4
LDO2_OUT: C10.1, U5.A5
MIC_A_VDD: C_U2.1, R_MIC_A.2, TP18.1, U2.1
MIC_B_VDD: C_U3.1, R_MIC_B.2, TP19.1, U3.1
PDM_CLK_TO_U1_PAD_TBD: TP16.1, U2.2, U3.2
PDM_DATA_TO_U1_PAD_TBD: TP17.1, U2.3, U3.3
PMIC_SCL_TO_U1_PAD_TBD: R2.2, TP21.1, U5.E3
PMIC_SDA_TO_U1_PAD_TBD: R1.2, TP20.1, U5.E5
QSPI_CLK_TO_U1_PAD_TBD: TP11.1, U4.6
QSPI_CS_TO_U1_PAD_TBD: TP10.1, U4.1
QSPI_IO0_TO_U1_PAD_TBD: TP12.1, U4.5
QSPI_IO1_TO_U1_PAD_TBD: TP13.1, U4.2
QSPI_IO2_TO_U1_PAD_TBD: TP14.1, U4.3
QSPI_IO3_TO_U1_PAD_TBD: TP15.1, U4.7
RF_MATCH_A: C_RF1.2, L_RF1.1, L_RF2.1
RF_MATCH_B: ANT1.1, L_RF2.2
STATUS_LED_A: D2.1, R_LED.2
STATUS_LED_TO_U1_PAD_TBD: R_LED.1, TP29.1
SW_BUCK1: L1.1, U5.B7
SW_BUCK2: L2.1, U5.D7
VBAT: C6.1, J1.1, TP4.1, U5.D1, U5.D2
VBUS: C1.1, R_CHG.2, TP3.1, U5.B1, U5.B2
VBUSOUT: C5.1, U5.C3
VSET1: R3.1, U5.E2
VSET2: R4.1, U5.E1
VSYS: C2.1, C3.1, C4.1, C14.1, C15.1, C16.1, TP6.1, U5.C1, U5.C2, U5.C7

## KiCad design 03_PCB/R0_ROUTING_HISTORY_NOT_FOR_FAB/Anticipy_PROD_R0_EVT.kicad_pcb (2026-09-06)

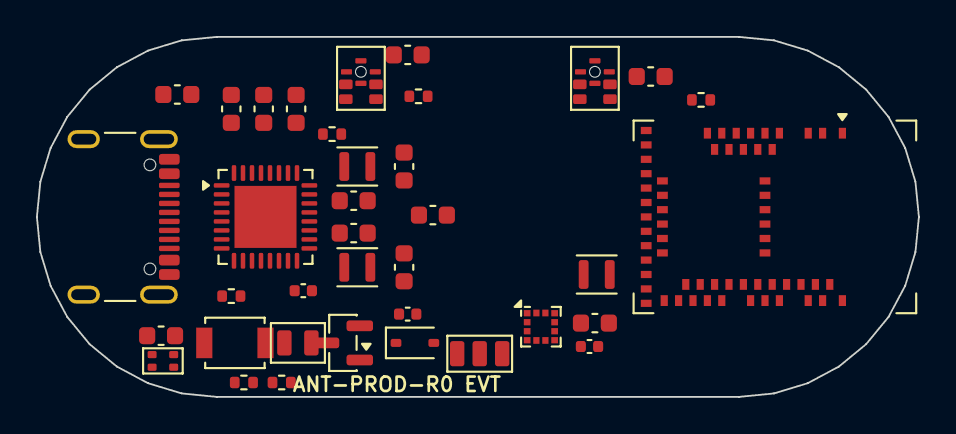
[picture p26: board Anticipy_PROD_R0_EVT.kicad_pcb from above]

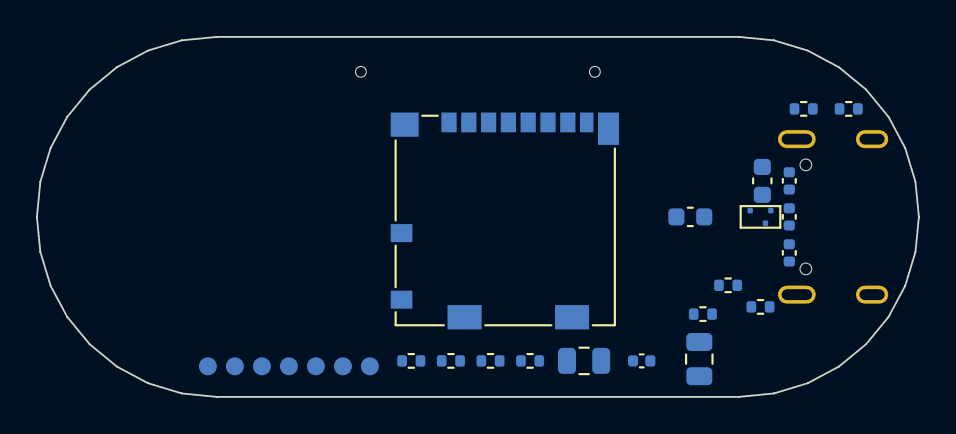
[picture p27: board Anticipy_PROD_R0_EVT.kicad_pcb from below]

Board: 4 copper layers, 49.0 x 20.0 mm, 63 parts (26 on the bottom side), 47 nets, no tracks yet.

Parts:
BT1: LiPo_1S_PROTECTED_NTC
C1: 1uF 16V X7R; C_0603_1608Metric
C2, C3, C4, C7, C8, C9, C10, C11, C12: 10uF 10V X5R; C_0603_1608Metric
C5: 1uF 10V X7R; C_0603_1608Metric
C6: 2.2uF 16V X7R EMK107BB7225KA-T; C_0603_1608Metric
C13: 100nF 6.3V X7R; C_0402_1005Metric
C14, C15, C16: 100nF 6.3V X7R C0402C104M4RAC7867; C_0402_1005Metric
C17, C18: 1uF MIC BYPASS; C_0603_1608Metric
C19: 10uF MCU BULK; C_0603_1608Metric
C20: 100nF ACC BYPASS; C_0402_1005Metric
C21: 47uF SD BULK; C_0805_2012Metric
C22: 100nF SD BYPASS; C_0402_1005Metric
C23: 100nF MOTOR; C_0402_1005Metric
C24: 47uF MOTOR BULK; C_0805_2012Metric
D1: 1N4148W-HF; D_SOD-323
J1: USB4105-GF-A; USB_C_Receptacle_GCT_USB4105-xx-A_16P_TopMnt_Horizontal
J2: 104031-0811; microSD_HC_Molex_104031-0811
L1, L2: 2.2uH CIGT201610EH2R2MNE; L_Murata_DFE201610P
L3: 10uH MLZ2012N100LT000; L_Murata_DFE201610P
LED1: APHB1608LVBDSEKJ3C
M1: VCLP1020B002L
MIC1, MIC2: IM69D128SV01XTMA1
Q1: AO3400A; SOT-23
R1, R2: 10k I2C; R_0402_1005Metric
R3: 330k 1% BUCK1=2.7V START; R_0402_1005Metric
R4: 150k 1% BUCK2=3.0V; R_0402_1005Metric
R5: 5.1k USB CC1; R_0402_1005Metric
R6: 5.1k USB CC2; R_0402_1005Metric
R7: 100k SD CS PULLUP; R_0402_1005Metric
R8: 22R SD SCK; R_0402_1005Metric
R9: 22R SD MOSI; R_0402_1005Metric
R10: 22R SD MISO; R_0402_1005Metric
R11: 100k BUTTON PULLUP; R_0402_1005Metric
R12: 100R HAPTIC GATE; R_0402_1005Metric
R13: 100k HAPTIC PULLDOWN; R_0402_1005Metric
R14: 100R MIC1 DATA; R_0402_1005Metric
R15: 100R MIC2 DATA; R_0402_1005Metric
SW1: B3U-1000P; SW_SPST_B3U-1000P
TP1: SWDIO
TP2: SWDCLK
TP3: RESET
TP4: 3V_MAIN
TP5: GND
TP6: UART_TX
TP7: UART_RX
U1: MDBT50Q-1MV2; Raytac_MDBT50Q
U2: NPM1300-QEAA-R7; QFN-32-1EP_5x5mm_P0.5mm_EP3.45x3.45mm
U3: LIS2DW12TR; LGA-12_2x2mm_P0.5mm
U4: TPD2EUSB30DRTR

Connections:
3V_MAIN: C7.1, C13.1, C19.1, C20.1, C23.1, C24.1, D1.2, L1.1, L3.2, M1.1, R1.1, R2.1, R11.1, TP4.1, U1.28, U1.30, U2.1, U2.12, U3.2, U3.9, U3.10
3V_MIC: C10.1, C17.1, C18.1, MIC1.1, MIC2.1, MIC2.4, U2.29
3V_SD: C8.1, C21.1, C22.1, J2.4, L2.1, R7.1, U2.32
ACC_INT1: U1.44, U3.12
ACC_INT2: U1.43, U3.11
DCCH: L3.1, U1.31
GND: BT1.3, C1.2, C2.2, C3.2, C4.2, C5.2, C6.2, C7.2, C8.2, C9.2, C10.2, C11.2, C12.2, C13.2, C14.2, C15.2, C16.2, C17.2, C18.2, C19.2, C20.2, C21.2, C22.2, C24.2, J1.A1, J1.A12, J1.B1, J1.B12, J1.SH, J2.6, J2.10, J2.SH, MIC1.4, MIC1.5, MIC2.5, Q1.2, R3.2, R4.2, R5.2, R6.2, R13.2, SW1.2, TP5.1, U1.1, U1.2, U1.15, U1.33, U1.55, U2.2, U2.6, U2.33, U3.3, U3.6, U3.7, U3.8, U4.3
HAPTIC_GATE: Q1.1, R12.2, R13.1
HAPTIC_NEG: C23.2, D1.1, M1.2, Q1.3
HAPTIC_PWM: R12.1, U1.24
I2C_SCL: R1.2, U1.19, U2.14, U3.1
I2C_SDA: R2.2, U1.16, U2.13, U3.4
LDO2_OUT: C12.1, U2.31
LED_BLUE_K: LED1.1, U2.25
LED_RED_K: LED1.3, U2.26
NTC: BT1.2, U2.18
PDM_CLK: MIC1.2, MIC2.2, U1.38
PDM_DATA: R14.2, R15.2, U1.39
PDM_DATA_MIC1: MIC1.3, R14.1
PDM_DATA_MIC2: MIC2.3, R15.1
PMIC_INT: U1.41, U2.7
RESET: TP3.1, U1.40
SD_CS: J2.2, R7.2, U1.27
SD_DETECT: J2.9, U1.45
SD_MISO_CARD: J2.7, R10.1
SD_MISO_MCU: R10.2, U1.29
SD_MOSI_CARD: J2.3, R9.2
SD_MOSI_MCU: R9.1, U1.36
SD_SCK_CARD: J2.5, R8.2
SD_SCK_MCU: R8.1, U1.37
SW1: L1.2, U2.3
SW2: L2.2, U2.5
SWDCLK: TP2.1, U1.53
SWDIO: TP1.1, U1.51
UART_RX: TP7.1, U1.20
UART_TX: TP6.1, U1.21
USB_CC1: J1.A5, R5.1, U2.23
USB_CC2: J1.B5, R6.1, U2.24
USB_D+: J1.A6, J1.B6, U1.35, U4.1
USB_D-: J1.A7, J1.B7, U1.34, U4.2
USER_BTN: R11.2, SW1.1, U1.22, U2.15
VBAT: BT1.1, C6.1, U2.19
VBUS: C1.1, J1.A4, J1.A9, J1.B4, J1.B9, U1.32, U2.21
VBUSOUT: C5.1, U2.22
VSET1: R3.1, U2.17
VSET2: R4.1, U2.16
VSYS: C2.1, C3.1, C4.1, C9.1, C11.1, C14.1, C15.1, C16.1, LED1.2, LED1.4, U2.4, U2.20, U2.28, U2.30

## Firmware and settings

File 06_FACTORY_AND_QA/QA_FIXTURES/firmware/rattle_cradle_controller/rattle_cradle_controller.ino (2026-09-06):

/*
  Anticipy slow rattle-cradle controller, revision 1.0

  This is a screening fixture, not a safety-rated machine controller.
  The polycarbonate guard, fuse, current limit and normally-closed hardware
  stop loop remain mandatory.  An experienced adult must build and operate it.

  Arduino Nano -> TMC2209 in STEP/DIR standalone mode
    D3  STEP
    D4  DIR
    D5  EN       (LOW enables driver)
    D6  HOME_NC  (LOW at home; INPUT_PULLUP)
    D7  GUARD_NC (LOW only when guard is closed; INPUT_PULLUP)
    D8  START    (momentary to GND)
    D9  STOP_NC  (LOW when healthy; opens HIGH to stop)
    D10 MARKER   (HIGH only during a quiet acoustic sample)
    D13 status LED

  Mechanics assumed by this file:
    200 full-step/rev motor, 1/16 microstepping, 20T:60T belt reduction.
    Therefore one cradle-shaft revolution = 9,600 STEP pulses.
*/

#include <Arduino.h>

constexpr uint8_t PIN_STEP = 3;
constexpr uint8_t PIN_DIR = 4;
constexpr uint8_t PIN_ENABLE_N = 5;
constexpr uint8_t PIN_HOME_N = 6;
constexpr uint8_t PIN_GUARD_N = 7;
constexpr uint8_t PIN_START_N = 8;
constexpr uint8_t PIN_STOP_N = 9;
constexpr uint8_t PIN_MARKER = 10;
constexpr uint8_t PIN_STATUS = LED_BUILTIN;

constexpr long SHAFT_STEPS_PER_REV = 200L * 16L * 3L;
constexpr long ENDPOINT_STEPS = (SHAFT_STEPS_PER_REV * 170L) / 360L;
constexpr uint16_t FULL_CYCLES = 10;
constexpr uint16_t HALF_CYCLES = FULL_CYCLES * 2;
constexpr unsigned long STEP_INTERVAL_US = 3125UL;  // 320 pulses/s = 2 shaft rpm
constexpr unsigned long HOME_STEP_INTERVAL_US = 4000UL;
constexpr unsigned long PAUSE_MS = 2000UL;
constexpr unsigned long DEBOUNCE_MS = 30UL;
constexpr long HOME_SEARCH_LIMIT = SHAFT_STEPS_PER_REV * 2L;

enum class State : uint8_t { IDLE, HOMING, MOVING, PAUSING, COMPLETE, FAULT };

State state = State::IDLE;
long positionSteps = 0;
long targetSteps = 0;
long homeSteps = 0;
uint16_t completedHalfCycles = 0;
bool nextDirectionPositive = true;
unsigned long lastStepUs = 0;
unsigned long pauseStartedMs = 0;
unsigned long lastStartChangeMs = 0;
bool previousStart = HIGH;

bool guardClosed() { return digitalRead(PIN_GUARD_N) == LOW; }
bool stopLoopHealthy() { return digitalRead(PIN_STOP_N) == LOW; }
bool homeActive() { return digitalRead(PIN_HOME_N) == LOW; }

void driverOff() {
  digitalWrite(PIN_ENABLE_N, HIGH);
  digitalWrite(PIN_MARKER, LOW);
}

void fault(const __FlashStringHelper *reason) {
  driverOff();
  state = State::FAULT;
  Serial.print(F("FAULT,"));
  Serial.println(reason);
}

void pulseStep(bool positive) {
  digitalWrite(PIN_DIR, positive ? HIGH : LOW);
  digitalWrite(PIN_STEP, HIGH);
  delayMicroseconds(4);
  digitalWrite(PIN_STEP, LOW);
  positionSteps += positive ? 1 : -1;
}

bool startPressedOnce() {
  const bool now = digitalRead(PIN_START_N);
  const unsigned long t = millis();
  bool event = false;
  if (now != previousStart && (t - lastStartChangeMs) >= DEBOUNCE_MS) {
    lastStartChangeMs = t;
    previousStart = now;
    if (now == LOW) event = true;
  }
  return event;
}

void beginHoming() {
  if (!guardClosed() || !stopLoopHealthy()) {
    fault(F("GUARD_OR_STOP_OPEN"));
    return;
  }
  digitalWrite(PIN_ENABLE_N, LOW);
  digitalWrite(PIN_STATUS, HIGH);
  homeSteps = 0;
  lastStepUs = micros();
  state = State::HOMING;
  Serial.println(F("HOMING"));
}

void beginRunAtHome() {
  positionSteps = 0;
  completedHalfCycles = 0;
  nextDirectionPositive = true;
  targetSteps = ENDPOINT_STEPS;
  lastStepUs = micros();
  state = State::MOVING;
  Serial.print(F("MOTION,target_steps,"));
  Serial.println(targetSteps);
}

void enterPause() {
  digitalWrite(PIN_MARKER, HIGH);
  pauseStartedMs = millis();
  state = State::PAUSING;
  Serial.print(F("PAUSE,endpoint,"));
  Serial.print(completedHalfCycles + 1);
  Serial.print(F(",position_steps,"));
  Serial.println(positionSteps);
}

void setup() {
  pinMode(PIN_STEP, OUTPUT);
  pinMode(PIN_DIR, OUTPUT);
  pinMode(PIN_ENABLE_N, OUTPUT);
  pinMode(PIN_MARKER, OUTPUT);
  pinMode(PIN_STATUS, OUTPUT);
  pinMode(PIN_HOME_N, INPUT_PULLUP);
  pinMode(PIN_GUARD_N, INPUT_PULLUP);
  pinMode(PIN_START_N, INPUT_PULLUP);
  pinMode(PIN_STOP_N, INPUT_PULLUP);
  driverOff();
  digitalWrite(PIN_STATUS, LOW);
  previousStart = digitalRead(PIN_START_N);
  Serial.begin(115200);
  Serial.println(F("ANTICIPY_RATTLE_FIXTURE,READY"));
}

void loop() {
  const bool startEvent = startPressedOnce();

  if (state != State::IDLE && state != State::COMPLETE && state != State::FAULT) {
    if (!guardClosed()) {
      fault(F("GUARD_OPENED"));
      return;
    }
    if (!stopLoopHealthy()) {
      fault(F("STOP_OPENED"));
      return;
    }
  }

  if (state == State::IDLE && startEvent) {
    beginHoming();
    return;
  }

  if ((state == State::COMPLETE || state == State::FAULT) && startEvent) {
    if (guardClosed() && stopLoopHealthy()) {
      state = State::IDLE;
      digitalWrite(PIN_STATUS, LOW);
      Serial.println(F("RESET_TO_IDLE;PRESS_START_TO_HOME"));
    }
    return;
  }

  if (state == State::HOMING) {
    if (homeActive()) {
      Serial.println(F("HOME_FOUND"));
      beginRunAtHome();
      return;
    }
    if (homeSteps >= HOME_SEARCH_LIMIT) {
      fault(F("HOME_NOT_FOUND"));
      return;
    }
    const unsigned long nowUs = micros();
    if ((unsigned long)(nowUs - lastStepUs) >= HOME_STEP_INTERVAL_US) {
      lastStepUs = nowUs;
      pulseStep(false);
      ++homeSteps;
    }
    return;
  }

  if (state == State::MOVING) {
    if (positionSteps == targetSteps) {
      enterPause();
      return;
    }
    const unsigned long nowUs = micros();
    if ((unsigned long)(nowUs - lastStepUs) >= STEP_INTERVAL_US) {
      lastStepUs = nowUs;
      pulseStep(targetSteps > positionSteps);
    }
    return;
  }

  if (state == State::PAUSING && millis() - pauseStartedMs >= PAUSE_MS) {
    digitalWrite(PIN_MARKER, LOW);
    ++completedHalfCycles;
    if (completedHalfCycles >= HALF_CYCLES) {
      driverOff();
      digitalWrite(PIN_STATUS, LOW);
      state = State::COMPLETE;
      Serial.println(F("COMPLETE,10_FULL_CYCLES"));
      return;
    }
    nextDirectionPositive = !nextDirectionPositive;
    targetSteps = nextDirectionPositive ? ENDPOINT_STEPS : -ENDPOINT_STEPS;
    lastStepUs = micros();
    state = State::MOVING;
    Serial.print(F("MOTION,target_steps,"));
    Serial.println(targetSteps);
  }
}

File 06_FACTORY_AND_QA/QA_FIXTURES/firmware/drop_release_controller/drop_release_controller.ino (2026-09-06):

/*
  Anticipy drop-release controller, revision 1.0

  This drives a MOSFET module; it MUST NOT drive a solenoid directly from an
  Arduino pin. Fit a flyback diode at the coil, a 12 V fuse, a normally-closed
  guard switch and a physical ARM switch. The operator stays outside the guard.

  Arduino Nano pin map
    D6  GUARD_N  (LOW only when guard is closed)
    D7  ARM_N    (LOW when deliberately armed)
    D8  DROP_N   (momentary button to GND)
    D9  SOLENOID (to logic-level MOSFET input, active HIGH)
    D10 READY_LED
*/

#include <Arduino.h>

constexpr uint8_t PIN_GUARD_N = 6;
constexpr uint8_t PIN_ARM_N = 7;
constexpr uint8_t PIN_DROP_N = 8;
constexpr uint8_t PIN_SOLENOID = 9;
constexpr uint8_t PIN_READY_LED = 10;
constexpr unsigned long MAX_PULSE_MS = 250UL;
constexpr unsigned long DEBOUNCE_MS = 40UL;

enum class ReleaseState : uint8_t { SAFE, READY, FIRING, LOCKOUT };
ReleaseState state = ReleaseState::SAFE;
unsigned long pulseStartedMs = 0;
unsigned long dropChangedMs = 0;
bool previousDrop = HIGH;

bool guardClosed() { return digitalRead(PIN_GUARD_N) == LOW; }
bool armed() { return digitalRead(PIN_ARM_N) == LOW; }

void coilOff() { digitalWrite(PIN_SOLENOID, LOW); }

bool dropPressedOnce() {
  const bool now = digitalRead(PIN_DROP_N);
  const unsigned long t = millis();
  bool event = false;
  if (now != previousDrop && (t - dropChangedMs) >= DEBOUNCE_MS) {
    dropChangedMs = t;
    previousDrop = now;
    if (now == LOW) event = true;
  }
  return event;
}

void setup() {
  pinMode(PIN_GUARD_N, INPUT_PULLUP);
  pinMode(PIN_ARM_N, INPUT_PULLUP);
  pinMode(PIN_DROP_N, INPUT_PULLUP);
  pinMode(PIN_SOLENOID, OUTPUT);
  pinMode(PIN_READY_LED, OUTPUT);
  coilOff();
  digitalWrite(PIN_READY_LED, LOW);
  previousDrop = digitalRead(PIN_DROP_N);
  Serial.begin(115200);
  Serial.println(F("ANTICIPY_DROP_FIXTURE,SAFE"));
}

void loop() {
  const bool dropEvent = dropPressedOnce();

  // Opening the guard always removes coil power in software as a second layer.
  if (!guardClosed()) {
    coilOff();
    digitalWrite(PIN_READY_LED, LOW);
    state = ReleaseState::SAFE;
    return;
  }

  if (state == ReleaseState::SAFE) {
    if (armed() && digitalRead(PIN_DROP_N) == HIGH) {
      state = ReleaseState::READY;
      digitalWrite(PIN_READY_LED, HIGH);
      Serial.println(F("READY"));
    }
    return;
  }

  if (state == ReleaseState::READY) {
    if (!armed()) {
      digitalWrite(PIN_READY_LED, LOW);
      state = ReleaseState::SAFE;
      return;
    }
    if (dropEvent) {
      digitalWrite(PIN_READY_LED, LOW);
      digitalWrite(PIN_SOLENOID, HIGH);
      pulseStartedMs = millis();
      state = ReleaseState::FIRING;
      Serial.println(F("DROP_PULSE_START"));
    }
    return;
  }

  if (state == ReleaseState::FIRING) {
    if (!armed() || millis() - pulseStartedMs >= MAX_PULSE_MS) {
      coilOff();
      state = ReleaseState::LOCKOUT;
      Serial.println(F("DROP_PULSE_END,LOCKOUT"));
    }
    return;
  }

  // One release per arm cycle.  ARM must be turned off and DROP released.
  if (state == ReleaseState::LOCKOUT && !armed() && digitalRead(PIN_DROP_N) == HIGH) {
    state = ReleaseState::SAFE;
    Serial.println(F("RESET_SAFE"));
  }
}

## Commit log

2026-09-06 Consolidate the Anticipy hardware record from 15 sources
    Assembled from a machine-wide audit of every hardware artifact on disk.
    3,745 files, checksum-verified, nothing moved or deleted at source.
    The 2026-09-05 "master package" held only 74 of 411 unique CAD/fab
    artifacts (18%). Anticipy_Execution_v1.0 held more exclusive content
    (243 blobs vs 190), and an entire prior ESP32-S3 generation plus the
    only parametric OpenSCAD enclosure source were loose on the Desktop
    and in iCloud, in none of the packages. So this consolidates 15
    sources rather than adopting one.
    Structure:
    00_START_HERE state, 14 documented contradictions, glossary, provenance
    01_CURRENT_TARGET_R1 the liv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
    [2026-08-27_v07_FOUR_DAY_ORDER_SHEET.csv, 2026-08-28_tuesday_evt_BUY_12.csv, ACTIVE_WEST_PROJECTS_POST.tsv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]
2026-09-06 Correct the current-target docs: the Flux brief is superseded
    The master package's own supersession notice excludes the R1 Flux build
    brief, its 49 x 20 mm layout and its microSD concept from the active
    handoff — but that brief sits unbannered in 01_CURRENT_REQUIREMENTS, so
    the first consolidation pass treated it as the current target. It is not.
    The actual current requirement set is the Rev 1 brief of 2026-09-04:
    51 x 21 x 11 mm (+10%/axis cap), <= 20 g, 16 h runtime,
    QSPI NOR flash planned at 512 MB, 16-20 h offline, BLE with ordered
    backfill, Checkpoints A/B/C/D.
    The MCU is NOT locked: "nRF52840-compatible starting point", with module
    vs bare SoC listed as an open question. Rayta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
    [INVENTORY.csv]
2026-09-06 Add ORIENTATION.md for readers with no prior project context
    Written for someone who has never seen Anticipy: what the product is and
    what it has to do physically, the honest state (no board ever fabricated,
    nothing physically tested), clone instructions with an LFS-free fallback,
    which application opens each file type, the board-naming vocabulary that
    trips everyone up, the two week-one traps (the DO_NOT_FLASH image and the
    superseded-but-more-convincing brief), and a suggested first week.
    [INVENTORY.csv]
2026-09-10 Add latest E1P1 PCB, matched CAD, firmware, and build handoff
    [All_137_Vias_Mandatory_Type_VII.csv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]
